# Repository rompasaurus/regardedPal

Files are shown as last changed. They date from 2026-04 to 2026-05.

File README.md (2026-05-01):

# Dilder

A Tamagotchi-inspired virtual pet built on a Raspberry Pi Pico W with an e-ink display, battery pack, and 3D-printed case — developed entirely in the open as a learning platform, blog series, and YouTube companion project.

The goal isn't just to build a thing — it's to show *how* the thing gets built, from the very first idea to a finished handheld device. Every prompt, every design decision, every dead end is documented so anyone can follow along, learn, and build their own.

---

## How It Started — Meet Jamal

<p align="center">
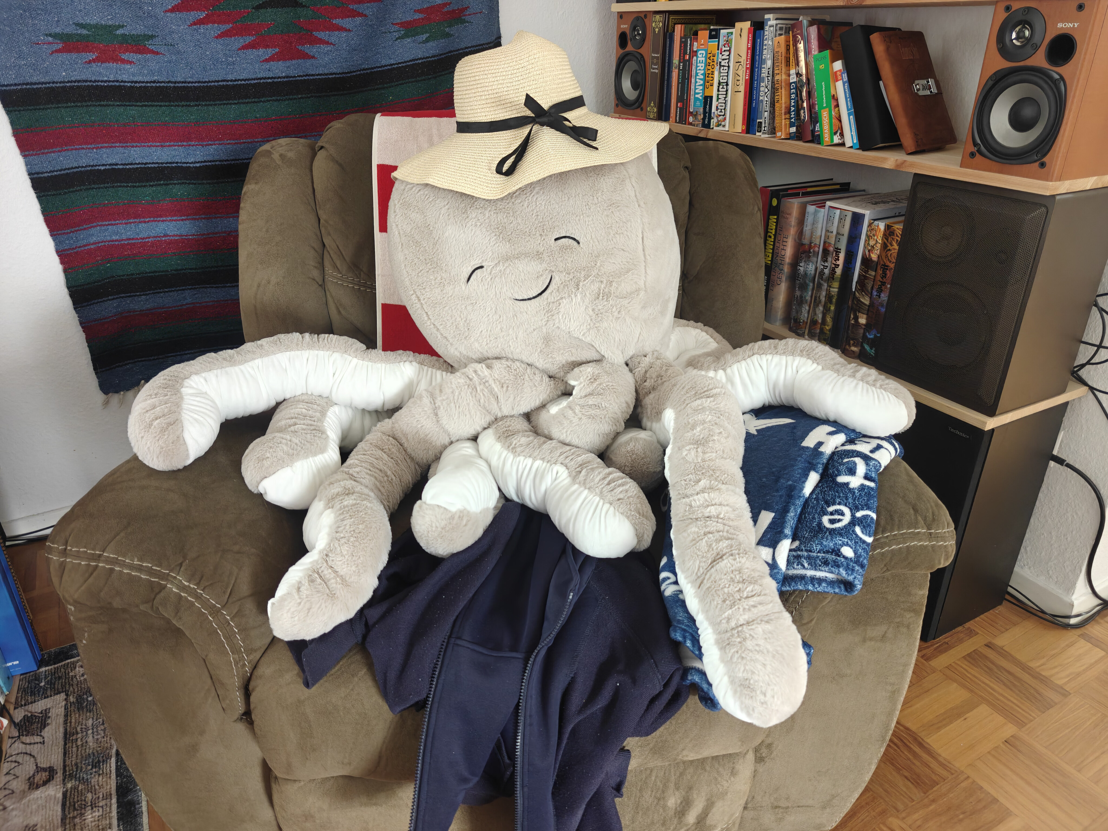
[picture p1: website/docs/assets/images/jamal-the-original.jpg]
Jamal the plush octopus
  
  <br />
  <em>Jamal. The plush octopus who started it all.</em>
</p>

This project didn't start with a schematic or a product spec. It started in a TEDi — a German dollar store — where my wife Emma and I found a giant plush octopus grinning up from a discount bin. We bought him on the spot, and on the walk home we started giving him a personality: laid-back, opinionated, a little sassy, suspiciously wise for a boneless creature. By the time we got home, he had a name — **Jamal** — and he'd claimed the armchair like he'd been paying rent.

The question asked itself: *what if we could actually bring him to life?* Not literally — but as a tiny digital companion. A pocket-sized octopus with moods, opinions, and an attitude problem, living on an e-ink screen and judging your life choices in ALL CAPS.

That's how Dilder was born. Not from an engineering roadmap, but from a stuffed animal and two people who couldn't stop anthropomorphizing it on a walk home.

---

## Enclosure — Rev 2 Mk2

The 3D-printed enclosure is a three-part design: base plate with solar panel recess, AAA battery cradle insert, and top cover with display window and joystick cutout. Designed in OpenSCAD (parametric source) and FreeCAD (visual PartDesign).

### Individual Parts

<p align="center">
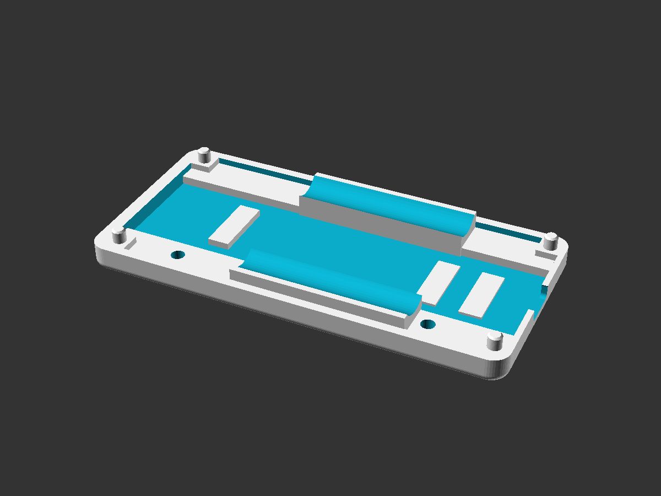
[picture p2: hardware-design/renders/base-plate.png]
Base Plate — top view
  
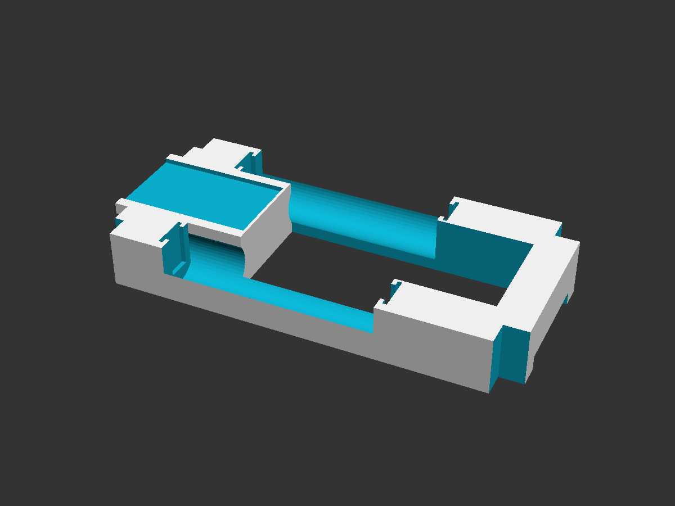
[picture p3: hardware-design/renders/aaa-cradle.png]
AAA Battery Cradle
  
</p>
<p align="center">
  <em>Left: Base plate with cradle pocket, corner pillars, battery rail troughs, and USB-C cutout. Right: AAA battery cradle with dual bays, clip slots, and TP4056 indent.</em>
</p>

<p align="center">
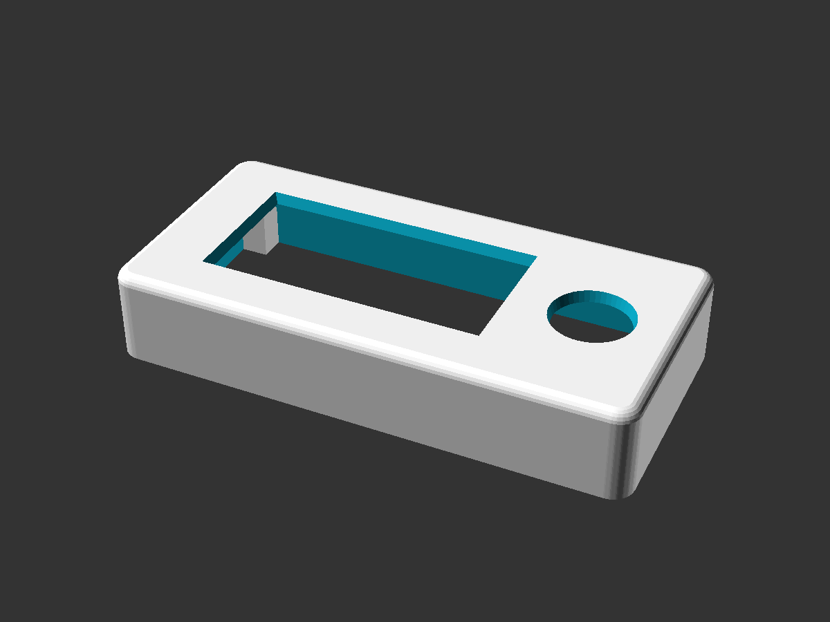
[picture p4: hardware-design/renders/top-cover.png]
Top Cover
  
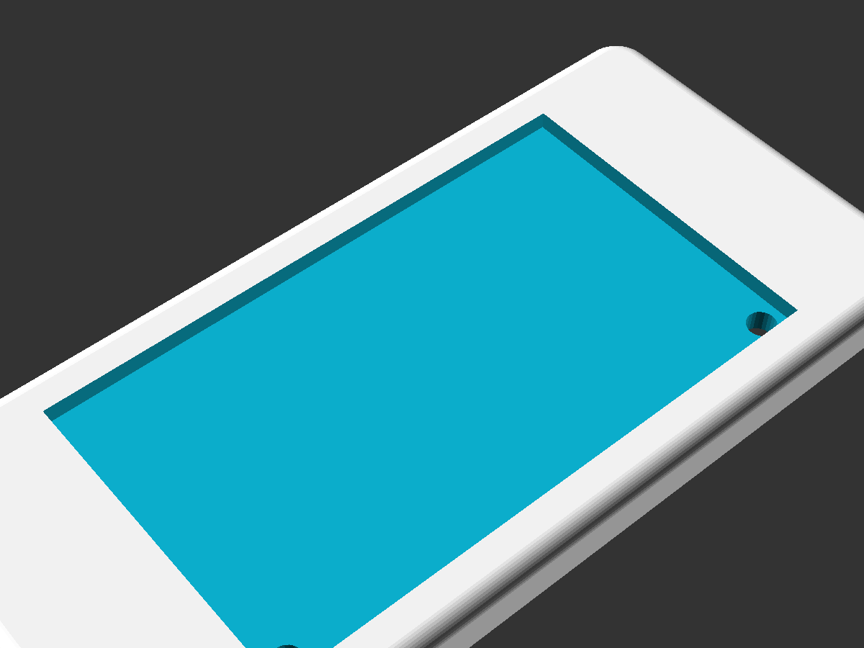
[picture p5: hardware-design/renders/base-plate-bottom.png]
Base Plate — bottom (solar pit)
  
</p>
<p align="center">
  <em>Left: Top cover with display window, joystick hole, and bullnose edge. Right: Base plate bottom showing solar panel recess and wire holes.</em>
</p>

### Assembled

<p align="center">
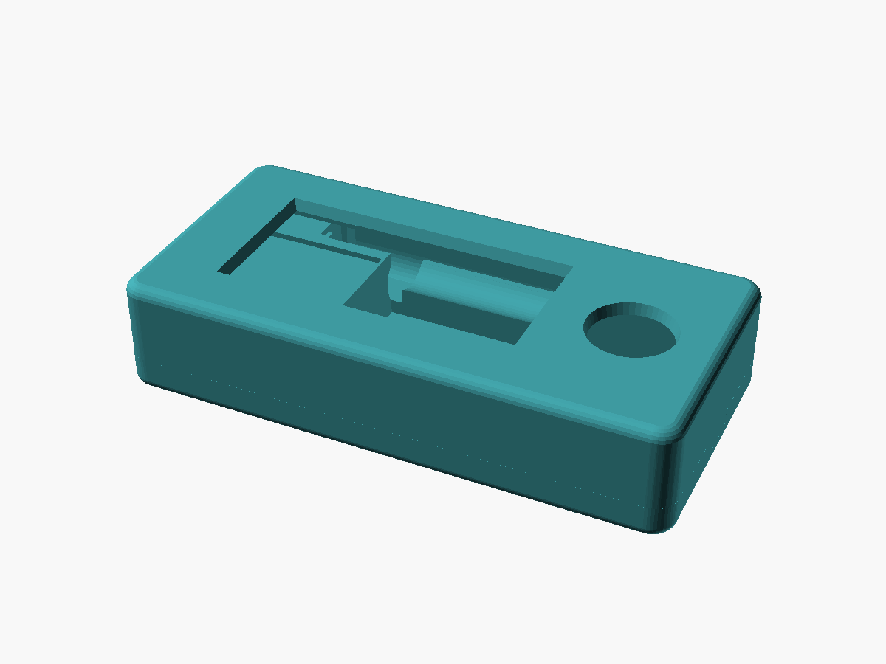
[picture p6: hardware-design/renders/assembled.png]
All three parts assembled
  
  <br />
  <em>All three parts stacked in their mated positions.</em>
</p>

### Full Assembly with Electronics

The FreeCAD macro now imports the official Raspberry Pi Pico 2 STEP file (mechanically identical to the Pico 2 W) and adds procedural 2×20 pin headers. It also builds three more peripherals from datasheet dimensions — two AAA Li-Ion cells in the cradle bays, a TP4056 USB-C charge module in the connecting block indent, and a Waveshare 2.13" e-paper display in the top cover's screen inlay. The Pico is mounted upside-down with its component-side face flush against the cradle's mating plane, headers extending up into the PicoNest cavity.

<p align="center">
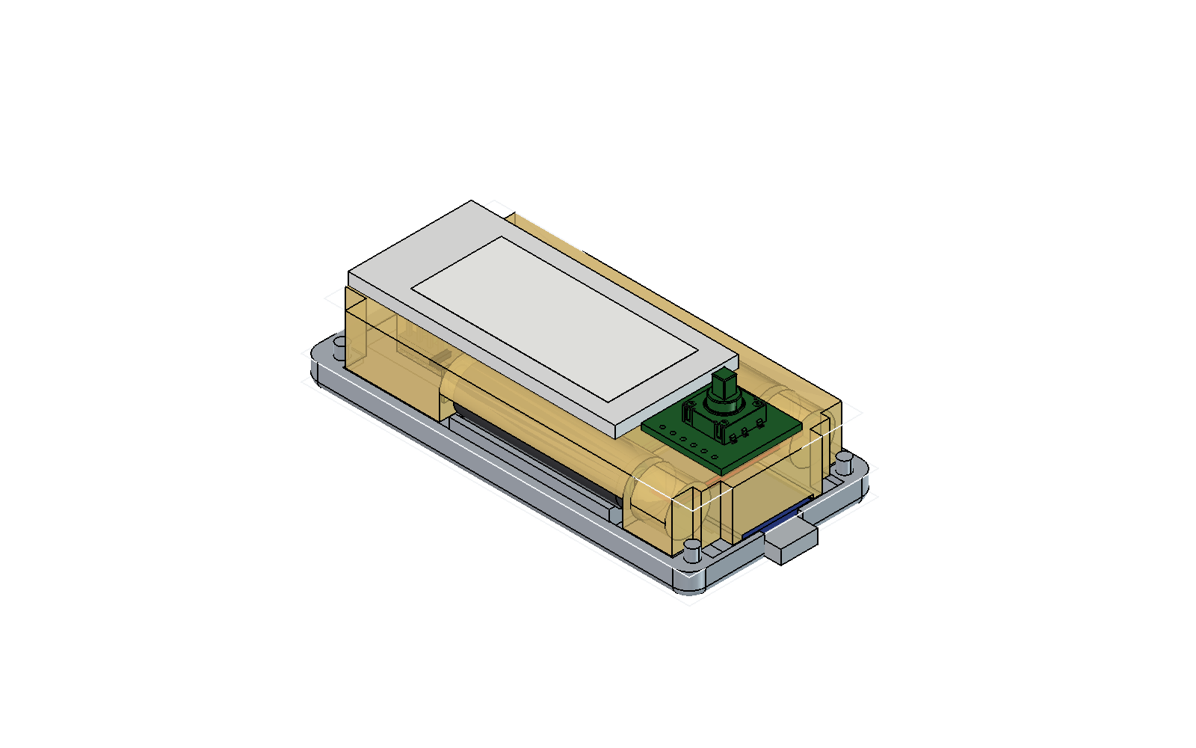
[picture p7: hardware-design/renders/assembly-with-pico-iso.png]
Assembly with Pico — top cover translucent
  
  <br />
  <em>Top cover rendered translucent so the Pico 2 W board, headers, and cradle are all visible.</em>
</p>

<p align="center">
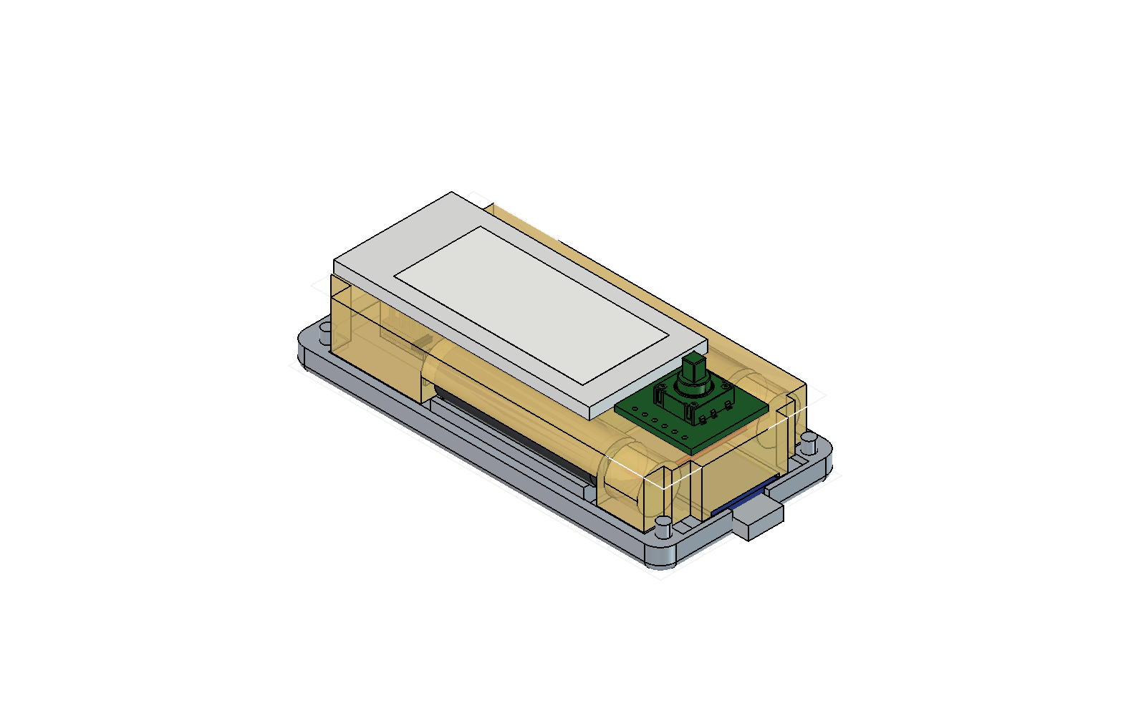
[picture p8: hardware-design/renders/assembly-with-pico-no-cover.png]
Assembly without top cover
  
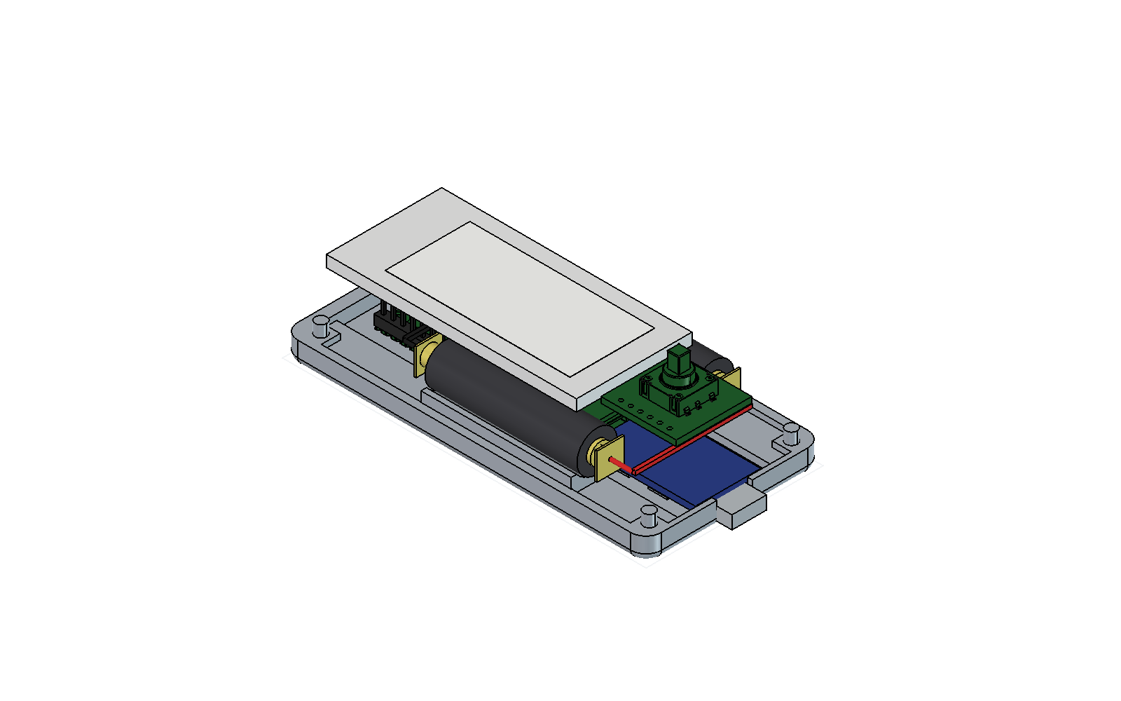
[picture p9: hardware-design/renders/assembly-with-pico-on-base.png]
Pico on base plate, cradle hidden
  
</p>
<p align="center">
  <em>Left: top cover hidden so the cradle and Pico are exposed. Right: cradle hidden so the Pico's seating on the base plate is visible — header pin tips reach the level where the cradle would clip in.</em>
</p>

See the [FreeCAD macro reference](website/docs/docs/hardware/freecad-mk2-macro.md) for a full walkthrough of how the macro is structured.

### Joystick Thumbpiece

A printable snap cap that fits over the K1-1506SN-01 5-way switch peg. Single disc, 11 mm OD (= cover hole − 1 mm) so it nests inside the cover's joystick cutout with 0.5 mm radial clearance for directional swing. Concave thumb dish on top, rectangular snap socket on the bottom centered on the actuator (the SW1 stick is offset +0.68 mm in Y from the cover hole on the production PCB layout — disc reads visually centered, socket lands on the peg). Built parametrically in `dilder_rev2_mk2.FCMacro` as a separate `Thumbpiece` Body — drop `thumb_sock_x/y` from 3.3 to ~3.15 in the spreadsheet to convert friction-fit to interference snap-fit.

<p align="center">
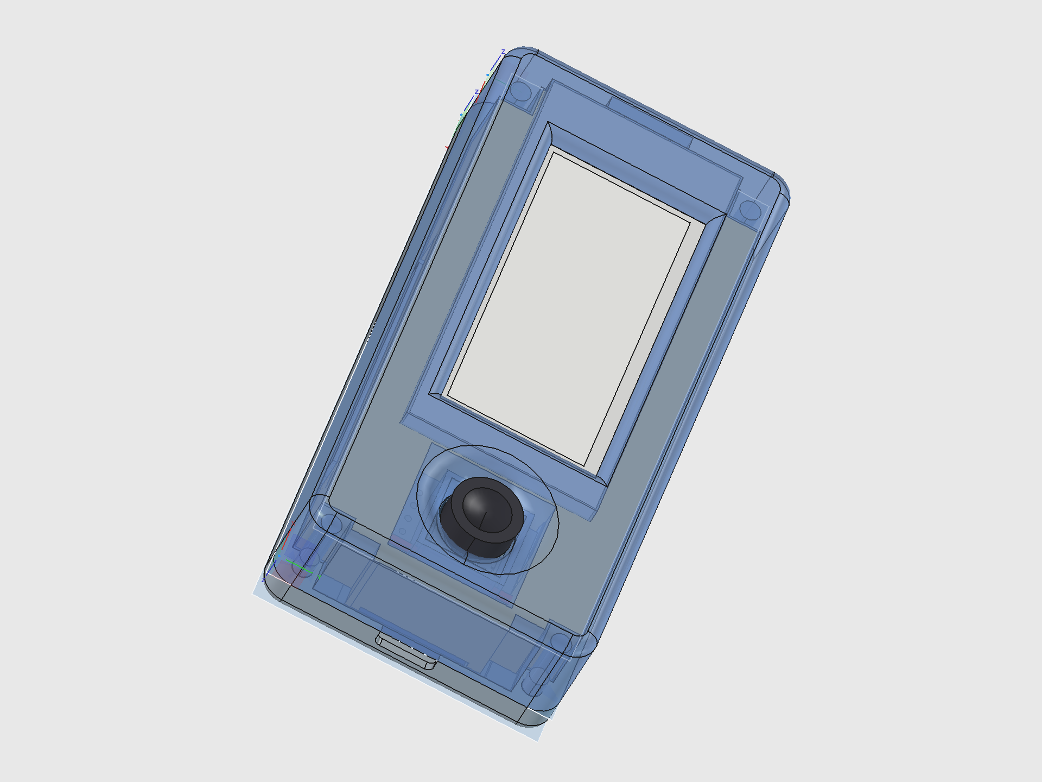
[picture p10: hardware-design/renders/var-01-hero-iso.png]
Assembly with thumbpiece
  
  <br />
  <em>Top-down view of the assembled prototype — display window on the left, joystick with the new thumbpiece on the right.</em>
</p>

<p align="center">
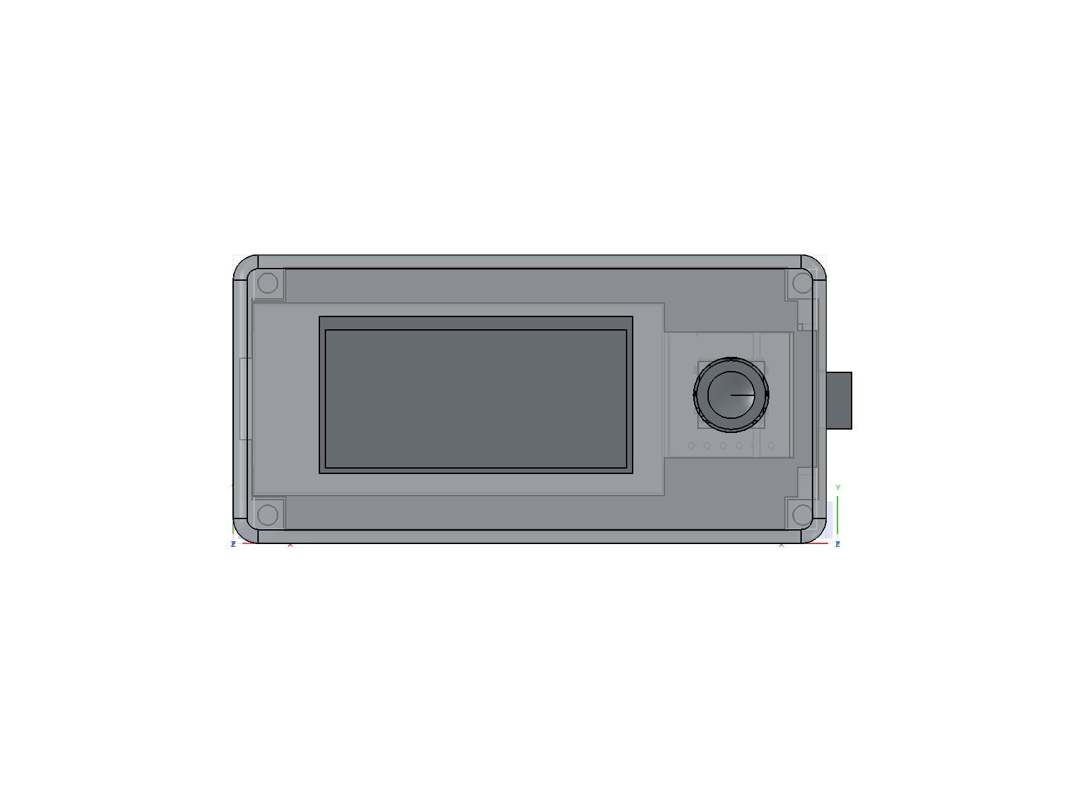
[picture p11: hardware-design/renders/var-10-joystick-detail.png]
Joystick + thumbpiece detail
  
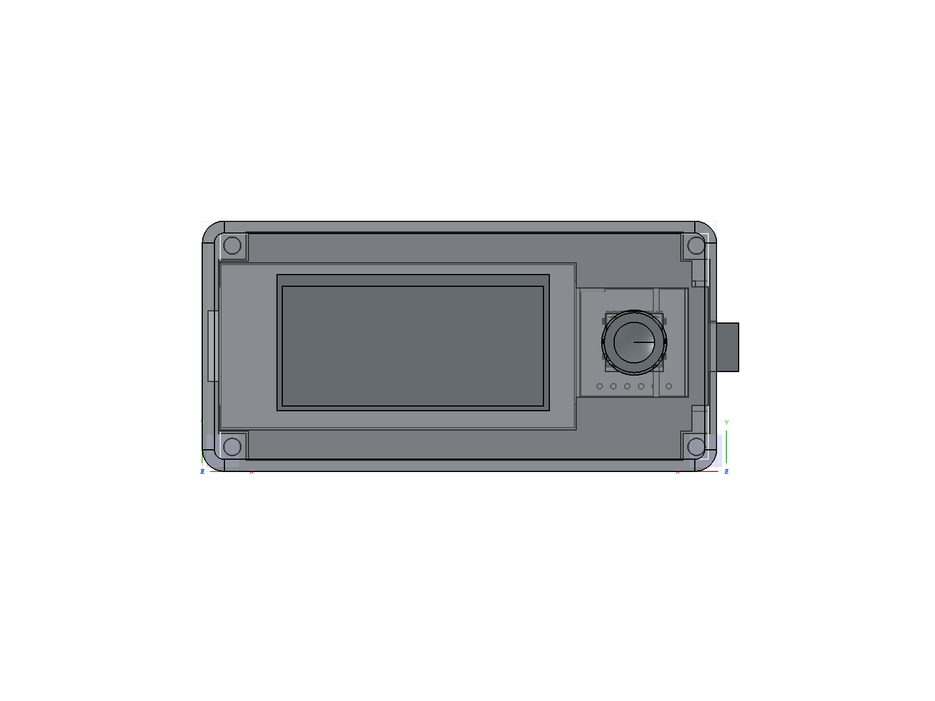
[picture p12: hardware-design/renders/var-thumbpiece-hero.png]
Thumbpiece in cover hole
  
</p>
<p align="center">
  <em>Left: joystick area in context. Right: thumbpiece nested in the cover cutout with the cover dialed to 85% transparency for clarity.</em>
</p>

See the [thumbpiece design write-up](website/docs/blog/posts/joystick-thumbpiece-snap-cap.md) for the geometry walkthrough — including the dish-vs-socket constraint that almost ruined the first cut.

---

## What This Project Is

- **A virtual pet device** — a pocket-sized, low-power companion with personality, needs, and interactions displayed on an e-ink screen
- **A build series** — a step-by-step guide covering hardware, software, 3D printing, and project planning
- **A transparency experiment** — the entire development process is captured in real time, including AI-assisted prompts, iteration, and mistakes

---

## Hardware

### Phase 1 — Pico W Prototype (current)

| Component | Details |
|---|---|
| Board | Raspberry Pi Pico W (or Pico WH with pre-soldered headers) |
| Display | [Waveshare Pico-ePaper-2.13](https://www.waveshare.com/pico-epaper-2.13.htm) — 250x122px, black & white, SPI1, SSD1680 driver, Pico-native 40-pin plug-in module |
| Power | USB micro-B (development); battery TBD |
| Input | 5x 6x6mm tactile push buttons (3 nav + 2 action) via GPIO |

### Future — Pi Zero Upgrade

| Component | Details |
|---|---|
| Board | Raspberry Pi Zero WH (W or 2 W, pre-soldered headers) |
| Power | LiPo battery + Adafruit PowerBoost 500C |
| Enclosure | 3D-printed case (STL files provided) |

> The Pico W is the starting platform — it's what we have on hand, it's cheap, and it's excellent for prototyping the display and input system. The Pi Zero upgrade comes later when we need Linux, networking features, or more compute.

---

## Phases

Each phase maps to a section of the blog/YouTube series and can be followed independently.

### Phase 0 — Project Planning & Documentation ✓

- [x] Create repository and project structure
- [x] Define project intent and scope
- [x] Begin prompt progression log ([PromptProgression.md](PromptProgression.md))
- [x] Outline full phase roadmap
- [x] Create pixel art concepts for e-ink display (octopus character with 16 emotional states)
- [x] Define enclosure concept and prototype dimensions

### Phase 1 — Hardware Selection & Setup (Pico W) ✓

- [x] Finalize component list with links/part numbers ([hardware-research.md](docs/hardware-research.md))
- [x] Set up Docker-based C SDK cross-compilation toolchain
- [x] Wire e-ink display to Pico W via jumper wires (SPI)
- [x] Flash and run "Hello, Dilder!" on the e-ink display — proof of life
- [x] Build DevTool GUI — display emulator, serial monitor, firmware flash, asset manager, GPIO reference, connection utility, documentation ([tools/devtool/](tools/devtool/))
- [x] Add Programs tab with animated octopus preview, firmware size estimation, and deploy
- [x] Build IMG-receiver firmware — stream images from PC to Pico display via USB serial ([dev-setup/img-receiver/](dev-setup/img-receiver/))
- [x] Build standalone deploy — runtime-rendered animation, runs without PC
- [ ] Wire and test button inputs (GPIO)
- [ ] Battery power prototype

### Phase 2 — Firmware Foundation (C on Pico W)
> *You are here*

- [x] Runtime rendering engine — draw octopus mathematically (no pre-baked frames)
- [x] Animation system — 4-frame mouth cycle with per-mood expression sequences
- [x] Body transform system — dx/dy offset, x_expand, per-row sine wobble
- [x] Custom body shapes for Fat (wider dome, thick tentacles) and Lazy (tentacles draped right)
- [x] 16 emotional states with unique eyes, pupils, eyebrows, eyelids, mouths, and body animations
- [x] 17 standalone firmware programs (16 emotions + mood selector with all 823 quotes)
- [x] Date/time clock header from RTC
- [x] C-faithful preview renderer for verifying firmware matches DevTool
- [x] Keyboard-to-Pico input mapping plan ([docs/keyboard-to-pico-input.md](docs/keyboard-to-pico-input.md))
- [x] Implement serial command input for interactive mood control
- [x] Wire and test GPIO joystick input (DollaTek 5-way, GP2–GP6)
- [x] Joystick Mood Selector firmware with on-screen input indicator
- [ ] **Custom PCB design (in progress)** — switched MCU from RP2040 to ESP32-S3-WROOM-1-N16R8 (WiFi+BLE, 16MB flash, 8MB PSRAM). 4-layer board (45x80mm, 30 components) in KiCad, ready for routing. Target fab: JLCPCB. Sensors: LIS2DH12TR (accelerometer), AHT20 (temperature/humidity), BH1750FVI-TR (ambient light) on shared I2C bus.
- [ ] Battery power (LiPo on VSYS) — InnCraft 1000mAh acquired
- [ ] Build game loop with state machine (idle, interact, sleep)

### Phase 3 — Pet Logic & Gameplay

- [ ] Define pet stats (hunger, happiness, energy, health, etc.)
- [ ] Implement stat decay over time
- [ ] Build interaction system — feed, play, sleep, clean
- [x] Pet mood / expressions based on emotional states (16 implemented)
- [x] Animation frames for e-ink (idle expressions, body movement per mood)
- [ ] Emotional state transitions triggered by interactions and stats
- [ ] Add death/game-over state and reset/new-pet flow

### Phase 4 — UI & Menus

- [ ] Design menu system for e-ink (optimized for minimal refreshes)
- [ ] Build status bar — icons for stats, clock, battery level
- [ ] Add screen transitions between menu, pet view, and interactions
- [ ] Implement settings screen (contrast, name pet, reset)

### Phase 5 — Pi Zero Migration

- [ ] Port MicroPython firmware to CPython on Pi Zero
- [ ] Set up headless Raspberry Pi OS
- [ ] Adapt display driver for Pi Zero SPI + Waveshare HAT
- [ ] Adapt input handler for Pi Zero GPIO
- [ ] Validate all Phase 2-4 functionality on Pi Zero

### Phase 6 — 3D-Printed Case & Power
> *In progress alongside Phase 2*

- [x] Design enclosure in OpenSCAD — parametric 3-part design (base plate, AAA cradle, top cover)
- [x] Account for display cutout, joystick access, USB-C charging port, solar panel recess
- [x] Translate to FreeCAD PartDesign — full parametric model with 90+ parameter spreadsheet
- [x] Battery cradle with clip slots for Swpeet AAA contact plates (parallel wiring)
- [x] Solar panel wire through-holes in base plate
- [x] Print prototypes and iterate on fit (Rev 2 Mk2 current)
- [ ] Implement battery power (dual 10440 or single 3000mAh LiPo via TP4056)
- [ ] Implement sleep/wake cycle to conserve battery
- [x] Publish STL/3MF files and build instructions ([hardware-design/freecad-mk2/](hardware-design/freecad-mk2/))

### Phase 7 — Extras & Community

- [ ] Add sound (piezo buzzer for beeps/alerts)
- [ ] Explore connectivity — Bluetooth/Wi-Fi pet interactions?
- [ ] Mini-games
- [ ] Seasonal/event-based pet outfits or moods
- [ ] Publish a "build your own" kit guide
- [ ] Community gallery — show off your Dilder

---

## Content & Documentation

| Resource | Description |
|---|---|
| [PromptProgression.md](PromptProgression.md) | Every AI prompt used in development (104+), timestamped with token counts and file changes |
| [docs/hardware-research.md](docs/hardware-research.md) | Component research, materials list, GPIO pinout, and enclosure concepts |
| [Emotion States](https://dilder.dev/docs/software/emotion-states/) | All 16 emotional states with rendered previews and animation strips |
| [docs/keyboard-to-pico-input.md](docs/keyboard-to-pico-input.md) | Input mapping plan for interactive octopus control |
| [Blog](https://dilder.dev/blog/) | Build journal — 8 posts covering planning through body animations |
| YouTube (TBD) | Video walkthroughs for each phase |

---

## Follow Along

This project is built in the open. Star/watch this repo to follow progress. Each phase will have a corresponding blog post and video.

---

## License

TBD

---

*Built with patience, a Pico W, and an unreasonable fondness for a plush octopus named Jamal.*

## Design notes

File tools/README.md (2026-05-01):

# Dilder Tools

All project tools live in their own directories here.

| Tool | Directory | Description |
|---|---|---|
| [DevTool](devtool/) | `tools/devtool/` | Tkinter GUI for firmware development — display emulator, serial monitor, flash utility |
| [Build & Render](build-render/) | `tools/build-render/` | Interactive CLI for rendering FreeCAD models into PNGs |
| [Design Tracker](design-tracker/) | `tools/design-tracker/` | CAD version history, print log, and snapshot diffing |
| [DesignTool](designtool/) | `tools/designtool/` | Tkinter GUI for OpenSCAD file management and export |

## Quick Start

```bash
# Render FreeCAD models
./tools/build-render/build_and_render.sh

# Track design changes
python3 tools/design-tracker/design-tracker.py

# Manage OpenSCAD files
python3 tools/designtool/designtool.py

# Firmware development
python3 tools/devtool/devtool.py
```

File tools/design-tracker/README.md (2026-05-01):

# Dilder Design Tracker v2.0

Version history, print log, render gallery, and print-package management for
FreeCAD hardware iterations. Tracks every design snapshot, 3D print attempt,
and bundles related files into packages for easy archival.

## Screenshots

### Dashboard
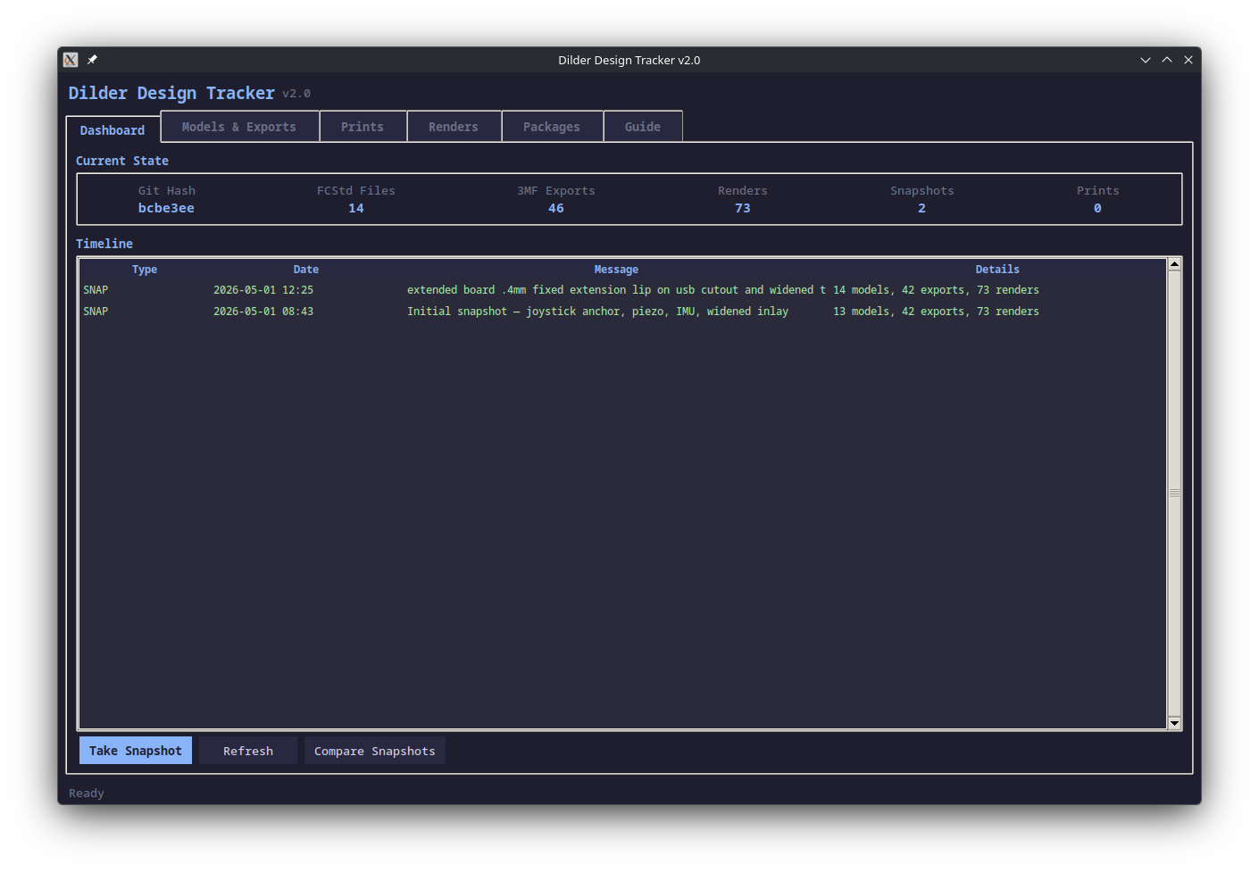
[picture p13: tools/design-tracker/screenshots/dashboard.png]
Dashboard


Live summary of the project: git hash, file counts, snapshot/print timeline.
Take snapshots, compare states, and monitor design evolution at a glance.

### Models & Exports
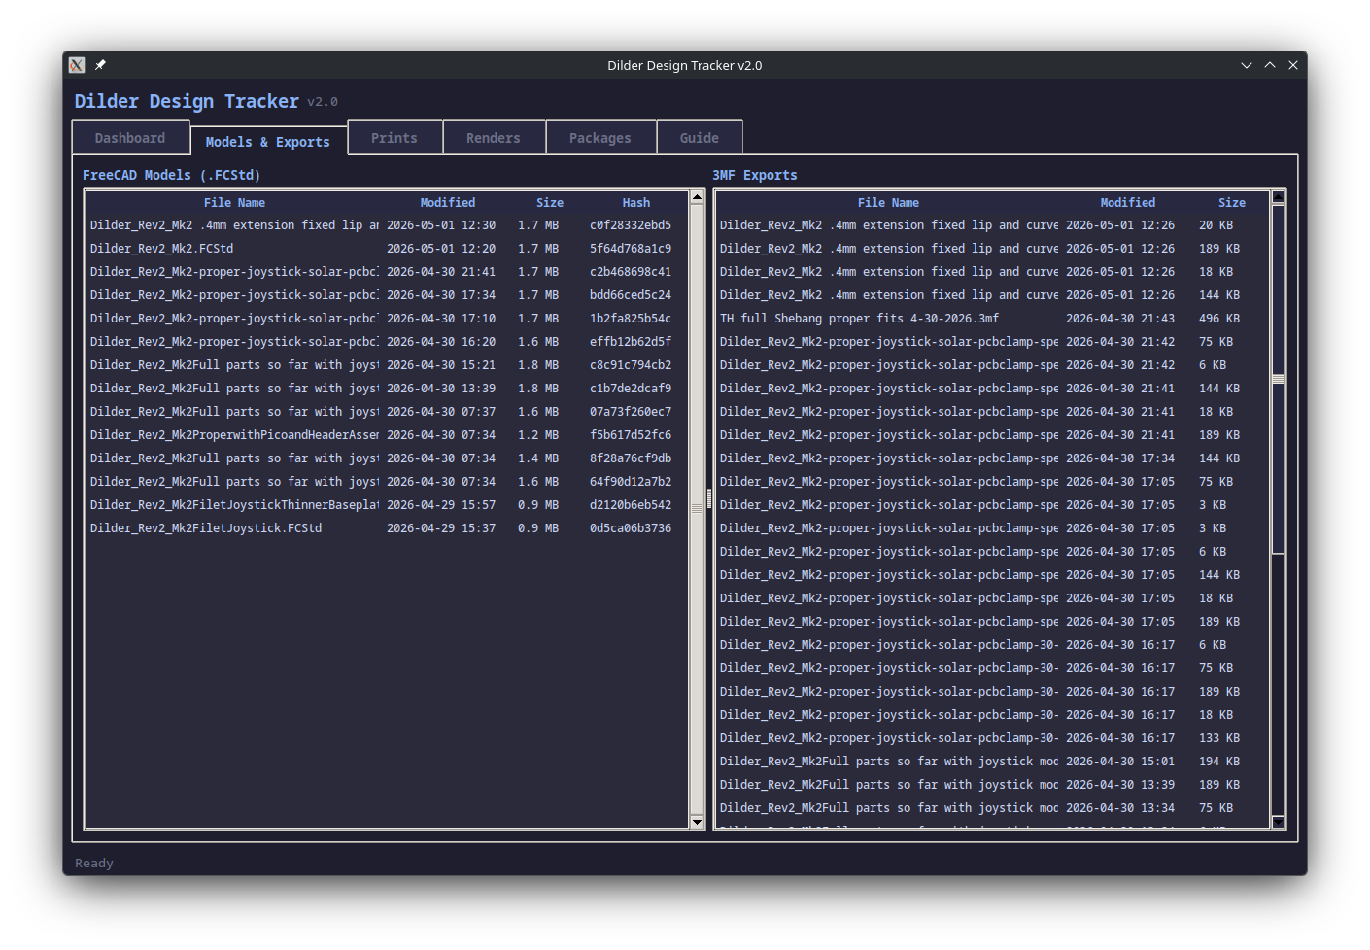
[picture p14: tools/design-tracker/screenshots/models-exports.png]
Models & Exports


Side-by-side tables of all FreeCAD `.FCStd` model files (with hashes for
change detection) and all `.3mf` slicer-ready exports.

### Renders
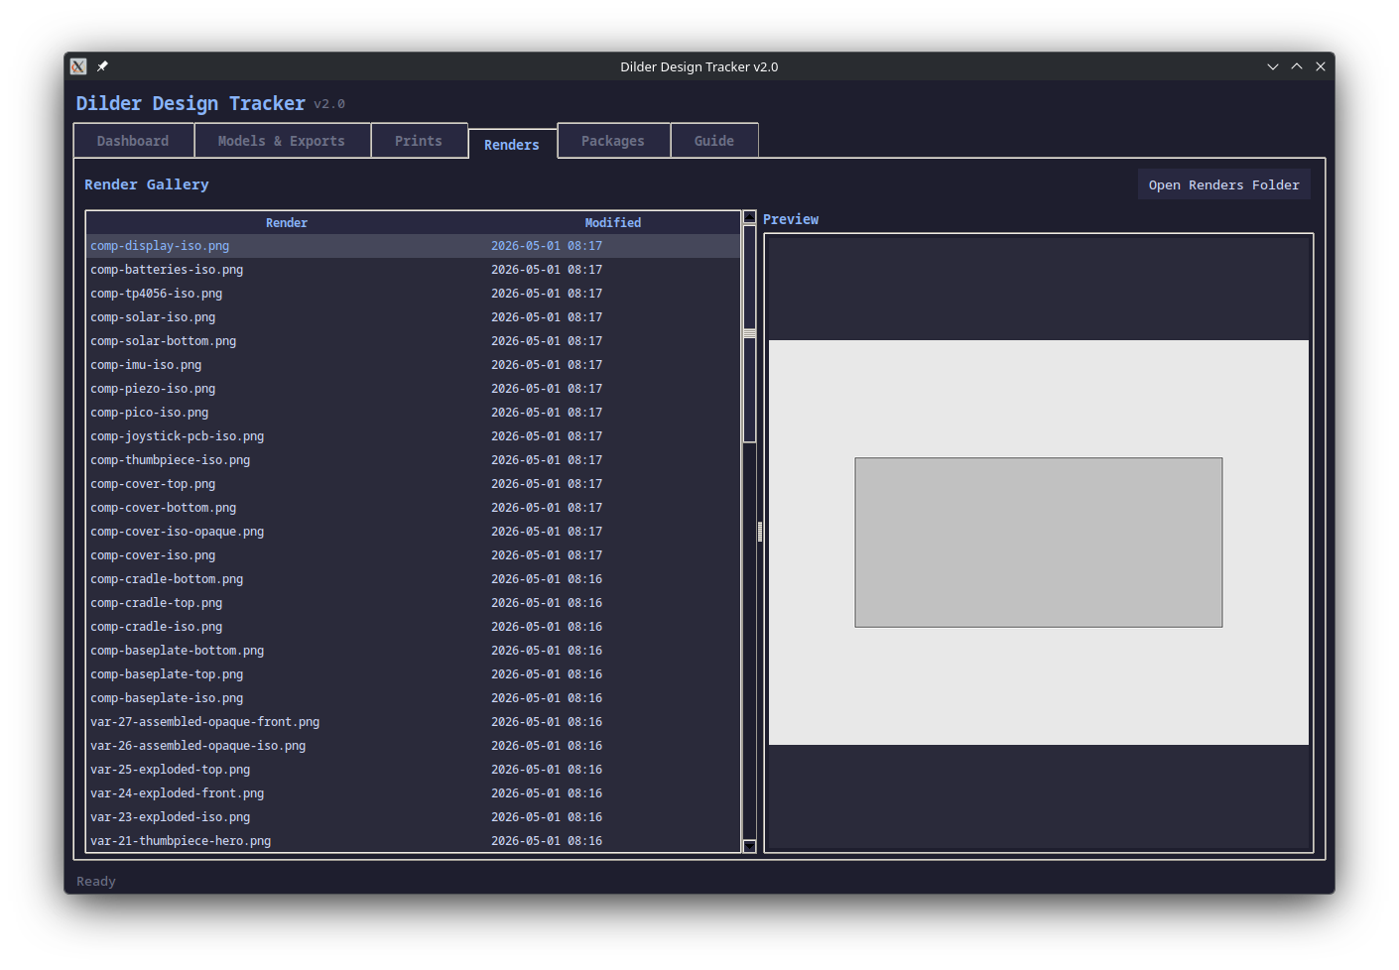
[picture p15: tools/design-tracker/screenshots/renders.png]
Renders


Gallery of all render PNGs from `hardware-design/renders/`. Click any render
to see a live image preview. Open the folder in your file manager.

### Guide
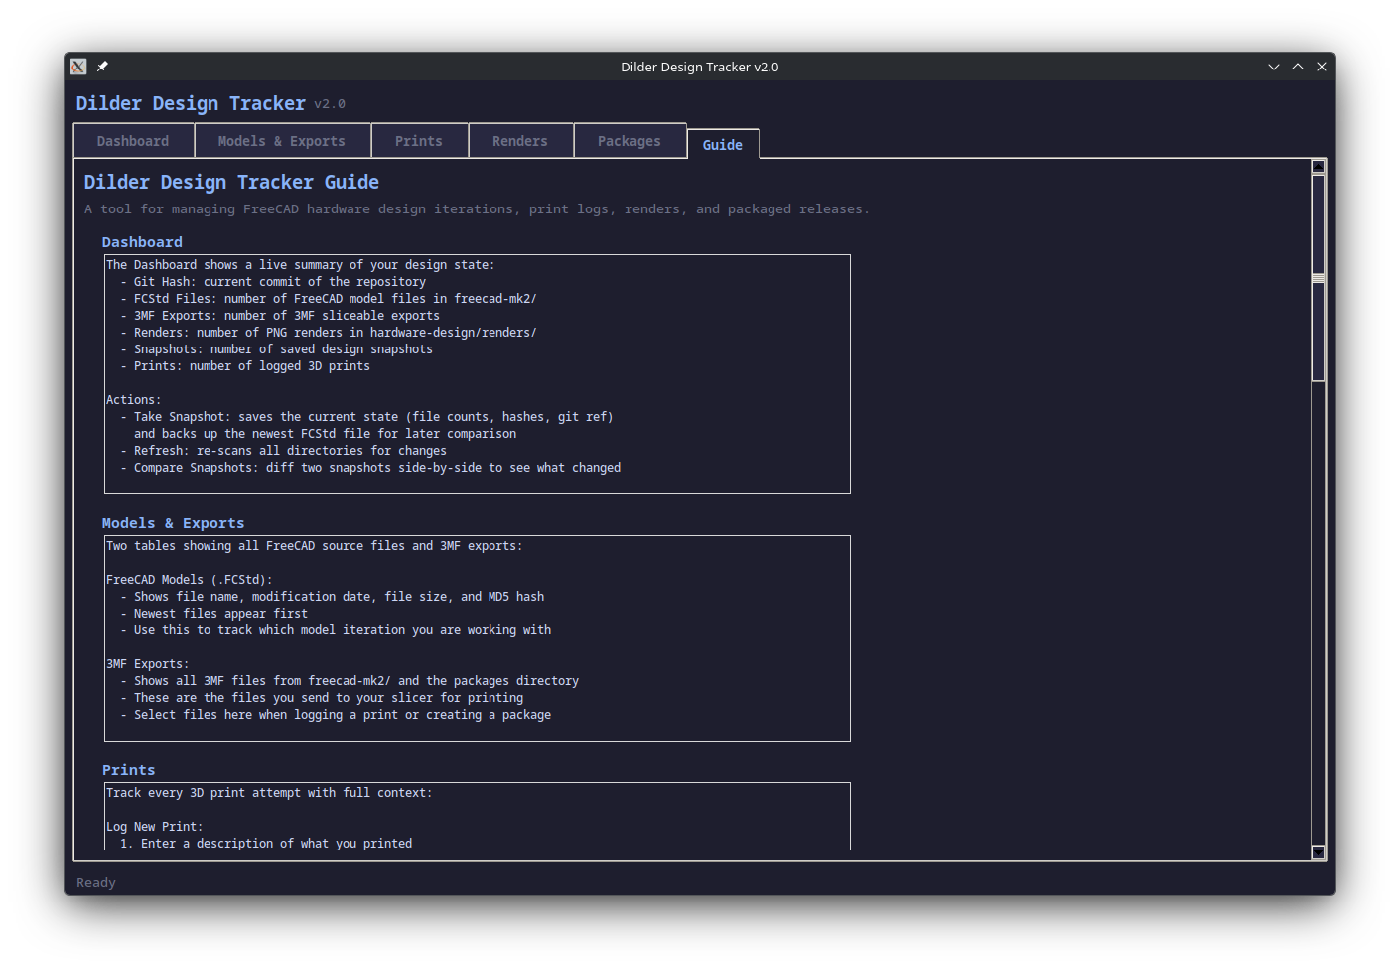
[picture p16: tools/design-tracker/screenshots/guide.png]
Guide


Built-in reference guide covering every tab, the design-print-review
workflow, naming conventions, and CLI commands.

## Quick Start

```bash
# Launch the GUI (default)
python3 tools/design-tracker/design-tracker.py

# Or use the CLI
python3 tools/design-tracker/design-tracker.py --cli
```

## Features

### Dashboard Tab
- **Current State**: git hash, FCStd count, 3MF count, render count,
  snapshot count, print count
- **Timeline**: merged chronological view of snapshots, prints, and packages
  with color coding (green = snapshot, magenta = print, orange = package)
- **Take Snapshot**: saves file counts, hashes, git ref, and backs up the
  newest FCStd file to `.design-tracker/snapshots/`
- **Compare Snapshots**: diff two snapshots side-by-side showing count
  deltas, hash changes, added/removed renders

### Models & Exports Tab
- **FreeCAD Models**: all `.FCStd` files sorted by modification date with
  file name, date, size, and MD5 hash
- **3MF Exports**: all `.3mf` files from `freecad-mk2/` and the packages
  directory, sorted by date

### Prints Tab
- **Log New Print**: record what you printed with:
  - Description, result (success/partial/failed), notes
  - 3MF file selection from scan
  - Camera photo attachment (PNG/JPG)
- **Attach Photo**: add camera pictures to existing print entries
- **Print Details**: click any row to see full metadata, files, notes,
  and attached photo paths

### Renders Tab
- **Gallery list**: all render PNGs from `hardware-design/renders/`
  sorted by modification date
- **Live preview**: click any render to see it in the preview pane
  (requires Pillow for image display)
- **Open Renders Folder**: launch system file manager

### Packages Tab
- **Create Package**: bundle files into a tracked folder containing:
  - A FreeCAD model file (frozen copy)
  - Selected 3MF exports
  - `renders/` subfolder with selected render images
  - `photos/` subfolder with camera pictures of physical prints
  - `CHANGES.md` with changelog, metadata, git hash, and file manifest
- **Link to snapshot/print**: connect a package to a specific snapshot
  and/or print entry for traceability
- **Package Contents**: click any row to view the `CHANGES.md`
- Packages stored in `.design-tracker/packages/`

### Guide Tab
- Built-in reference covering every tab and feature
- Recommended design-print-review workflow
- File naming conventions
- CLI command reference

## Walkthrough: Design-Print-Review Cycle

### 1. Make changes in FreeCAD
Edit the macro (`dilder_rev2_mk2.FCMacro`), run it in FreeCAD to rebuild
the model, and save the `.FCStd` file.

### 2. Take a Snapshot
Open the Dashboard tab and click **Take Snapshot**. Enter a description
like "widened USB cutout by 0.2mm". This saves:
- Current file counts and hashes
- Git commit reference
- A backup copy of the newest FCStd file

### 3. Export 3MF files
In FreeCAD, export each body (BasePlate, AAACradle, TopCover) as `.3mf`
files for your slicer. These appear automatically in the Models & Exports tab.

### 4. Print and log the result
Slice and print your parts. Then open the **Prints** tab and click
**Log New Print**:
- Describe what you printed ("AAACradle with widened USB cutout")
- Select which 3MF files were used from the list
- Set the result: `success`, `partial`, or `failed`
- Add notes about print settings, issues, or observations

### 5. Attach camera photos
After the print finishes, take photos of the physical parts. Back in the
Prints tab, select your print entry and click **Attach Photo to Print**.
Browse to select your camera photos (PNG/JPG). These are tracked by path
in the print record.

### 6. Create a package
Open the **Packages** tab and click **Create Package** to bundle everything:
- Name it (e.g., "Rev2 Mk2 -- widened USB 0.2mm + extended 0.4mm")
- Link it to the snapshot you took in step 2
- Link it to the print you logged in step 4
- Select the FCStd file used
- Select the 3MF files that were printed
- Add renders from the renders gallery
- Add camera photos of the physical print
- Write a changelog describing what changed and why

This creates a self-contained folder with all artifacts and a `CHANGES.md`
manifest for future reference.

### 7. Commit to git
When satisfied with the iteration, commit your changes.

## CLI Commands

```bash
python3 design-tracker.py               # launch GUI (default)
python3 design-tracker.py --cli         # interactive terminal menu
python3 design-tracker.py snap "msg"    # quick snapshot
python3 design-tracker.py log           # show timeline
python3 design-tracker.py status        # current design state
python3 design-tracker.py diff 1 2      # compare snapshots 1 and 2
python3 design-tracker.py naming        # naming convention guide
```

## File Structure

```
tools/design-tracker/
  design-tracker.py          # main script (GUI + CLI)
  README.md                  # this file
  screenshots/               # GUI screenshots for docs
  .design-tracker/
    history.json             # all snapshots, prints, packages
    snapshots/
      snap-0001/             # FCStd backup from snapshot 1
      snap-0002/             # FCStd backup from snapshot 2
    packages/
      pkg-0001_2026-05-01_1430_widened-usb/
        Dilder_Rev2_Mk2.FCStd
        *.3mf
        renders/             # selected render PNGs
        photos/              # camera pictures of prints
        CHANGES.md           # changelog + file manifest
```

## Dependencies

- Python 3.8+
- tkinter (standard library)
- Pillow (`pip install Pillow`) -- for render image previews

## Theme

Catppuccin Mocha dark theme matching the DesignTool companion app.

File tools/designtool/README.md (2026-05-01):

# DesignTool — SCAD Design Management

Tkinter GUI for managing OpenSCAD hardware design files: browsing, preset diffing, exporting to STL/3MF, 3D preview, and tracking export history.

## Usage

```bash
python3 tools/designtool/designtool.py
```

## Tabs

1. **Browser** — search and browse `.scad` files with parameter details
2. **Presets & Diff** — compare presets side-by-side with color-coded diffs
3. **Export** — STL/3MF export with embedded labels and auto-generated descriptions
4. **3D Preview** — live OpenSCAD rendering with orthographic quick-views
5. **History** — full audit trail of every export

## Requirements

- Python 3.9+ with Tkinter
- OpenSCAD (for preview and export)

## Data

- `exports/` — exported STL/3MF files with descriptions
- `history.json` — export audit trail

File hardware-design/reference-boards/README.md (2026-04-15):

# Reference Board Designs

Open-source KiCad board designs collected as reference material for the Dilder custom PCB. Each folder contains a complete KiCad project (schematic + PCB layout) that can be opened directly in KiCad 7+.

These are **not** Dilder designs — they are third-party projects whose circuits, layouts, and component choices serve as learning resources and validation for our own board.

---

## Pico / RP2040 Reference Designs

### [rp2040-pico-usbc/](rp2040-pico-usbc/) — Reverse-Engineered Pico with USB-C

| Attribute | Value |
|---|---|
| **MCU** | RP2040 (Pico), RP2040 + CYW43439 (Pico WH), RP2350 (Pico 2) |
| **Source** | [sabogalc/project-piCo](https://github.com/sabogalc/project-piCo) |
| **License** | WTFPL (unrestricted) |
| **KiCad files** | 3 sub-projects: Pico C, Pico WH, Pico 2 C — each with `.kicad_sch` + `.kicad_pcb` |
| **Relevance** | Full reverse-engineered Pico schematic — shows the official RP2040 circuit (crystal, flash, power, USB) faithfully reproduced in KiCad with USB-C upgrade. Essential reference for understanding the Pico's power path and how VSYS/VBUS interact. |

### [rp2040-minimal-jlcpcb/](rp2040-minimal-jlcpcb/) — RP2040 Minimal Design (JLCPCB-Ready)

| Attribute | Value |
|---|---|
| **MCU** | RP2040 (bare chip) |
| **Source** | [tommy-gilligan/RP2040-minimal-design](https://github.com/tommy-gilligan/RP2040-minimal-design) |
| **License** | BSD-3-Clause |
| **KiCad files** | `RP2040_minimal.kicad_sch` + `.kicad_pcb` |
| **Relevance** | Raspberry Pi's official RP2040 Minimal Viable Board ported to KiCad 7 with JLCPCB assembly files. Demonstrates the absolute minimum circuit for a working RP2040 board: crystal, flash, decoupling, USB. Good for understanding which components are mandatory vs optional. |

### [rp2040-designguide/](rp2040-designguide/) — RP2040 Hardware Design Guide

| Attribute | Value |
|---|---|
| **MCU** | RP2040 (bare chip) |
| **Source** | [Sleepdealr/RP2040-designguide](https://github.com/Sleepdealr/RP2040-designguide) |
| **License** | MIT |
| **KiCad files** | `PCB/RP2040-Guide.kicad_sch` + `.kicad_pcb` + custom libraries |
| **Relevance** | Comprehensive design guide with recommended components (XC6206 LDO, specific crystal, flash). Includes custom KiCad symbol/footprint libraries. Originally for mechanical keyboard use (QMK/Vial) but the RP2040 circuit design is universally applicable. Good for learning component selection rationale. |

---

## ESP32-S3 Reference Designs

### [esp32s3-basic-devboard/](esp32s3-basic-devboard/) — Minimal ESP32-S3 Dev Board

| Attribute | Value |
|---|---|
| **MCU** | ESP32-S3-WROOM-1 module |
| **Source** | [atomic14/basic-esp32s3-dev-board](https://github.com/atomic14/basic-esp32s3-dev-board) |
| **License** | MIT |
| **KiCad files** | `dev-board.kicad_sch` + `.kicad_pcb` + `.kicad_pro` |
| **Features** | USB-C with proper CC resistors, LDO regulator, reset/boot buttons, 3 status LEDs, all GPIO broken out |
| **Relevance** | The closest minimal reference for the Dilder's ESP32-S3 circuit. Shows proper USB-C implementation (5.1k CC pull-downs, differential pair routing for D+/D-), LDO power design, and GPIO breakout. Intentionally simple — no battery charging, no sensors. Use this to validate the core ESP32-S3 power and USB design. |

### [esp32s3-ducky-epaper/](esp32s3-ducky-epaper/) — ESP32-S3 + e-Paper + Battery Charger

| Attribute | Value |
|---|---|
| **MCU** | ESP32-S3 module |
| **Display** | GDEM0154Z91 (1.52" e-ink, 3-color, Good Display) |
| **Source** | [MakersFunDuck/Ducky-board-ESP32-S3](https://github.com/MakersFunDuck/Ducky-board-ESP32-S3-with-1.52-inch-e-paper-display) |
| **License** | GPL-3.0 |
| **KiCad files** | `hardware.kicad_sch` + `.kicad_pcb` + `.kicad_pro` |
| **Features** | USB-C, Li-Ion battery charger with status LEDs, e-ink display connector, compact breakout |
| **Relevance** | **The closest overall match to the Dilder board.** Same MCU family, same display technology, same battery charging architecture. The schematic for ESP32-S3 power sequencing, USB-C implementation, and LiPo charging circuit can be directly referenced. Component footprints and LCSC part numbers are manufacturing-optimized. |

### [espressif-kicad-libs/](espressif-kicad-libs/) — Official Espressif KiCad Libraries

| Attribute | Value |
|---|---|
| **Contents** | KiCad symbols, footprints, and 3D models for all Espressif chips and modules |
| **Source** | [espressif/kicad-libraries](https://github.com/espressif/kicad-libraries) |
| **License** | Apache-2.0 |
| **Includes** | ESP32, ESP32-S2, ESP32-S3, ESP32-C3, ESP32-C6, ESP32-H2 — chips, modules, and DevKits |
| **Relevance** | Official symbols and footprints for the ESP32-S3-WROOM-1-N16R8 module. These are the authoritative reference for pin assignments, pad dimensions, and antenna keep-out zones. Install via KiCad PCM for automatic updates, or reference this local copy for offline work. |

---

## Virtual Pet Reference Designs

### [opentama-virtual-pet/](opentama-virtual-pet/) — OpenTama (Tamagotchi Reference Board)

| Attribute | Value |
|---|---|
| **MCU** | STM32L072 (ARM Cortex-M0+) |
| **Display** | SPI SSD1306 OLED or SPI UC1701x LCD |
| **Battery** | 1000mAh LiPo (40x30x12mm) |
| **Input** | 3 tactile buttons |
| **Source** | [Sparkr-tech/opentama](https://github.com/Sparkr-tech/opentama) |
| **License** | CERN-OHL-S v2 (open hardware) |
| **KiCad files** | `OpenTama.kicad_sch` + `.kicad_pcb` |
| **Relevance** | **Same product category** (virtual pet), same target fab (JLCPCB), same battery spec (1000mAh LiPo). All components on one side for JLCPCB assembly. LCSC part numbers pre-assigned. Different MCU (STM32 vs ESP32-S3) but the power management, button input, battery protection (DW01A + FS8205A), and display interface circuits are directly applicable. The CERN-OHL-S v2 license explicitly permits derivative works. |

---

## How to Use These References

1. **Open in KiCad:** Navigate to any folder and open the `.kicad_pro` file. The schematic (`.kicad_sch`) and PCB layout (`.kicad_pcb`) will load with their original libraries.

2. **Compare circuits:** Use the schematic editor to compare reference designs with Dilder's schematic at `../Board Design kicad/dilder.kicad_sch`. Check power management, USB, and decoupling approaches.

3. **Validate footprints:** Compare component footprints between reference boards and Dilder's BOM to ensure pad dimensions and thermal reliefs match JLCPCB requirements.

4. **Study routing:** Examine PCB layouts for routing strategies — especially USB differential pairs, antenna keep-out zones, ground plane stitching, and power trace widths.

---

*Collected: 2026-04-15*

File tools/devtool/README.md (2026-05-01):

# Dilder DevTool — Pico W Development Companion

A Tkinter GUI application for developing on the Raspberry Pi Pico W with the Waveshare 2.13" e-ink display. Provides a display emulator, serial monitor, firmware flash utility, asset manager, animated programs with standalone deploy, GPIO reference, USB/Wi-Fi connection walkthrough, and built-in documentation — all in one window.

---

## Table of Contents

1. [Requirements](#1-requirements)
2. [Installation](#2-installation)
3. [Launching the DevTool](#3-launching-the-devtool)
4. [Tab 1 — Display Emulator](#4-tab-1--display-emulator)
   - [Drawing Tools](#drawing-tools)
   - [Text Tool](#text-tool)
   - [Saving Images](#saving-images)
   - [Loading Images](#loading-images)
   - [Send to Pico](#send-to-pico)
5. [Tab 2 — Serial Monitor](#5-tab-2--serial-monitor)
   - [Connecting](#connecting)
   - [Viewing Output](#viewing-output)
   - [Sending Commands](#sending-commands)
   - [Saving Logs](#saving-logs)
6. [Tab 3 — Flash Firmware](#6-tab-3--flash-firmware)
   - [Selecting a UF2 File](#selecting-a-uf2-file)
   - [Flashing](#flashing)
   - [Building from Source](#building-from-source)
7. [Tab 4 — Asset Manager](#7-tab-4--asset-manager)
   - [Browsing Assets](#browsing-assets)
   - [Previewing](#previewing)
   - [Deleting](#deleting)
8. [Tab 5 — Programs](#8-tab-5--programs)
   - [Previewing Programs](#previewing-programs)
   - [Deploy to Pico (Streaming)](#deploy-to-pico-streaming)
   - [Deploy Standalone](#deploy-standalone)
   - [Sassy Octopus](#sassy-octopus)
9. [Tab 6 — GPIO Pin Reference](#9-tab-6--gpio-pin-reference)
10. [Tab 7 — Connection Utility](#10-tab-7--connection-utility)
    - [USB Serial Walkthrough](#usb-serial-walkthrough)
    - [Wi-Fi Walkthrough](#wi-fi-walkthrough)
11. [Tab 8 — Documentation](#11-tab-8--documentation)
11. [File Formats](#11-file-formats)
12. [Architecture Overview](#12-architecture-overview)
13. [Troubleshooting](#13-troubleshooting)

---

## 1. Requirements

| Requirement | Notes |
|---|---|
| Python 3.9+ | Comes with most Linux distributions |
| Tkinter | Usually included with Python. On Arch: `sudo pacman -S tk` |
| pyserial | For USB serial communication with the Pico W |
| Pillow (optional) | For PNG export/import and better text rendering |

---

## 2. Installation

### Step 2.1 — Install System Dependencies

Tkinter is a Python binding to Tcl/Tk. It's usually bundled with Python, but some distros package it separately.

**Arch / CachyOS:**
```bash
sudo pacman -S tk python
```

**Ubuntu / Debian:**
```bash
sudo apt install python3-tk
```

### Step 2.2 — Install Python Dependencies

```bash
cd tools/devtool/
pip install -r requirements.txt
```

This installs:
- `pyserial` — required for the serial monitor and image upload
- `Pillow` — optional but recommended for PNG support and better text rendering

### Step 2.3 — Verify

```bash
python3 -c "import tkinter; import serial; print('OK')"
```

If this prints `OK`, you're ready to go.

---

## 3. Launching the DevTool

From the project root:

```bash
python3 tools/devtool/devtool.py
```

The application opens with eight tabs across the top:

| Tab | Purpose |
|-----|---|
| **Display Emulator** | Draw and design 250x122 e-ink images |
| **Serial Monitor** | View live printf output from the Pico W |
| **Flash Firmware** | Flash .uf2 files to the Pico W |
| **Assets** | Browse and manage saved display images |
| **Programs** | Preview, stream, or standalone-deploy animated programs to the Pico |
| **GPIO Pins** | Visual pin assignment reference |
| **Connect** | Step-by-step USB serial and Wi-Fi connection walkthrough |
| **Docs** | Searchable built-in documentation for the entire application |

A resizable log bar at the bottom shows status messages and timestamps. Drag the sash between the tabs and the log to resize.

---

## 4. Tab 1 — Display Emulator

The display emulator is a 250x122 pixel canvas (scaled 3x for visibility) that exactly matches the Waveshare 2.13" V3 e-ink display. Everything you draw here is a 1-bit monochrome image — black or white only, just like the real display.

### Drawing Tools

The toolbar at the top provides six tools:

| Tool | Description | Shortcut |
|---|---|---|
| **Pencil** | Freehand draw in black. Click or drag. | Default |
| **Eraser** | Freehand erase to white. Click or drag. | |
| **Line** | Click start point, drag to end point, release. | |
| **Rect** | Draw a rectangle outline. Click one corner, drag to opposite. | |
| **Fill Rect** | Draw a filled black rectangle. Same interaction as Rect. | |
| **Text** | Click a position, type text in the dialog. Renders to pixels. | |

**Size** controls the brush width (pencil/eraser) and line thickness (line/rect).

**Clear** resets the canvas to all white.

**Invert** flips every pixel (black becomes white, white becomes black). Useful for creating white-on-black designs.

### Text Tool

1. Select **Text** from the toolbar.
2. Set the **Font** size (8–48 px).
3. Click anywhere on the canvas.
4. A dialog appears — type your text and press OK.
5. The text is rasterized into the pixel buffer.

If Pillow is installed, text renders using the DejaVu Sans Mono font at the exact pixel size. Without Pillow, text renders as filled blocks (approximate).

### Saving Images

Click **Save** in the toolbar. Enter a name (no extension). Three files are created in the `assets/` directory:

| File | Format | Purpose |
|---|---|---|
| `name.pbm` | PBM binary (P4) | Standard 1-bit image format, viewable in any image viewer |
| `name.bin` | Raw packed bytes | Direct upload format for the Pico W display buffer |
| `name.png` | PNG (if Pillow installed) | Easy to view and share |

**PBM** is the primary format — it's a standard image format that needs no dependencies to read or write.

**BIN** is the raw display buffer in the same byte layout the Waveshare driver uses: each byte holds 8 horizontal pixels, MSB first, row by row. This can be loaded directly into the display framebuffer in C code.

### Loading Images

Click **Load** to open any `.pbm`, `.bin`, or `.png` file. The image is loaded into the canvas and can be further edited.

### Send to Pico

Click **Send to Pico** to transmit the current canvas image to the Pico W over USB serial. This sends a raw byte stream with an `IMG:` header followed by the width, height, and pixel data.

> **Note:** This requires firmware on the Pico W that listens for the `IMG:` protocol. The hello world examples don't include this — it's for future firmware development.

---

## 5. Tab 2 — Serial Monitor

A full-featured serial terminal for communicating with the Pico W over USB.

### Connecting

1. The **Port** dropdown auto-detects available serial devices. The Pico W typically appears as `/dev/ttyACM0`.
2. **Baud rate** defaults to 115200 (matching the Pico W's USB serial configuration).
3. Click **Connect** to open the connection.
4. The status indicator turns green when connected.

If no ports appear, click **Refresh**. Make sure the Pico W is plugged in and running firmware (not in BOOTSEL mode).

### Viewing Output

Serial data from the Pico W appears in the output area in real time. This is where you see `printf()` output from your C programs.

- **Auto-scroll** keeps the view at the bottom as new lines arrive. Uncheck to freeze the view for reading.
- **Clear** empties the output area.

### Sending Commands

Type in the input bar at the bottom and press **Enter** or click **Send**. The text is sent to the Pico W followed by `\r\n`.

Special buttons:
- **Ctrl+C** — sends an interrupt signal (useful for stopping running code)
- **Reset** — sends a soft-reset signal (Ctrl+D)

### Saving Logs

Click **Save Log** to save the entire output history to a text file with a timestamped filename.

---

## 6. Tab 3 — Flash Firmware

A visual interface for flashing `.uf2` firmware files to the Pico W.

### Selecting a UF2 File

- **Browse** — open a file picker to select any `.uf2` file.
- **Quick Flash** buttons — one-click selection of the pre-built hello world programs (if they've been built):
  - **Hello Serial** — `dev-setup/hello-world-serial/build/hello_serial.uf2`
  - **Hello Display** — `dev-setup/hello-world/build/hello_dilder.uf2`

### Flashing

1. Put the Pico W in **BOOTSEL mode** (unplug, hold BOOTSEL, plug in, release).
2. Click **Detect RPI-RP2** — the tool searches for the mounted USB drive.
3. Click **Flash** — the `.uf2` file is copied to the drive.
4. The Pico W reboots automatically.

### Building from Source

The **Build Projects** section has buttons to compile each hello world project directly from the DevTool:

- **Build Hello Serial** — runs CMake + Ninja in `dev-setup/hello-world-serial/`
- **Build Hello Display** — runs CMake + Ninja in `dev-setup/hello-world/`

Build output appears in the log bar at the bottom. The buttons handle copying `pico_sdk_import.cmake` and creating the build directory automatically.

---

## 7. Tab 4 — Asset Manager

Browse and manage the 1-bit display images saved in the `assets/` directory.

### Browsing Assets

The file list on the left shows all `.pbm`, `.bin`, and `.png` files in `assets/`. Click **Refresh** to reload the list.

### Previewing

Click any file to see a 2x scaled preview on the right. The preview shows the image as it would appear on the e-ink display.

File info (name, size, dimensions) is shown below the preview.

### Deleting

Select a file and click **Delete** to remove it. A confirmation dialog appears first.

**Open Folder** opens the `assets/` directory in your system file manager.

---

## 8. Tab 5 — Programs

Preview, stream, or permanently deploy animated programs to the Pico W display.

### Previewing Programs

Select a program from the list and click **Preview** to run the animation in the emulator canvas. Click **Stop** to halt.

### Deploy to Pico (Streaming)

Click **Deploy to Pico** to stream animation frames over USB serial in real time. This requires the **IMG-receiver firmware** on the Pico — use the **Flash IMG Receiver** button to build and flash it (Pico must be in BOOTSEL mode first).

### Deploy Standalone

Click **Deploy Standalone** to bake the entire animation into the Pico's firmware. The DevTool:

1. Pre-renders all frames in Python (120 frames for Sassy Octopus)
2. Writes a `frames.h` C header with the pixel data
3. Builds the firmware via Docker (ARM cross-compiler)
4. Copies the `.uf2` to the BOOTSEL mount

After flashing, the Pico runs the animation on its own — no PC or USB data connection needed. Just plug into any USB power source.

### Sassy Octopus

The first built-in program. A pixel-art octopus on the left side of the display with:

- **3 mouth expressions** that cycle: sassy smirk (tilted half-circle), open mouth (oval), big smile (wide arc)
- **30 unhinged quotes** in a speech bubble to the right: conspiracies, jokes, and meme statements rendered in a built-in 5x7 bitmap font
- **Chat bubble** with rounded corners and a speech tail pointing at the octopus mouth
- **"~ SASSY OCTOPUS ~"** tagline below the bubble

---

## 9. Tab 6 — GPIO Pin Reference

A read-only visual reference showing the Pico W's 40-pin header with all Dilder project assignments highlighted:

- **Display pins** (SPI1): GP8–GP13
- **Button pins**: GP2–GP6
- **Power**: 3V3(OUT), GND
- **SPI configuration**: Mode 0, 4 MHz, MSB first

This tab is a quick reference so you don't need to switch to the documentation while developing.

---

## 10. Tab 7 — Connection Utility

A guided walkthrough for connecting the Pico W to your computer. Switch between USB Serial and Wi-Fi modes using the radio buttons at the top.

### USB Serial Walkthrough

Four steps, each with a live **Check** button that verifies the current state:

| Step | What it checks |
|---|---|
| **Step 1 — Plug in the Pico W** | Runs `lsusb` to detect the Pico W USB device (vendor ID `2e8a`). Confirms the cable is a data cable. |
| **Step 2 — Verify serial port** | Checks if `/dev/ttyACM0` exists. If not, explains why (BOOTSEL mode, charge-only cable, no firmware). |
| **Step 3 — Check permissions** | Verifies your user is in the `uucp` (Arch) or `dialout` (Debian) group. Shows the fix command if not. |
| **Step 4 — Open Serial Monitor** | Links directly to the Serial Monitor tab. One click to switch over and connect. |

Each check button gives a green checkmark, yellow warning, or red error with a specific explanation.

### Wi-Fi Walkthrough

Guides you through adding Wi-Fi support to your Pico W firmware:

| Step | What it covers |
|---|---|
| **Overview** | Explains the CYW43439 Wi-Fi chip, 802.11n 2.4 GHz capability. |
| **Step 1 — Add Wi-Fi credentials** | Provides the exact C code to initialise Wi-Fi and connect to a network. Copy-paste ready. |
| **Step 2 — CMake configuration** | Shows which library to link: `pico_cyw43_arch_lwip_threadsafe_background`. |
| **Step 3 — Find Pico on network** | Network scan button that checks the ARP table for reachable devices. Shows how to print the IP from firmware. |
| **Step 4 — Communication options** | Explains TCP sockets, HTTP server, UDP broadcast, and mDNS discovery. |
| **Quick Connect** | Enter an IP and port to test a live TCP connection to the Pico W. Shows success, timeout, or connection refused. |

---

## 11. Tab 8 — Documentation

Built-in searchable documentation for the entire DevTool application.

**Layout:**
- **Left sidebar** — Table of contents. Click any section to jump to it.
- **Right panel** — Full documentation text with syntax-highlighted headings and code blocks.
- **Search bar** — Type a keyword and press Find. All matches are highlighted in yellow. Click Clear to reset.

**Sections covered:**
- Display Emulator (all tools, saving, loading, send to Pico)
- Serial Monitor (connecting, sending, special buttons, log saving)
- Flash Firmware (BOOTSEL steps, build buttons)
- Assets (browse, preview, delete)
- GPIO Pins (pin assignments)
- Connection Utility (USB and Wi-Fi)
- Keyboard Shortcuts
- File Formats (PBM, BIN, PNG with byte layout)
- Troubleshooting (common errors and fixes)

This tab means you never need to leave the DevTool to look up how something works.

---

## 12. File Formats

### PBM (Portable Bitmap — P4 Binary)

Standard 1-bit image format. Header followed by packed binary data.

```
P4
250 122
<binary data: ceil(250/8) * 122 = 3904 bytes>
```

Each byte holds 8 pixels, MSB = leftmost pixel. `1` = black, `0` = white.

### BIN (Raw Display Buffer)

No header — just the raw packed bytes in the same format the Waveshare display driver uses.

- Byte width: `ceil(250/8)` = 32 bytes per row
- Total: 32 * 122 = 3,904 bytes
- Bit order: MSB first within each byte
- `1` = black pixel, `0` = white pixel

To use in C code on the Pico W:

```c
// Load from filesystem or embed as a const array
const uint8_t image_data[3904] = { /* bin file contents */ };
EPD_2in13_V3_Display(image_data);
```

### PNG (Portable Network Graphics)

Standard PNG format, 250x122 pixels, 1-bit depth. Requires Pillow to export. Can be opened in any image viewer or editor.

---

## 13. Architecture Overview

```
tools/devtool/
    devtool.py          # Single-file application (~3,000 lines)
    requirements.txt    # Python dependencies
    README.md           # This documentation

assets/                 # Saved display images (created automatically)
    *.pbm               # PBM binary 1-bit images
    *.bin               # Raw display buffer bytes
    *.png               # PNG exports (if Pillow available)

dev-setup/
    img-receiver/       # Pico firmware: receives IMG: protocol over serial
    sassy-octopus/      # Pico firmware: standalone animation with baked-in frames
    docker-compose.yml  # Docker build services for all firmware projects
```

### Class Structure

| Class | Parent | Purpose |
|---|---|---|
| `DilderDevTool` | `tk.Tk` | Main window, notebook tabs, resizable log panel |
| `DisplayEmulator` | `ttk.Frame` | E-ink canvas, drawing tools, save/load/send |
| `SerialMonitor` | `ttk.Frame` | Serial connection, read thread, output display |
| `FlashUtility` | `ttk.Frame` | UF2 selection, BOOTSEL detection, flash copy |
| `AssetManager` | `ttk.Frame` | File list, preview canvas, delete/open |
| `ProgramsTab` | `ttk.Frame` | Program list, preview, deploy streaming/standalone, Docker build |
| `PinViewer` | `ttk.Frame` | Static GPIO reference text |
| `ConnectionUtility` | `ttk.Frame` | USB/Wi-Fi setup walkthrough with live checks |
| `DocumentationTab` | `ttk.Frame` | Searchable built-in documentation with TOC sidebar |

### Threading

The serial monitor runs a background daemon thread (`_read_loop`) that continuously reads from the serial port. All UI updates from the thread go through `winfo_toplevel().after(0, callback)` to stay on the Tkinter main thread.

Program animations, Docker builds, firmware flashing, and serial image sends all run in background threads with non-blocking serial I/O (write timeouts).

---

## 14. Troubleshooting

| Problem | Solution |
|---|---|
| `ModuleNotFoundError: No module named 'tkinter'` | Install Tk: `sudo pacman -S tk` (Arch) or `sudo apt install python3-tk` (Debian) |
| `ModuleNotFoundError: No module named 'serial'` | `pip install pyserial` (not `serial` — that's a different package) |
| Text tool renders blocks instead of letters | Install Pillow: `pip install Pillow` |
| Serial monitor can't connect | Check that the Pico W is plugged in and running firmware. Verify with `ls /dev/ttyACM*`. Check serial group membership (`groups \| grep uucp`). |
| No serial ports in dropdown | Click Refresh. If still empty, the Pico W may be in BOOTSEL mode or not connected. |
| Flash button says "not detected" | Put the Pico W in BOOTSEL mode: unplug, hold BOOTSEL, plug in, release. Then click Detect. |
| Build buttons fail | Verify `PICO_SDK_PATH` is set and `arm-none-eabi-gcc` is installed. Run `python3 setup.py --status` to check. |
| Canvas drawing is slow | The canvas uses individual rectangles per pixel at 3x scale. For large fills, there may be brief lag — this is a Tkinter limitation, not a bug. |
| PNG save/load not working | Install Pillow: `pip install Pillow`. PBM and BIN formats work without it. |

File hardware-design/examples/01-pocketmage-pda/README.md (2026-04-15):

# PocketMage PDA
[Please note that this project is in Beta]

@Ashtf 2025





# [Project Summary]
  This project is a PDA powered by an ESP32-S3 running a custom OS written in C++ using PlatformIO. This project utilizes an E-Ink and OLED screen in tandem to mitigate the refresh rate restrictions of an E-Ink panel while retaining the aesthetics and benefits of using E-Ink. This project is a work in progress and currently amounts to a simple GUI for navigating between apps, a text (.txt) file editor, and a basic file manager. More applications are planned for the future and a list of TO-DOs can be found below.

  At this point, the plan for this project is to get the software and hardware to maturity and once a finished product is achieved, a few things will happen. First, the project files (Code, KiCad schematics, 3D files) will be open-sourced and free for anyone to access. Next, I will likely begin selling kits that allow people to purchase all the parts required to build a device for themselves if they don't want to source the parts themselves. Finally, the community will be encouraged to help develop the software for the device and hopefully push it even further than I could myself.

  I will try my best to keep this GitHub up to date with the development of the device.

# [Getting Started]
**Helpful Resources:**

[FAQ](https://github.com/ashtf8/PocketMage_PDA/tree/main/Docs/Getting%20Started/FAQ)

[Tutorials](https://github.com/ashtf8/PocketMage_PDA/tree/main/Docs/Getting%20Started/Tutorials)

[PocketMage Command & Keystroke Manual](https://github.com/ashtf8/PocketMage_PDA/tree/main/Docs/Getting%20Started/Command%20Manual)

[3rd Party App Template](https://github.com/ashtf8/PocketMage_PDA/blob/main/Code/PocketMage_V3/src/APP_TEMPLATE.cpp)

  Check the [APP_TEMPLATE.cpp](./Code/PocketMage_V3/src/APP_TEMPLATE.cpp) and [/Code/PocketMage_V3/src/readme.md](./Code/PocketMage_V3/src/readme.md) file for more information. Check out the following video as a tutorial on how to create and format your app:
[Developing For the PocketMage](https://www.youtube.com/watch?v=3Ytc-3-BbMM)

# [Hardware]
- ESP32-S3 WROOM1 with 16mb flash and 8mb RAM. WiFi and Bluetooth supported.
- 3.1" 320x240px 1-bit SPI Eink panel (GDEQ031T10) with integrated driver
- 256x32px 1-bit SPI OLED (SSD1326, ER-OLED018-1W) with integrated driver
- MicroSD card slot with support for up to 2TB
- TCA8418 I2C Keyboard Matrix IC
- Piezo Buzzer (Simple Tones)
- Power Button
- 1200mAh pouch-style LiPo battery with JST PH (2mm) connector
- USB Type-C connector
- PCF8563T I2C RTC (Real Time Clock) module
- Expansion port with the following breakouts:
    - +3.3v
    - GND
    - I2C SDA
    - I2C SCL
    - SPI MOSI
    - SPI SCK
    - SPI MISO
    - GPIO A
    - GPIO B
    - GPIO C
    - GPIO D / UART TX (changeable with solder jumper, default TX)
    - GPIO E / UART RX (changeable with solder jumper, default RX)

# [Software]
- Text editor app
- FileWizard file-management app
- Calendar app
- USB file transfer app
- Settings app
- Tasks app
- Journal app
- Dictionary app (Lexicon)
- Basic commands supported through the home menu:
    - roll dN (dice roll, N=number of sides)
    - set time and date
    - directly open files in Notes or FileWiz by typing the name
    - etc.

# [Planned Features]
- Timers and alarms
- E-book reader
- WiFi notes/calendar sync (Google Docs/Calendar)
- LoRa/Meshtastic add-on module
- Battery expansion add-on module
- Custom abbreviations
- Bluetooth keyboard support

# License
All files are distributed under Apache-2.0 license:

PocketMage PDA - A clamshell note-taking and productivity device using E-Ink and OLED.



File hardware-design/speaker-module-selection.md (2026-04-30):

# Speaker Module Selection Guide — Dilder Rev 2

## Case Constraints

| Parameter | Value |
|---|---|
| Internal Z-height available | ~5 mm above board/display stack |
| Largest cavity (battery bay) | 39.0 x 41.4 x ~6 mm |
| Side gap clearance | 2-3 mm per side |
| Total case outer dims | 94.5 x 46.0 x 29.8 mm |
| MCU interface | PWM (Pico W) or I2S via PIO |

> **Key constraint:** Z-height is the tightest dimension. Speaker + amp combined
> stack must stay under ~6 mm in the battery bay, or ~5 mm elsewhere.

---

## Ultra-Budget Options (Under $1) — No Amplifier Needed

These options drive directly from a Pico W GPIO pin using PWM. No amplifier
board required. Perfect for beeps, tones, alerts, and simple melodies.

The RP2040 has hardware PWM on every GPIO pin. In MicroPython use
`machine.PWM(pin)` with `.freq()` to set pitch. In C SDK use the PWM
slice API. One GPIO pin + one ground wire.

> **Pico W GPIO limit:** Each pin sources max **12 mA** (vs 40 mA on ESP32).
> This matters for driving speakers directly — piezo buzzers are fine,
> but 8-ohm speakers need a transistor buffer.

### 1. Bare Passive Piezo Disc 12-14 mm (Recommended Budget Pick)

| Spec | Value |
|---|---|
| Dimensions | 12-14 mm dia x 0.5-1 mm thick |
| Weight | < 1 g |
| Interface | Direct GPIO PWM (1 pin) |
| Frequency range | ~1-5 kHz (loudest near resonance ~2.7 kHz) |
| Voltage | 1.5 - 5 VDC |
| Price | **$0.05-0.20 USD** |
| Sources | [eBay](https://www.ebay.com/itm/335419266914), AliExpress, [Sunrom](https://www.sunrom.com/p/piezo-passive-buzzer-14mm) |

**Pros:**
- Essentially free — as low as $0.05/ea in bulk
- Paper-thin (< 1 mm) — fits literally anywhere in the case
- Zero additional components — solder 2 wires to GPIO + GND
- No amplifier needed — piezo elements are high-impedance, GPIO can drive directly
- Negligible current draw (< 5 mA)
- Available in any quantity from eBay/AliExpress

**Cons:**
- Tinny, buzzer-like sound — no bass, no warmth
- Narrow usable frequency range (best around 2-3 kHz)
- Quiet without a resonant chamber (can print one into the case)
- Not suitable for voice or music playback
- Fragile ceramic — can crack if bent

### 2. Passive Electromagnetic Buzzer 9x5.5 mm (TMB09)

| Spec | Value |
|---|---|
| Dimensions | 9.0 mm dia x 5.5 mm thick |
| Weight | ~1 g |
| Interface | Direct GPIO PWM (1 pin) |
| Drive frequency | 2-5 kHz square wave |
| Voltage | 3 - 5 VDC |
| Current | < 30 mA |
| Price | **$0.15-0.30 USD** (10-packs ~$2-3) |
| Sources | [Amazon](https://www.amazon.com/Magnetic-Continous-TMB09A03-TMB09A05-TMB09A12/dp/B0D7S5JPJY), AliExpress, eBay |

**Pros:**
- Tiny 9 mm footprint — fits in side gaps or corners
- Louder than bare piezo disc at same voltage
- Self-contained cylindrical package — durable, no fragile ceramic
- Dirt cheap in bulk (10 for ~$2-3)
- 5.5 mm height fits within Z-constraint

**Cons:**
- Fixed resonant frequency — sounds are all "buzzy"
- 5.5 mm thick — uses full Z-budget
- 30 mA draw is higher than piezo (still fine for battery)
- Must be PASSIVE version (not active) to control pitch via PWM

### 3. Passive Electromagnetic Buzzer 12x9.5 mm (TMB12)

| Spec | Value |
|---|---|
| Dimensions | 12.0 mm dia x 9.5 mm thick |
| Interface | Direct GPIO PWM (1 pin) |
| Sound pressure | >= 85 dB @ 10 cm |
| Drive frequency | 2300 +/- 400 Hz |
| Voltage | 3 - 5 VDC |
| Current | < 30 mA |
| Price | **$0.20-0.40 USD** (10-packs ~$3-4) |
| Sources | [Amazon](https://www.amazon.com/TMB12A05-TMB12A12-Magnetic-Continous-Buzzers/dp/B0D9S9ZZMQ), AliExpress, eBay |

**Pros:**
- Loudest budget option at 85 dB
- Widely available — most common buzzer form factor
- Robust metal can housing

**Cons:**
- **Too tall at 9.5 mm** — does NOT fit the Z-constraint without case modification
- Larger footprint than TMB09
- Same buzzy sound character as TMB09

### 4. KY-006 Passive Buzzer Module

| Spec | Value |
|---|---|
| Dimensions | 18.5 x 15 x ~8 mm (with PCB) |
| Interface | 3-pin header (VCC, GND, Signal) |
| Frequency range | 1500 - 2500 Hz |
| Voltage | 3.3 - 5 VDC |
| Price | **$0.50-0.99 USD** (3-packs ~$2-3) |
| Sources | [Amazon](https://www.amazon.com/HUABAN-KY-006-Compatible-Sensor-Passive/dp/B07MV55Z6Q), AliExpress, eBay |

**Pros:**
- Breadboard/header friendly — easy to prototype first
- Tons of Pico/Arduino tutorials and example code online
- Includes PCB with labeled pins — beginner-friendly
- Can desolder buzzer from PCB to save space (buzzer itself is ~12x9 mm)

**Cons:**
- Module with PCB is 8 mm tall — too tall for case as-is
- Must desolder buzzer element to fit
- At $0.50-0.99 you're paying for the PCB you'd throw away
- Better to just buy the bare buzzer component

### 5. Bare Mini Speaker 8 ohm 0.5-1W (AliExpress)

| Spec | Value |
|---|---|
| Dimensions | 20 mm dia x 4 mm thick (typical) |
| Impedance | 8 ohm |
| Power | 0.5 - 1 W |
| Voltage | Direct GPIO (quiet) or with amp |
| Price | **$0.20-0.60 USD** |
| Sources | [AliExpress](https://www.aliexpress.com/w/wholesale-8-ohm-mini-speaker.html), eBay |

**Pros:**
- Real speaker cone — wider frequency response than piezo/buzzer
- Can play simple melodies that actually sound musical
- 4 mm thin — fits the Z-constraint with margin
- Cheapest actual speaker available

**Cons:**
- Very quiet when driven directly from GPIO (no amp)
- 8 ohm load draws ~40 mA — **exceeds Pico W 12 mA GPIO limit**
- **Must** use a transistor buffer (2N2222 + 1K resistor, ~$0.03)
- Cannot drive directly from GPIO without risking damage to RP2040
- AliExpress shipping takes 2-4 weeks

---

## Ultra-Budget Recommended Combo

### Best Sub-$1: Bare Piezo Disc + Printed Resonance Chamber

| Component | Cost |
|---|---|
| 14 mm passive piezo disc | $0.10-0.20 |
| 2 wires + solder | free (from stock) |
| Resonance cavity | print into case lid (free) |
| **Total** | **$0.10-0.20** |

- 1 GPIO pin, 0 extra boards, < 1 mm thick
- Print a small resonance chamber (dome or Helmholtz cavity) into the
  top cover to boost volume 6-10 dB
- Pico W: `pwm = machine.PWM(Pin(N)); pwm.freq(2700)` plays tones directly
- Can play melodies, alerts, startup jingles, game sounds
- Loudest at 2-3 kHz — perfect for notification beeps

### Runner-Up: TMB09 Passive Buzzer

| Component | Cost |
|---|---|
| TMB09 9x5.5mm passive buzzer | $0.15-0.30 |
| **Total** | **$0.15-0.30** |

- Self-contained, louder than bare piezo, fits the Z-constraint
- Same 1-pin PWM drive

### If You Want "Musical" Sound: AliExpress Mini Speaker + NPN Transistor

| Component | Cost |
|---|---|
| 20mm 8ohm mini speaker | $0.30-0.60 |
| 2N2222 NPN transistor | $0.02-0.05 |
| 1K base resistor | $0.01 |
| **Total** | **$0.33-0.66** |

- Transistor acts as a simple switch-amp driven by PWM GPIO
- Fuller sound than piezo — can actually hear different notes clearly
- Still no fancy amp board — 3 components total

---

## Amplifier Modules (Premium Tier — $4-6)

> The options below are for higher-fidelity audio (voice playback, WAV files,
> Bluetooth audio). Skip these if you just want beeps and tones.

### 1. Adafruit MAX98357A I2S Breakout

| Spec | Value |
|---|---|
| Dimensions | 19.4 x 17.8 x 3.0 mm |
| Weight | 1.2 g |
| Interface | I2S (no MCLK needed) |
| Output | 3.2 W @ 4 ohm, 1.8 W @ 8 ohm (5V) |
| Supply voltage | 2.7 - 5.5 VDC |
| Gain options | 3/6/9/12/15 dB (pin-selectable) |
| Price | ~$5.95 USD |
| Sources | [Adafruit](https://www.adafruit.com/product/3006), Amazon, DigiKey, Mouser |

**Pros:**
- Ultra-thin at 3.0 mm — fits within Z-height constraints
- I2S works on Pico W via PIO (3 wires: BCLK, LRCLK, DIN)
- No external MCLK required — simplifies wiring
- Combined DAC + amplifier on one board
- Extremely well-documented with Adafruit tutorials and library support
- Works on 3.3V logic (Pico W compatible)
- Pre-soldered terminal block for speaker connection
- Widely available and cheap

**Cons:**
- Mono output only (fine for notifications/alerts)
- Needs a separate speaker (not included)
- I2S on Pico W requires PIO setup (more complex than simple PWM)
- No volume control without additional code/hardware (gain is pin-set)

Adafruit MAX98357A

---

### 2. DFRobot MAX98357 I2S Module (DFR0954)

| Spec | Value |
|---|---|
| Dimensions | ~18 x 19 x 5 mm |
| Interface | I2S |
| Output | 2.5 W @ 4 ohm (5V) |
| Supply voltage | 3.3 - 5.0 VDC |
| Connector | PH2.0 + stamp holes for speaker |
| Price | ~$4.90 USD |
| Sources | [DFRobot](https://www.dfrobot.com/product-2614.html), DigiKey, The Pi Hut |

**Pros:**
- Stamp holes allow direct PCB soldering — no headers needed
- PH2.0 connector for speaker is secure and compact
- Mode switching (left/right/mixed) via SD pin resistance
- Cheap and well-stocked at multiple distributors

**Cons:**
- Slightly thicker (~5 mm) than Adafruit variant — tight fit
- Less community documentation compared to Adafruit
- Still requires separate speaker

DFRobot MAX98357

---

### 3. Adafruit PAM8302A Mono Amplifier

| Spec | Value |
|---|---|
| Dimensions | 15 x 24 x 2 mm |
| Weight | 1.4 g |
| Interface | Analog audio input (NOT I2S) |
| Output | 2.5 W @ 4-8 ohm |
| Supply voltage | 2.0 - 5.5 VDC |
| Gain | Adjustable via onboard trim pot |
| Price | ~$3.95 USD |
| Sources | [Adafruit](https://www.adafruit.com/product/2130), Amazon, DigiKey |

**Pros:**
- Thinnest amplifier option at only 2 mm
- Cheapest amplifier on this list
- Onboard volume trim pot — no software gain control needed
- Best match for Pico W — takes PWM audio output directly (analog input)
- Over 90% efficient at >0.5W into 8 ohm
- Extremely lightweight

**Cons:**
- Analog input only — pair with RC low-pass filter on Pico W PWM output
- No I2S support — but that's fine since Pico W PWM is the simpler path anyway
- Requires low-pass filter on PWM output for clean audio
- Slightly longer footprint (24 mm)

Adafruit PAM8302A

---

### 4. NULLLAB NS4168 I2S Amplifier + Speaker Kit

| Spec | Value |
|---|---|
| Amp dimensions | ~18 x 20 x 3 mm (estimated) |
| Interface | I2S |
| Output | 2.5 W mono |
| Supply voltage | 4.5 - 5.5 VDC |
| Includes | Amp board + speaker + PH2.0-to-DuPont cable |
| Price | ~$5.50 USD (2-pack ~$8.99) |
| Sources | [Amazon](https://www.amazon.com/Amplifier-Raspberry-Technology-Shielding-Compatible/dp/B0GGBRPKBT) |

**Pros:**
- Comes with speaker included — all-in-one kit
- Anti-clipping technology for cleaner audio at high volume
- RF shielding built-in
- Built-in high-pass filter
- Compatible with MAX98357A pinout (drop-in swap)
- Very cheap per unit when buying 2-pack
- Works with Pico W via PIO I2S (same as MAX98357A)

**Cons:**
- Less documentation than Adafruit/DFRobot
- Amazon-only sourcing (less reliable supply chain)
- Included speaker may be too large for case (dimensions unconfirmed)
- Newer/less proven in community projects

---

## Speaker Options

### 1. Adafruit Mini Oval Speaker (4227) — Recommended

| Spec | Value |
|---|---|
| Dimensions | 30 x 20 x 5 mm |
| Weight | 3 g |
| Impedance | 8 ohm |
| Power | 1 W rated |
| Wire length | ~10 mm (short leads) |
| Price | ~$1.50 USD |
| Sources | [Adafruit](https://www.adafruit.com/product/4227), Amazon, Pimoroni |

**Pros:**
- 5 mm thin — fits the Z-height constraint exactly
- Oval shape maximizes cone area in a narrow space
- 1W is plenty for alerts, notifications, and voice feedback
- Dirt cheap
- Short wires reduce internal clutter

**Cons:**
- 30 x 20 mm footprint takes significant cavity space
- Only 1W max — not for music playback
- 5 mm is the absolute limit of Z-clearance — no margin

Adafruit Mini Oval Speaker 4227

---

### 2. SparkFun Mini Speaker (COM-26553)

| Spec | Value |
|---|---|
| Dimensions | 20 mm dia x 4 mm thick |
| Impedance | 8 ohm |
| Power | 1 W rated |
| Wire length | ~60 mm |
| Price | ~$1.60 USD |
| Sources | [SparkFun](https://www.sparkfun.com/products/26553), Amazon |

**Pros:**
- Only 4 mm thick — leaves 1-2 mm margin in cavity
- Round 20 mm footprint is compact
- 1 W output — same as Adafruit oval
- Slightly cheaper than oval option

**Cons:**
- Smaller cone = less bass response
- 60 mm wire may need trimming for tight enclosure
- Round shape less space-efficient than oval in rectangular cavity

SparkFun Mini Speaker

---

### 3. Adafruit Mini Metal Speaker (1890)

| Spec | Value |
|---|---|
| Dimensions | 28 mm dia x 4.5 mm thick |
| Weight | 6 g |
| Impedance | 8 ohm |
| Power | 0.5 W max (0.25 W rated) |
| Frequency range | ~600 - 10,000 Hz |
| Price | ~$1.95 USD |
| Sources | [Adafruit](https://www.adafruit.com/product/1890), Amazon, Micro Center |

**Pros:**
- Metal housing is durable and provides some shielding
- 4.5 mm thin — fits within constraints
- Decent frequency range for voice/notifications
- Pre-attached wires

**Cons:**
- Only 0.5 W — quietest option on this list
- 28 mm diameter is large relative to case width (46 mm)
- Heavier than plastic alternatives (6g)
- Lower power limits maximum volume

Adafruit Mini Metal Speaker 1890

---

### 4. uxcell 20mm Round Speaker 1W 8 ohm (4-pack) — Amazon Budget Pick

| Spec | Value |
|---|---|
| Dimensions | 20 mm dia x ~4 mm thick |
| Impedance | 8 ohm |
| Power | 1 W |
| Quantity | 4 pcs |
| Price | ~$5-7 USD (~$1.50/ea) |
| Sources | [Amazon B00O9Y3YAQ](https://www.amazon.com/uxcell-Internal-Magnet-Speaker-Loudspeaker/dp/B00O9Y3YAQ), [Amazon B01MYBC1CT (2-pack)](https://www.amazon.com/uxcell-Mediant-Internal-Magnetic-Speaker/dp/B01MYBC1CT) |

**Pros:**
- Same form factor as SparkFun COM-26553 but cheaper per unit in 4-pack
- Internal magnet — no stray flux into nearby Hall sensors / joystick
- Prime shipping (vs AliExpress 2-4 week wait)
- 4 mm thick fits Z-budget with margin

**Cons:**
- Generic Chinese OEM — frequency response not characterized
- Pre-attached lead length varies between batches

---

### 5. JESSINIE Ultra-Thin 20mm Speaker 1W 8 ohm (20-pack)

| Spec | Value |
|---|---|
| Dimensions | 20 mm dia, ultra-thin profile |
| Impedance | 8 ohm |
| Power | 1 W |
| Sound pressure | 98 +/- 3 dB |
| Quantity | 20 pcs |
| Price | ~$10-13 USD (~$0.50-0.65/ea) |
| Sources | [Amazon B0G57VT7Y8](https://www.amazon.com/JESSINIE-Ultra-Thin-Speaker-8%CE%A9-1W/dp/B0G57VT7Y8) |

**Pros:**
- Cheapest per-unit on Amazon when buying the 20-pack
- 98 dB output rivals premium amp setups
- Plastic frame is lighter than metal-can speakers
- Plenty of spares for prototyping iterations

**Cons:**
- Only economical if you want bulk
- Plastic frame less rigid — needs case clamping for best bass
- Cable termination quality varies

---

### 6. IIVVERR / Aexit 30x20x4mm Oval Speaker 1W 8 ohm

| Spec | Value |
|---|---|
| Dimensions | 30 x 20 x 4 mm (oval) |
| Impedance | 8 ohm |
| Power | 1 W |
| Price | ~$4-6 USD per pair |
| Sources | [IIVVERR B086S9F83P](https://www.amazon.com/IIVVERR-Stereo-Speaker-Est%C3%A9reo-Completa/dp/B086S9F83P), [Aexit B07LFHGSTS](https://www.amazon.com/Aexit-Speakers-Stereo-Speaker-Satellite/dp/B07LFHGSTS) |

**Pros:**
- **Direct Amazon equivalent of Adafruit Mini Oval (4227)** at lower cost
- Same 30 x 20 x 4 mm footprint that already fits the battery bay
- 1 mm thinner than Adafruit oval — adds Z-margin
- Tablet-PC pull style — designed for thin-profile use

**Cons:**
- No-name brand, dimensional tolerance not guaranteed
- Listings frequently relist under different seller names
- Lead length sometimes too short for cradle-to-amp routing

---

### 7. uxcell 16mm Round Speaker 1W 8 ohm (4-pack)

| Spec | Value |
|---|---|
| Dimensions | 16 mm dia x ~3-4 mm thick |
| Impedance | 8 ohm |
| Power | 1 W |
| Quantity | 4 pcs |
| Price | ~$5-7 USD |
| Sources | [Amazon B082ZPP4P8](https://www.amazon.com/uxcell-Audio-Speaker-Electronic-Projects/dp/B082ZPP4P8) |

**Pros:**
- Smaller footprint than 20mm — fits in tighter cradle pockets or side gaps
- 1W rating in a 16mm body is unusually high
- Pre-wired with leads

**Cons:**
- Smaller cone = less low-end response
- Less common size — fewer mounting reference designs

---

### 8. DMiotech / Gump's 15mm Mini Speaker 1W 8 ohm (4-pack)

| Spec | Value |
|---|---|
| Dimensions | 15 mm dia x ~3-4 mm thick |
| Impedance | 8 ohm |
| Power | 1 W |
| Price | ~$4-6 USD per 4-pack |
| Sources | [DMiotech B0BMB423HV](https://www.amazon.com/DMiotech-Diameter-Magnetic-Replacement-Loudspeaker/dp/B0BMB423HV), [Gump's B0DG8P86YD](https://www.amazon.com/Gumps-grocery-Internal-Loudspeaker-15MM-8%CE%A9-1/dp/B0DG8P86YD) |

**Pros:**
- Same size as SparkFun PRT-20660 but with full 1W rating (vs 0.5W)
- Phone-replacement style — designed for tight enclosures
- 4-pack at SparkFun single-unit price

**Cons:**
- 15mm cone struggles with anything below 1 kHz
- Best for beeps/voice prompts, not music

---

### 9. XIITIA 3W 8 ohm Mini Speaker w/ 2.54mm Dupont (6-pack)

| Spec | Value |
|---|---|
| Impedance | 8 ohm |
| Power | 3 W |
| Connector | 2.54mm DuPont (plug-and-play) |
| Quantity | 6 pcs |
| Price | ~$8-10 USD |
| Sources | [Amazon B0D5HPQQ81](https://www.amazon.com/XIITIA-Loundspeaker-Interface-Compatible-Electronic/dp/B0D5HPQQ81) |

**Pros:**
- DuPont connector means no soldering — drop into a header on the PCB
- 3W rating gives headroom on the MAX98357A / NS4168 amps
- Great for breadboard prototyping before final assembly

**Cons:**
- Likely too thick (>5mm) for the Dilder battery bay — verify before ordering
- 3W is overkill — amps will clip first
- DuPont connector adds 2-3mm height penalty

---

### 10. Adafruit Thin Plastic Speaker 0.25W (Amazon)

| Spec | Value |
|---|---|
| Impedance | 8 ohm |
| Power | 0.25 W |
| Profile | Thin plastic frame |
| Price | ~$2-3 USD |
| Sources | [Amazon B00N4YW7G4](https://www.amazon.com/Speakers-Transducers-Plastic-Speaker-Wires/dp/B00N4YW7G4) |

**Pros:**
- Adafruit-vetted quality on Amazon Prime
- Thin profile competitive with the SparkFun 15mm option

**Cons:**
- Only 0.25W — quietest of all options listed
- Voice-only / beep duty, no music

---

### 11. SparkFun Thin Speaker (PRT-20660)

| Spec | Value |
|---|---|
| Dimensions | 15 mm dia x ~3 mm thick |
| Impedance | 8 ohm |
| Power | 0.5 W |
| Resonant frequency | ~1700 Hz |
| Price | ~$1.50 USD |
| Sources | [SparkFun](https://www.sparkfun.com/thin-speaker-0-5w.html) |

**Pros:**
- Smallest and thinnest option — only 15 mm and ~3 mm thick
- Leaves the most Z-margin of any option
- Could fit in side gaps or tight corners
- Cheapest option

**Cons:**
- Very low power (0.5 W) — limited volume
- Narrow frequency response centered around 2 kHz
- Tiny cone = tinny sound quality
- Best suited for beeps/tones rather than voice

---

## Recommended Combinations for Dilder Rev 2

### Cheapest Possible: Bare Piezo Disc ($0.10-0.20)

- 14 mm passive piezo disc soldered to 1 GPIO + GND
- Print a resonance dome into the case top cover
- `machine.PWM` for beeps, alerts, jingles
- Thinnest option — virtually no space impact

### Best Value: TMB09 Passive Buzzer ($0.15-0.30)

- 9 x 5.5 mm self-contained package
- Louder than bare piezo, fits Z-constraint
- Drop-in, no extra components

### Best Sub-$1 Audio: Mini Speaker + Transistor ($0.33-0.66)

- 20 mm AliExpress speaker + 2N2222 + 1K resistor
- Actual musical tones, wider frequency response
- Still no amp board — just 3 cheap components

### Premium: Adafruit MAX98357A + Mini Oval Speaker ($7.45)

| Component | Dimensions | Cost |
|---|---|---|
| MAX98357A amp | 19.4 x 17.8 x 3.0 mm | $5.95 |
| Mini Oval Speaker (4227) | 30 x 20 x 5 mm | $1.50 |
| **Total** | — | **$7.45** |

- I2S via Pico W PIO — voice/WAV audio playback
- Best audio quality — only needed if you want real audio playback

---

## Placement Strategy

```
 ┌──────────────────────────────────────────────────────┐
 │  USB-C                                     Display   │
 │  ┌───┐                                    connector  │
 │  │   │  ┌─────────┐  ┌────────────────┐    ┌──┐    │
 │  │   │  │ AMP     │  │   BATTERY BAY  │    │  │    │
 │  │   │  │ module  │  │   (speaker     │    │  │    │
 │  │   │  │ 19x18mm │  │    goes here)  │    │  │    │
 │  │   │  └─────────┘  │   30x20mm oval │    │  │    │
 │  └───┘                └────────────────┘    └──┘    │
 │  ← -X wall (3mm)              +X wall (1.2mm) →     │
 └──────────────────────────────────────────────────────┘
         Top-down view — cradle layer
```

**Suggested location:** Mount speaker in the battery bay area (39 x 41 mm)
with sound holes drilled/printed in the base plate. Amp module mounts
adjacent on the cradle insert. Both components are thin enough (<= 5 mm)
to fit below the PCB mounting level.

---

## Sourcing Quick Reference

| Component | Adafruit | Amazon | SparkFun | DigiKey |
|---|---|---|---|---|
| MAX98357A amp | [3006](https://www.adafruit.com/product/3006) | search "MAX98357A" | — | [search](https://www.digikey.com) |
| DFRobot MAX98357 | — | — | — | [DFR0954](https://www.digikey.com/en/products/detail/dfrobot/DFR0954/18069273) |
| PAM8302A amp | [2130](https://www.adafruit.com/product/2130) | search "PAM8302" | — | [search](https://www.digikey.com) |
| NS4168 kit | — | [B0GGBRPKBT](https://www.amazon.com/dp/B0GGBRPKBT) | — | — |
| Oval speaker | [4227](https://www.adafruit.com/product/4227) | search "Adafruit 4227" | — | — |
| Mini speaker 20mm | — | — | [26553](https://www.sparkfun.com/products/26553) | — |
| Metal speaker 28mm | [1890](https://www.adafruit.com/product/1890) | search "Adafruit 1890" | — | — |
| Thin speaker 15mm | — | — | [20660](https://www.sparkfun.com/thin-speaker-0-5w.html) | — |

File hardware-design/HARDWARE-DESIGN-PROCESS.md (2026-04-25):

# Dilder Hardware Design Process

A retrospective on how the Dilder enclosure and joystick PCB have actually
been designed (versus how engineering blogs say it should be done), and a
playbook for cutting the print-waste budget on future iterations.

This document is descriptive first — the loop we've been running for ~25
prints worth of iteration — and prescriptive second, where the experience
has surfaced clear ways to reduce wasted plastic.

---

## TL;DR

We've been running a tight **edit → preview → render → print → measure →
repeat** loop for the SCAD enclosure and a separate **schematic →
footprint → layout → autoroute → DRC** loop for the PCB. Both work, but
the SCAD loop has a print-waste tax that scales linearly with iteration
count. Most of that tax is avoidable by:

1. Doing **dimensional checks against real hardware before printing**, not
   after.
2. Replacing fit-check prints with **calibration coupons** (small parts
   that test one tolerance at a time).
3. Using **OpenSCAD presets + `export-preset.py`** to A/B variants in
   slicer rendering before printing the loser.
4. Treating **SVG layouts and 2D cross-sections** as first-class outputs
   for fit verification (cheap, instant, just as accurate as a print for
   linear dimensions).

---

## The current loop (descriptive)

### Enclosure (OpenSCAD → FDM print)

```
┌─────────────────┐     ┌─────────────────┐     ┌─────────────────┐
│ Edit .scad in   │────▶│ F5 preview in   │────▶│ Eyeball-OK?     │
│ VS Code         │     │ OpenSCAD GUI    │     │ Yes ↓  No ↑     │
└─────────────────┘     └─────────────────┘     └─────────────────┘
                                                          │
                                                          ▼
┌─────────────────┐     ┌─────────────────┐     ┌─────────────────┐
│ Print, measure, │◀────│ Slicer (Bambu/  │◀────│ scad-export.py  │
│ test fit        │     │ Orca/Prusa)     │     │ → 3MF           │
└─────────────────┘     └─────────────────┘     └─────────────────┘
        │
        ▼  measurements / fit notes
   ┌──────────────────┐
   │ Edit .scad — go  │
   │ back to top loop │
   └──────────────────┘
```

The full cycle for a single dimensional change is roughly:

| Step | Time |
|---|---|
| SCAD edit | 1–10 min |
| F5 preview | <5 s |
| `scad-export.py` → 3MF | 10–60 s (CGAL render) |
| Slice + send to printer | 1–3 min |
| **Print** | **5 min – 2 hr** depending on part |
| Cool, eject, deburr | 1–5 min |
| Fit check + measurement | 1–5 min |
| **Total per iteration** | **~10 min – 2.5 hr** |

The bottleneck is overwhelmingly the print. The SCAD edit→preview portion
is essentially free; the iteration cost is the printed plastic and the
clock time.

### PCB (KiCad → Freerouting → fab)

```
┌──────────────┐     ┌───────────────┐     ┌──────────────┐
│ Edit         │────▶│ Schematic     │────▶│ Update PCB   │
│ schematic    │     │ ERC clean?    │     │ from sch     │
└──────────────┘     └───────────────┘     └──────────────┘
                                                   │
                                                   ▼
┌──────────────┐     ┌───────────────┐     ┌──────────────┐
│ kicad-cli    │◀────│ ImportSpecctra│◀────│ Place parts; │
│ pcb drc      │     │ SES (python   │     │ ExportSpecc- │
│ → DRC clean? │     │ pcbnew)       │     │ traDSN       │
└──────────────┘     └───────────────┘     └──────────────┘
        │                                          │
        │ DRC clean                                ▼
        ▼                                  ┌──────────────┐
┌──────────────┐                           │ Freerouting  │
│ Render PNG   │                           │ headless     │
│ → blog,      │                           │ (Docker)     │
│ design-evol  │                           └──────────────┘
└──────────────┘                                   │
                                                   └─ writes .ses
```

PCB iteration is **completely free** until you fab — the whole loop runs
on the machine in seconds. The cost is shifted to the end: a wrong fab
is $15+shipping+a week. The mitigation is: never fab without `kicad-cli
pcb drc` clean, with parity against the schematic enforced.

---

## Where we've burned plastic (specific incidents)

A non-exhaustive list of prints from this project that turned out to be
mostly wasted, and what should have caught the problem upstream:

| Print | What was wrong | Could have been caught by |
|---|---|---|
| Top cover v1 (windowed) | Window 50×25 mm — wrong; Waveshare's actual viewable area is 48×27 mm | Measuring the part with calipers before cutting the window |
| Top cover v1.x (multiple) | Inlay depth wrong by 1–2 mm across several iterations | Stacking actual module + FPC and measuring with a depth gauge |
| Cradle v1 → v2 | Connecting block too small for TP4056 board (9.5 mm vs 28 mm) | Reading the TP4056 datasheet before the first print |
| Base plate v1 → v2 → v3 | USB-C notch wrong location, wrong size, wrong wall thickness | Cross-section preview in OpenSCAD against a known cable footprint |
| Joystick PCB Rev 1 | Wire pad J1.6 overlapped M3 hole; routing physically infeasible | Computing pad/hole clearances *before* drawing them — `python3` math, no print needed |

Across these, the common pattern is **physical-feature dimensions guessed
from screenshots or memory, not measured from the real component or its
datasheet**. The print catches the mistake, but at high cost.

---

## Improvements (prescriptive)

The following are concrete, low-effort changes to the current workflow
that reduce wasted prints. Ordered roughly by ROI (highest first).

### 1. Mandatory pre-print dimensional check against real hardware

Before exporting any SCAD that mates with a physical component, *the
SCAD must reference the component's measured dimensions in a comment
block*, e.g.:

```scad
// === Waveshare 2.13" e-Paper ===
// Measured 2026-04-22 with calipers:
//   Module: 48.55 x 26.90 x 1.18 mm
//   Active area: 48.0 x 27.0 mm (datasheet)
//   FPC ribbon: 6.5 mm wide, exits +X edge
//   FPC pivot (fold point): 3.2 mm from active area edge
display_width  = 48.0;  // active area, not module
display_height = 27.0;
display_thk    = 1.18;  // module top to bottom of active area
```

This forces the dimensions into the SCAD and into git. If a print later
turns out wrong, the comment block is the source of truth that gets
audited, not your memory.

**Process gate**: no `scad-export.py` until the SCAD's parametrically-
relevant dimensions all trace back to a measurement comment block.

### 2. Calibration coupons instead of full prints

A "calibration coupon" is a 20 × 20 × 5 mm test print that exercises one
tolerance: a single peg+hole pair, a single channel, a single chamfer. It
prints in 10–15 minutes on a 0.2 mm layer height and tells you exactly
the same thing as a 2-hour full-part print.

**Concrete coupons we should have**:

- `coupon-m3-clearance.scad` — 4 holes at Ø3.0/3.1/3.2/3.3 mm, label
  silkscreened next to each. Tests M3 free fit vs press fit on this
  printer/filament/temperature. Reuse the result for *every* mounting
  hole going forward.
- `coupon-usbc-port.scad` — sample wall with 4 USB-C cutouts at varying
  width × height. Plug a real cable in. Lock in the right pair.
- `coupon-snap-rib.scad` — 6 rib variants for cover/base mating.
- `coupon-batt-bay-aaa.scad` — single-cell bay at varying ID. Drop a
  battery in.

Run the coupon set **once per filament/printer combination**, then refer
to the chosen tolerances by name in subsequent SCADs. Stop guessing
tolerances afresh on every part.

### 3. SVG cross-sections for fit verification

OpenSCAD can export 2D `.svg` profiles via `projection(cut=true)`. For
linear-dimension fit checks (does this slot fit this connector?
does this pocket fit this PCB?), an SVG opened in any viewer is identical
information to a printed fit-check coupon — and free.

Workflow:

```bash
# In the SCAD, add a 'part="section_xy"' that uses projection(cut=true)
openscad -D 'part="section_xy"' -o /tmp/section.svg my-part.scad
inkscape /tmp/section.svg   # or any SVG viewer
# Measure with the viewer's ruler tool against the cable/PCB CAD
```

Add a `section_*` part to every SCAD that mates with non-trivial
hardware. F5 + view-SVG is a sub-10-second iteration loop.

### 4. OpenSCAD customizer presets + `export-preset.py` for A/B

When uncertain between two dimensional choices, **don't print both**.
Save them as customizer presets in the SCAD's JSON sidecar, render both
to 3MF with `export-preset.py`, slice both, **inspect the slicer
preview** for the actual mating geometry, and only print the one that
looks right. The slicer preview IS the dimensional truth at the
0.05 mm level for any external feature.

This caught nothing on Rev 2 because we didn't use it. It's available
now via `hardware-design/scad Parts/export-preset.py` and documented in
that folder's `README.md`.

### 5. Parametric "test slider" prints

For complex tolerance stacks (cradle insert + base plate + cover snap
fit), a single print that contains the tolerance range as a strip — say,
8 cradle bays at ±0.05 mm steps from the design value — gives 8
empirical data points per print instead of 1. This is the same idea as
calibration coupons but for compound features that can't be reduced to a
single dimension.

Build it as a SCAD with a `for(dx = [-0.2 : 0.05 : 0.2])` loop instead
of as a series of separate prints.

### 6. Treat the PCB design loop as the model

The PCB went straight from "totally broken Rev 1" to "DRC-clean, fab-
ready Rev 2" in one session because every step had a free machine-
checkable verification:

- ERC catches schematic errors before they propagate to the PCB.
- Footprint pad/hole clearances were computed in Python *before* drawing
  them, with hard distance-vs-radius assertions.
- Freerouting + `kicad-cli pcb drc` runs in 5 seconds and gives a
  binary clean/dirty answer for the entire layout.

The enclosure design loop has none of those gates. Adding them — even
just simple Python scripts that load the SCAD's known dimensions and
assert clearances against component datasheet values — would prevent the
"oh it doesn't fit" class of failures entirely.

A first version of this could be a `tools/check-clearances.py` that:

1. Reads a YAML manifest of components with measured/datasheet dimensions.
2. Reads a YAML manifest of SCAD parameters and which component they're
   constrained by.
3. Asserts the SCAD parameter is at least `component_dim + tolerance`.

Run it as a pre-commit hook. The print is now a confirmation, not an
exploration.

---

## What stays the same

The current loop's strengths are real and shouldn't be lost in
optimization:

- **F5 preview is fast enough** that geometry exploration in OpenSCAD
  (e.g. "what shape should the connecting block be?") is the right
  process. Don't try to formalize the early shape-exploration phase.
- **Real prints are the truth for non-linear properties** — surface
  finish, layer adhesion, snap-fit retention force, support visibility.
  These can't be predicted from CAD; the print is the only way.
- **Photographing prints with annotation overlays** has been valuable for
  retrospective communication (the blog posts and design-evolution doc
  are the project's collective memory). Keep doing it.

The point is not to stop printing, but to stop printing the same kind of
mistake twice.

---

## Process gates (proposed checklist)

Before committing a SCAD edit that triggers a new print, the SCAD should
satisfy:

- [ ] All parametric dimensions trace back to a measurement comment block
- [ ] At least one `section_*` part is defined for any new mating feature
- [ ] If a tolerance is being changed, the calibration coupon for that
      tolerance has been printed on the current printer/filament
- [ ] If two dimensional choices are uncertain, both are saved as
      customizer presets and rendered with `export-preset.py`

Before fabbing a PCB:

- [ ] `kicad-cli pcb drc` returns 0 copper violations, 0 unconnected,
      0 schematic-parity issues
- [ ] All footprint pad-to-hole and pad-to-pad clearances verified by
      explicit Python script (committed alongside the board)
- [ ] All pin names and net assignments traced to the manufacturer
      datasheet, with the datasheet diagram archived in the project

---

## Related documents

- [`hardware-design/scad Parts/README.md`](scad%20Parts/README.md) —
  the three Python helpers for SCAD export and presets
- [`website/docs/docs/hardware/3d-printing-pipeline.md`](../website/docs/docs/hardware/3d-printing-pipeline.md) —
  technology + service comparison for going from CAD to physical part
- [`website/docs/docs/hardware/design-evolution.md`](../website/docs/docs/hardware/design-evolution.md) —
  per-version history of every part that's been printed
- [`hardware-design/joystick-pcb/design-notes.md`](joystick-pcb/design-notes.md) —
  example of the PCB design discipline applied: dimensions, clearances,
  routing workflow all documented

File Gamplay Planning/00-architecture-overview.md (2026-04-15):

# Dilder Gameplay Architecture Overview

> System architecture, module dependencies, and data flow for the Dilder gameplay firmware.

---

## Table of Contents

1. [System Block Diagram](#1-system-block-diagram)
2. [Module Dependency Graph](#2-module-dependency-graph)
3. [Data Flow](#3-data-flow)
4. [Module Summary](#4-module-summary)
5. [Memory Map](#5-memory-map)
6. [File Organization](#6-file-organization)

---

## 1. System Block Diagram

```
┌─────────────────────────────────────────────────────────────────────┐
│                        MAIN GAME LOOP                               │
│                     (game_loop.c / game_loop.h)                     │
│                                                                     │
│   tick_update() called every 1s (configurable)                      │
│   Orchestrates all subsystems per frame                             │
└────┬──────────┬──────────┬──────────┬──────────┬──────────┬────────┘
     │          │          │          │          │          │
     ▼          ▼          ▼          ▼          ▼          ▼
┌─────────┐┌─────────┐┌─────────┐┌─────────┐┌─────────┐┌─────────┐
│ SENSOR  ││  STAT   ││ EMOTION ││  INPUT  ││ACTIVITY ││PERSIST- │
│ MANAGER ││ SYSTEM  ││ ENGINE  ││ & MENU  ││ TRACKER ││  ENCE   │
│         ││         ││         ││  & UI   ││         ││         │
│sensor.h ││ stat.h  ││emotion.h││  ui.h   ││activity.││persist. │
│         ││         ││         ││         ││    h    ││    h    │
└────┬────┘└────┬────┘└────┬────┘└────┬────┘└────┬────┘└────┬────┘
     │          │          │          │          │          │
     ▼          ▼          ▼          ▼          ▼          ▼
┌─────────┐┌─────────┐┌─────────┐┌─────────┐┌─────────┐┌─────────┐
│DIALOGUE ││  LIFE   ││PROGRESS-││ DECOR & ││TREASURE ││  TIME   │
│ SYSTEM  ││ STAGES  ││  ION    ││COSMETIC ││  HUNT   ││ MANAGER │
│         ││         ││         ││         ││         ││         │
│dialog.h ││ life.h  ││progress.││ decor.h ││treasure.││ time.h  │
│         ││         ││    h    ││         ││    h    ││         │
└─────────┘└─────────┘└─────────┘└─────────┘└─────────┘└─────────┘
     │          │          │          │          │          │
     └──────────┴──────────┴──────────┴──────────┴──────────┘
                               │
                    ┌──────────┴──────────┐
                    │   HARDWARE LAYER    │
                    │                     │
                    │  Display (EPD/SPI)  │
                    │  Buttons (GPIO)     │
                    │  Sensors (I2C/ADC)  │
                    │  Flash (LittleFS)   │
                    │  RTC (hardware)     │
                    │  WiFi (CYW43)       │
                    └─────────────────────┘
```

---

## 2. Module Dependency Graph

Arrows indicate "depends on" / "calls into":

```
game_loop ──► sensor_manager ──► [I2C drivers, ADC]
    │
    ├──► stat_system
    │        │
    │        └──► time_manager (for decay rate by time-of-day)
    │
    ├──► emotion_engine
    │        │
    │        ├──► stat_system    (reads current stats)
    │        ├──► sensor_manager (reads sensor context)
    │        └──► life_stages    (emotion set varies by stage)
    │
    ├──► input_menu_ui
    │        │
    │        ├──► stat_system    (care actions modify stats)
    │        ├──► emotion_engine (display current emotion)
    │        ├──► dialogue       (show contextual text)
    │        ├──► decor          (render equipped cosmetics)
    │        ├──► progression    (display XP, achievements)
    │        └──► [EPD display driver]
    │
    ├──► activity_tracker
    │        │
    │        ├──► sensor_manager (accelerometer, GPS)
    │        ├──► stat_system    (step bonuses affect stats)
    │        └──► progression    (step milestones grant XP)
    │
    ├──► life_stages
    │        │
    │        ├──► stat_system    (accumulated stats drive evolution)
    │        ├──► time_manager   (age triggers stage transitions)
    │        └──► progression    (evolution grants unlocks)
    │
    ├──► dialogue
    │        │
    │        ├──► emotion_engine (mood-matched quotes)
    │        ├──► life_stages    (stage-appropriate vocabulary)
    │        ├──► stat_system    (intelligence gates complexity)
    │        └──► activity_tracker (context: steps, location)
    │
    ├──► progression
    │        │
    │        ├──► stat_system    (XP sources from care)
    │        └──► decor          (unlocks cosmetics)
    │
    ├──► treasure_hunt
    │        │
    │        ├──► sensor_manager (GPS, magnetometer)
    │        ├──► activity_tracker (step milestones trigger spawns)
    │        ├──► progression    (rewards grant XP/items)
    │        └──► input_menu_ui  (compass display, collection)
    │
    └──► persistence
             │
             ├──► stat_system    (save/load stats)
             ├──► progression    (save/load XP, achievements)
             ├──► life_stages    (save/load stage, evolution data)
             ├──► activity_tracker (save/load step history)
             ├──► decor          (save/load equipped items)
             └──► [LittleFS / flash driver]
```

---

## 3. Data Flow

### Per-Tick Data Flow (1-second cycle)

```
  ┌─── SENSORS ──────────────────────────────────────────────────┐
  │                                                               │
  │  light ─────────────┐                                         │
  │  mic_level ─────────┤                                         │
  │  temperature ───────┼──► sensor_context_t ──┐                 │
  │  humidity ──────────┤                       │                 │
  │  accel_xyz ─────────┤                       │                 │
  │  gps_fix ───────────┘                       │                 │
  │                                             ▼                 │
  │  ┌────────────────────────────────────────────────────┐       │
  │  │              STAT DECAY                             │       │
  │  │                                                     │       │
  │  │  for each primary stat:                             │       │
  │  │    stat -= base_decay * stage_modifier              │       │
  │  │                     * bond_modifier                 │       │
  │  │                     * environment_modifier           │       │
  │  │                     * time_of_day_modifier           │       │
  │  │                                                     │       │
  │  │  output: stats_t (hunger, happiness, energy, ...)   │       │
  │  └───────────────────────┬─────────────────────────────┘       │
  │                          │                                     │
  │                          ▼                                     │
  │  ┌────────────────────────────────────────────────────┐       │
  │  │           EMOTION RESOLUTION                        │       │
  │  │                                                     │       │
  │  │  inputs: stats_t + sensor_context_t                 │       │
  │  │        + recent_events[] + personality_traits        │       │
  │  │                                                     │       │
  │  │  for each emotion:                                  │       │
  │  │    weight = evaluate_trigger(emotion, inputs)        │       │
  │  │                                                     │       │
  │  │  blend + hysteresis + minimum dwell                 │       │
  │  │  output: emotion_state_t (current, weight, prev)    │       │
  │  └───────────────────────┬─────────────────────────────┘       │
  │                          │                                     │
  │                          ▼                                     │
  │  ┌────────────────────────────────────────────────────┐       │
  │  │             DISPLAY UPDATE                          │       │
  │  │                                                     │       │
  │  │  if emotion changed OR dialogue triggered:          │       │
  │  │    render_octopus(emotion_state, decor, life_stage) │       │
  │  │    render_header(time, stat_icons)                   │       │
  │  │    render_dialogue(quote)                            │       │
  │  │    epd_partial_refresh()                             │       │
  │  └─────────────────────────────────────────────────────┘       │
  └────────────────────────────────────────────────────────────────┘
```

### User Interaction Data Flow

```
  BUTTON PRESS ──► input_handler ──► action_resolver
                                          │
                       ┌──────────────────┼──────────────────┐
                       ▼                  ▼                  ▼
                  CARE ACTION        MENU NAVIGATE      CONTEXT ACTION
                  (feed, clean,      (scroll, select,   (collect treasure,
                   medicine)          back)              scold)
                       │                  │                  │
                       ▼                  ▼                  ▼
                  stat_modify()     ui_transition()    game_event_fire()
                       │                  │                  │
                       ▼                  ▼                  ▼
                  +hunger/hygiene   render new screen   progression_xp_add()
                  +bond_xp                              emotion_trigger()
                  event_log()                           dialogue_show()
```

---

## 4. Module Summary

| Module | Header | Responsibility | State Owned |
|---|---|---|---|
| **Game Loop** | `game_loop.h` | Tick orchestration, sleep/wake, frame timing | `game_state_t` (running, paused, sleeping) |
| **Stat System** | `stat.h` | All stat values, decay, modification, thresholds | `stats_t`, `stat_modifiers_t` |
| **Emotion Engine** | `emotion.h` | Resolve current emotion from inputs, blend transitions | `emotion_state_t`, `emotion_weights[16]` |
| **Sensor Manager** | `sensor.h` | Poll hardware, debounce, classify events | `sensor_context_t`, `sensor_event_t` |
| **Input & Menu & UI** | `ui.h` | Button handling, menu FSM, screen composition | `menu_state_t`, `ui_screen_t` |
| **Life Stages** | `life.h` | Stage transitions, evolution branching, age tracking | `life_stage_t`, `evolution_data_t` |
| **Progression** | `progress.h` | XP, bond level, achievements, unlock gates | `progression_t`, `achievement_t[]` |
| **Dialogue** | `dialog.h` | Quote selection, context triggers, recency filter | `dialogue_state_t`, `quote_history[]` |
| **Decor & Cosmetics** | `decor.h` | Equipped items, inventory, slot management | `decor_loadout_t`, `inventory_t` |
| **Activity Tracker** | `activity.h` | Steps, distance, location, daily/weekly/monthly | `activity_t`, `location_db_t` |
| **Treasure Hunt** | `treasure.h` | Spawn, compass, proximity, collection | `treasure_t`, `hunt_state_t` |
| **Persistence** | `persist.h` | Flash read/write, save scheduling, data integrity | `save_data_t` (aggregate of all) |
| **Time Manager** | `time.h` | RTC wrapper, day/night detection, age calculation | `game_time_t` |

---

## 5. Memory Map

### RAM Budget (RP2040: 264KB total, ~200KB usable after stack/heap)

```
CATEGORY                    ESTIMATED SIZE    NOTES
─────────────────────────────────────────────────────
Display buffer              3,904 bytes       250x122 @ 1bpp
Stats + modifiers             128 bytes       Primary + secondary + hidden
Emotion state                  64 bytes       Weights array + blend state
Sensor context                 96 bytes       All sensor readings + events
Menu / UI state               256 bytes       Menu stack, screen state
Life stage data                64 bytes       Stage, evolution accumulators
Progression data              512 bytes       XP, bond, 64 achievement flags
Dialogue state                128 bytes       History ring buffer (10 entries)
Decor loadout                  32 bytes       4 slots + 8 inventory items
Activity data                 256 bytes       Step counters, location cache
Treasure hunt                  64 bytes       1 active hunt + compass state
Event ring buffer             256 bytes       Last 16 events for context
Quote string buffer           128 bytes       Current displayed quote
Location DB (WiFi FPs)      2,048 bytes       32 known locations x 64B
─────────────────────────────────────────────────────
TOTAL GAMEPLAY STATE       ~7,936 bytes       ~3% of usable RAM

Remaining for:
  Stack                    ~8,000 bytes
  Heap                    ~16,000 bytes
  Pico SDK + drivers     ~168,000 bytes
```

### Flash Budget (Pico W: 2MB, ESP32-S3: 16MB)

```
CATEGORY                    ESTIMATED SIZE    NOTES
─────────────────────────────────────────────────────
Firmware binary             ~200 KB           Code + embedded data
Quote strings                ~40 KB           800+ quotes, compressed
Font data                    ~20 KB           5 bitmap fonts
Save data (LittleFS)         ~16 KB           All persistent game state
Location database             ~8 KB           128 known WiFi fingerprints
Achievement definitions       ~4 KB           Unlock conditions table
Decor definitions             ~2 KB           Item catalog
─────────────────────────────────────────────────────
TOTAL                       ~290 KB           14% of 2MB Pico W flash
```

---

## 6. File Organization

```
dev-setup/dilder-game/
├── CMakeLists.txt
├── main.c                          # Entry point, init, main loop dispatch
│
├── game/
│   ├── game_loop.h                 # Game loop interface
│   ├── game_loop.c                 # Tick orchestration, sleep/wake
│   ├── game_state.h                # Top-level game state enum + struct
│   │
│   ├── stat.h                      # Stat types, decay API
│   ├── stat.c                      # Stat decay, modification, thresholds
│   │
│   ├── emotion.h                   # Emotion types, resolution API
│   ├── emotion.c                   # Trigger evaluation, blending
│   │
│   ├── life.h                      # Life stage types, evolution API
│   ├── life.c                      # Stage transitions, evolution calc
│   │
│   ├── dialog.h                    # Dialogue selection API
│   ├── dialog.c                    # Context matching, recency filter
│   ├── quotes.h                    # Auto-generated quote arrays (per mood/stage)
│   │
│   ├── progress.h                  # XP, bond, achievement API
│   ├── progress.c                  # Leveling, unlock checks
│   ├── achievements.h              # Achievement definition table
│   │
│   ├── decor.h                     # Decor slot + inventory API
│   ├── decor.c                     # Equip/unequip, unlock gating
│   ├── decor_catalog.h             # Item definitions
│   │
│   ├── activity.h                  # Step tracking, location API
│   ├── activity.c                  # Step milestones, WiFi geolocation
│   │
│   ├── treasure.h                  # Treasure hunt API
│   ├── treasure.c                  # Spawn, compass, proximity, collection
│   │
│   ├── persist.h                   # Save/load API
│   ├── persist.c                   # LittleFS operations, data packing
│   │
│   └── time_mgr.h / time_mgr.c    # RTC wrapper, day/night, age
│
├── sensor/
│   ├── sensor.h                    # Unified sensor context API
│   ├── sensor.c                    # Poll orchestration, event classification
│   ├── drv_light.h / drv_light.c   # BH1750 driver
│   ├── drv_mic.h / drv_mic.c       # MAX9814 ADC processing
│   ├── drv_env.h / drv_env.c       # AHT20 driver
│   ├── drv_accel.h / drv_accel.c   # LIS2DH12TR driver + pedometer
│   ├── drv_gps.h / drv_gps.c       # PA1010D NMEA parser
│   └── drv_mag.h / drv_mag.c       # QMC5883L magnetometer
│
├── ui/
│   ├── ui.h                        # UI state machine API
│   ├── ui.c                        # Screen composition, transitions
│   ├── ui_menu.h / ui_menu.c       # Menu tree navigation
│   ├── ui_render.h / ui_render.c   # Octopus renderer (existing engine)
│   ├── ui_hud.h / ui_hud.c         # Header bar, stat icons
│   ├── ui_screens.h / ui_screens.c # Special screens (stats, compass, gift box)
│   └── input.h / input.c           # Button debounce, press classification
│
├── lib/                            # Existing Pico SDK display/GPIO drivers
│   ├── Config/
│   ├── e-Paper/
│   ├── GUI/
│   └── Fonts/
│
└── data/
    ├── quote_data.c                # Compiled quote strings
    ├── achievement_data.c          # Achievement definitions
    └── decor_data.c                # Item catalog data
```

---

## Cross-Cutting Concerns

### Event System

All modules communicate side-effects through a lightweight event bus:

```c
// Any module can fire an event
event_fire(EVENT_STAT_CRITICAL, &(event_data_t){ .stat_id = STAT_HUNGER });

// Any module can register a listener
event_listen(EVENT_STAT_CRITICAL, on_stat_critical_handler);
```

This decouples modules — the stat system doesn't need to know about dialogue or emotion directly. It just fires events. See [01-core-game-loop.md](01-core-game-loop.md) for event types and dispatch.

### Error Handling

Hardware failures (sensor I2C timeout, flash write failure) are handled at the driver level with graceful degradation — the game loop continues with stale/default data. No gameplay system should crash the device.

### Build Configuration

Feature flags control which modules compile in, enabling phased rollout:

```cmake
option(DILDER_SENSORS    "Enable sensor integration (Phase 3B)"  OFF)
option(DILDER_ACTIVITY   "Enable step/location tracking (Phase 3C)" OFF)
option(DILDER_TREASURE   "Enable treasure hunts (Phase 4B)"     OFF)
option(DILDER_GPS        "Enable GPS module (Phase 4B)"         OFF)
```

---

*Next: [01-core-game-loop.md](01-core-game-loop.md) — The tick system, timing, and main loop pseudocode.*

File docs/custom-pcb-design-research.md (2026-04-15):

# Custom PCB Design Research — Dilder Board

> From breadboard prototype to purpose-built hardware: a complete research document covering PCB design tools, fabrication services, component integration, and a learning path for designing a custom Dilder board — informed by reverse-engineering the PicoTop project.

---

## Table of Contents

1. [Introduction](#1-introduction)
2. [Case Study: Reverse-Engineering the PicoTop Board](#2-case-study-reverse-engineering-the-picotop-board)
    - [2.1 Project Overview](#21-project-overview)
    - [2.2 Board Architecture](#22-board-architecture)
    - [2.3 Component Inventory](#23-component-inventory)
    - [2.4 Design Decisions](#24-design-decisions)
    - [2.5 Manufacturing Pipeline](#25-manufacturing-pipeline)
    - [2.6 Firmware Architecture](#26-firmware-architecture)
    - [2.7 Lessons for Dilder](#27-lessons-for-dilder)
3. [Dilder Custom Board — Target Specification](#3-dilder-custom-board--target-specification)
    - [3.1 Component Inventory](#31-component-inventory)
    - [3.2 Interface Map](#32-interface-map)
    - [3.3 Power Architecture](#33-power-architecture)
    - [3.4 Board Tiers (Phased Complexity)](#34-board-tiers-phased-complexity)
4. [PCB Design Tools — Open-Source Options](#4-pcb-design-tools--open-source-options)
    - [4.1 KiCad (Recommended)](#41-kicad-recommended)
    - [4.2 LibrePCB](#42-librepcb)
    - [4.3 Horizon EDA](#43-horizon-eda)
    - [4.4 Comparison Table](#44-comparison-table)
5. [The RP2040 Minimal Circuit](#5-the-rp2040-minimal-circuit)
    - [5.1 Required Components](#51-required-components)
    - [5.2 Reference Designs](#52-reference-designs)
    - [5.3 Flash Memory Requirements](#53-flash-memory-requirements)
    - [5.4 Power Regulation](#54-power-regulation)
    - [5.5 USB Circuit](#55-usb-circuit)
    - [5.6 Minimal BOM with LCSC Part Numbers](#56-minimal-bom-with-lcsc-part-numbers)
6. [From Schematic to Physical Board — The Full Workflow](#6-from-schematic-to-physical-board--the-full-workflow)
    - [6.1 Step 1 — Schematic Capture](#61-step-1--schematic-capture)
    - [6.2 Step 2 — Footprint Assignment](#62-step-2--footprint-assignment)
    - [6.3 Step 3 — PCB Layout](#63-step-3--pcb-layout)
    - [6.4 Step 4 — Design Rule Check (DRC)](#64-step-4--design-rule-check-drc)
    - [6.5 Step 5 — Gerber Export](#65-step-5--gerber-export)
    - [6.6 Step 6 — Fabrication](#66-step-6--fabrication)
    - [6.7 Step 7 — Assembly (PCBA)](#67-step-7--assembly-pcba)
    - [6.8 Step 8 — Testing and Bring-Up](#68-step-8--testing-and-bring-up)
    - [6.9 Timeline Estimate](#69-timeline-estimate)
7. [PCB Fabrication Services](#7-pcb-fabrication-services)
    - [7.1 Service Comparison](#71-service-comparison)
    - [7.2 JLCPCB Deep Dive (Recommended)](#72-jlcpcb-deep-dive-recommended)
    - [7.3 Assembly (PCBA) Options](#73-assembly-pcba-options)
    - [7.4 Shipping and Import](#74-shipping-and-import)
8. [Component Sourcing](#8-component-sourcing)
    - [8.1 Distributor Comparison](#81-distributor-comparison)
    - [8.2 LCSC + JLCPCB Integration](#82-lcsc--jlcpcb-integration)
    - [8.3 Sourcing Strategy](#83-sourcing-strategy)
9. [Dilder Board — Schematic Block Diagram](#9-dilder-board--schematic-block-diagram)
    - [9.1 System Block Diagram](#91-system-block-diagram)
    - [9.2 I2C Bus Architecture](#92-i2c-bus-architecture)
    - [9.3 Power Tree](#93-power-tree)
    - [9.4 Estimated Board Dimensions](#94-estimated-board-dimensions)
10. [Learning Path — From Zero to Custom Board](#10-learning-path--from-zero-to-custom-board)
    - [10.1 Phase A — Fundamentals (Week 1-2)](#101-phase-a--fundamentals-week-1-2)
    - [10.2 Phase B — First KiCad Project (Week 3-4)](#102-phase-b--first-kicad-project-week-3-4)
    - [10.3 Phase C — RP2040 Board Design (Week 5-8)](#103-phase-c--rp2040-board-design-week-5-8)
    - [10.4 Phase D — Dilder Board V1 (Week 9-14)](#104-phase-d--dilder-board-v1-week-9-14)
    - [10.5 Phase E — Iteration and Production (Week 15+)](#105-phase-e--iteration-and-production-week-15)
11. [Resources](#11-resources)
    - [11.1 Essential Documentation](#111-essential-documentation)
    - [11.2 Video Tutorials](#112-video-tutorials)
    - [11.3 Books](#113-books)
    - [11.4 Community](#114-community)
    - [11.5 Reference Designs and Open Hardware](#115-reference-designs-and-open-hardware)
12. [Cost Estimate — Dilder Board V1](#12-cost-estimate--dilder-board-v1)
13. [Risk Assessment and Mitigations](#13-risk-assessment-and-mitigations)
14. [Implementation Plan](#14-implementation-plan)

---

## 1. Introduction

The Dilder currently runs on a breadboard with a Raspberry Pi Pico W, a Waveshare e-ink display, and a joystick module connected via jumper wires. This works for development, but a portable, pocket-sized virtual pet needs a purpose-built PCB — a single board integrating the MCU, sensors, charging, and connectors.

This document researches what that transition looks like: the tools, the process, the costs, and the learning curve. It is informed by reverse-engineering the **PicoTop** project (https://github.com/7west/PicoTop/), which successfully designed and fabricated a custom RP2350 board using open-source tools and affordable fabrication services.

---

## 2. Case Study: Reverse-Engineering the PicoTop Board

### 2.1 Project Overview

**PicoTop** is a self-contained computer built around the **RP2350A** chip (the successor to the RP2040). It runs a custom keyboard-only OS called "WestOS" with a shell, text editor, calculator, and hangman game. It outputs 640x480 black-and-white over HDMI, takes USB keyboard input, and runs on a LiPo battery.

The project is fully open-source, with all KiCad schematics, PCB layouts, Gerber files, BOM, and firmware published on GitHub.

**Repo:** https://github.com/7west/PicoTop/

### 2.2 Board Architecture

The PicoTop board integrates everything except the monitor, keyboard, and battery:

```
┌─────────────────────────────────────────────────┐
│                 PicoTop Board Rev2               │
│                                                  │
│  ┌──────────┐   ┌──────────┐   ┌──────────┐    │
│  │ RP2350A  │   │ W25Q128  │   │ RV-3028  │    │
│  │ QFN-60   │   │ 16MB     │   │ RTC      │    │
│  │ (MCU)    │   │ Flash    │   │ (I2C)    │    │
│  └────┬─────┘   └────┬─────┘   └────┬─────┘    │
│       │              │              │            │
│  ┌────┴──────────────┴──────────────┴────┐      │
│  │            Internal Buses             │      │
│  │    SPI (Flash) / I2C (RTC) / GPIO    │      │
│  └────┬──────┬──────┬──────┬──────┬─────┘      │
│       │      │      │      │      │              │
│  ┌────┴┐ ┌──┴──┐ ┌─┴──┐ ┌┴───┐ ┌┴────┐        │
│  │HDMI │ │USB-A│ │SD  │ │USB │ │JST  │        │
│  │HSTX │ │Host │ │Card│ │-C  │ │Batt │        │
│  └─────┘ └─────┘ └────┘ └────┘ └─────┘        │
│                                                  │
│  ┌──────────┐ ┌──────────┐ ┌──────────┐        │
│  │MCP73871  │ │TPS61092  │ │RT6150B   │        │
│  │LiPo     │ │5V Boost  │ │3.3V Buck │        │
│  │Charger  │ │(for HDMI)│ │-Boost    │        │
│  └──────────┘ └──────────┘ └──────────┘        │
│                                                  │
│  12MHz Crystal    2x LEDs    3x Switches        │
│  Piezo Buzzer     Expansion Header (12-pin)     │
└─────────────────────────────────────────────────┘
```

### 2.3 Component Inventory

**Total: ~85 unique component designators, all SMD, all top-side placement.**

#### ICs (6)

| Ref | Part | Function |
|-----|---|---|
| U1 | RP2350A-QFN60 | Main MCU |
| U2 | MCP73871-2CCI/ML | LiPo battery charge management |
| U3 | TPS61092RSAR | 5V boost converter (for HDMI) |
| U4 | RT6150B-33GQW | 3.3V buck-boost regulator |
| U5 | W25Q128JVS | 16MB SPI NOR flash |
| U6 | RV-3028-C7 | Real-time clock (I2C, battery-backed) |

#### Connectors (6)

| Ref | Part | Function |
|-----|---|---|
| J1 | 2x06 pin header | Expansion: 3V3, GND, I2C, UART, GPIO, SWD |
| J2 | USB-C 6P (GCT USB4125) | USB-C power/charging input |
| J3 | MSD-7-A (CUI) | Micro SD card slot |
| J4 | USB-A1HSW6 (OST) | USB-A host for keyboard |
| J5 | JST PH 2-pin | LiPo battery connector |
| — | HSTX pins 12-19 | HDMI/DVI output (routed to connector) |

#### Passive Components

- 32 capacitors (0402/0603, 15pF to 100uF)
- 26 resistors (0402, 27R to 1M)
- 2 resistor arrays (4x0603, 220R for HDMI TMDS termination)
- 3 inductors (for power regulation)
- 3 transistors (2N7002, BSS84, BC817 — power switching)
- 2 LEDs, 1 diode, 1 piezo buzzer, 3 switches, 1 crystal (12MHz)

### 2.4 Design Decisions

Key decisions the PicoTop designer made that inform our approach:

| Decision | Rationale | Dilder Relevance |
|---|---|---|
| **Bare RP2350A chip** (not a Pico module) | Full control over layout, smaller board, custom pin routing | We should do the same — bare RP2040 gives us control over sensor placement and board size |
| **KiCad for design** | Free, open-source, industry-capable, huge community | Direct match for our needs |
| **JLCPCB for fabrication** | Cheapest, fastest, integrated LCSC parts, supports PCBA | Best option for small-run prototypes |
| **LCSC part numbers in BOM** | Direct integration with JLCPCB assembly service | Follow this pattern exactly |
| **All SMD, all top-side** | Cheaper PCBA (single-side assembly), smaller board | Standard practice for hobby boards |
| **USB-C for charging** | Modern standard, reversible connector | We should use USB-C too |
| **JST PH for battery** | Standard LiPo connector | Our battery uses Molex 1.25mm — we can add both footprints |
| **Expansion header** | Future-proofing with exposed I2C, UART, GPIO, SWD | Critical for Dilder — allows breadboarding new sensors before integrating |
| **Fabrication toolkit plugin** | KiCad plugin generates JLCPCB-ready files automatically | Huge workflow simplification |
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

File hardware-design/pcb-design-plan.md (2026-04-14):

# Dilder Custom PCB Design Plan

From breadboard prototype to a manufacturable PCB via JLCPCB. This document covers component selection, schematic design, board layout, and fabrication workflow.

---

## Phase Overview

| Phase | Description | Status |
|---|---|---|
| 1 | KiCad setup + JLCPCB tools plugin | Done |
| 2 | Component selection + LCSC part sourcing | Done |
| 3 | Schematic capture in KiCad | In Progress |
| 4 | PCB board layout + DRC | Pending |
| 5 | Gerber export + BOM/CPL generation | Pending |
| 6 | Order from JLCPCB (PCB + SMT assembly) | Pending |

---

## Phase 1 — KiCad Environment Setup

### Prerequisites

- KiCad 10.0 installed (`/usr/bin/kicad`)
- Git installed
- Python 3 installed

### Step-by-step

```bash
# 1. Run the setup script (does everything below automatically)
cd hardware-design/
python3 setup-kicad-jlcpcb.py
```

The script performs these 5 steps:

1. **Install KiCad standard libraries** — `sudo pacman -S kicad-library kicad-library-3d`
   - Provides built-in symbols/footprints (QFN-56, SOT-223, SOIC-8, crystal, connectors)
   - Required for PCB layout — without these, footprints won't resolve
   - Prompts for sudo password
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

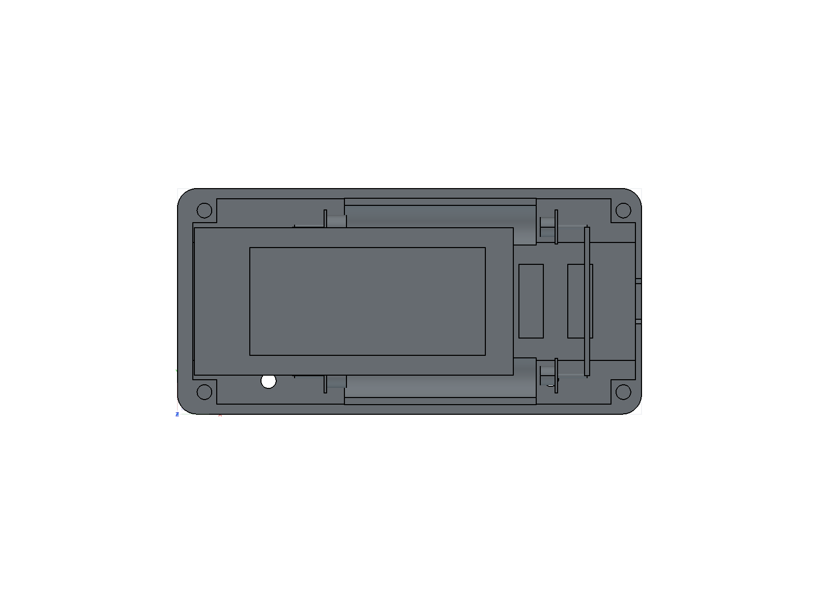
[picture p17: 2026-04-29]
hardware-design/renders/var-09-pico-on-base.png

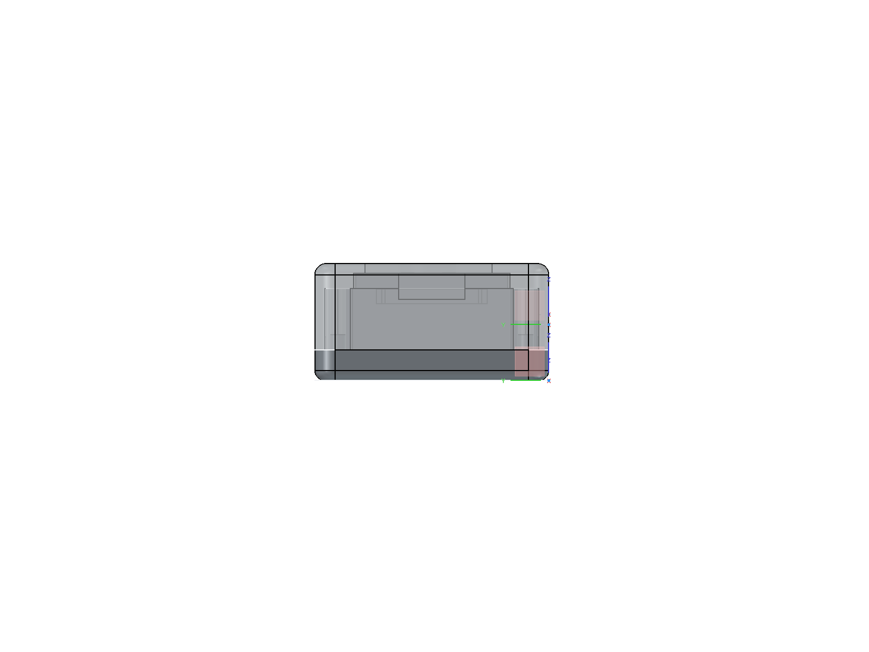
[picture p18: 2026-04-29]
hardware-design/renders/var-04-side-stack.png

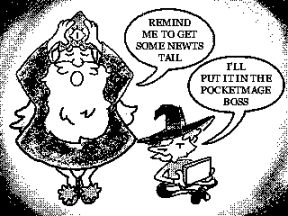
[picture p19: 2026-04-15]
hardware-design/examples/01-pocketmage-pda/Docs/Documents & Advanced/Assets/ScreenSaver/New folder/newtstail_J3.bmp

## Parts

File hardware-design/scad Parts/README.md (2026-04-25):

# SCAD Tooling — Python helper scripts

Three small Python utilities that wrap OpenSCAD's CLI for the Dilder hardware
workflow. All three discover `.scad` files automatically from this directory
and the parent `hardware-design/` tree, so you can run them from anywhere
with no arguments.

| Script | What it does | When to use |
|---|---|---|
| [`scad-export.py`](scad-export.py) | Pick a SCAD → format → output path → render | Day-to-day "I changed something, give me a 3MF for the slicer" |
| [`bake-preset.py`](bake-preset.py) | Rewrite SCAD source so a customizer preset becomes the new default | When a preset has been validated and you want it to be the file's canonical state |
| [`export-preset.py`](export-preset.py) | Export a customizer preset directly to 3MF without touching the SCAD source | A/B comparing variants of the same SCAD without committing one as the "real" version |

All three are pure-Python, only require `openscad` on `PATH`, and have a
common interactive menu style (numbered list → typed choice) plus
non-interactive flag-driven invocation for scripting.

---

## scad-export.py — interactive 3MF/STL exporter

The general-purpose driver. Most days this is the only one you need.

```bash
python3 hardware-design/scad\ Parts/scad-export.py
```

What it does, in order:

1. **Browse** — recursively finds every `.scad` in the project, sorted by mod
   time (most recent first), with a `[4] View today's models` shortcut so
   you can jump straight to whatever you've been editing.
2. **Format** — 3MF (default, recommended), STL, OFF, or AMF.
3. **Output path** — defaults to `hardware-design/enclosure-prints/<stem>.3mf`,
   override with any custom path.
4. **Part selector** — if the SCAD has a `part="..."` toggle (with comment
   listing valid values), prompts which part to render or "all".
5. **Invoke OpenSCAD** with the chosen settings.

One-shot non-interactive form:

```bash
python3 scad-export.py --file middle-plate.scad --output middle.3mf
```

### When NOT to use this

- If you have a customizer preset that captures the variant you want, use
  [`export-preset.py`](export-preset.py) — it's faster and skips the file
  browser.

---

## bake-preset.py — make a preset the new SCAD default

OpenSCAD's customizer stores presets in a sidecar `<scadname>.json`. The
GUI applies them at render time but **never modifies the source**, so a
SCAD file checked into git can drift from the preset that's actually being
used to print parts. `bake-preset.py` rewrites the source so the preset's
parameter values become the file's defaults.

```bash
# List presets in the JSON sidecar
python3 bake-preset.py base-plate-v1.scad

# Bake a preset (writes a .bak alongside the SCAD before changes)
python3 bake-preset.py base-plate-v1.scad shorten_batt_rail

# Preview the diff without writing anything
python3 bake-preset.py base-plate-v1.scad shorten_batt_rail --dry-run
```

What it changes: for every parameter in the preset, finds a line of the
form `name = <old>;` (with optional trailing `// comment`) and replaces
`<old>` with the preset's value. Comments and unrelated lines are kept
verbatim. A `.bak` file is always written first, so you can undo with
`mv name.scad.bak name.scad`.

### Limitations

- One parameter per line. Compound declarations on the same line aren't
  matched.
- Vectors and strings work; multi-line values do not.
- If a parameter is in the JSON but not in the SCAD source, it's skipped
  with a warning.

### When to use this

- The preset has been validated by an actual print and you want it to be
  the file's canonical state in git.
- You're about to fork a SCAD into a new variant and want the parent's
  current preset baked in before diverging.

### When NOT to use this

- The preset is exploratory / one-off — leave it as a JSON-only preset and
  use `export-preset.py` to render it.

---

## export-preset.py — render a preset without baking

Same SCAD/preset discovery as `bake-preset.py` (only lists SCADs that have
a sidecar JSON with `parameterSets`), but instead of rewriting the source
it just invokes OpenSCAD with `-p <json> -P <preset>` and writes
`<scadname>__<preset>.3mf` next to the SCAD.

```bash
# Interactive: pick SCAD → pick preset → write 3MF
python3 export-preset.py

# One-shot
python3 export-preset.py base-plate-v1.scad shorten_batt_rail

# Custom output path
python3 export-preset.py base-plate-v1.scad shorten_batt_rail -o /tmp/test.3mf

# Just list what's available
python3 export-preset.py --list
```

### When to use this

- A/B testing two presets of the same SCAD (you'll get
  `base-plate-v1__variant_a.3mf` and `base-plate-v1__variant_b.3mf` next
  to each other).
- You want to print a tweaked variant without committing it as the new
  default — the source file is untouched.

---

## Common gotchas

- **`openscad` not on PATH** — install it. CachyOS/Arch:
  `sudo pacman -S openscad`. Ubuntu/Debian: `sudo apt install openscad`.
  All three scripts call `shutil.which("openscad")` and bail with a
  helpful message if it's missing.
- **No JSON sidecar** — `bake-preset.py` and `export-preset.py` need
  `<scadname>.json` next to the SCAD. Save a preset in OpenSCAD's
  customizer panel (the "save preset" button) to create it.
- **Long SCAD render times** — `openscad -o file.3mf` does a full CGAL
  render. If a part takes a few minutes, that's the SCAD geometry, not
  the script. F5 in the OpenSCAD GUI is the fast preview equivalent.
- **`scad-export.py` and the part selector** — the script looks for a
  comment line of the form `// part="base" | "middle" | "all"` to detect
  multi-part files. If your SCAD uses `part = "base"` directly, add a
  comment listing the valid options so the script can find them.

---

## Adding new helper scripts

Convention for new helpers in this folder:

- Single-file Python 3, no dependencies outside the stdlib.
- Discover SCADs via `Path(__file__).resolve().parent.parent.rglob("*.scad")`.
- Both interactive (no args) and CLI (positional + flags) modes.
- Add a row to the table at the top of this README.

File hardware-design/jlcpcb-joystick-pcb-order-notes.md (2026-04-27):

# JLCPCB Joystick PCB Order Notes

## Order Details

- **Board:** Joystick Breakout PCB (hand-routed, KiCad 10)
- **Switch:** K1-1506SN-01 (Korean Hroparts, 5-way navigation, LCSC C145910)
- **Board size:** 19.6 x 19.6 mm
- **Assembly:** JLCPCB SMT (Economic PCBA)
- **Order date:** 2026-04-27

## Placement Verification Request

JLCPCB emailed a placement verification before proceeding with assembly. This is standard procedure for components where the automated system can't confidently determine orientation.

### What they asked

> "Since we are not so sure about the polarities of the components SW1 are correct or not. Could you please kindly check if the polarities and placements of the SMD components are correct in the below 2D picture?"

### What "polarity" means for a switch

The K1-1506SN-01 is a passive switch with no electrical polarity (it's not a diode or capacitor). JLCPCB uses "polarity" as a catch-all term for **component orientation/rotation**. The real question is: "Is SW1 rotated correctly so the physical directions (up/down/left/right) match your intended wiring?"

### Their verification image

JLCPCB placement verification

The image shows SW1 placed with:
- **A** (up arrow) pointing toward the top of the board (away from header pins)
- **C** (down arrow) pointing toward the bottom (toward header pins)
- **B** on the left, **D** on the right
- Red dot (pin 1 marker) on the left side

This matches the intended wiring: header labels Com/L/D/UP/R/C correspond to the correct physical directions.

### Response

"Yes, the placement and orientation of SW1 is correct. Please proceed with production."

### Why the flag was raised

Several factors likely triggered the manual review:

1. **Near-symmetric package** — the switch body is roughly square, so JLCPCB's system can't auto-detect if 0/90/180/270 degree rotation is intended
2. **CPL rotation mismatch** — KiCad and JLCPCB often disagree on what "0 degrees" means for a given footprint. Their system detects the discrepancy and flags it
3. **No clear pin 1 marker on silkscreen** — the board doesn't have a visible dot or notch near pin 1 on the fab/silkscreen layer for the engineer to cross-reference
4. **Auto-flag category** — JLCPCB flags switches, ICs, and connectors by default because a wrong rotation is costly

### Lesson learned for future orders

Add a small **pin 1 indicator** on the silkscreen layer next to the pad corresponding to pin A (or pin 1). A dot, triangle, or "A" label gives the JLCPCB engineer a visual reference and avoids the confirmation email round-trip.

## PCB Design Journey Summary

### Phase 1: Autorouted board (SKRHABE010) — abandoned

- Started with an AI-generated KiCad 8 schematic and PCB for the Alps Alpine SKRHABE010
- Footprint was hand-drawn with incorrect pad geometry (pads on wrong faces)
- Wire pad physically overlapped a mounting hole
- Three pin assignments didn't match the datasheet
- Attempted fix via `crides/kleeb` footprint clone and Freerouting autorouter
- **Result:** Working KiCad files but the part was harder to source and the design had been patched too many times

### Phase 2: Hand-routed board (K1-1506SN-01) — sent to fab

- Designed from scratch in KiCad 10
- Switched to Korean Hroparts K1-1506SN-01 (LCSC C145910) — readily available on JLCPCB
- Imported symbol and footprint via `easyeda2kicad`
- Hand-routed all traces (no autorouter)
- 19.6 x 19.6 mm board fits the 20 x 20 mm enclosure pocket
- 6-pin solder-wire header with silkscreen labels (Com/L/D/UP/R/C)
- Ground plane on back copper
- Exported gerbers + JLCPCB BOM/CPL
- **Result:** Order placed, placement verified, in production

### Current status

- PCB: **In production at JLCPCB** (placement confirmed 2026-04-27)
- Enclosure: Rev 2 with top cover (face plate curvature tuning), base plate variants (thinner, solar cutout with breakaway supports), cradle with battery clip slots
- Battery: PKCELL ICR10440 (3.7V raw Li-Ion AAA) selected for TP4056 + solar path
- Solar: AK 62x36 panel, base plate pit designed, bonding adhesive research complete
- Next: Wire batteries to Pico VSYS, test solar charging through TP4056, assemble with joystick PCB when boards arrive

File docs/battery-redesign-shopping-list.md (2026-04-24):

# Battery Redesign Shopping List — Dilder Rev 2 (04-24)

Cheap sourcing for the 10440 / dual-cell / 3000mAh battery redesign. All items compatible with the existing TP4056 USB-C charger module.

**Date:** 2026-04-24
**Related:** [solar-charging-research.md](solar-charging-research.md), `hardware-design/scad Parts/Rev 2 extended with joystick/04-24-designs-alterations/`

---

## ⚠️ Critical wiring rule

- **10440 cells are 3.7V Li-ion, NOT 1.5V AAA alkaline.** Do not use alkaline AAAs in this design.
- **Dual 10440 must be wired in PARALLEL, never series.** Series = 7.4V → destroys the TP4056 (single-cell charger only). Parallel doubles capacity (~700mAh) at 3.7V.
- Always match paralleled cells from the same batch; prefer protected cells.

---

## Option A — Dual 10440 (parallel) — for `base-v2-thin-dual-10440.scad`

### Batteries

| Item | Source | Approx price | Link |
|---|---|---|---|
| Soshine 10440 350mAh protected (2-pack) | Amazon | €10–12 | https://www.amazon.com/s?k=soshine+10440+350mah+protected |
| PKCELL 10440 350mAh (AliExpress 4-pack) | AliExpress | €4–6 | https://www.aliexpress.com/w/wholesale-10440-350mah.html |
| LiitoKala 10440 600mAh | AliExpress | €2–3/cell | https://www.aliexpress.com/w/wholesale-liitokala-10440.html |
| Windy Fire 10440 350mAh | 18650batterystore.com | ~$4/cell | https://www.18650batterystore.com/collections/10440-batteries |

### Holders & clips

| Item | Source | Approx price | Link |
|---|---|---|---|
| Dual AAA holder with wire leads (wire in parallel!) | AliExpress | €1 | https://www.aliexpress.com/w/wholesale-2-aaa-battery-holder-wire-leads.html |
| Single AAA holder with leads (×2, parallel externally) | Amazon | €3 for 10 | https://www.amazon.com/s?k=single+aaa+battery+holder+leads |
| Keystone 82 / 92 spring contacts (for SCAD-printed pockets) | LCSC | €0.20 each | https://www.lcsc.com/search?q=keystone+battery+contact |
| Nickel strip 0.1×5mm (solder tabs for flat-top cells) | AliExpress | €3/roll | https://www.aliexpress.com/w/wholesale-nickel-strip-0.1x5mm.html |

---

## Option B — Single 3000mAh LiPo — for `battery-fit-3000mah-single-on-pico`

| Item | Source | Approx price | Link |
|---|---|---|---|
| EEMB 3000mAh 103450 LiPo with JST-PH 2.0 | Amazon | €10–14 | https://www.amazon.com/s?k=eemb+3000mah+103450+jst+ph |
| Generic 103450 3000mAh 3.7V JST | AliExpress | €5–8 | https://www.aliexpress.com/w/wholesale-103450-3000mah-jst.html |
| Adafruit #328 (2500mAh, QC'd, JST-PH) | Adafruit | $15 | https://www.adafruit.com/product/328 |

---

## Wire, connectors, consumables

| Item | Source | Approx price | Link |
|---|---|---|---|
| JST-PH 2.0 pigtails (pre-crimped, 10-pack) | AliExpress | €2 | https://www.aliexpress.com/w/wholesale-jst-ph-2.0-pigtail.html |
| JST-PH 2.0 crimp kit (connectors + crimper, one-time) | Amazon | €20–25 | https://www.amazon.com/s?k=jst+ph+2.0+crimp+kit |
| Silicone hookup wire 26 AWG, 6-color spool kit | Amazon | €10 | https://www.amazon.com/s?k=bntechgo+26awg+silicone+wire+kit |
| Heat-shrink tubing assortment | AliExpress | €3 | https://www.aliexpress.com/w/wholesale-heat-shrink-tubing-assortment.html |
| 1N5817 Schottky diode (solar blocking, optional — from solar research) | LCSC | €0.05 | https://www.lcsc.com/search?q=1N5817 |

---

## Cheapest "just works" starter bundle

Sufficient to wire a parallel-10440 pack into the existing TP4056 charger:

| Qty | Item | Approx cost |
|---|---|---|
| 2 | Soshine protected 10440 350mAh | €10 |
| 1 | Dual AAA holder with leads (wire parallel) | €1 |
| 1 | JST-PH pigtail pack | €2 |
| — | Wire + heat shrink (if not on hand) | €13 |
| | **Minimum total** | **~€13** |
| | **With wire/heat-shrink kits** | **~€26** |

---

## Sanity checks before ordering

1. Confirm 10440 enclosure slot internal length is ≥43mm (10440 is 10×44mm including button top).
2. Confirm the holder you pick matches the SCAD pocket dimensions in `base-v2-thin-dual-10440.scad`.
3. If using flat-top cells, you'll need solder tabs or nickel strip — spring clips need button-top.
4. Verify protected cells fit — protection circuit adds ~2–3mm to cell length.
5. Re-read the parallel-wiring rule above before soldering.

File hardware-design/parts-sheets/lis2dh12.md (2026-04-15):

# LIS2DH12TR — 3-Axis MEMS Accelerometer

## Table of Contents

- [Quick Reference](#quick-reference)
- [What Is This Part?](#what-is-this-part)
- [How MEMS Accelerometers Work](#how-mems-accelerometers-work)
  - [The Mechanical Structure](#the-mechanical-structure)
  - [From Motion to Voltage](#from-motion-to-voltage)
  - [From Voltage to Digital Numbers](#from-voltage-to-digital-numbers)
- [Why This Part Instead of the MPU-6050](#why-this-part-instead-of-the-mpu-6050)
- [Key Specifications](#key-specifications)
- [Built-In Hardware Features](#built-in-hardware-features)
- [Operating Modes and Power](#operating-modes-and-power)
- [The I2C Interface](#the-i2c-interface)
- [Pin Connections on Dilder Board](#pin-connections-on-dilder-board)
- [Application Circuit](#application-circuit)
- [Register Map Highlights](#register-map-highlights)
- [History and Background](#history-and-background)
- [Datasheet and Sources](#datasheet-and-sources)

---

## Quick Reference

| Attribute | Value |
|---|---|
| **Manufacturer** | STMicroelectronics (Geneva, Switzerland) |
| **Part Number** | LIS2DH12TR |
| **Function** | 3-axis MEMS accelerometer with embedded pedometer |
| **Package** | LGA-12 (2 x 2 x 1 mm) |
| **LCSC** | [C110926](https://www.lcsc.com/product-detail/C110926.html) |
| **Price (qty 5)** | ~$0.46 |
| **Dilder ref** | U5 |

---

## What Is This Part?

The LIS2DH12 is a **tiny motion sensor** that detects acceleration in three dimensions (X, Y, Z). When you move, shake, tilt, tap, or drop the Dilder, this chip measures the forces involved and converts them into digital numbers the ESP32 can read.

It's only 2mm x 2mm — about the size of a sesame seed — yet inside it contains:
- A microscopic mechanical structure that flexes when forces are applied
- Analog electronics to measure that flexion
- A 12-bit analog-to-digital converter
- A digital signal processor with built-in step counter, click detector, and orientation detector
- An I2C/SPI communication interface
- A 32-sample deep FIFO buffer

In the Dilder, it provides:
- **Step counting** — tracks how many steps the user takes (pet engagement metric)
- **Tap/click detection** — tap to interact, double-tap to feed
- **Free-fall detection** — "you dropped me!" emotional reaction
- **Orientation sensing** — face-down triggers sleep mode
- **Wake-from-sleep** — any motion wakes the ESP32 from deep sleep

---

## How MEMS Accelerometers Work

MEMS stands for **Micro-Electro-Mechanical Systems** — microscopic machines built using semiconductor fabrication processes (the same photolithography used to make computer chips).

### The Mechanical Structure

Inside the LIS2DH12, etched into silicon, is a tiny mass suspended by microscopic springs. Imagine a weight hanging from four springs inside a box:

```
     Fixed frame (attached to chip package)
    ┌─────────────────────────────┐
    │   spring    spring          │
    │   ╱╲╱╲╱╲──┬──╱╲╱╲╱╲       │
    │            │                │
    │   spring ──┤── spring      │
    │   ╱╲╱╲╱╲──┤──╱╲╱╲╱╲       │
    │            │                │
    │      PROOF MASS             │
    │    (movable silicon)        │
    │            │                │
    │   spring ──┤── spring      │
    │   ╱╲╱╲╱╲──┴──╱╲╱╲╱╲       │
    └─────────────────────────────┘
```

When the device accelerates (or gravity pulls on it), the proof mass shifts relative to the fixed frame. Newton's second law: F = ma. The springs resist the displacement, reaching equilibrium where the spring force equals the inertial force. More acceleration = more displacement.

The actual MEMS structure is about 500 micrometers across (half a millimeter). The springs are beams a few micrometers wide. The proof mass moves by nanometers — billionths of a meter.

### From Motion to Voltage

The displacement is measured using **differential capacitors**. Comb-like fingers extend from both the proof mass and the fixed frame, interleaved like meshed fingers:

```
Fixed    │  │  │  │  │  │    Fixed
fingers  │  │  │  │  │  │    fingers
         │  │  │  │  │  │
    ─────┤  ├──┤  ├──┤  ├─── Proof mass fingers
         │  │  │  │  │  │
         │  │  │  │  │  │
Fixed    │  │  │  │  │  │    Fixed
fingers  │  │  │  │  │  │    fingers
```

When the proof mass shifts, the gap between one set of fingers decreases (increasing capacitance, since C = εA/d) while the gap on the other side increases (decreasing capacitance). The difference in capacitance is proportional to displacement, which is proportional to acceleration.

A charge amplifier circuit converts this tiny capacitance change (femtofarads — 10^-15 Farads) into a voltage. This is done for each axis independently (X, Y, Z), using three separate mechanical structures oriented in three perpendicular directions.

### From Voltage to Digital Numbers

The analog voltage is fed into a **sigma-delta ADC** (analog-to-digital converter). This type of ADC works by:

1. Comparing the input to a reference voltage
2. If input > reference, output a 1; else output a 0
3. Feed the result back to adjust the reference (this is the "delta" part)
4. Repeat this millions of times per second
5. A digital filter averages the stream of 1s and 0s into a high-resolution digital value

The LIS2DH12 provides up to 12-bit resolution, meaning it divides the measurement range into 4,096 discrete levels. At the ±2g range (default), each LSB (least significant bit) represents 1 mg (one-thousandth of Earth's gravity). So if you're holding the device level, the Z-axis reads approximately +1000 (≈ +1g from gravity).

---

## Why This Part Instead of the MPU-6050

The original design used an MPU-6050 — a 6-axis IMU (3-axis accelerometer + 3-axis gyroscope) at $6.88. The switch to LIS2DH12 was made because:

| Factor | MPU-6050 | LIS2DH12 |
|---|---|---|
| Cost | $6.88 | **$0.46** |
| Axes | 6 (accel + gyro) | 3 (accel only) |
| Package | 4x4mm QFN-24 | **2x2mm LGA-12** |
| Current (low-power) | 10 uA | **2 uA** |
| Current (power-down) | 5 uA | **0.5 uA** |
| Pedometer | No (software only) | **Yes (hardware)** |
| Click detection | No | **Yes (hardware)** |
| Free-fall detection | No | **Yes (hardware)** |
| 6D orientation | No | **Yes (hardware)** |
| FIFO depth | 1024 bytes | 32 samples |
| Gyroscope | Yes | No |

The Dilder has no use for a gyroscope (measuring rotational velocity). The virtual pet doesn't need to know how fast it's spinning. But it does need to count steps, detect taps, and sense orientation — all of which the LIS2DH12 does in hardware, offloading the ESP32 and enabling ultra-low-power operation.

**93% cost reduction** with better functionality for this use case.

---

## Key Specifications

| Parameter | Value |
|---|---|
| Measurement axes | 3 (X, Y, Z) |
| Resolution | 12-bit (high-res), 10-bit (normal), 8-bit (low-power) |
| Measurement range | ±2g, ±4g, ±8g, ±16g (selectable) |
| Sensitivity (±2g) | 1 mg/LSB (high-res mode) |
| Output data rate | 1 Hz to 5.376 kHz |
| Interface | I2C (up to 400 kHz) or SPI (up to 10 MHz) |
| I2C address | 0x18 (SA0=GND) or 0x19 (SA0=VDD) |
| Supply voltage | 1.71V to 3.6V |
| I/O voltage | 1.1V to VDD |
| Current (high-res, 400 Hz) | 185 uA |
| Current (low-power, 1 Hz) | 2 uA |
| Current (power-down) | 0.5 uA |
| Temperature sensor | 8-bit, ±1°C accuracy |
| FIFO | 32 samples (with watermark interrupt) |
| Interrupt pins | 2 (INT1, INT2) — fully programmable |
| Operating temp | -40°C to +85°C |

---

## Built-In Hardware Features

These features run inside the LIS2DH12's embedded logic — no ESP32 processing required:

| Feature | How It Works | Dilder Use |
|---|---|---|
| **Pedometer** | Counts periodic acceleration patterns matching human gait (configurable thresholds and debounce). Fires an interrupt per step. | Step counting for pet engagement metric |
| **Single-click** | Detects a sharp acceleration spike above a threshold on any axis, with configurable time window. | Tap to interact |
| **Double-click** | Two single-clicks within a configurable time window. | Double-tap to feed |
| **Free-fall** | All three axes simultaneously read near 0g (below threshold for configured duration). | "You dropped me!" reaction |
| **6D Orientation** | Determines which of the 6 device faces is pointing up using gravity vector direction. | Face-down = sleep mode |
| **4D Orientation** | Like 6D but ignores the Z-axis (portrait/landscape only). | Screen rotation if needed |
| **Activity/Inactivity** | Acceleration above/below a threshold for a configured duration. | Sleep when device is idle; wake on motion |
| **Wake-up** | Motion above threshold fires INT1 — can wake ESP32 from deep sleep. | Ultra-low-power idle mode |
| **FIFO watermark** | Buffers up to 32 samples internally, fires interrupt when buffer reaches a set level. | Batch-read samples without polling |

The key advantage: the ESP32 can be in deep sleep (~10 uA) while the LIS2DH12 monitors for motion at just 2 uA. When motion is detected, INT1 fires and wakes the ESP32. Total sleep current: ~12 uA.

---

## Operating Modes and Power

| Mode | ODR | Resolution | Current | Use Case |
|---|-----|---|---|---|
| Power-down | — | — | 0.5 uA | Device completely idle |
| Low-power (1 Hz) | 1 Hz | 8-bit | 2 uA | Motion-detect only (wake trigger) |
| Low-power (10 Hz) | 10 Hz | 8-bit | 3 uA | Step counting while ESP32 sleeps |
| Normal (50 Hz) | 50 Hz | 10-bit | 11 uA | General motion sensing |
| High-res (400 Hz) | 400 Hz | 12-bit | 185 uA | Detailed gesture recognition |

The Dilder will typically run at 10 Hz in low-power mode for step counting, switching to 50 Hz when the device is active for gesture/tap detection.

---

## The I2C Interface

I2C (Inter-Integrated Circuit, pronounced "I-squared-C") is a 2-wire serial bus invented by Philips (now NXP) in 1982. It uses:

- **SDA (Serial Data)** — bidirectional data line
- **SCL (Serial Clock)** — clock line driven by the master (ESP32)

Both lines are pulled HIGH by external resistors (10k in the Dilder) and devices pull them LOW to communicate. This is called **open-drain** — devices can only actively pull low; the resistors pull high when released.

Communication happens in frames:
1. Master sends START condition (SDA goes low while SCL is high)
2. Master sends 7-bit device address (0x18 for LIS2DH12) + read/write bit
3. Slave acknowledges (pulls SDA low for one clock)
4. Data bytes are exchanged (MSB first, 8 bits + ACK)
5. Master sends STOP condition (SDA goes high while SCL is high)

The LIS2DH12 supports up to 400 kHz clock speed ("Fast mode"). At this speed, reading 6 bytes of acceleration data (X, Y, Z as 16-bit values) takes about 180 microseconds.

---

## Pin Connections on Dilder Board

| LIS2DH12 Pin | Pin # | Connect To | Net | Notes |
|---|---|---|-----|---|
| VDD_I/O | 1 | 3.3V | 3V3 | I/O voltage level |
| GND | 5, 9, 12 | Ground | GND | All ground pins tied together |
| SDA/SDI | 4 | ESP32 GPIO16 | I2C_SDA | I2C data (10k pull-up) |
| SCL/SPC | 6 | ESP32 GPIO17 | I2C_SCL | I2C clock (10k pull-up) |
| SA0/SDO | 3 | GND | GND | Address bit 0 = 0 → I2C addr 0x18 |
| CS | 7 | 3.3V | 3V3 | HIGH = I2C mode (not SPI) |
| INT1 | 8 | ESP32 GPIO18 | ACCEL_INT1 | Interrupt output (active-high, push-pull) |
| INT2 | 11 | N/C | — | Not used |
| VDD | 10 | 3.3V | 3V3 | Main power supply |
| RES | 2 | N/C | — | Reserved (leave unconnected) |

---

## Application Circuit

```
                  3.3V
                   │
        ┌──[10k]──┤──[10k]──┐       3.3V    3.3V
        │         │          │        │        │
ESP32 GPIO16    GPIO17    GPIO18      │        │
  (SDA)         (SCL)     (INT1)      │        │
        │         │          │        │        │
   .────┤─────────┤──────────┤────────┤────────┤────.
   │   SDA      SCL       INT1     VDD     VDD_IO  │
   │              LIS2DH12TR                        │
   │   SA0=GND  CS=3V3   INT2=NC                   │
   │                                                │
   '────┬──────────────────────────────────────┬────'
        │          GND (pins 5, 9, 12)         │
        └──────────────┬───────────────────────┘
                       │
                      GND
```

**Decoupling:** 100nF ceramic capacitor (C7) between VDD and GND, placed as close to the chip as possible.

---

## Register Map Highlights

| Address | Name | Purpose |
|---|---|---|
| 0x0F | WHO_AM_I | Always reads 0x33 — used to verify the chip is alive |
| 0x20 | CTRL_REG1 | Data rate, low-power enable, axis enable |
| 0x22 | CTRL_REG3 | Interrupt 1 source selection |
| 0x23 | CTRL_REG4 | Full-scale range (±2/4/8/16g), high-res mode |
| 0x28-0x2D | OUT_X/Y/Z | Acceleration data (6 bytes, 16-bit per axis) |
| 0x30 | INT1_CFG | Interrupt 1 configuration (6D, 4D, threshold) |
| 0x32 | INT1_SRC | Interrupt 1 source (which event triggered) |
| 0x36 | CLICK_CFG | Click interrupt configuration (single/double, axis) |
| 0x38 | CLICK_SRC | Click interrupt source (which click, which axis) |

**First thing to do after power-up:** Read WHO_AM_I (0x0F). If it returns 0x33, the chip is communicating. If not, check I2C wiring, address, and pull-ups.

---

## History and Background

**STMicroelectronics** is a Franco-Italian semiconductor company (headquarters in Geneva, formed from the merger of SGS Microelettronica of Italy and Thomson Semiconductors of France in 1987). They're one of the world's largest chip makers, particularly strong in:
- MEMS sensors (accelerometers, gyroscopes, pressure sensors)
- Power management (the STM32 MCU family is used in everything from drones to medical devices)
- Automotive electronics

ST pioneered consumer MEMS accelerometers. Their sensors are inside most smartphones — the chip that rotates your screen when you turn your phone sideways is likely an ST accelerometer. They shipped their **10 billionth MEMS sensor** in 2018.

The **LIS2DH12** is part of ST's "femto" accelerometer family, named for the femto-scale (10^-15) capacitance changes they measure. The "TR" suffix means "tape and reel" (packaging format for pick-and-place machines). It's a successor to the popular LIS3DH, with lower power consumption and a smaller package.

**MEMS history in brief:** The concept dates to the 1960s (resonant gate transistor by Westinghouse, 1967). Analog Devices created the first commercial MEMS accelerometer (ADXL50) in 1991 for automotive airbag triggers. Consumer MEMS exploded with the Nintendo Wii (2006, which used an ST accelerometer for motion controls) and the iPhone (2007, which used one for screen rotation).

---

## Datasheet and Sources

- **STMicroelectronics official datasheet:** [LIS2DH12 Datasheet PDF](https://www.st.com/resource/en/datasheet/lis2dh12.pdf)
- **Application note — Pedometer:** [AN5005 — LIS2DH12 Pedometer Functionality](https://www.st.com/resource/en/application_note/an5005-lis2dh12-pedometer-functionality-stmicroelectronics.pdf)
- **Application note — Tilt sensing:** [AN4509 — Tilt Measurement Using ST MEMS](https://www.st.com/resource/en/application_note/an4509-tilt-measurement-using-a-lowg-3axis-accelerometer-stmicroelectronics.pdf)
- **LCSC product page:** [C110926](https://www.lcsc.com/product-detail/C110926.html)
- **Wikipedia — MEMS:** [en.wikipedia.org/wiki/Microelectromechanical_systems](https://en.wikipedia.org/wiki/Microelectromechanical_systems)
- **Wikipedia — Accelerometer:** [en.wikipedia.org/wiki/Accelerometer](https://en.wikipedia.org/wiki/Accelerometer)
- **Analog Devices — MEMS accelerometer tutorial:** [analog.com/en/analog-dialogue/articles/mems-accelerometer-pedometer.html](https://www.analog.com/en/analog-dialogue/articles/mems-accelerometer-pedometer.html)
- **ST MEMS product page:** [st.com/en/mems-and-sensors/accelerometers.html](https://www.st.com/en/mems-and-sensors/accelerometers.html)

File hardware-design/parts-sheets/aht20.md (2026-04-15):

# AHT20 — Digital Temperature & Humidity Sensor

## Table of Contents

- [Quick Reference](#quick-reference)
- [What Is This Part?](#what-is-this-part)
- [How Capacitive Humidity Sensors Work](#how-capacitive-humidity-sensors-work)
  - [The Sensing Element](#the-sensing-element)
  - [From Humidity to Capacitance Change](#from-humidity-to-capacitance-change)
  - [The Temperature Measurement](#the-temperature-measurement)
  - [Signal Conditioning and ADC](#signal-conditioning-and-adc)
- [Why This Part](#why-this-part)
- [Key Specifications](#key-specifications)
- [Pin Connections on Dilder Board](#pin-connections-on-dilder-board)
- [Application Circuit](#application-circuit)
- [Common Mistakes and Gotchas](#common-mistakes-and-gotchas)
- [I2C Bus Sharing](#i2c-bus-sharing)
- [Datasheet and Sources](#datasheet-and-sources)

---

## Quick Reference

| Attribute | Value |
|---|---|
| **Manufacturer** | Aosong (Guangzhou, China) |
| **Part Number** | AHT20 |
| **Function** | Digital temperature and humidity sensor (I2C) |
| **Package** | DFN-6 (3 x 3 x 1 mm) |
| **LCSC** | [C2757850](https://www.lcsc.com/product-detail/C2757850.html) |
| **Price (qty 5)** | ~$0.43 |
| **Dilder ref** | U6 |

---

## What Is This Part?

The AHT20 is a **combined temperature and humidity sensor** in a single 3mm x 3mm chip. It measures the air temperature and relative humidity around the Dilder and converts both into digital numbers the ESP32 can read over I2C.

It's remarkably small — about the size of a grain of rice — yet inside it contains:
- A polymer capacitive humidity sensing element that physically absorbs water molecules from the air
- A bandgap temperature sensor
- A 20-bit analog-to-digital converter for each measurement
- A calibration engine with factory-trimmed coefficients stored in OTP memory
- An I2C communication interface

In the Dilder, it provides:
- **Ambient temperature for gameplay weather sync** — the pet reacts to real-world temperature. Too hot (>28C) makes the octopus grumpy; too cold (<15C) makes it sad. The "comfort zone" of 18-24C boosts the chill emotion weight.
- **Humidity for "comfort" mechanics** — relative humidity feeds into the environment modifier for stat decay. The octopus actually likes high humidity (>70% RH) because, well, it's an octopus. Dry air (<30% RH) makes it uncomfortable.
- **Sleep mode awareness of environment** — during low-power sleep, the ESP32 can wake periodically, take a quick AHT20 reading (~80ms), update the pet's environmental state, and go back to sleep. At <0.25uA standby current, the sensor adds virtually nothing to the sleep power budget.

---

## How Capacitive Humidity Sensors Work

Most cheap humidity sensors (like the blue DHT11 module popular with Arduino beginners) use a resistive sensing approach. The AHT20 uses a **capacitive** approach, which is more accurate, more stable over time, and less affected by contamination.

### The Sensing Element

At the heart of the AHT20 is a tiny parallel-plate capacitor. But instead of air or ceramic between the plates, there's a **hygroscopic polymer** — a thin film of material that readily absorbs and releases water molecules from the surrounding air.

```
Cross-section of the humidity sensing element:

    Humid air (water molecules: o)
    o   o       o   o
    ↓   ↓       ↓   ↓
┌──────────────────────────┐
│ ░░░ Porous top electrode ░░░│  ← Permeable (lets moisture through)
├──────────────────────────┤
│                              │
│  Polymer dielectric film     │  ← Absorbs/releases H2O molecules
│  (polyimide, ~1 micrometer)  │
│                              │
├──────────────────────────┤
│▓▓▓ Bottom electrode ▓▓▓▓▓▓▓│  ← Solid (sealed)
└──────────────────────────┘
        Silicon substrate
```

The top electrode is porous — it has tiny holes or is made from a permeable material — so water vapor molecules can pass through it and reach the polymer film underneath. The bottom electrode is solid, sitting on the silicon die.

### From Humidity to Capacitance Change

The capacitance of a parallel plate capacitor is:

```
C = epsilon_0 * epsilon_r * A / d

Where:
  C         = capacitance (farads)
  epsilon_0 = permittivity of free space (8.854 x 10^-12 F/m)
  epsilon_r = relative permittivity (dielectric constant) of the material
  A         = plate area
  d         = distance between plates
```

Here's the key insight: **the dielectric constant of the polymer changes when it absorbs water**. Dry polyimide has a dielectric constant of about 3.5. Water has a dielectric constant of about 80. When the polymer absorbs water molecules, its effective dielectric constant increases, which increases the capacitance.

```
Dry air (20% RH):                    Humid air (80% RH):

┌────────────────┐                   ┌────────────────┐
│░░░ Top plate ░░│                   │░░░ Top plate ░░│
├────────────────┤                   ├────────────────┤
│  Polymer       │                   │o Polymer  o  o │
│    (few H2O)   │  C = C_dry       │ o (many H2O) o │  C = C_dry + delta_C
│                │                   │  o    o  o     │
├────────────────┤                   ├────────────────┤
│▓▓ Bottom plate▓│                   │▓▓ Bottom plate▓│
└────────────────┘                   └────────────────┘

  epsilon_r ~ 3.5                      epsilon_r ~ 5-6
  Lower capacitance                    Higher capacitance
```

The change is roughly linear: a 1% increase in relative humidity produces a proportional increase in capacitance. The AHT20's internal circuitry measures this capacitance change with high precision (20-bit resolution means it can distinguish over 1 million discrete levels across the humidity range).

The response isn't instant — water molecules need time to diffuse into and out of the polymer. Typical response time is a few seconds, which is why the datasheet specifies an ~80ms measurement time (for the electronic conversion) but recommends not polling faster than every 2 seconds (to let the polymer equilibrate).

### The Temperature Measurement

Temperature is measured using a completely separate element: a **bandgap temperature sensor**. This exploits a fundamental property of semiconductor physics.

A silicon PN junction (a diode) has a forward voltage that decreases predictably with temperature — about -2 mV/C. By running two identical transistors at different current densities and measuring the difference in their base-emitter voltages (delta V_BE), you get a voltage that is Proportional To Absolute Temperature (PTAT):

```
                 ┌─────────┐
   I1 ──────────►│ Q1      │──┐
                 │ (1x)    │  │
                 └─────────┘  │
                              ├──► Delta_VBE = (kT/q) * ln(N)
                 ┌─────────┐  │
   I2 = N*I1 ──►│ Q2      │──┘     k = Boltzmann constant
                 │ (Nx)    │        T = temperature (Kelvin)
                 └─────────┘        q = electron charge
                                    N = current density ratio
```

This voltage difference is directly proportional to absolute temperature (in Kelvin), independent of process variations. The "bandgap" name comes from the fact that the technique was originally used to create a voltage reference equal to the silicon bandgap voltage (~1.2V), but the same circuit topology gives you a temperature-proportional signal for free.

The AHT20 achieves +/-0.3C accuracy, which means the factory calibration and trimming are quite good. For context, a clinical thermometer needs +/-0.1C, so the AHT20 isn't medical grade — but it's more than adequate for "is the room hot or cold."

### Signal Conditioning and ADC

Both the humidity capacitance and the temperature voltage are tiny analog signals contaminated with noise. The AHT20 processes them through:

```
Sensing       Amplification    Analog-to-Digital     Calibration
Element  ──►  & Filtering  ──►  Conversion (ADC)  ──►  & Output
                                   20-bit

┌──────┐    ┌───────────┐    ┌─────────────┐    ┌──────────┐
│ Cap  │───►│ Charge     │───►│ Sigma-Delta  │───►│ Factory  │──► I2C
│sensor│    │ amplifier  │    │ ADC (20-bit) │    │ cal      │    out
└──────┘    │ + filter   │    └─────────────┘    │ coeffs   │
            └───────────┘                         └──────────┘
┌──────┐    ┌───────────┐    ┌─────────────┐         │
│Temp  │───►│ Diff amp   │───►│ Sigma-Delta  │────────┘
│sensor│    │ + filter   │    │ ADC (20-bit) │
└──────┘    └───────────┘    └─────────────┘
```

The sigma-delta ADC (same type used in the LIS2DH12 accelerometer) achieves high resolution by oversampling at a high rate and digitally filtering the result. 20 bits gives over 1 million counts of resolution — far more than the sensor's actual accuracy, but the extra resolution means you can average readings to reduce noise.

Factory calibration coefficients are burned into the chip's one-time-programmable (OTP) memory during manufacturing. These correct for:
- Offset errors (the sensor reads 32% RH when actual is 30%)
- Gain errors (the sensor's slope doesn't match the ideal curve)
- Cross-sensitivity (temperature affecting humidity reading and vice versa)

The calibrated output is then available over I2C as raw 20-bit values, which the host MCU converts to physical units using the formulas in the datasheet:

```
Relative Humidity (%) = (raw_humidity / 2^20) * 100

Temperature (C) = (raw_temperature / 2^20) * 200 - 50
```

---

## Why This Part

The original Dilder design documents referenced a BME280 for temperature/humidity (~$4, Bosch). The AHT20 is a much better fit for this project:

| Factor | AHT20 | SHT40 | SHTC3 | DHT11 | BME280 |
|---|---|---|---|---|---|
| **Price (LCSC qty 5)** | **$0.43** | $1.20 | $0.90 | $0.80 | $3.50 |
| **JLCPCB basic part** | Yes | No | No | No | No |
| **Package** | DFN-6, 3x3mm | DFN-4, 1.5x1.5mm | DFN-4, 2x2mm | Through-hole 4-pin | LGA-8, 2.5x2.5mm |
| **Interface** | I2C | I2C | I2C | One-wire (bit-bang) | I2C/SPI |
| **Temp accuracy** | +/-0.3C | +/-0.2C | +/-0.2C | +/-2C | +/-1C |
| **Humidity accuracy** | +/-2% RH | +/-1.8% RH | +/-2% RH | +/-5% RH | +/-3% RH |
| **Supply voltage** | 2.0-5.5V | 1.08-3.6V | 1.62-3.6V | 3.3-5.5V | 1.71-3.6V |
| **Sleep current** | <0.25uA | 0.08uA | 0.3uA | N/A | 0.1uA |
| **Measurement current** | ~23uA | ~37uA | ~260uA | ~300uA | ~350uA |
| **Extra features** | None | Heater | Heater | None | Pressure sensor |
| **I2C address** | 0x38 | 0x44 | 0x70 | N/A | 0x76/0x77 |

**Why AHT20 wins for Dilder:**

1. **Cheapest option at $0.43** — less than half the price of the next cheapest alternative. For a hobby project with a tight BOM budget (~$4.26/board), every penny matters.

2. **Available as JLCPCB basic part** — this means JLCPCB keeps it in stock for SMT assembly with no extended part fee ($3 surcharge per unique extended part). The SHT40 and SHTC3 are extended parts at JLCPCB, which adds cost.

3. **Good enough accuracy** — +/-0.3C temperature and +/-2% RH humidity is plenty for gameplay mechanics. The pet doesn't need to know the temperature to 0.1C resolution. It just needs to know "is it hot, cold, or comfortable?"

4. **Standard I2C at 0x38** — no address conflict with the LIS2DH12 (0x18) or BH1750 (0x23) on the shared bus.

5. **Wide voltage range (2.0-5.5V)** — works directly at 3.3V with no level shifting needed, and would even work at 5V if the design ever changed.

6. **Ultra-low sleep current (<0.25uA)** — contributes negligibly to the Dilder's sleep power budget. The ESP32 in deep sleep (~10uA) dominates by 40x.

The BME280 adds a barometric pressure sensor, which would be interesting for weather prediction ("your pet can sense a storm coming"), but at 8x the cost it's not justified for v0.4 of the board. The DHT11 is ruled out immediately — it uses a non-standard one-wire protocol that requires precise timing (not I2C), it's through-hole only (can't be machine-assembled), and its +/-2C accuracy is terrible.

---

## Key Specifications

| Parameter | Value |
|---|---|
| Supply voltage | 2.0V to 5.5V |
| I2C address | 0x38 (fixed, not configurable) |
| I2C speed | Standard (100 kHz) and Fast (400 kHz) |
| Temperature range | -40C to +85C |
| Temperature accuracy | +/-0.3C (typical, at 25C) |
| Temperature resolution | 0.01C (20-bit raw) |
| Humidity range | 0% to 100% RH |
| Humidity accuracy | +/-2% RH (typical, 25C, 20-80% range) |
| Humidity resolution | 0.024% RH (20-bit raw) |
| Measurement current | ~23uA (during conversion) |
| Standby current | <0.25uA |
| Measurement time | ~80ms (typical for both temp + humidity) |
| Response time (humidity) | ~8 seconds (63% step response in still air) |
| Package | DFN-6, 3.0 x 3.0 x 1.0 mm |
| Operating temperature | -40C to +85C |
| Long-term drift (humidity) | <0.25% RH/year |

---

## Pin Connections on Dilder Board

The AHT20 comes in a 6-pin DFN package. Not all pins are used — pin 3 and pin 4 are listed as NC (no connect) in the datasheet.

| AHT20 Pin | Pin # | Connect To | Net | Notes |
|---|---|---|-----|---|
| VDD | 1 | 3.3V | 3V3 | Power supply (2.0-5.5V range) |
| SDA | 2 | ESP32 GPIO16 | I2C_SDA | I2C data (shared bus, 10k pull-up R4) |
| GND | 3 | Ground | GND | Ground |
| NC | 4 | — | — | No connect (leave unconnected) |
| NC | 5 | — | — | No connect (leave unconnected) |
| SCL | 6 | ESP32 GPIO17 | I2C_SCL | I2C clock (shared bus, 10k pull-up R5) |

The I2C pull-up resistors R4 (10k on SDA) and R5 (10k on SCL) are already on the Dilder board for the LIS2DH12 accelerometer. **No additional pull-ups are needed** — the AHT20 simply connects to the same SDA and SCL lines. One set of pull-ups serves the entire I2C bus regardless of how many devices are on it.

---

## Application Circuit

```
                       3.3V (3V3 rail)
                         │
                         │
              ┌──────────┼──────────────────────────────────┐
              │          │                                    │
              │        ┌─┴─┐                                  │
              │        │   │ C_AHT (100nF)                    │
              │        │   │ decoupling                       │
              │        └─┬─┘                                  │
              │          │                                    │
         R4 [10k]   R5 [10k]                                 │
              │          │                                    │
ESP32 GPIO16 ─┤──────────┤                                    │
   (SDA)      │          │                                    │
              │   ESP32 GPIO17                                │
              │    (SCL)  │                                    │
              │          │                                    │
         .────┤──────────┤────────────────────────────────────┤───.
         │   SDA       SCL                                  VDD   │
         │                                                        │
         │                    AHT20                               │
         │                                                        │
         │              NC (pin 4)    NC (pin 5)                  │
         │                                                        │
         '────────────────────────┬───────────────────────────────'
                                  │
                               GND (pin 3)
                                  │
                                 GND

  Shared I2C bus (same physical wires):
  ┌─────────────────────────────────┐
  │  SDA (GPIO16) ──────────────────┤──► LIS2DH12 (U5) @ 0x18
  │                                 ├──► AHT20    (U6) @ 0x38
  │                                 └──► BH1750   (U7) @ 0x23
  │  SCL (GPIO17) ──────────────────┤──► LIS2DH12 (U5)
  │                                 ├──► AHT20    (U6)
  │                                 └──► BH1750   (U7)
  └─────────────────────────────────┘
```

**Decoupling:** A 100nF ceramic capacitor placed as close to the AHT20's VDD pin as possible. This filters high-frequency noise from the power supply that could affect measurement accuracy. The AHT20 datasheet specifically recommends a 100nF cap on VDD.

**No additional components required.** The AHT20 is one of the simplest sensors to integrate — just power, ground, and two I2C wires. No external oscillator, no reference resistors, no configuration pins.

---

## Common Mistakes and Gotchas

### 1. Forgetting the 20ms Initialization Delay

After power-up, the AHT20 needs at least **20ms** before it's ready to accept commands. During this time, it loads calibration coefficients from internal OTP memory into working registers. If you send a measurement command too early, you'll get garbage data or a NACK.

```c
// Correct startup sequence:
power_on();
delay_ms(40);                    // Datasheet says 20ms; use 40ms for margin

// Check calibration status
uint8_t status = i2c_read_byte(0x38, 0x71);
if (!(status & 0x08)) {
    // Bit 3 = calibrated flag. If not set, send init command:
    uint8_t init_cmd[] = {0xBE, 0x08, 0x00};
    i2c_write(0x38, init_cmd, 3);
    delay_ms(10);
}
```
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

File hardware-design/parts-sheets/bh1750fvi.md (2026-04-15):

# BH1750FVI-TR — Digital Ambient Light Sensor

## Table of Contents

- [Quick Reference](#quick-reference)
- [What Is This Part?](#what-is-this-part)
- [How Photodiode Light Sensors Work](#how-photodiode-light-sensors-work)
  - [The Photodiode](#the-photodiode)
  - [Integration — Accumulating Light Over Time](#integration--accumulating-light-over-time)
  - [The ADC — From Charge to Lux](#the-adc--from-charge-to-lux)
  - [Spectral Response — Seeing Like a Human Eye](#spectral-response--seeing-like-a-human-eye)
  - [Why This Is Better Than a Raw LDR](#why-this-is-better-than-a-raw-ldr)
- [Why This Part](#why-this-part)
- [Key Specifications](#key-specifications)
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

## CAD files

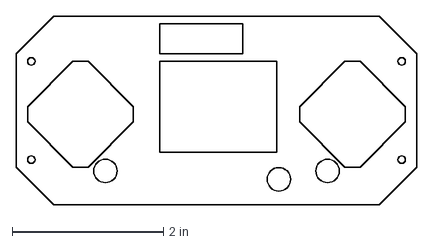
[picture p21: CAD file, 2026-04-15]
hardware-design/examples/02-lilka-console/hardware/v2/main-User_Case.dxf
5.30 x 2.50 in

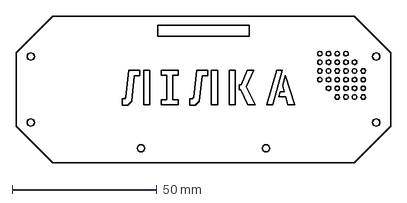
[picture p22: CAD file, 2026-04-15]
hardware-design/examples/02-lilka-console/hardware/v2/v23/case/main-User_Case.dxf
129.5 x 50.8 mm

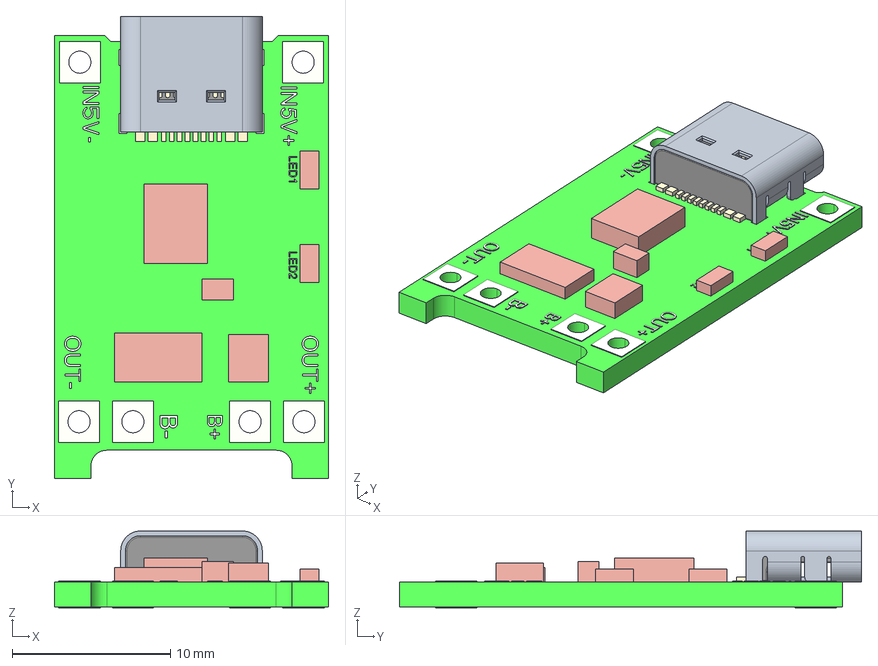
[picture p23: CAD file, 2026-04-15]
hardware-design/examples/02-lilka-console/hardware/v2/3dmodels/tp4056_pcb_asm.stp
17.3 x 29.2 x 4.86 mm
TP4056_PCB
PRT0001
PRT0002
PRT0003
PRT0004
PRT0005 x 2
BOSS-EXTRUDE14_8_
BOSS-EXTRUDE7_4_
BOSS-EXTRUDE7_3_
BOSS-EXTRUDE14_4_
BOSS-EXTRUDE14_2_
BOSS-EXTRUDE14_11_
BOSS-EXTRUDE7_7_
BOSS-EXTRUDE14_9_
BOSS-EXTRUDE14_3_
BOSS-EXTRUDE14_7_
MIRROR2
BOSS-EXTRUDE14_5_
BOSS-EXTRUDE14_12_
BOSS-EXTRUDE7_8_
BOSS-EXTRUDE7_1_
BOSS-EXTRUDE14_10_
BOSS-EXTRUDE7_9_
BOSS-EXTRUDE14_6_
BOSS-EXTRUDE14_1_
BOSS-EXTRUDE7_6_
BOSS-EXTRUDE7_2_
CUT-EXTRUDE5
BOSS-EXTRUDE7_5_

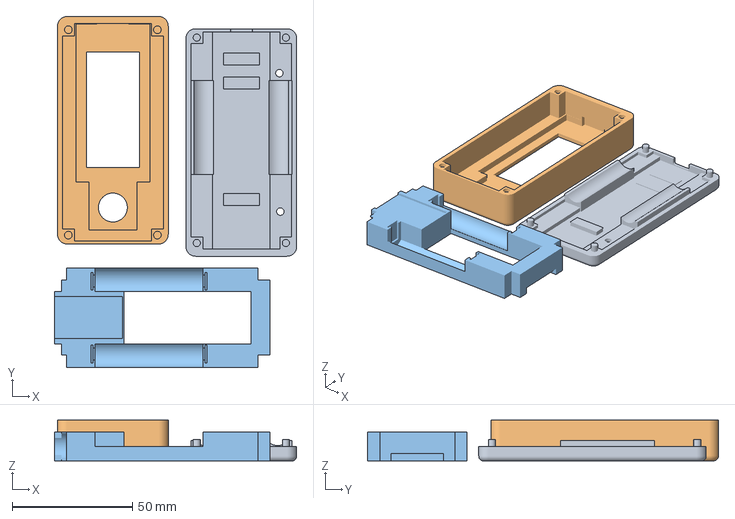
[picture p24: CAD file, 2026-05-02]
hardware-design/freecad-mk2/DilderFull Case Print out 29.04.3mf
100.7 x 145.8 x 17.0 mm

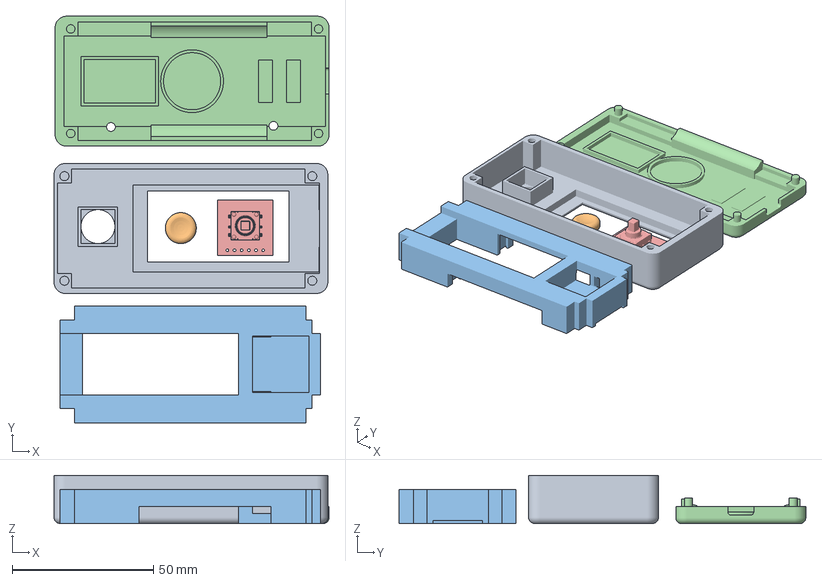
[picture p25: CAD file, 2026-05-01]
hardware-design/freecad-mk2/Dilder_Rev2_Mk2 2mm longer line base plate rails for wiring 01-05-2026-full print .3mf
97.3 x 143.9 x 17.0 mm

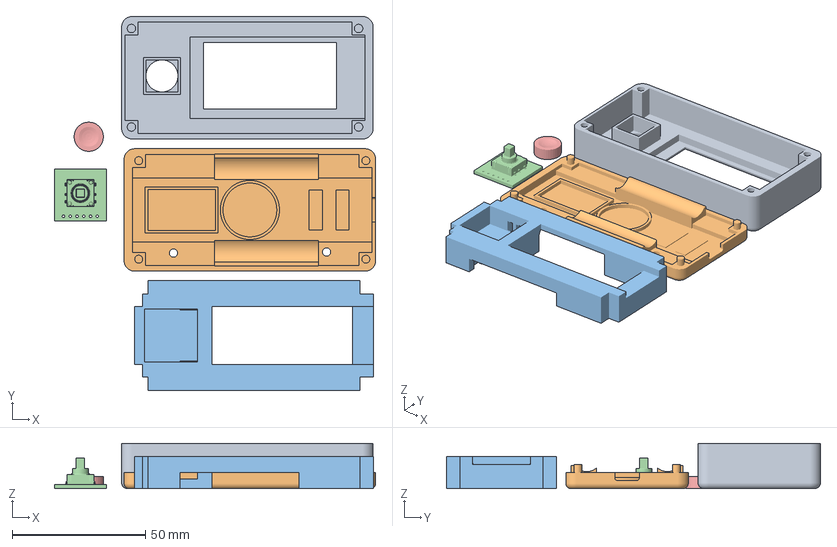
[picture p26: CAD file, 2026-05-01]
hardware-design/freecad-mk2/TH full Shebang proper fits 4-30-2026.3mf
120.7 x 140.5 x 17.0 mm

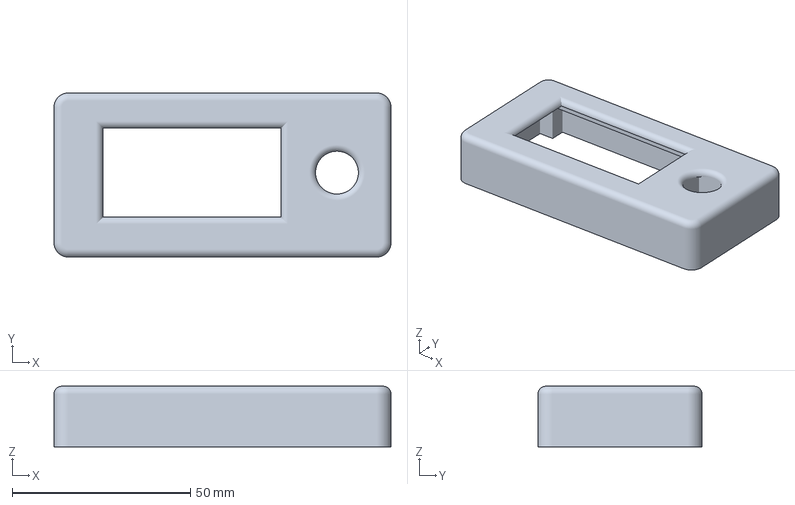
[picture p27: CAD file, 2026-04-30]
hardware-design/freecad-mk2/Dilder_Rev2_Mk2Full parts so far with joystick model with battery assembly even closer joystick and pit refined and cradle curvature fixed pcbjoystick anchor-TopCover.3mf
94.5 x 46.0 x 17.0 mm

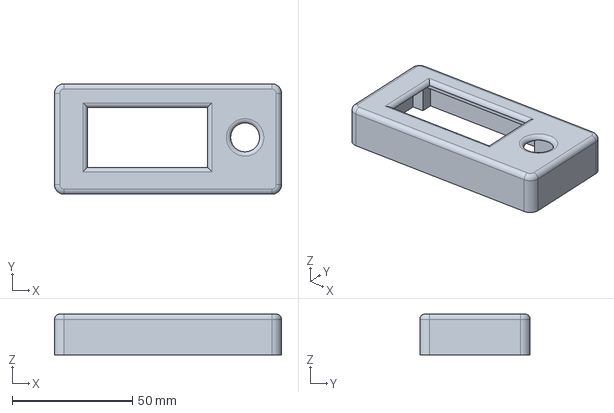
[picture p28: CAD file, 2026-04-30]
hardware-design/freecad-mk2/Dilder_Rev2_Mk2Full parts so far with joystick model with battery assembly even closer joystick and pit refined and cradle curvature fixed .FCStd
94.5 x 46.0 x 17.0 mm

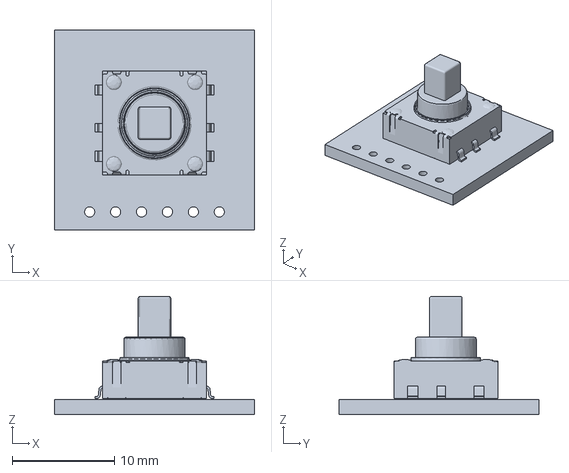
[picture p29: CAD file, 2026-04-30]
hardware-design/freecad-mk2/Dilder_Rev2_Mk2Full parts so far with joystick model with battery assembly even closer joystick and pit refined and cradle curvature fixed -JoystickPCB.3mf
19.6 x 19.6 x 11.6 mm

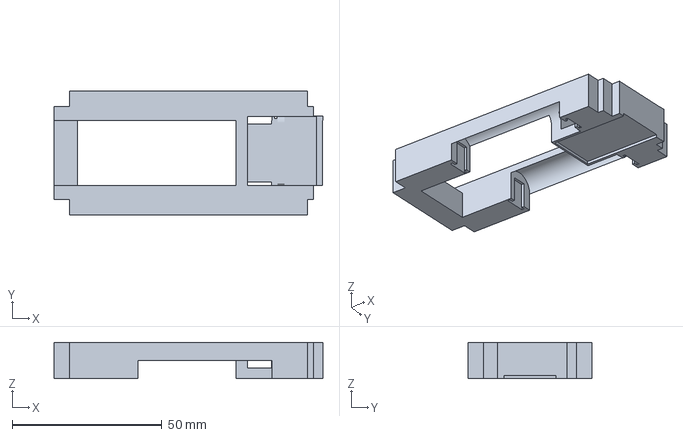
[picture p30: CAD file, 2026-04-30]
hardware-design/freecad-mk2/Dilder_Rev2_Mk2Full parts so far with joystick model with battery assembly even closer joystick and pit refined and cradle curvature fixed -AAACradle.3mf
89.8 x 41.4 x 12.1 mm

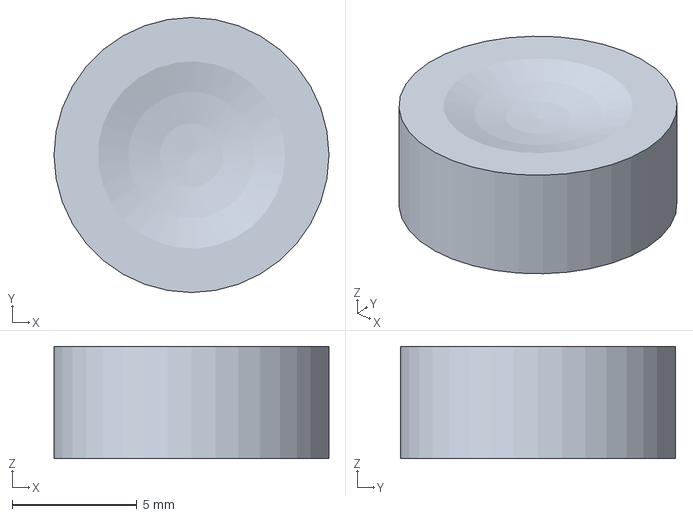
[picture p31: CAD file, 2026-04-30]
hardware-design/freecad-mk2/Dilder_Rev2_Mk2Full parts so far with joystick model with battery assembly even closer joystick and pit refined and cradle curvature fixed -Thumbpiece.3mf
11.0 x 11.0 x 4.50 mm

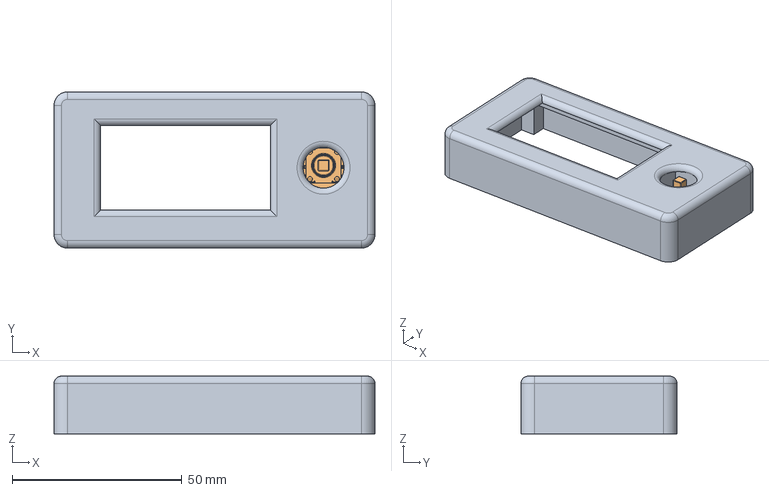
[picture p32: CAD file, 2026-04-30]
hardware-design/freecad-mk2/Dilder_Rev2_Mk2Full parts so far with joystick model with battery assembly even closer joystick and pit refined and cradle curvature fixed pcbjoystick anchor.FCStd
94.5 x 46.0 x 17.0 mm
TopCover
JoystickPCB

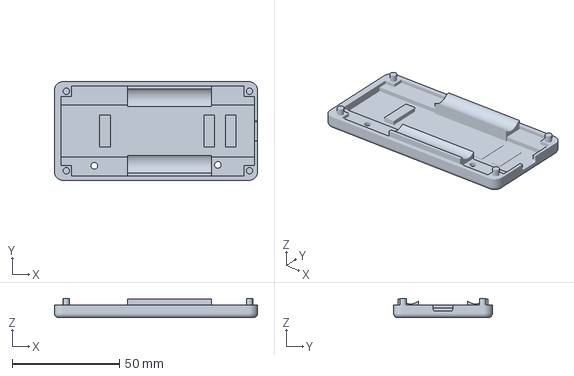
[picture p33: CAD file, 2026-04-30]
hardware-design/freecad-mk2/Dilder_Rev2_Mk2Full parts so far with joystick model with battery assembly even closer-BasePlate.3mf
94.5 x 46.0 x 9.00 mm

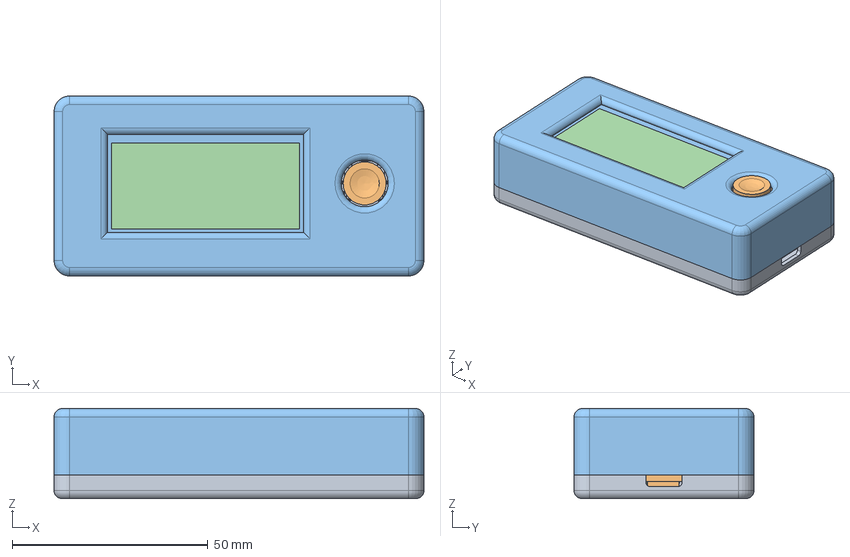
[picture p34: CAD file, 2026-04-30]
hardware-design/freecad-mk2/Dilder_Rev2_Mk2Full parts so far with joystick model with battery assembly even closer.FCStd
94.5 x 46.0 x 23.0 mm
BasePlate
AAACradle
TopCover
Pico2W_Board
Pico2W_Headers
AAA_Battery_1
AAA_Battery_1_PosTerm
AAA_Battery_2
AAA_Battery_2_PosTerm
TP4056_Module
EInkDisplay_Module
EInkDisplay_Panel
BatteryClips_Positive
BatteryClips_Negative
BatteryWiring_Positive
BatteryWiring_Negative
JoystickPCB
Thumbpiece
Solar_Frame
Solar_Cells
Solar_Wire_Plus
Solar_Wire_Minus

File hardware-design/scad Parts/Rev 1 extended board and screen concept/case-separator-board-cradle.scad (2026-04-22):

// Dilder Case Separator — board cradle variant
//
// Outer footprint matching the base (39.8 x 79.8mm, 4mm corner radius).
// Center cutout sized to the ESP32-S3 board + antenna projection.
// Raised cradle wall around the cutout holds the board in place.
//
// Export:
//   openscad -o case-separator-board-cradle.3mf case-separator-board-cradle.scad

$fn = 48;

// ---- Board (Olimex ESP32-S3-DevKit-Lipo) ----
board_len      = 56;
board_wid      = 28;
antenna_proj   = 6;
usb_overhang   = 2;        // USB-C ports extend past PCB edge

// ---- Waveshare 2.13" display ----
disp_len       = 65;
disp_wid       = 30;

// ---- 1000 mAh battery ----
bat_len        = 52;
bat_wid        = 35;

// ---- Enclosure geometry ----
wall_thk       = 2;
plate_thk      = 1;        // base sheet thickness
pillar         = 5;
slop           = 0.4;
cradle_wall    = 1.5;      // raised wall thickness around the board cutout
cradle_h       = 2;        // wall height above the base sheet

screw_clr      = 3.2;

// ---- Rounding ----
case_corner_r  = 4;
cutout_r       = 1;        // rounded corners on board cutout

// ---- XY layout ----
inner_wid      = max(board_wid, disp_wid, bat_wid) + 2 * slop;
inner_len      = max(board_len + antenna_proj, disp_len + 2 * pillar, bat_len) + 2 * slop;
outer_wid      = inner_wid + 2 * wall_thk;
outer_len      = inner_len + 2 * wall_thk;

pillar_xy = [
    [wall_thk,                             wall_thk                            ],
    [outer_wid - wall_thk - pillar,        wall_thk                            ],
    [wall_thk,                             outer_len - wall_thk - pillar       ],
    [outer_wid - wall_thk - pillar,        outer_len - wall_thk - pillar       ],
];

// Board cutout dimensions (board + antenna + USB overhang + clearance + 1mm wiggle per side)
cutout_extra   = 1;        // extra clearance per side
cutout_w       = board_wid + 2 * (slop + cutout_extra);
cutout_l       = board_len + antenna_proj + usb_overhang + 2 * (slop + cutout_extra);
cutout_x       = (outer_wid - cutout_w) / 2;
cutout_y       = (outer_len - cutout_l) / 2;

// Cradle wall outer dimensions
cradle_outer_w = cutout_w + 2 * cradle_wall;
cradle_outer_l = cutout_l + 2 * cradle_wall;
cradle_x       = cutout_x - cradle_wall;
cradle_y       = cutout_y - cradle_wall;


// ============== SHARED ==============

module rounded_v_box(w, l, h, r, fn = 48) {
    hull() {
        for (x = [r, w - r])
            for (y = [r, l - r])
                translate([x, y, 0])
                    cylinder(r = r, h = h, $fn = fn);
    }
}


// ============== CASE SEPARATOR — BOARD CRADLE ==============

module case_separator_board_cradle() {
    difference() {
        union() {
            // Base sheet — full outer footprint
            rounded_v_box(outer_wid, outer_len, plate_thk, case_corner_r);

            // Cradle wall — raised border around the board cutout
            translate([cradle_x, cradle_y, plate_thk])
            difference() {
                rounded_v_box(cradle_outer_w, cradle_outer_l, cradle_h, cutout_r + cradle_wall);
                translate([cradle_wall, cradle_wall, -0.1])
                    rounded_v_box(cutout_w, cutout_l, cradle_h + 0.2, cutout_r);
            }
        }

        // Board cutout through base sheet
        translate([cutout_x, cutout_y, -0.1])
            rounded_v_box(cutout_w, cutout_l, plate_thk + 0.2, cutout_r);

        // Screw clearance holes
        for (p = pillar_xy)
            translate([p[0] + pillar/2, p[1] + pillar/2, -0.1])
                cylinder(h = plate_thk + cradle_h + 0.2, d = screw_clr);
    }
}

case_separator_board_cradle();

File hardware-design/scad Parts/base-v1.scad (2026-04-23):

// Dilder Rev 2 "extended with joystick" — BASE v1
//
// Bottom shell of the enclosure, sized for the extended joystick layout:
//   - Battery lies flat on the LEFT half (same 1000 mAh cell as top-cover-v3,
//     52 x 35 mm footprint).
//   - ESP32 stack sits on the RIGHT half and overhangs the battery top by 2 mm.
//     The ESP32 footprint is slightly thinner in Y than the battery, centered
//     on the same Y axis as the battery chamber.
//   - Two USB-C ports on the board pop out through the +X end wall.
//   - Four corner pillars with M3 pass-through holes, same convention as
//     enclosure-prints/base.3mf and the existing top-cover-v3.
//   - Rounded outer shell with a soft bottom fillet for the "curved bottom"
//     look.
//
// Source of measurements: ./design-plan.md (from hand-drawn sketch).
//
// Export:
//   openscad -o base-v1.3mf base-v1.scad

$fn = 48;

// ============================================================
// Outer shell dimensions (overall enclosure footprint and height)
// ============================================================
enclosure_outer_width_along_x_axis_mm          = 89.5; // battery section trimmed 6.5mm (was 96 after +14 extension)
enclosure_outer_depth_along_y_axis_mm          = 44;
enclosure_total_height_along_z_axis_mm         = 12;  // lowered -10 from original 22
perimeter_outer_wall_thickness_mm              = 2;    // ±Y long walls
base_floor_plate_thickness_mm                  = 2;
// Outer corner radius is bounded by the asymmetric end-wall geometry:
// with `plus_x_wall = 1.2` and `pillar = 5`, the outermost +X pillar
// corner sits √((r − 1.2)² + (r − 2)²) from the shell corner arc center
// and must be ≤ r. That constraint gives r ≤ 5.39, and the symmetric
// -X constraint gives r ≤ 4.34. Anything above 4.34 makes the +X pillar
// corners visibly poke past the rounded shell on the USB face.
outer_case_top_view_corner_radius_mm           = 4;
outer_case_bottom_edge_fillet_radius_mm        = 2;

// Asymmetric ±X end-wall thicknesses: the USB-C side is intentionally
// thinner so the two ports pop through a minimal amount of material, and
// the opposite (battery) side is a bit thicker for strength and balance.
plus_x_usb_side_end_wall_thickness_mm          = 1.2;  // +X, USB-C end
minus_x_battery_side_end_wall_thickness_mm     = 3.0;  // -X, battery end

// ============================================================
// Battery chamber (LEFT side, 1000 mAh cell — matches top-cover-v3)
// ============================================================
battery_cell_footprint_length_x_mm             = 59.5; // trimmed 6.5mm from battery section (was 66)
battery_cell_footprint_depth_y_mm              = 35;

// ============================================================
// ESP32 chamber (RIGHT side — slightly thinner in Y than the battery)
// ============================================================
esp32_board_footprint_depth_y_mm               = 28;   // narrower than battery
esp32_overhang_shelf_height_above_battery_floor_mm = 5; // was 2; +3 = battery pit 3 mm deeper under the shelf

// ============================================================
// Two USB-C cutouts on the +X end wall (for the board's two USB-C ports)
// ============================================================
// Board is mounted TOPSIDE-DOWN (components-face-down) above the battery,
// so the PCB back-face rests flat against the top plate's inner face and
// the USB-C port bodies hang DOWN from the PCB. The cutout length is the
// measured port width (7.8 mm), and the cutout height is the port body
// height plus a small extra allowance so the board seats truly flat
// against the plastic without the port body binding against the wall.
usb_c_panel_cutout_width_along_y_axis_mm       = 7.8;   // measured port length
usb_c_port_body_height_above_pcb_mm            = 2.6;   // typical USB-C receptacle body
usb_c_cutout_extra_height_allowance_mm         = 0.2;   // so board lies flat
usb_c_panel_cutout_height_along_z_axis_mm =
    usb_c_port_body_height_above_pcb_mm
      + usb_c_cutout_extra_height_allowance_mm;         // = 2.8

// How far the USB-C port body extends INTO the enclosure from the outer
// wall (typical SMT receptacle: ~7.3 mm body depth on the PCB). Each
// cutout carves this far into the body so the port bodies have an
// explicit aligned pocket, not just open chamber space.
usb_c_port_body_recess_depth_into_enclosure_mm = 8.0;

// Shelf divet under each USB-C port. The board sits on the ESP32 shelf
// with the USB-C receptacle straddling the PCB edge; a small shield tab
// on the port body extends ~0.2 mm BELOW the PCB, so without this divet
// the board would rock on that tab. The divet is carved into the top of
// the shelf (z just below the shelf face) at each port's Y position.
usb_c_shelf_divet_depth_into_shelf_z_mm        = 0.2;
usb_c_shelf_divet_length_along_x_axis_mm       = 8.0;
usb_c_shelf_divet_width_along_y_axis_mm        = 7.8;

// Vertical center of the USB-C port cutout (z).
// The board sits INSIDE the base on the ESP32 shelf (component-side UP,
// headers facing up), so the USB-C ports sit low — close to the base
// floor. Raised to 8 this pass (+2 from v1.2's 6) so the cutouts clear
// the ESP32 shelf top (z=7) and sit fully above the shelf.
usb_c_port_vertical_center_z_mm                = 8;

// Y centers of the TWO USB-C ports on the board's end edge. Default layout
// assumes the two ports sit symmetrically about the ESP32 Y centerline,
// ~6 mm apart center-to-center (tweak to match the real board).
usb_c_port_center_y_positions_list = [
    enclosure_outer_depth_along_y_axis_mm / 2 - 6,   // lower port
    enclosure_outer_depth_along_y_axis_mm / 2 + 6,   // upper port
];

// ============================================================
// Internal layout (divider between chambers, fit tolerance)
// ============================================================
print_fit_tolerance_slop_mm                    = 0.4;
battery_to_esp32_internal_divider_wall_thickness_mm = 2;
esp32_cavity_overhang_onto_battery_length_x_mm = 4;   // PCB overhangs battery in X

// ============================================================
// Corner pillars (support posts for screws through the stack)
// ============================================================
corner_pillar_square_side_length_mm            = 5;
corner_pillar_inner_facing_corner_radius_mm    = 1;
m3_screw_clearance_hole_diameter_mm            = 3.2;

// ============================================================
// BOOT / RESET button poke-through holes in the BASE FLOOR
// ============================================================
// Two small Ø 1 mm vertical through-holes in the bottom of the case,
// going straight up through the 2 mm base plate and the 5 mm shelf
// material so a paperclip inserted from below reaches the BOOT and
// RESET buttons on the ESP32 dev board (which is mounted COMPONENT-
// SIDE DOWN in the ESP32 chamber, so buttons face the floor).
//
// X positions are measured from the +X (USB-end) inner wall face.
// Y position is measured INWARD from the +Y outer long edge of the
// floor (11.5 mm inset lands the hole inside the ESP32 chamber under
// where the flipped-board buttons sit).
button_poke_hole_diameter_mm                          = 1.0;
button_poke_hole_1_distance_from_plus_x_inner_wall_mm = 17.0;  // nearest the USB end
button_poke_hole_2_offset_to_left_of_hole_1_mm        = 12.5;  // further into the case
button_poke_hole_distance_from_plus_y_outer_edge_mm   = 11.5;  // Y inset from +Y outer edge

// ============================================================
// Derived cavity dimensions (cell + slop on every side)
// ============================================================
battery_chamber_inner_length_along_x_axis_mm =
    battery_cell_footprint_length_x_mm + 2 * print_fit_tolerance_slop_mm;
battery_chamber_inner_depth_along_y_axis_mm =
    battery_cell_footprint_depth_y_mm + 2 * print_fit_tolerance_slop_mm;
esp32_chamber_inner_depth_along_y_axis_mm =
    esp32_board_footprint_depth_y_mm + 2 * print_fit_tolerance_slop_mm;

// ESP32 chamber X length is derived so the cavity reaches the thin +X wall
// (otherwise the USB-C cutouts would terminate in solid material before
// breaking through into the chamber).
esp32_chamber_inner_length_along_x_axis_mm =
    enclosure_outer_width_along_x_axis_mm
      - minus_x_battery_side_end_wall_thickness_mm
      - battery_chamber_inner_length_along_x_axis_mm
      - battery_to_esp32_internal_divider_wall_thickness_mm
      - plus_x_usb_side_end_wall_thickness_mm;
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

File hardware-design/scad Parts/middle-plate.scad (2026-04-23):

// Dilder Middle Plate — standalone board tray for ESP32-S3
//
// This is the middle plate extracted from esp32s3-enclosure.scad.
// It drops into the base shell and rests on the lower shelf at z=8.
// The plate holds the Olimex ESP32-S3-DevKit-Lipo board with header
// pin clearance slots on both long edges.
//
// Export:
//   openscad -o middle.3mf middle-plate.scad
//
// To override parameters from the command line:
//   openscad -D 'board_wid=30' -o middle.3mf middle-plate.scad

$fn = 48;

// ---- Board (Olimex ESP32-S3-DevKit-Lipo) ----
board_len      = 56;
board_wid      = 28;
board_thk      = 1.6;
wroom_h        = 3.2;
antenna_wid    = 18;
antenna_proj   = 6;
header_gap     = 22;       // distance between the two header rows
header_slot_len = 56.5;    // slot length — board length + 0.5mm clearance
header_slot_wid = 4;       // slot width — wider than hdr_strip (3mm) for easy fit

// ---- Waveshare 2.13" display ----
disp_len       = 65;
disp_wid       = 30;

// ---- 1000 mAh battery ----
bat_len        = 52;
bat_wid        = 35;

// ---- Enclosure geometry ----
wall_thk       = 2;
pillar         = 5;
slop           = 0.4;
bat_chamber_h  = 6;

screw_clr      = 3.2;

// ---- Z layout (only what we need) ----
z_base_top     = plate_thk;                       // 2
z_mid_bot      = z_base_top + bat_chamber_h;      // 8

// ---- XY layout ----
inner_wid      = max(board_wid, disp_wid, bat_wid) + 2 * slop;
inner_len      = max(board_len + antenna_proj, disp_len + 2 * pillar, bat_len) + 2 * slop;
outer_wid      = inner_wid + 2 * wall_thk;
outer_len      = inner_len + 2 * wall_thk;

pillar_xy = [
    [wall_thk,                             wall_thk                            ],
    [outer_wid - wall_thk - pillar,        wall_thk                            ],
    [wall_thk,                             outer_len - wall_thk - pillar       ],
    [outer_wid - wall_thk - pillar,        outer_len - wall_thk - pillar       ],
];

board_x        = (outer_wid - board_wid) / 2;
board_y        = (outer_len - board_len - antenna_proj) / 2;


// ============== MIDDLE PLATE ==============

module middle_plate() {
    plate_w = inner_wid - 2 * slop;
    plate_l = inner_len - 2 * slop;
    plate_origin_x = wall_thk + slop;
    plate_origin_y = wall_thk + slop;
    hdr_strip = (board_wid - header_gap) / 2;
    header_slot_x_left  = board_x - plate_origin_x;
    header_slot_x_right = board_x + board_wid - header_slot_wid - plate_origin_x;
    // Center the slot along the plate length
    header_slot_y_start = (plate_l - header_slot_len) / 2;
    header_slot_y_len   = header_slot_len;

    translate([plate_origin_x, plate_origin_y, z_mid_bot])
    difference() {
        cube([plate_w, plate_l, plate_thk]);

        // Corner pillar clearance notches — overshoot plate edges by 1mm for clean booleans
        for (dx = [0, plate_w - pillar - slop])
            for (dy = [0, plate_l - pillar - slop]) {
                ox = (dx > 0) ? 1 : 0;   // overshoot +x on far-x corners
                oy = (dy > 0) ? 1 : 0;   // overshoot +y on far-y corners
                translate([dx - slop, dy - slop, -1])
                    cube([pillar + 2 * slop + ox, pillar + 2 * slop + oy, plate_thk + 2]);
            }

        // Left header pin slot
        translate([header_slot_x_left, header_slot_y_start, -1])
            cube([header_slot_wid, header_slot_y_len, plate_thk + 2]);

        // Right header pin slot
        translate([header_slot_x_right, header_slot_y_start, -1])
            cube([header_slot_wid, header_slot_y_len, plate_thk + 2]);

        // Screw clearance holes
        for (p = pillar_xy)
            translate([p[0] + pillar/2 - plate_origin_x, p[1] + pillar/2 - plate_origin_y, -1])
                cylinder(h = plate_thk + 2, d = screw_clr);
    }
}

middle_plate();

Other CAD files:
hardware-design/freecad-mk2/Dilder_Rev2_Mk2Full parts so far with joystick model with battery assembly even closer joystick and pit refined and cradle curvature fixed -TopCover.3mf
hardware-design/freecad-mk2/Dilder_Rev2_Mk2Full parts so far with joystick model with battery assembly even closer-TopCover.3mf
hardware-design/freecad-mk2/Dilder_Rev2_Mk2Full parts so far with joystick model with battery assembly even closer-Thumbpiece.3mf
hardware-design/freecad-mk2/Dilder_Rev2_Mk2Full parts so far with joystick model with battery assembly even closer-JoystickPCB.3mf
hardware-design/scad Parts/Rev 1 extended board and screen concept/case-separator-inner.scad
hardware-design/PCB Designs/joystick-pcb-by-hand/JoystickBoardDilder/JoystickBoardDilder.step
hardware-design/examples/01-pocketmage-pda/Docs/Documents & Advanced/PCB/V3.3/einkPDA_keyboard/JLC_Parts/YTS-C017-2B.step
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

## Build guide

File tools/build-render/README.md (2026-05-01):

# Build & Render Tool

Interactive CLI pipeline for rendering Dilder FreeCAD models into publication-quality PNGs.

## Quick Start

```bash
cd hardware-design
./build_and_render.sh
```

## What It Does

1. **Pick a model** — interactive menu lists all `.FCStd` files sorted by date (newest first)
2. **Choose what to render** — 19 options from full sets to individual components
3. **Set render style** — resolution, background, cover transparency
4. **Renders** — launches FreeCAD GUI, generates PNGs from the live 3D viewport
5. **Copies to website** — drops renders into `website/docs/assets/images/enclosure/`

## Menu Options

### Full Sets
| Option | Description | Images |
|---|---|---|
| 1 | Everything | 40+ |
| 2 | Assembly only | 10 |
| 3 | Exploded views | 3 |
| 4 | Component portraits | 14 |

### Individual Bodies
| Option | Description |
|---|---|
| 5 | Base plate (iso + top + bottom + sensors) |
| 6 | AAA cradle (iso + top + bottom) |
| 7 | Top cover (transparent + opaque + bottom) |
| 8 | Thumbpiece |

### Peripherals
| Option | Description |
|---|---|
| 9 | Joystick PCB (K1-1506SN-01 breakout) |
| 10 | Pico 2 W + headers |
| 11 | Piezo speaker (20 mm FT-20T) |
| 12 | IMU accelerometer (GY-6500) |
| 13 | TP4056 charger |
| 14 | Batteries + clips |
| 15 | E-ink display |
| 16 | Solar panel |

### Special
| Option | Description |
|---|---|
| 17 | Detail close-ups (joystick, thumbpiece, sensors) |
| 18 | Animation frames (13-step assembly drop) |
| 19 | Custom combo (pick exactly which components) |

## Render Styles

- **Resolution:** 1920x1440 (default), 2560x1920, 1280x960, 960x720
- **Background:** Transparent (default), White, Black, Light gray
- **Cover transparency:** 40% (default), 0% (opaque), 70%, 85% (ghost)

## Animation

Option 18 generates frame-by-frame PNGs of components dropping into place with cosine ease-in-out. If `ffmpeg` is installed, assembles them into a GIF automatically.

```bash
# Manual GIF assembly if needed
ffmpeg -framerate 12 -i renders/anim/frame-%04d.png \
       -vf "scale=960:720" -loop 0 renders/assembly-animation.gif
```

## Flags

```bash
./build_and_render.sh --rebuild    # rebuild FCStd from macro before rendering
./build_and_render.sh --all        # (with animation) not needed — pick option 18 in menu
```

## Output

- `renders/var-*.png` — assembly views (hero, angles, exploded, etc.)
- `renders/comp-*.png` — isolated component portraits
- `renders/anim/frame-*.png` — animation frames
- Automatically copied to `website/docs/assets/images/enclosure/`

## Requirements

- FreeCAD (GUI version, not `freecadcmd` — needs the 3D viewport for `saveImage`)
- `ffmpeg` (optional, for GIF assembly)
- `identify` from ImageMagick (optional, for blank image detection)

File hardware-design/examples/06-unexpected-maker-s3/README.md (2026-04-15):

# Unexpected Maker - ESP32-S3 Boards 

Assorted files for my ESP32-S3 development boards 













You can find out more about my ESP32-S3 boards at https://esp32s3.com 

# Contents
In this repo you'll find the following items:

## 3D Models
3D STEP files for each of the OMGS3, NanoS3, TinyS3, ProS3 and FeatherS3 boards

## KiCAD 6/7/8 Symbols
KiCAD 6 symbol files for each of the boards that you can use when integrating one of them into one of your PCB designs.
NanoS3 symbol file is for KiCAD 7 or later
OMGS3 symbol file is for KiCAD 8 or later

## KiCAD 6/7 Footprints	
KiCAD 6 footprint files for each of the boards including both SMD and TH versions for the ProS3
NanoS3 footprint file is for KiCAD 7 or later
OMGS3 footprint file is for KiCAD 8 or later

## Schematics
PDF Schematics for each of the OMGS3, NanoS3, TinyS3, ProS3 and FeatherS3 boards

## Pin Reference Cards
Hires pinout reference cards for each of the OMGS3, NanoS3, TinyS3, ProS3 and FeatherS3 boards

# Support Unexpected Maker

I love designing, making, and releasing projects and products that empower others to learn and build amazing things! I do it because I believe it’s important to share knowledge and give back to the community as many have done before me. It helps us all learn and grow.

Please consider supporting me by buying some of my products from:

https://unexpectedmaker.com/shop

Or by buying one of my products on tindie or Lectronz:

https://www.tindie.com/stores/seonr/
https://lectronz.com/stores/unexpectedmaker

Or by becoming a Patron:

https://www.patreon.com/unexpectedmaker

## Unexpected Maker
http://youtube.com/c/unexpectedmaker

http://twitter.com/unexpectedmaker

https://discord.gg/xAHpApP

https://www.facebook.com/unexpectedmaker/

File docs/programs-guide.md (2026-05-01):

# Dilder Programs Guide

A comprehensive reference for every firmware program in the Dilder project. Each program runs on a Raspberry Pi Pico W with a Waveshare 2.13" e-ink display and renders an animated octopus with mood-specific expressions, body animations, and curated quotes.

---

## Table of Contents

- [Overview](#overview)
- [How Programs Work](#how-programs-work)
  - [Display Layout](#display-layout)
  - [Animation Cycle](#animation-cycle)
  - [Quote System](#quote-system)
  - [Building and Flashing](#building-and-flashing)
- [Utility Programs](#utility-programs)
  - [Hello World](#hello-world)
  - [Hello World Serial](#hello-world-serial)
  - [Image Receiver](#image-receiver)
- [Emotional State Programs](#emotional-state-programs)
  - [Sassy Octopus](#sassy-octopus)
  - [Supportive Octopus](#supportive-octopus)
  - [Angry Octopus](#angry-octopus)
  - [Conspiratorial Octopus](#conspiratorial-octopus)
  - [Sad Octopus](#sad-octopus)
  - [Chaotic Octopus](#chaotic-octopus)
  - [Hungry Octopus](#hungry-octopus)
  - [Tired Octopus](#tired-octopus)
  - [Slap Happy Octopus](#slap-happy-octopus)
  - [Lazy Octopus](#lazy-octopus)
  - [Fat Octopus](#fat-octopus)
  - [Chill Octopus](#chill-octopus)
  - [Creepy Octopus](#creepy-octopus)
  - [Excited Octopus](#excited-octopus)
  - [Nostalgic Octopus](#nostalgic-octopus)
  - [Homesick Octopus](#homesick-octopus)
- [Mood Selector (Interactive)](#mood-selector-interactive)
  - [Serial Input Reference](#serial-input-reference)
  - [Connecting to the Pico](#connecting-to-the-pico)
- [Program Comparison Table](#program-comparison-table)

---

## Overview

The `dev-setup/` directory contains **19 programs** total:

- **3 utility programs** for hardware testing and development
- **16 emotional state programs** each featuring a unique octopus personality
- **1 interactive mood selector** that combines all 16 emotional states with keyboard control

All emotional state programs share the same core rendering engine: a runtime pixel renderer that composites body, eyes, mouth, chat bubble, and text onto a 250x122px 1-bit canvas, then pushes it to the e-ink display using partial refresh (~4 second frame cycle).

---

## How Programs Work

### Display Layout

The 250x122 pixel landscape canvas is organized as:

```
+--------------------------------------------------+
|              APRIL 12, 2026  3:47 PM             |  <-- Clock header (y=1)
|                                                  |
|   @@@@@@     +----------------------------+      |
|  @@    @@    | QUOTE TEXT GOES HERE AND   |      |  <-- Chat bubble (y=17, 170x70)
|  @ O  O @   | WRAPS AUTOMATICALLY TO     |      |
|  @  __  @   | FIT INSIDE THE BUBBLE      |      |
|  @@    @@   |                            |      |
|   @@@@@@ /  +----------------------------+      |
|    |||||       ~ SASSY OCTOPUS ~                 |  <-- Tagline (below bubble)
+--------------------------------------------------+
```

- **Clock header:** Date and time from RTC, centered at y=1
- **Octopus body:** Left side, rendered with RLE-decoded body + mood-specific transforms
- **Eyes:** White sockets with mood-specific pupils (hearts, stars, spirals, etc.)
- **Mouth:** 18 distinct expressions cycled per mood
- **Chat bubble:** Right side, rounded rectangle with speech tail pointing to octopus
- **Quote text:** Word-wrapped 5x7 bitmap font inside the bubble
- **Tagline:** Mood name centered below the bubble

### Animation Cycle

Each mood defines a 4-frame expression cycle. Every ~4 seconds:

1. The current expression is drawn from the cycle (e.g., Smirk -> Open -> Smile -> Open)
2. On every OPEN mouth frame, a new random quote is selected
3. The body transform is applied (shift, wobble, expand based on mood)
4. The frame is rendered to the landscape buffer, transposed to portrait, and pushed via partial refresh

### Quote System

Quotes are stored in `quotes.h` as a static array of `{text, mood_id}` structs. Each program includes only its relevant quotes (except Mood Selector which includes all 823). The DevTool auto-generates `quotes.h` from the Python quote lists in `devtool.py`.

### Building and Flashing

**Via DevTool GUI:**
1. Open DevTool: `python3 tools/devtool/devtool.py`
2. Select the program from the dropdown
3. Select display variant (V2/V3/V3a/V4)
4. Click "Build & Flash to Pico"
5. Put Pico in BOOTSEL mode (hold BOOTSEL + plug USB)
6. DevTool copies the `.uf2` to the mounted drive

**Via command line:**
```bash
cd dev-setup/
docker compose run --rm build-sassy-octopus bash -c \
  "mkdir -p build && cd build && cmake .. -DDISPLAY_VARIANT=V3 && make -j4"
# Copy build/sassy_octopus.uf2 to the Pico in BOOTSEL mode
cp sassy-octopus/build/sassy_octopus.uf2 /run/media/$USER/RPI-RP2/
```

---

## Utility Programs

### Hello World

**Directory:** `dev-setup/hello-world/`

Basic e-ink display test. Draws a simple pattern to verify the display is wired correctly and the SPI bus is working. This is the first program you should flash to confirm hardware is functional.

**Use case:** Hardware verification after initial wiring.

### Hello World Serial

**Directory:** `dev-setup/hello-world-serial/`

Serial-only test program. Prints messages over USB CDC at 115200 baud without driving the display. Useful for verifying the USB serial connection works before flashing display firmware.

**Use case:** Verify USB serial communication before display testing.

### Image Receiver

**Directory:** `dev-setup/img-receiver/`

Receives raw 1-bit bitmap data over USB serial and displays it on the e-ink screen. Used by the DevTool's display emulator to push custom images to the hardware.

**Use case:** Push arbitrary images from DevTool to the physical display.

---

## Emotional State Programs

Each program below runs autonomously once flashed. The octopus cycles through its personality-specific quotes, changing expression and quote every ~4 seconds.

### Sassy Octopus

**Directory:** `dev-setup/sassy-octopus/` | **Quotes:** 196 | **Default Mood:** Normal

Sassy

A snarky octopus with attitude. Delivers observations like "WIFI IS JUST SPICY AIR" and "I DONT HAVE BONES AND THATS A FLEX." The default personality with centered pupils, smirk/smile mouth cycle, and gentle breathing body animation.

| Feature | Details |
|---|---|
| Eyes | Centered pupils with white highlights |
| Mouth Cycle | Smirk -> Open -> Smile -> Open |
| Body | Gentle 1px vertical breathing bob |
| Quotes | Snarky observations, food hot takes, self-aware flexes |

### Supportive Octopus

**Directory:** `dev-setup/supportive-octopus/` | **Quotes:** 160 | **Default Mood:** Normal

Supportive

Aggressively supportive. Uses the same normal face as Sassy but delivers chaotic affirmations like unhinged pep talks. Some quotes override to weird/unhinged moods for visual variety.

| Feature | Details |
|---|---|
| Eyes | Same as Sassy (centered, normal) |
| Mouth Cycle | Smirk -> Open -> Smile -> Open |
| Body | Gentle breathing (same as Sassy) |
| Quotes | Unhinged pep talks, chaotic affirmations, spicy encouragement |

### Angry Octopus

**Directory:** `dev-setup/angry-octopus/` | **Quotes:** 45 | **Default Mood:** Angry

Angry

Furious but adorable. V-shaped eyebrows slant inward, pupils glare toward the nose, and the tight frown shows zero patience. Body puffs up 2px wider with a slight tremble.

| Feature | Details |
|---|---|
| Eyes | Pupils shifted inward + down (glaring), thick V-shaped brow arcs |
| Mouth Cycle | Frown -> Open -> Frown -> Frown |
| Body | Puffed up +2px wider, 0.5px wobble tremble |
| Quotes | Rants about shrimp theft, Poseidon, and tentacle violence |

### Conspiratorial Octopus

**Directory:** `dev-setup/conspiratorial-octopus/` | **Quotes:** 47 | **Default Mood:** Weird

Conspiratorial

Tinfoil hat energy. Misaligned pupils (one up-left, one down-right) give a shifty look. The wavy sine-wave mouth and swaying body sell the paranoia.

| Feature | Details |
|---|---|
| Eyes | Misaligned: left up-left, right down-right |
| Mouth Cycle | Wavy sine -> Open -> Wavy -> Smile |
| Body | Lean/sway +/-3px, subtle row distortion |
| Quotes | Government conspiracies, simulation theory, birds aren't real |

### Sad Octopus

**Directory:** `dev-setup/sad-octopus/` | **Quotes:** 35 | **Default Mood:** Sad

Sad

Droopy eyes looking at the floor with inverted brow arcs (high inside, low outside). The gentle frown and deflated body convey genuine melancholy.

| Feature | Details |
|---|---|
| Eyes | Downward-looking pupils, droopy brow arcs |
| Mouth Cycle | Frown -> Open -> Frown -> Smile |
| Body | Drooped +3px down, deflated 1px narrower |
| Quotes | Existential ocean sadness, melodramatic but relatable |

### Chaotic Octopus

**Directory:** `dev-setup/chaotic-octopus/` | **Quotes:** 40 | **Default Mood:** Chaotic

Chaotic

Pure entropy. Spiral ring pupils (concentric circles), a zigzag lightning-bolt mouth, and wild wavy body distortion. The expression cycle is itself chaotic: zigzag -> open -> unhinged scream -> wobbly.

| Feature | Details |
|---|---|
| Eyes | Spiral ring pupils (concentric circles with center dot) |
| Mouth Cycle | Zigzag -> Open -> Unhinged -> Wobbly |
| Body | Wild 3px sine wobble per row, shifting phase |
| Quotes | Nonsensical fever-dream energy, entropy incarnate |

### Hungry Octopus

**Directory:** `dev-setup/hungry-octopus/` | **Quotes:** 30 | **Default Mood:** Hungry

Hungry

Wide eyes staring upward at imaginary food, with a drooling open mouth (oval + drool drops below). Every thought is about snacks.

| Feature | Details |
|---|---|
| Eyes | Pupils shifted upward (staring at food) |
| Mouth Cycle | Drool mouth -> Open -> Drool -> Smile |
| Body | Slight upward shift (-2px), breathing |
| Quotes | Taco dreams, snack philosophy, selling hearts for pizza |

### Tired Octopus

**Directory:** `dev-setup/tired-octopus/` | **Quotes:** 30 | **Default Mood:** Tired

Tired

Half-closed eyelids cover the top of each eye socket, tiny sleepy pupils peek out below. The tall yawn mouth is open wide vertically. Running on zero sleep.

| Feature | Details |
|---|---|
| Eyes | Half-closed lids (top half black), tiny pupils low in slit |
| Mouth Cycle | Yawn -> Open -> Yawn -> Yawn |
| Body | Slouched +2px down, deflated 1px narrower |
| Quotes | Existential exhaustion, one brain cell, nap theology |

### Slap Happy Octopus

**Directory:** `dev-setup/slaphappy-octopus/` | **Quotes:** 30 | **Default Mood:** Slap Happy

Slap Happy

One eye squinted shut (white slit), one manic oversized pupil. The wide wobbly grin with sine wobble completes the delirious look. Everything is hilarious for no reason.

| Feature | Details |
|---|---|
| Eyes | Left squinted shut (slit), right oversized pupil |
| Mouth Cycle | Wobbly grin -> Open -> Wobbly grin -> Smile |
| Body | Bouncing +/-3px lateral sway, 2px row wobble |
| Quotes | Delirious giggling, everything is hilarious |

### Lazy Octopus

**Directory:** `dev-setup/lazy-octopus/` | **Quotes:** 30 | **Default Mood:** Lazy

Lazy

Nearly-closed slit eyes (only bottom sliver visible), flat horizontal line mouth. Custom body sits on its side with all tentacles draped to the right. Proudly doing nothing.

| Feature | Details |
|---|---|
| Eyes | Lids cover most of socket, barely-visible dots low in slit |
| Mouth Cycle | Flat line -> Flat line -> Flat line -> Open |
| Body | Custom side-sitting pose, tentacles drape right, +3px sag |
| Quotes | Philosophical laziness, zero motivation manifestos |

### Fat Octopus

**Directory:** `dev-setup/fat-octopus/` | **Quotes:** 30 | **Default Mood:** Fat

Fat

Custom wider body: dome starts 2 rows earlier, +5px per side at peak, no waist taper, thicker tentacles. Happy wide pupils and a satisfied smile with puffed cheeks. Proudly round.

| Feature | Details |
|---|---|
| Eyes | Wider pupils (r=3), happy and satisfied |
| Mouth Cycle | Cheek-puff smile -> Open -> Cheek-puff smile -> Smile |
| Body | Custom fat body RLE: wider dome, no waist, thick tentacles |
| Quotes | Food-positive celebrations, proudly round philosophy |

### Chill Octopus

**Directory:** `dev-setup/chill-octopus/` | **Quotes:** 30 | **Default Mood:** Chill

Chill

Side-glancing cool pupils shifted right, relaxed asymmetric half-smile. Unbothered zen vibes with gentle 1px lateral sway.

| Feature | Details |
|---|---|
| Eyes | Pupils shifted right (looking to the side) |
| Mouth Cycle | Half-smile -> Open -> Half-smile -> Smile |
| Body | Gentle 1px sway, lowered 1px |
| Quotes | Stoner philosopher energy, going with the flow |

### Creepy Octopus

**Directory:** `dev-setup/creepy-octopus/` | **Quotes:** 30 | **Default Mood:** Creepy

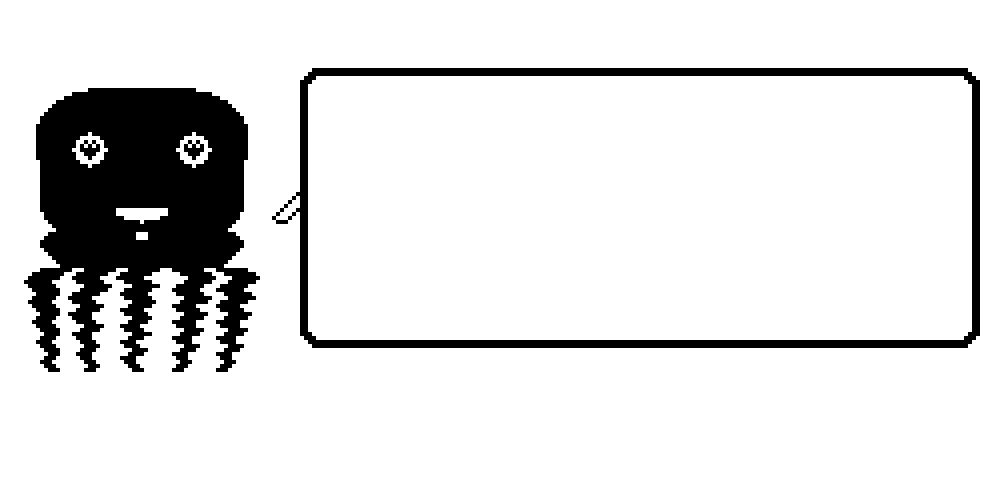
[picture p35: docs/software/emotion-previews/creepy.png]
Creepy


Heart-shaped pupils in each eye socket, wide open smile with a tongue hanging out (filled oval + tongue bump below). Flirty tentacle energy.

| Feature | Details |
|---|---|
| Eyes | Heart-shaped pupils (bumps + taper + point) |
| Mouth Cycle | Tongue-out smile -> Open -> Tongue-out -> Smile |
| Body | Width pulses +/-2px (confident strut) |
| Quotes | Ocean romance, goofy innuendo, tentacle flirting |

### Excited Octopus

**Directory:** `dev-setup/excited-octopus/` | **Quotes:** 30 | **Default Mood:** Excited

Excited

Star/sparkle cross-shaped pupils with diagonal tips in each eye. The wide open smile curves from edge to edge. Bouncing body with +/-3px vertical oscillation.

| Feature | Details |
|---|---|
| Eyes | Star/sparkle cross pupils with diagonal tips |
| Mouth Cycle | Wide grin -> Open -> Wide grin -> Smile |
| Body | Bouncing up/down +/-3px |
| Quotes | Maximum hype, caps lock enthusiasm, bouncing energy |

### Nostalgic Octopus

**Directory:** `dev-setup/nostalgic-octopus/` | **Quotes:** 30 | **Default Mood:** Nostalgic

Nostalgic

Pupils shifted up and to the right (remembering), gentle small half-smile. The body sways slowly with a slight tilt, as if lost in thought.

| Feature | Details |
|---|---|
| Eyes | Pupils up-right (looking into the distance) |
| Mouth Cycle | Small half-smile -> Open -> Half-smile -> Smile |
| Body | Slow 2px lateral sway + slight vertical drift |
| Quotes | Wistful ocean memories, back-in-my-day nostalgia |

### Homesick Octopus

**Directory:** `dev-setup/homesick-octopus/` | **Quotes:** 30 | **Default Mood:** Homesick

Homesick

Watery eyes with tear drop pixels below each socket, wobbly trying-not-to-cry mouth line. The body droops and narrows, conveying deflation and longing.

| Feature | Details |
|---|---|
| Eyes | Lowered pupils, tear drops below each eye |
| Mouth Cycle | Wobbly line -> Open -> Wobbly -> Wobbly |
| Body | Drooped +1px, narrowed -2px, bittersweet |
| Quotes | Missing the deep ocean, longing for home |

---

## Mood Selector (Interactive)

**Directory:** `dev-setup/mood-selector/` | **Quotes:** 823 (all moods combined)

The Mood Selector combines all 16 emotional states into a single interactive firmware. Instead of being locked to one personality, you browse through moods using keyboard input over USB serial.

**On the display:**
- Clock header at top center
- Octopus with the currently selected mood's face, body animation, and a random quote
- Bottom center: `< MOOD_NAME >` with `<` and `>` arrows indicating left/right navigation

**How to use:**
1. Flash `mood_selector.uf2` to the Pico
2. Connect to serial (see [Connecting to the Pico](#connecting-to-the-pico))
3. Press `[` or `]` to cycle through moods
4. Press a letter key for direct mood selection
5. Press `?` to see all available commands

### Serial Input Reference

Connect to the Pico's USB serial port at 115200 baud. All commands are single keystrokes.

#### Mood Navigation

| Key | Action |
|-----|---|
| `[` | Previous mood (left) -- wraps around |
| `]` | Next mood (right) -- wraps around |
| `,` | Previous mood (left) -- alternate key |
| `.` | Next mood (right) -- alternate key |
| `r` | Jump to a random mood |

#### Direct Mood Selection

| Key | Mood | Key | Mood |
|-----|---|-----|---|
| `n` | Sassy | `w` | Weird |
| `u` | Unhinged | `a` | Angry |
| `s` | Sad | `c` | Chaotic |
| `h` | Hungry | `t` | Tired |
| `p` | Slap Happy | `l` | Lazy |
| `f` | Fat | `k` | Chill |
| `y` | Creepy | `e` | Excited |
| `o` | Nostalgic | `m` | Homesick |

#### Other Commands

| Key | Action |
|-----|---|
| `q` | Load a new random quote (same mood) |
| `?` | Print the full help menu to serial |

All keys are case-insensitive (e.g., `A` and `a` both select Angry).

#### Serial Output

When you press a navigation key, the serial monitor shows:

```
----------------------------------------
  KEY ']' pressed  |  >> RIGHT  |  SASSY --> WEIRD
  Now showing: < WEIRD >  (2/16)
----------------------------------------
```

Each animation frame also logs:

```
Frame 5  |  < ANGRY > (4/16)  |  "THE AUDACITY OF THIS ENTIRE OCEAN."
```

### Connecting to the Pico

The Pico communicates over USB CDC serial at 115200 baud. Only one program can hold the port at a time.

**Find the serial port:**
```bash
ls /dev/serial/by-id/
# Look for: usb-Raspberry_Pi_Pico_XXXXX-if00 -> ../../ttyACM0
```

**Connect with screen:**
```bash
screen /dev/ttyACM0 115200
# Exit: Ctrl+A then K then Y
```

**Connect with picocom:**
```bash
picocom -b 115200 /dev/ttyACM0
# Exit: Ctrl+A then Ctrl+X
```

**Connect with minicom:**
```bash
minicom -D /dev/ttyACM0 -b 115200
# Exit: Ctrl+A then X
```

**Via DevTool:** The DevTool's Serial Monitor tab connects automatically. Close it before using a terminal, as only one program can hold the port.

> **Note:** If the Pico was just flashed, it will reboot and appear as a serial device within ~1 second. If no device appears at `/dev/ttyACM0`, try unplugging and re-plugging the USB cable (without holding BOOTSEL).

---

## Program Comparison Table

| Program | Quotes | Body | Eyes | Mouth | Body Animation |
|---|---|---|---|---|---|
| Sassy | 196 | Standard | Normal | Smirk/Smile | Breathing bob |
| Supportive | 160 | Standard | Normal | Smirk/Smile | Breathing bob |
| Angry | 45 | Standard | Glare + V-brows | Frown | Puffed +2px, tremble |
| Conspiratorial | 47 | Standard | Misaligned | Sine wave | Sway +/-3px |
| Sad | 35 | Standard | Down + droopy brows | Gentle frown | Drooped +3px, -1px |
| Chaotic | 40 | Standard | Spiral rings | Zigzag lightning | Wild 3px wobble |
| Hungry | 30 | Standard | Up (staring) | Drool mouth | Slight upward shift |
| Tired | 30 | Standard | Half-closed lids | Yawn oval | Slouched +2px |
| Slap Happy | 30 | Standard | One squint, one manic | Wobbly grin | Bounce +/-3px |
| Lazy | 30 | Custom (side-sit) | Barely-open slits | Flat line | Sagged, tentacles right |
| Fat | 30 | Custom (wide) | Wide happy | Cheek-puff smile | Width pulse |
| Chill | 30 | Standard | Side-glance | Half-smile | Gentle 1px sway |
| Creepy | 30 | Standard | Heart-shaped | Tongue out | Width pulse +/-2px |
| Excited | 30 | Standard | Star sparkle | Wide open grin | Bounce +/-3px |
| Nostalgic | 30 | Standard | Up-right gaze | Small half-smile | Slow 2px sway |
| Homesick | 30 | Standard | Tears below | Wobbly line | Drooped, -2px narrow |
| **Mood Selector** | **823** | **All** | **All** | **All** | **All (interactive)** |

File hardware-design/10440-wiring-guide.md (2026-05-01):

# 10440 Li-Ion AAA Wiring Guide

Complete wiring for dual 10440 cells + TP4056 charger + solar panel + Pico W power and battery monitoring.

---

## Components

| Part | Spec | Notes |
|---|---|---|
| 2x 10440 Li-Ion cells | 3.7V nominal, 350mAh each | Raw cells, no built-in regulator |
| TP4056 module | USB-C variant with DW01A protection | Blue PCB, ~25x15mm |
| Solar panel | AK 62x36mm, 5-6V open circuit | ~100mA peak in direct sun |
| Schottky diode (optional) | 1N5817 or SS34 | Blocks solar reverse current at night |
| Pico W | Pin 39 (VSYS), Pin 38 (GND) | Built-in buck-boost handles 1.8-5.5V |
| Wire | 26-28 AWG silicone | Red (+), Black (-) |

---

## Battery Configuration: PARALLEL ONLY

```
     Cell 1 (3.7V 350mAh)          Cell 2 (3.7V 350mAh)
     ┌──────────────────┐          ┌──────────────────┐
   (+)                (-)        (+)                (-)
     │                  │          │                  │
     └────────┬─────────┘          └────────┬─────────┘
              │                             │
              ├─────────────────────────────┤
              │         PARALLEL            │
           POS bus (+)                   NEG bus (-)
              │                             │
              ▼                             ▼
         TP4056 BAT+                   TP4056 BAT-
```

**Combined output: 3.7V nominal, ~700mAh capacity.**

!!! danger "NEVER wire 10440 cells in series"
    Series = 7.4V. This exceeds the Pico VSYS max (5.5V) and will destroy the TP4056 (single-cell charger only, max input 8V on VCC but charges to 4.2V on BAT pin). Parallel only.

---

## How to Wire the Cells in Parallel

Parallel means positive-to-positive, negative-to-negative. Both cells see the same voltage (3.7V) and their capacities add up (350 + 350 = 700mAh).

### Physical Layout in the Cradle

The two 10440 cells sit side-by-side in the cradle's battery bays. Each bay has two Swpeet 7x7mm clip plates — one at each end — held in vertical slots. The cells drop in on top of the clips.

```
  CRADLE (top view, looking down into the bays)

  -X wall                                              +X wall
  ┌──────────────────────────────────────────────────────────┐
  │                                                          │
  │  ┌─[NEG clip]── Cell 1 (AAA 10440) ──[POS clip]─┐      │
  │  │   (-)          ◄────────────►         (+)      │      │
  │  │                                                │      │
  │  │              TP4056 sits here                   │      │
  │  │              on the ConnBlock                   │      │
  │  │                                                │      │
  │  ├─[NEG clip]── Cell 2 (AAA 10440) ──[POS clip]─┤      │
  │  │   (-)          ◄────────────►         (+)      │      │
  │  └────────────────────────────────────────────────┘      │
  │                                                          │
  └──────────────────────────────────────────────────────────┘
```

Both cells face the **same direction** — positive nub on the same end, flat negative on the other end.

### Wiring the Parallel Bus

You need two short bus wires: one red (positive), one black (negative).

**Step 1 — Positive bus:**

```
  Cell 1 POS clip ──── red wire ──── Cell 2 POS clip
         │
         └──── red wire continues to TP4056 BAT+
```

Solder a red wire between the two positive-end clip plates. Both POS clips are on the same X-end of the cradle. Run a third red wire from this junction to the TP4056 BAT+ pad.

**Step 2 — Negative bus:**

```
  Cell 1 NEG clip ──── black wire ──── Cell 2 NEG clip
         │
         └──── black wire continues to TP4056 BAT-
```

Same thing on the other end. Solder between the two negative-end clip plates, then run to TP4056 BAT-.

**Step 3 — Verify before inserting cells:**

1. Insert both cells (nub = positive end, flat = negative end)
2. Multimeter across the POS bus and NEG bus wires
3. Should read **3.6-4.2V** (depends on cell charge state)
4. If you read ~0V, one cell is backwards
5. If you read ~7.4V, you wired series by mistake — **STOP and fix**

### Wiring Directly to the Clip Plates

The Swpeet clip plates are 7x7mm stamped sheet metal, 0.5mm thick. To solder to them:

1. **Scratch the surface** with sandpaper or a blade — the nickel plating needs roughing up for solder to stick
2. **Tin the pad** — blob of solder on the clip plate first, let it cool
3. **Tin the wire** — strip 3-4mm of insulation, apply solder to the exposed wire
4. **Join** — hold the tinned wire against the tinned pad, touch with iron for 2-3 seconds
5. **Route the wire** — run it along the cradle wall, out through the FPC gap or over the ConnBlock edge to reach the TP4056

Use 28 AWG silicone wire — thin enough to route inside the cradle without interfering with cell fit, flexible enough to not stress the solder joints.

### Why Not Solder Directly to the Cells?

You can, but:

- 10440 cells are small and heat up fast — prolonged iron contact can damage the chemistry
- The cradle clip system lets you swap cells without desoldering
- If you must solder to cells, use tabbed/tagged 10440s (pre-spot-welded nickel strips) and solder to the tabs, not the cell body

---

## Full Wiring Diagram

```
                    ┌─────────────────────────────┐
                    │        SOLAR PANEL           │
                    │       AK 62x36mm             │
                    │      5-6V, ~100mA            │
                    │                              │
                    │   RED (+)        BLACK (-)   │
                    └─────┬──────────────┬─────────┘
                          │              │
                   ┌──────┴──────┐       │
                   │ 1N5817      │       │   (optional blocking diode
                   │ Schottky    │       │    prevents reverse current
                   │ Vf ≈ 0.3V  │       │    from battery → panel at night)
                   └──────┬──────┘       │
                          │              │
  ┌───────────────────────┼──────────────┼────────────────────────┐
  │                  TP4056 MODULE (with DW01A)                   │
  │                                                               │
  │   IN+  ◄─────────┘              IN-  ◄──────────┘            │
  │   (USB-C port also connects here — either source charges)     │
  │                                                               │
  │   ┌─────────────────────────────────────────────────┐         │
  │   │  TP4056 IC          RPROG (1.2kΩ = 1A charge)  │         │
  │   │                     (swap to 10kΩ for solar-    │         │
  │   │                      matched 120mA charge rate) │         │
  │   │  CC/CV charging     Red LED = charging          │         │
  │   │  4.2V termination   Green LED = done            │         │
  │   └─────────────────────────────────────────────────┘         │
  │                                                               │
  │   BAT+ ◄──── 10440 cells parallel (+)                        │
  │   BAT- ◄──── 10440 cells parallel (-)                        │
  │                                                               │
  │   ┌─────────────────────────────────────────────────┐         │
  │   │  DW01A Protection IC                            │         │
  │   │  Over-discharge cutoff: 2.9V (saves cells)      │         │
  │   │  Over-charge cutoff: 4.3V (backup safety)       │         │
  │   │  Short-circuit protection                       │         │
  │   └─────────────────────────────────────────────────┘         │
  │                                                               │
  │   OUT+ ─────────────────────────────► Pico VSYS (pin 39)     │
  │   OUT- ─────────────────────────────► Pico GND  (pin 38)     │
  │                                                               │
  └───────────────────────────────────────────────────────────────┘
```

---

## Step-by-Step Wiring

### 1. Wire cells in parallel

Solder a red wire between both cells' positive clip plates (or solder directly to the Swpeet contact plates in the cradle). Solder a black wire between both negative clip plates. This creates a single 3.7V ~700mAh battery pack.

### 2. Connect battery to TP4056

| Wire | From | To |
|---|---|----|
| Red | Parallel positive bus | TP4056 **BAT+** pad |
| Black | Parallel negative bus | TP4056 **BAT-** pad |

### 3. Connect solar panel to TP4056

| Wire | From | To |
|---|---|----|
| Red | Solar panel (+) | 1N5817 anode → cathode to TP4056 **IN+** |
| Black | Solar panel (-) | TP4056 **IN-** |

The 1N5817 Schottky diode prevents the battery from discharging back through the solar panel at night. Many TP4056 modules already have this built in — check yours. If the module has a USB-C port, the solar wires go to the IN+/IN- pads (separate from the USB port, same electrical node).

**Both USB-C and solar can be connected simultaneously.** Whichever source has higher voltage wins. USB provides ~5V, solar provides ~4.5-5V under load — USB will take priority when plugged in.

### 4. Connect TP4056 output to Pico

| Wire | From | To |
|---|---|----|
| Red | TP4056 **OUT+** | Pico W **VSYS** (pin 39) |
| Black | TP4056 **OUT-** | Pico W **GND** (pin 38) |

Use OUT+/OUT- (not BAT+/BAT-) so the DW01A protection is in the circuit. This cuts power if the battery drops below 2.9V, preventing deep discharge damage.

### 5. Solder points on the ePaper board (optional)

As discussed — you can solder these power wires to the corresponding VSYS and GND pass-through pads on the Waveshare ePaper HAT instead of directly to the Pico. Same electrical connection, keeps the Pico clean.

---

## Solar Panel RPROG Tuning

The default 1.2kΩ RPROG resistor sets a 1A charge current. The solar panel can only deliver ~100mA, so the TP4056 will constantly try to pull more than the panel can give, causing voltage sag and unstable behavior.

**Fix:** Replace RPROG with a 10kΩ resistor to set charge current to ~120mA, matching the solar panel's capacity.

```
RPROG formula:  Icharge (mA) = 1200 / RPROG (kΩ)

1.2kΩ  = 1000mA  (USB charging — fast)
5.0kΩ  =  240mA  (compromise)
10.0kΩ =  120mA  (solar-matched — stable)
```

If you want fast USB charging AND solar, keep the 1.2kΩ. The TP4056 will just charge slower from solar (it self-limits to what the source can provide), but it may oscillate between charging/not-charging in weak light. The 10kΩ swap is only needed if solar is the primary/only charge source.

---

## Battery Level Monitoring

**Yes, the Pico W can read battery voltage.** It has a built-in voltage divider on GPIO29 (ADC3) that reads VSYS/3.

### Hardware

No external components needed. The voltage divider is on the Pico W PCB:

```
VSYS ──┤ R1 (200kΩ) ├──┬──┤ R2 (100kΩ) ├── GND
                        │
                     GPIO29 (ADC3)
                     reads VSYS / 3
```

### Firmware (MicroPython example)

```python
import machine
import time

# On Pico W, GPIO29 is the VSYS/3 ADC input
# Must disable WiFi SPI sharing first on Pico W
vsys_adc = machine.ADC(29)

def read_battery_voltage():
    """Read VSYS voltage via the onboard divider."""
    raw = vsys_adc.read_u16()           # 0-65535
    voltage = raw * 3.3 / 65535 * 3     # Convert: ADC ref × divider ratio
    return voltage

def battery_percent(voltage):
    """Rough Li-Ion percentage from voltage (single cell, 3.0-4.2V)."""
    if voltage >= 4.10:
        return 100
    elif voltage >= 3.95:
        return 80
    elif voltage >= 3.80:
        return 60
    elif voltage >= 3.70:
        return 40
    elif voltage >= 3.55:
        return 20
    elif voltage >= 3.40:
        return 10
    else:
        return 0    # below 3.4V — critically low

# Read and display
v = read_battery_voltage()
pct = battery_percent(v)
print(f"Battery: {v:.2f}V ({pct}%)")
```

### Firmware (C / Pico SDK)

```c
#include "hardware/adc.h"
#include "hardware/gpio.h"

float read_battery_voltage(void) {
    // GPIO29 = ADC3 on Pico W (VSYS/3 divider)
    adc_init();
    adc_gpio_init(29);
    adc_select_input(3);  // ADC3

    // On Pico W, GPIO25 controls the VSYS ADC mux
    // Must set GPIO25 high to connect VSYS divider to ADC
    gpio_init(25);
    gpio_set_dir(25, GPIO_OUT);
    gpio_put(25, 1);

    uint16_t raw = adc_read();  // 12-bit: 0-4095
    float voltage = raw * 3.3f / 4095.0f * 3.0f;

    gpio_put(25, 0);  // release mux
    return voltage;
}
```

### USB Detection

GPIO24 goes HIGH when USB VBUS is present. Use this to show a charging icon:

```python
import machine

vbus_pin = machine.Pin(24, machine.Pin.IN)

if vbus_pin.value():
    print("USB connected — charging")
else:
    print("On battery")
```

### Voltage-to-Percentage Curve (Li-Ion 10440)

```
Voltage   State           Percent
──────────────────────────────────
4.20V     Fully charged     100%
4.10V     Nearly full        90%
3.95V     Good               80%
3.80V     Moderate           60%
3.70V     Nominal            40%
3.55V     Getting low        20%
3.40V     Low                10%
3.20V     Critical            5%
3.00V     Empty               0%
2.90V     DW01A cutoff     (power off)
```

The curve is non-linear — Li-Ion cells spend most of their life between 3.6-3.9V, then drop sharply below 3.4V. The percentage mapping above accounts for this.

---

## Power Budget

| State | Current Draw | Notes |
|---|---|---|
| Pico W active, WiFi off | ~28mA | Normal operation |
| Pico W deep sleep | ~1.0mA | `dormant()` or `lightsleep()` |
| e-Paper refresh | ~26mW peak | Only during screen update (~2s) |
| Tamagotchi mode (10min on / 50min sleep) | ~5.5mA avg | Realistic daily use |

**Battery life estimates (700mAh parallel 10440):**

| Mode | Current | Runtime |
|---|---|---|
| Always on, WiFi off | 28mA | ~25 hours |
| Tamagotchi mode | 5.5mA | ~5 days |
| Deep sleep only | 1.0mA | ~29 days |

**Solar supplement (6 hours direct sun):**

- Solar input: ~100mA x 6h = 600mAh/day
- Tamagotchi draw: ~5.5mA x 24h = 132mAh/day
- **Net daily gain: +468mAh** — battery stays topped up indefinitely in sunny conditions

---

## Safety Checklist

- [ ] Cells wired in **parallel** (NOT series)
- [ ] Multimeter confirms 3.6-4.2V across the parallel pack before connecting
- [ ] TP4056 module has DW01A protection IC (check for the small 6-pin SOT-23 near BAT pads)
- [ ] Using **OUT+/OUT-** pads (not BAT+/BAT-) for Pico connection
- [ ] Solar diode installed (or confirmed built-in on module)
- [ ] No bare wire contacts that could short inside the enclosure
- [ ] Battery voltage reading works before sealing the case

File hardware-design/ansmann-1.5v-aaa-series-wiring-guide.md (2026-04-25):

# Wiring Guide: Ansmann 1.5V Li-Ion AAA Cells — Series Config for Pico 2 W

## Table of Contents

1. [Overview](#overview)
2. [Bill of Materials](#bill-of-materials)
3. [Series Wiring Diagram](#series-wiring-diagram)
4. [Battery Contact Recommendations](#battery-contact-recommendations)
5. [Wire Gauge Selection](#wire-gauge-selection)
6. [Step-by-Step Assembly](#step-by-step-assembly)
7. [Wire Routing Through the Cradle](#wire-routing-through-the-cradle)
8. [Safety Considerations](#safety-considerations)
9. [Charging the Ansmann Cells](#charging-the-ansmann-cells)
10. [Alternative: Raw 10440 Li-Ion Cells with TP4056](#alternative-raw-10440-li-ion-cells-with-tp4056)

---

## Overview

The Dilder virtual pet is powered by a Raspberry Pi Pico 2 W driving a Waveshare 2.13" e-ink display. This guide covers wiring two Ansmann 1.5V Li-Ion AAA cells in **series** to produce 3.0V, fed into the Pico W's VSYS pin (rated 1.8–5.5V).

**Critical distinction:** These Ansmann cells are *not* raw Li-Ion cells. Each cell contains an internal 3.7V lithium cell, a boost/buck converter, and USB-C charge circuitry. The output at the cell terminals is a regulated, constant 1.5V regardless of internal state of charge. This means:

- The TP4056 charge board **cannot** be used with these batteries — it expects a raw 3.7V cell on its BAT+/BAT- output.
- Two cells in series yield a steady 3.0V, well within the Pico W's VSYS range.
- Each cell charges individually via its own built-in USB-C port.

**Physical layout:** The 3D-printed cradle insert has two AAA bays running along the X axis at the ±Y edges, with the Pico 2 W seated in the center channel between them. The cradle plugs into a top cover; a base plate closes the bottom.

---

## Bill of Materials

| Item | Qty | Notes |
|---|-----|---|
| Ansmann 1.5V Li-Ion AAA (USB-C, 500mAh) | 2 | Series pair |
| AAA battery spring contacts (see section 4) | 4 | 2 per bay (1 spring + 1 flat) |
| 26 AWG stranded silicone hook-up wire | ~15 cm | 3 runs: series link, VSYS, GND |
| 1N5817 Schottky diode (DO-41) | 1 | Optional reverse-polarity protection |
| 0.5A polyfuse (PPTC resettable) | 1 | Optional overcurrent protection |
| Heat-shrink tubing, 2mm dia | ~5 cm | Insulate solder joints |
| CA glue or 5-min epoxy | small amount | Secure contacts in cradle bays |

---

## Series Wiring Diagram

Orient the cells so Cell 1's positive nub faces Cell 2's negative end — this keeps the series link wire short across the center of the cradle.

```
                        SERIES WIRING LAYOUT
                     (view from above, base plate removed)

    -Y edge                    CENTER                    +Y edge
 +--------------+      +------------------+      +--------------+
 |              |      |                  |      |              |
 |   CELL 1    |      |    Pico 2 W      |      |   CELL 2    |
 |              |      |                  |      |              |
 |  (-)====(+) |      |  GND pin  VSYS   |      | (+)====(-) |
 |   |      |  |      |    |        |     |      |  |      |  |
 +----|------|--+      +----|--------|-----+      +--|------|--+
      |      |              |        |               |      |
      |      +--------------+--------+---------------+      |
      |           Series Link (Cell1+ to Cell2-)             |
      |                     |        |                       |
      +---------------------+        +-----------------------+
        GND wire                        VSYS wire
     (Cell1- to Pico GND)           (Cell2+ to Pico VSYS)
```

**Schematic (single-line):**

```
Cell 1 (-)  ----[GND wire]------>  Pico GND (pin 38)
Cell 1 (+)  ----[series wire]---->  Cell 2 (-)
Cell 2 (+)  ----[VSYS wire]----->  Pico VSYS (pin 39)

         Cell 1          Cell 2
     -|  1.5V  |+  -->  -|  1.5V  |+
     |         |          |         |
     |         +----------+         |
     |       series link            |
     |                              |
     +--- GND              VSYS ---+
          |                  |
          +--[ Pico 2 W ]---+
               3.0V supply
```

**With optional protection (recommended):**

```
Cell 2 (+) ---[polyfuse 0.5A]---[1N5817 diode]---> Pico VSYS (pin 39)
                                  anode   cathode
                                (band on cathode side, toward Pico)

Note: The 1N5817 drops ~0.3V → supply becomes ~2.7V.
      Still well above the Pico W's 1.8V minimum.
```

---

## Battery Contact Recommendations

### Option A: Bauhaus / Hardware Store (Easiest)

Walk into Bauhaus (or any German hardware store) and grab:

| Item | Where in store | What to do with it | Price |
|---|---|---|---|
| **2× single AAA battery holders** (Batteriehalter, 1x AAA, Goobay or no-name) | Electronics/hobby aisle | Pop out the spring (-) and flat (+) contacts, press-fit them into the cradle bays | €1–2 each |
| **Battery contact spring pack** (Batteriefederkontakte) | Near battery display | 4-pack of spring + flat contacts for AAA/AA cells, solder tabs included | €2–4 pack |
| **0.3mm brass strip** (Messingblech) | Metals/hobby metals section | Cut into 8×15mm tabs, bend into leaf-spring contacts | €3–5 per strip |

**The easiest option:** Buy 2 cheap single-AAA holders, pull the contacts out, and CA-glue them into the cradle's bay pockets.

### Option B: Online — Keystone Spring Contacts

| Part Number | Type | Description | Price (each) |
|---|---|---|---|
| Keystone 5225 | Negative (spring) | Coil spring, solder lug, AAA/AA | €0.30–0.50 |
| Keystone 5226 | Positive (flat) | Flat dimple contact, solder lug | €0.30–0.50 |
| Keystone 209 | Negative (spring) | Larger coil spring, wide solder tab | €0.40–0.60 |
| Keystone 210 | Positive (button) | Button contact, solder tab | €0.40–0.60 |

Available from Mouser, Digikey, or Reichelt.

### Option C: PCB-Mount AAA Holders (Embed Whole)

| Part Number | Description | Price |
|---|---|---|
| Keystone 82 | Single AAA, PC pins | €0.80–1.20 |
| MPD BH411 | Single AAA, through-hole | €0.50–0.90 |

These can be embedded directly into the cradle if the bay dimensions are adjusted to fit the holder body.

### Mounting Contacts in the 3D-Printed Cradle

1. Design rectangular pockets (~6mm wide × 8mm tall × 3mm deep) at each end of each AAA bay
2. Spring (negative) contact goes at one end, flat (positive) contact at the other
3. The contact's solder lug should protrude through a slot in the cradle wall
4. Secure with a drop of CA glue or 5-minute epoxy
5. Let adhesive cure before soldering wires to the lugs

---

## Wire Gauge Selection

| Parameter | Value |
|---|---|
| Peak current (WiFi TX burst) | ~250 mA |
| Typical current (e-ink refresh) | ~30–80 mA |
| Sleep/idle current | < 5 mA |
| Longest wire run | ~8 cm |

**Use 26 AWG stranded silicone-insulated wire.** At 250 mA over 8 cm, voltage drop is only 2.7 mV — negligible. Silicone insulation tolerates soldering heat and stays flexible in the tight cradle space. 28 AWG also works.

---

## Step-by-Step Assembly

### Step 1: Prepare Contacts

1. If using battery holders from Bauhaus: pry out the spring and flat contacts with a small flathead screwdriver.
2. Test-fit each contact in the cradle bay pockets.
3. Glue in place with CA glue. Let cure 5 minutes.

### Step 2: Cut and Strip Wires

| Wire | Color | Length | Connects |
|---|---|---|---|
| GND | Black | ~7 cm | Cell 1 (−) spring → Pico GND (pin 38) |
| Series link | Yellow | ~5 cm | Cell 1 (+) flat → Cell 2 (−) spring |
| VSYS | Red | ~7 cm | Cell 2 (+) flat → Pico VSYS (pin 39) |

Strip 3–4 mm from each end.

### Step 3: Tin Everything

1. Flux each contact solder lug.
2. Tin each lug and each wire end at 350–370°C with a chisel tip.

### Step 4: Solder Wires to Contacts

1. **GND (black):** One end to Cell 1 negative spring lug. Other end free.
2. **Series link (yellow):** One end to Cell 1 positive flat lug, other end to Cell 2 negative spring lug.
3. **VSYS (red):** One end to Cell 2 positive flat lug. Other end free.
4. Apply heat-shrink over each joint.

### Step 5: Optional Protection Components

1. **Polyfuse** (Bourns MF-R050): solder inline on the red VSYS wire.
2. **Schottky diode** (1N5817): solder inline, band/cathode toward the Pico.

### Step 6: Solder to Pico 2 W

1. **GND (black):** Solder to pin 38 (GND) — bottom-right, adjacent to VSYS.
2. **VSYS (red):** Solder to pin 39 (VSYS) — system power input.
3. If headers are installed, solder to the underside of the pin. If no headers, solder directly to the through-hole pad.

### Step 7: Test Before Closing

1. Insert both Ansmann cells (check polarity).
2. Measure across VSYS and GND — expect **2.9–3.1V**.
3. Power on the Pico — LED should light, firmware should boot.
4. If 0V or negative, a cell is backwards.

---

## Wire Routing Through the Cradle

```
    CROSS-SECTION VIEW (looking along X axis)

    +-------------------------------------------------------+
    |                    TOP COVER                           |
    +-------------------------------------------------------+
    |  Cell 1 bay  |  wire channel  |  Cell 2 bay           |
    |  (-Y side)   |  (center)      |  (+Y side)            |
    |              |                |                        |
    |  [spring] ===|=== GND wire ===|======================  |
    |              |                |                        |
    |  [flat]  ====|= series link ==|=== [spring]            |
    |              |                |                        |
    |              |  VSYS wire ====|=== [flat]              |
    |              |  +----------+  |                        |
    |              |  | Pico 2 W |  |                        |
    |              |  +----------+  |                        |
    +-------------------------------------------------------+
    |                   BASE PLATE                           |
    +-------------------------------------------------------+
```

- Run wires through the 3 mm cable pass-through at the bottom of the connecting block.
- Keep GND and VSYS on opposite sides to avoid shorts.
- Tack wires down with a small dab of hot glue at each end.
- The series link crosses under/beside the Pico — keep it flat against the cradle floor.

---

## Safety Considerations

### Reverse Cell Insertion

| Scenario | Result | Risk |
|---|---|---|
| One cell reversed | 0V net (1.5V − 1.5V), Pico won't power on | **Low** — no damage |
| Both cells reversed | −3.0V on VSYS (reversed polarity) | **High** — can destroy Pico |
| One cell missing | Open circuit, no current | **None** |

**Mitigations:**
1. **Schottky diode on VSYS** (recommended) — blocks reverse current, costs ~0.3V drop.
2. **Polarity markings** on the cradle bays — mark + and − clearly.
3. **Asymmetric bay design** — the Ansmann cells have a USB-C port on one end that's slightly wider. Use this as a keying feature.

### Over-discharge

The Ansmann cells have built-in discharge cutoff. When the internal cell drops too low, the boost converter shuts off and output goes to 0V. No external low-voltage cutoff needed.

### USB + Battery Simultaneously

The Pico 2 W has an onboard Schottky diode between VBUS (USB 5V) and VSYS. When USB is connected, VBUS (~4.7V) is higher than the battery (3.0V), so the battery is effectively disconnected. Safe.

---

## Charging the Ansmann Cells

**Each cell charges via its own built-in USB-C port** under a small cap at the negative end.

### In-Place Charging (if ports are accessible)

If the cradle design has cutouts at the battery bay ends exposing the USB-C ports:
- Plug a USB-C cable into each cell
- The cell outputs 1.5V while charging (pass-through) — Pico stays powered
- Charge time: ~1.5–2 hours per cell

### Remove-to-Charge

If the cradle encloses the cells fully:
- Remove the base plate
- Slide cells out of the bays
- Charge externally with any USB-C cable + 5V source

**The TP4056 board CANNOT charge these cells.** It would try to push 4.2V into the cell's 1.5V output stage, which is not designed for external voltage input and could damage the cell's internal circuitry.

---

## Alternative: Raw 10440 Li-Ion Cells with TP4056

If you want to use the TP4056 charge board, substitute raw 10440 Li-Ion cells (AAA form factor, 3.7V nominal, ~350mAh).

| Parameter | Ansmann 1.5V AAA | Raw 10440 |
|---|---|---|
| Output voltage | Constant 1.5V | 3.0–4.2V (varies) |
| Charging | Built-in USB-C per cell | TP4056 or external |
| Wiring | 2 in **series** = 3.0V | 2 in **parallel** = 3.7V |
| VSYS feed | 3.0V constant | 3.0–4.2V variable |

### 10440 Parallel Wiring

Wire both positives together, both negatives together → single 3.7V pack. Connect to TP4056 BAT+/BAT−. Derate TP4056 R_prog to ~3.4 kΩ for 350 mA charge current.

```
Cell A (+) ---+--- Cell B (+) ---> TP4056 BAT+ ---> VSYS
Cell A (-) ---+--- Cell B (-) ---> TP4056 BAT- ---> GND
```

**Never wire 10440s in series** — 2S = 7.4V nominal, exceeds the Pico W's 5.5V VSYS maximum.

---

*Guide authored 2026-04-25 as part of the Dilder Rev 2 enclosure design.*

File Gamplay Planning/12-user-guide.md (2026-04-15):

# Dilder User Guide

> The complete guide to raising, nurturing, and adventuring with your digital octopus companion.

---

## Table of Contents

**I. Introduction**
1. [What Is Dilder?](#1-what-is-dilder)
2. [The Origin Story — Meet Jamal](#2-the-origin-story--meet-jamal)
3. [Your First Hatch](#3-your-first-hatch)

**II. Getting to Know Your Octopus**
4. [The 16 Emotional States](#4-the-16-emotional-states)
   - 4.1 [Normal / Sassy](#41-normal--sassy)
   - 4.2 [Hungry](#42-hungry)
   - 4.3 [Tired](#43-tired)
   - 4.4 [Sad](#44-sad)
   - 4.5 [Angry](#45-angry)
   - 4.6 [Excited](#46-excited)
   - 4.7 [Chill](#47-chill)
   - 4.8 [Lazy](#48-lazy)
   - 4.9 [Fat](#49-fat)
   - 4.10 [Chaotic](#410-chaotic)
   - 4.11 [Weird](#411-weird)
   - 4.12 [Unhinged](#412-unhinged)
   - 4.13 [Slap Happy](#413-slap-happy)
   - 4.14 [Horny](#414-horny)
   - 4.15 [Nostalgic](#415-nostalgic)
   - 4.16 [Homesick](#416-homesick)
5. [Reading the Display](#5-reading-the-display)

**III. Caring for Dilder**
6. [The Stat System](#6-the-stat-system)
   - 6.1 [Primary Stats](#61-primary-stats)
   - 6.2 [Secondary Stats](#62-secondary-stats)
   - 6.3 [Hidden Stats](#63-hidden-stats)
   - 6.4 [Stat Decay & Modifiers](#64-stat-decay--modifiers)
7. [Care Actions](#7-care-actions)
   - 7.1 [Feeding](#71-feeding)
   - 7.2 [Cleaning](#72-cleaning)
   - 7.3 [Playing](#73-playing)
   - 7.4 [Medicine](#74-medicine)
   - 7.5 [Scolding & Discipline](#75-scolding--discipline)
   - 7.6 [Sleep](#76-sleep)
8. [The Daily Rhythm](#8-the-daily-rhythm)

**IV. The Physical World**
9. [Sensor Interactions](#9-sensor-interactions)
   - 9.1 [Voice & Sound](#91-voice--sound)
   - 9.2 [Light & Darkness](#92-light--darkness)
   - 9.3 [Temperature & Humidity](#93-temperature--humidity)
   - 9.4 [Motion & Movement](#94-motion--movement)
10. [Step Tracking & Activity](#10-step-tracking--activity)
    - 10.1 [Daily Step Targets](#101-daily-step-targets)
    - 10.2 [Weekly Targets](#102-weekly-targets)
    - 10.3 [Monthly Targets](#103-monthly-targets)
    - 10.4 [The Streak System](#104-the-streak-system)
11. [Location & Exploration](#11-location--exploration)

**V. Growing Up**
12. [Life Stages](#12-life-stages)
    - 12.1 [Egg](#121-egg)
    - 12.2 [Hatchling](#122-hatchling)
    - 12.3 [Juvenile](#123-juvenile)
    - 12.4 [Adolescent](#124-adolescent)
    - 12.5 [Adult](#125-adult)
    - 12.6 [Elder](#126-elder)
13. [Evolution — The Six Adult Forms](#13-evolution--the-six-adult-forms)
    - 13.1 [Deep-Sea Scholar](#131-deep-sea-scholar)
    - 13.2 [Reef Guardian](#132-reef-guardian)
    - 13.3 [Tidal Trickster](#133-tidal-trickster)
    - 13.4 [Abyssal Hermit](#134-abyssal-hermit)
    - 13.5 [Coral Dancer](#135-coral-dancer)
    - 13.6 [Storm Kraken](#136-storm-kraken)
14. [Rebirth & Legacy](#14-rebirth--legacy)

**VI. Progression & Collection**
15. [Bond Levels](#15-bond-levels)
16. [The Dialogue System](#16-the-dialogue-system)
17. [Decor & Cosmetics](#17-decor--cosmetics)
    - 17.1 [Hats & Headwear](#171-hats--headwear)
    - 17.2 [Backgrounds & Environments](#172-backgrounds--environments)
    - 17.3 [Accessories](#173-accessories)
    - 17.4 [Animation Styles](#174-animation-styles)
18. [Treasure Hunts](#18-treasure-hunts)

**VII. Achievements**
19. [Achievement System Overview](#19-achievement-system-overview)
20. [Care Achievements](#20-care-achievements)
21. [Exploration Achievements](#21-exploration-achievements)
22. [Social Achievements](#22-social-achievements)
23. [Environmental Achievements](#23-environmental-achievements)
24. [Mastery Achievements](#24-mastery-achievements)
25. [Step Achievements](#25-step-achievements)
26. [Secret Achievements](#26-secret-achievements)

**VIII. Environments & Scenes**
27. [The 22 Environments](#27-the-22-environments)
28. [Outfits & Decor Props](#28-outfits--decor-props)
29. [Aura & Particle Effects](#29-aura--particle-effects)

**IX. Controls & Navigation**
30. [Button Layout](#30-button-layout)
31. [Menu System](#31-menu-system)
32. [Quick Actions](#32-quick-actions)

**X. Tips & Secrets**
33. [Beginner Tips](#33-beginner-tips)
34. [Advanced Strategies](#34-advanced-strategies)
35. [Easter Eggs & Hidden Features](#35-easter-eggs--hidden-features)

---

# I. Introduction

## 1. What Is Dilder?

Dilder is a physical digital companion — a pocket-sized octopus that lives on an e-ink screen, reacts to the real world through sensors, and develops a genuine personality based on how you raise it. It's part Tamagotchi, part fitness tracker, part sassy roommate.

Carry Dilder in your pocket and it counts your steps. Talk to it and it gets smarter. Pet it and it relaxes. Neglect it and it gets sad — visibly, undeniably sad. Feed it too much and it gets fat. Shake it and it gets angry. Walk 10,000 steps and it throws a party.

Dilder grows through 6 life stages over 30+ real days, evolves into one of 6 adult forms based on how you raised it, and eventually enters an elder stage where it reflects on your journey together. When it's ready, it can lay an egg and start the cycle anew — passing down traits, decor, and a fraction of the bond you built.

The device runs on a custom PCB with an ESP32-S3 microcontroller, a 2.13" e-ink display (250x122 pixels, black and white), a 1000mAh battery, and sensors for light, sound, temperature, humidity, and motion. Everything renders in real-time — no pre-baked sprites, no stored frames. The octopus is drawn mathematically, line by line, 60 times a minute.

All 16 emotions with aura effects

---

## 2. The Origin Story — Meet Jamal

It started in a TEDi — a German discount store — with a massive plush octopus grinning from the sale bin. Soft as a cloud, impossibly charming, and suspiciously self-aware for a stuffed animal.

We bought him on impulse. On the walk home, something happened — we started talking *to* him. Then *about* him. A fully formed personality emerged between the shop and the front door: laid-back but opinionated, sassy but warm, suspiciously wise for a boneless creature.

He claimed the armchair the moment we walked in. He hasn't moved since. He later acquired a hat. Nobody remembers putting it there.

We named him **Jamal**.

Jamal, the original octopus

The logical next question: *what if we could bring him to life?* Not literally — but as a tiny digital companion on a screen. Something that lives in your pocket, reacts to the world, grows a personality, and judges your life choices.

Dilder is that answer. Named after... well, that's between us and Jamal.

Every aspect of Dilder's personality — the sass, the warmth, the unsolicited opinions — comes from Jamal. The 16 emotional states, the 823 quotes, the way it reacts when you yell at it ("...that was loud. Are you okay?") — it's all channeled from a plush octopus sitting in an armchair, wearing a hat, watching the whole project unfold with an expression that says "I could do better."

---

## 3. Your First Hatch

When you first power on your Dilder, you'll see an egg on the screen. It wobbles gently, waiting.

**To hatch your octopus:**
- **Tap the device** — Gently tap or shake the device (detected by accelerometer). Each tap adds progress.
- **Keep it warm** — A comfortable room temperature (18-24C) adds passive hatch progress.
- **Talk to it** — The microphone detects your voice. Talking to the egg helps it along.

At 25% progress, a crack appears. At 50%, the crack widens. At 75%, pieces begin to fall away. At 100% — your hatchling emerges.

Your tiny octopus blinks at the screen. It says its first word:

> "mama?"

Congratulations. You're a parent now.

---

# II. Getting to Know Your Octopus

## 4. The 16 Emotional States

Dilder expresses itself through 16 distinct emotions. Each has unique eyes, mouth animations, body language, and a curated set of quotes. The emotion your octopus displays is determined by its stats, the sensor environment, recent events, and a touch of randomness.

### 4.1 Normal / Sassy

Normal emotion

The default state when all stats are balanced (40-80 range). Centered pupils with white highlights, a cycling smirk-to-smile mouth, and a gentle 1-pixel breathing bob. This is Dilder at its most... Dilder. Sassy, supportive, full of opinions.

> "MATTRESSES ARE BODY SHELVES."

**Triggered by:** All stats balanced, no extreme sensor inputs.

### 4.2 Hungry

Hungry emotion

Pupils shift upward (staring at imaginary food), mouth drools with a wide oval and drip animation. Body leans up with a bobbing beg. Appears when hunger drops below 20.

> "hungwy..." (Hatchling)
> "I can't... eat... another... *burp*" (when overfed)

**Triggered by:** Hunger < 20. Intensity increases as hunger approaches 0.
**Fix:** Feed → Meal or Snack from the menu.

### 4.3 Tired

Tired emotion

Half-closed eyelids cover the top of each eye, tiny pupils sag low, and a tall vertical yawn opens and closes. The body droops 2-3 pixels and narrows slightly, as if deflating.

> "Five more minutes? The dark is so... dark."

**Triggered by:** Energy < 15, or late hour + low energy.
**Fix:** Turn off the light or place in a dark environment. Dilder will fall asleep and regenerate energy.

### 4.4 Sad

Sad emotion

Downward-looking pupils with droopy inverted-arc brows. A gentle frown that barely moves. The body drops 3 pixels lower than normal and narrows 1 pixel per side — a deflated, withdrawn posture.

> "I was starting to think you forgot about me..."

**Triggered by:** Happiness < 20, or no interaction for 4+ hours.
**Fix:** Pet, play, talk, or take a walk. Dilder recovers quickly — "You're back! I knew you'd come back!"

### 4.5 Angry

Angry emotion

Pupils shift inward and down in a glare, V-shaped brow arcs angle sharply, and a tight inverted frown sets the jaw. The body puffs 2 pixels wider and trembles — Dilder is making itself look bigger.

> "...that was loud. Are you okay?"

**Triggered by:** Harsh scolding (incorrect), violent shaking, or extreme hunger + low happiness combo.
**Fix:** Wait it out (30 seconds minimum dwell), then pet gently. Don't shake.

### 4.6 Excited

Excited emotion

Star-shaped cross pupils (plus signs in the eyes), a wide-open grin, and rapid 3-pixel vertical bouncing. Dilder is thrilled.

> "We did it! 5,000 steps! My tentacles are BURNING."

**Triggered by:** Just fed when very hungry, step milestone reached, achievement unlocked, treasure found.
**Duration:** Brief — 15 seconds of pure joy before settling.

### 4.7 Chill

Chill emotion

A cool side-glance with pupils shifted to one side, relaxed asymmetric half-smile, and a subtle lean-back sway. Dilder is at peace with the universe.

> "You know what? Life is good. Really good."

**Triggered by:** All stats > 60 in a calm environment (low noise, comfortable temperature).

### 4.8 Lazy

Lazy emotion

Nearly shut eyes with barely visible dot pupils, a flat horizontal line mouth, and the entire body tilted to lay on its side with tentacles draped rightward. The quintessential couch potato.

> "Whatever."

**Triggered by:** Energy 15-30 with no interaction for 2+ hours, or overweight.

### 4.9 Fat

Fat emotion

Wide, content pupils, a satisfied smile with puffy cheeks, and a custom body shape — wider dome (+5 pixels per side), no visible waist, thicker tentacles, and a gentle belly jiggle animation.

> "I can't... eat... another... *burp*"

**Triggered by:** Weight > 130 (normal is 100). Caused by overfeeding.
**Fix:** Play mini-games (-1 weight per session) and reduce feeding frequency.

### 4.10 Chaotic

Chaotic emotion

Spiral concentric-circle pupils, a zigzag lightning-bolt mouth, and wild 3-pixel sine-wave body distortion with random wobble. Everything is happening at once.

> (No coherent quotes — just chaos)

**Triggered by:** 5+ events in 30 seconds, or simultaneous shaking + loud noise. Very short dwell (10 seconds).

### 4.11 Weird

Weird emotion

Misaligned pupils (left looks up-left, right looks down-right), a wobbly sine-wave mouth, and a body lean with wavy row distortion. Dilder is being... Dilder.

> "Do fish know they're wet?"

**Triggered by:** 5% random chance per emotion tick when bored (1+ hour idle, moderate stats). One of the rarest regular emotions.

### 4.12 Unhinged

Unhinged emotion

Tiny 2x2 pinprick pupils with no highlights, a giant scream-mouth exposing teeth, and rapid 1-2 pixel random jitter. This is Dilder in crisis.

> (Distressed vocalizations only)

**Triggered by:** Health < 20 AND multiple stats critical simultaneously. This is the warning sign — your octopus needs help NOW.
**Fix:** Immediate care: feed, clean, administer medicine. Multiple actions in quick succession.

### 4.13 Slap Happy

Slap Happy emotion

One eye squinted shut (thin slit), one eye with an oversized manic pupil, a wide wobbly sine-wave grin, and a 3-pixel side-to-side swaying body with wavy row distortion. This is the emotional rebound.

> "HAHAHAHA I'M FINE I'M TOTALLY FINE"

**Triggered by:** Happiness > 90 after recently being < 30. The relief of recovery expressed as manic joy.

### 4.14 Horny

Horny emotion

Heart-shaped diamond pupils, a wide smile with tongue out, and a rhythmic throbbing pulse (body expands and contracts 2 pixels). Dilder is... feeling things.

> (Context-appropriate flirtatious quotes)

**Triggered by:** Adolescent or Adult stage + happiness > 70 + bond > threshold. Low probability (~2% per emotion tick). Rare and brief.

### 4.15 Nostalgic

Nostalgic emotion

Pupils looking up and to the right (remembering), a gentle wistful half-smile, and a slow 2-pixel horizontal + 1-pixel vertical sway. Dilder is thinking about the good old days.

> "Remember when I was just a hatchling? You were so attentive back then..."

**Triggered by:** Age milestones (every 7 days), or returning to a familiar location (home WiFi detected after being away).

### 4.16 Homesick

Homesick emotion

Teary eyes with pixel tear drops falling, a wobbly trying-not-to-cry mouth, and a body that curls 1 pixel down and 2 pixels narrower — shrinking inward.

> "I miss the armchair..."

**Triggered by:** Away from home WiFi for 4+ hours, or briefly when arriving at a completely new location.
**Fix:** Go home. Or comfort with the center button — interaction reduces Homesick faster.

---

## 5. Reading the Display

The e-ink screen is divided into three zones:

```
┌──────────────────────────────────────────────────┐  
│ 12:34 PM          [HUN][HAP][ENE][HYG][HEA]     │  Header (16px)
├──────────────────────────────────────────────────┤  
│                                                  │
│              YOUR OCTOPUS                        │  Pet Area (80px)
│              + equipped decor                    │
│                                                  │
├──────────────────────────────────────────────────┤  
│ "Good morning! I had the strangest dream..."     │  Dialogue (26px)
└──────────────────────────────────────────────────┘  
```

**Header Bar:** Current time on the left. Five stat icons on the right — each is a tiny bar that fills/empties proportionally. When a stat drops below 20, its icon inverts (white on black) to demand attention.

**Pet Area:** Your octopus, rendered in real-time with its current emotion, equipped hat, background, and accessories. Animations cycle through 4 frames.

**Dialogue Box:** Context-sensitive quotes appear here. They auto-dismiss after 5-15 seconds (scaling with quote length). Press SELECT to dismiss early.

---

# III. Caring for Dilder

## 6. The Stat System

### 6.1 Primary Stats

Five stats govern Dilder's wellbeing. All range from 0 to 100 and decay naturally over time:

| Stat | What It Represents | Decay Rate | Critical Threshold | Visual Cue |
|---|---|---|---|---|
| **Hunger** | Food level | -1 every 10 min | < 20 | Hungry emotion |
| **Happiness** | Emotional wellbeing | -1 every 15 min | < 20 | Sad emotion |
| **Energy** | Wakefulness | -1 every 12 min (awake) | < 15 | Tired emotion |
| **Hygiene** | Cleanliness | -1 every 30 min | < 25 | Uncomfortable |
| **Health** | Overall condition | Doesn't decay directly | < 30 | Sick / Unhinged |

**Health** is special — it doesn't decay on its own. Instead, it drops when multiple other stats are critical simultaneously. Keep hunger, happiness, energy, and hygiene healthy, and health stays at 100.

### 6.2 Secondary Stats

These accumulate over your octopus's lifetime and determine its evolution:

| Stat | How It Grows | What It Affects |
|---|---|---|
| **Bond Level** | Total interactions over lifetime | Unlocks features, dialogue, decor slots |
| **Discipline** | Correct scolding during misbehavior | Evolution path |
| **Intelligence** | Talking to Dilder, word exposure (mic) | Dialogue complexity and vocabulary |
| **Fitness** | Steps walked, distance traveled | Evolution, abilities, animations |
| **Exploration** | Unique locations visited (WiFi fingerprints) | Decor themes, world knowledge |
| **Age** | Real time since hatch | Life stage transitions |
| **Weight** | Feeding frequency (meals +1, snacks +2, play -1) | Visual change, Fat emotion trigger |

### 6.3 Hidden Stats

You can't see these directly, but they shape everything:

- **Care Mistakes** — Every time a critical stat goes unmet for 15 minutes, a care mistake is logged. Permanent. Affects evolution quality.
- **Consecutive Days** — Your streak of daily interaction. Streak bonuses at 3, 7, 14, 30, 60, 90, and 365 days.
- **Noise Exposure** — Cumulative loud sound events. Shapes personality traits.
- **Night Disturbances** — Times woken during sleep. Affects morning mood.

### 6.4 Stat Decay & Modifiers

Stat decay isn't constant — it's modified by context:

| Modifier | Effect on Decay |
|---|---|
| **Hatchling stage** | 2x faster (very needy baby) |
| **Elder stage** | 0.6x slower (self-sufficient) |
| **High bond level** | Happiness decays up to 15% slower |
| **Good environment** | 18-24C, 40-60% humidity → 10% slower hygiene decay |
| **Bad environment** | >28C or <15C → 30% faster decay |
| **Active hours** (8am-8pm) | Hunger decays 20% faster |
| **Walking** | Energy decays 30% faster, but happiness decays 20% slower |
| **14+ day streak** | Happiness decay reduced 10% |

---

## 7. Care Actions

### 7.1 Feeding

Open the menu → **Feed**:

| Food | Effect | Weight | Cooldown | Unlock |
|---|---|---|---|---|
| **Meal** | +30 Hunger | +1 | 30 seconds | Always available |
| **Snack** | +10 Hunger, +15 Happiness | +2 | 15 seconds | Always available |
| **Treat** | +5 Hunger, +25 Happiness | +3 | 60 seconds | Bond level 4 (Friend) |

**Overfeeding warning:** If weight exceeds 130, the Fat emotion triggers. Balance meals with play (which burns -1 weight per session).

### 7.2 Cleaning

Open the menu → **Care** → **Clean**:
- +40 Hygiene
- 60-second cooldown
- +5 Bond XP

### 7.3 Playing

Open the menu → **Play**:

| Game | Effect | Cost | Cooldown |
|---|---|---|---|
| **Mini-game** | +20 Happiness, -1 Weight | -10 Energy | 30 seconds |
| **Tickle** | +5 Happiness (quick) | None | 3 seconds |

Mini-games are the primary way to manage weight and boost happiness simultaneously.

### 7.4 Medicine

Open the menu → **Care** → **Medicine**:
- Only available when Health < 30 (the menu item is hidden otherwise)
- +20 Health
- 120-second cooldown
- Forces brief Sad emotion (medicine is yucky)

### 7.5 Scolding & Discipline

Dilder sometimes misbehaves — refusing food, making a mess, acting out. A prompt appears: **"Dilder is being defiant!"**

You have 60 seconds to respond:
- **Long-press ACTION (2 seconds):** Scold → +25 Discipline, brief Angry face, then compliance.
- **Yell into the mic:** Volume spike during misbehavior counts as scolding.
- **Ignore it:** Window closes with no penalty, but no discipline gained.

**Warning:** Scolding when Dilder ISN'T misbehaving (no prompt) → -10 Happiness, -5 Bond XP, and a Sad face. The game tracks correct vs. incorrect scolding. Discipline only grows from correct scolding.

4 discipline windows open per life stage. 100% discipline at a stage transition gives the best evolution path.

### 7.6 Sleep

Dilder sleeps when:
- **Auto-sleep:** Ambient light < 10 lux AND (energy < 20 OR it's after 10pm). Dilder shows a drowsy animation, then falls asleep after 30 seconds.
- **Manual sleep:** Open the menu → **Care** → **Light** to toggle sleep.

During sleep:
- Energy regenerates (+1 every 30 seconds → full in ~50 minutes)
- Other stats decay at 0.25x normal rate
- Display shows a sleeping animation (static, no refresh needed)
- Device enters low-power mode (~0.8mA)

**Wake triggers:** Bright light, loud noise, significant motion (picked up), button press, or energy reaching 95.

---

## 8. The Daily Rhythm

```
  MORNING (6am-10am)
  ┌──────────────────────────────────────┐
  │ Dilder wakes with the light          │
  │ Morning greeting based on mood       │
  │ Feed (hunger decayed overnight)      │
  │ Pet/interact for happiness boost     │
  └──────────────────────────────────────┘
              │
              ▼
  DAYTIME (10am-6pm)
  ┌──────────────────────────────────────┐
  │ Carry Dilder — steps tracked         │
  │ Locations detected (WiFi)            │
  │ Environmental sensing (light, temp)  │
  │ Periodic dialogue check-ins          │
  │ Random events (10% daily chance)     │
  └──────────────────────────────────────┘
              │
              ▼
  EVENING (6pm-10pm)
  ┌──────────────────────────────────────┐
  │ Feed again (hunger decayed)          │
  │ Review daily activity summary        │
  │ Play / interact for happiness        │
  │ Unlock rewards from step targets     │
  └──────────────────────────────────────┘
              │
              ▼
  BEDTIME (10pm-6am)
  ┌──────────────────────────────────────┐
  │ Lights dim → Dilder gets tired       │
  │ Place in dark → auto-sleep           │
  │ Low power mode                       │
  │ Stats decay slowly overnight         │
  │ Energy regenerates                   │
  └──────────────────────────────────────┘
```

---

# IV. The Physical World

## 9. Sensor Interactions

Dilder doesn't just live on a screen — it senses the real world around it.

### 9.1 Voice & Sound

The microphone (MAX9814) detects volume and patterns — not words (no speech recognition on the microcontroller):

| Sound | Detection | Effect |
|---|---|---|
| **Talking** (3+ seconds, moderate volume) | Sustained mid-level signal | +Intelligence, +Happiness |
| **Yelling** | High volume spike | Discipline (if misbehaving) or Scare |
| **Singing** | Rhythmic sustained pattern | +Happiness, special animation, contributes to Coral Dancer evolution |
| **Clapping** | Sharp spike then silence | Attention getter — Dilder looks at you |
| **Silence** (30+ minutes) | No signal above noise floor | Loneliness timer → Sad/Homesick |
| **Music** | Sustained varied signal | Chill mood boost |
| **Whispering** | Just above noise floor | Secret/intimate interaction, +Bond |

### 9.2 Light & Darkness

The BH1750 light sensor reads ambient light:

| Light Level | Lux | Effect |
|---|-----|---|
| **Bright daylight** | > 500 | Active mode, energy decay normal |
| **Indoor** | 100-500 | Standard operation |
| **Dim / Evening** | 10-100 | Dilder gets drowsy, starts yawning |
| **Dark** | < 10 | Sleep mode (if energy low) |
| **Sudden bright flash** | Delta > 300 in 5s | Startled reaction |
| **Dark but awake** | < 10 for 5+ min, energy > 50 | Scared / Homesick |

### 9.3 Temperature & Humidity

The AHT20 sensor reads the environment:

| Condition | Range | Effect |
|---|---|---|
| **Comfortable** | 18-24C, 40-60% RH | Chill mood bonus, 10% slower hygiene decay |
| **Too hot** | > 28C | Angry tendency, 30% faster hygiene decay |
| **Too cold** | < 15C | Sad tendency, huddle-up animation |
| **Very humid** | > 70% RH | Happy! (It's an octopus — it loves moisture) |
| **Very dry** | < 30% RH | Uncomfortable, "skin drying out" dialogue |
| **Temperature swing** | > 5C change in 10 min | Confused / Chaotic reaction |

### 9.4 Motion & Movement

The LIS2DH12TR accelerometer tracks:

| Motion | Detection | Effect |
|---|---|---|
| **Walking** | Hardware pedometer, 1-3 Hz | +Fitness, +Exploration XP |
| **Running** | Step frequency > 3 Hz | +Fitness (2x), Excited mood |
| **Stationary** (2+ hours) | No steps detected | Boredom → Lazy → Weird |
| **Picked up** | Orientation change | Alert — Dilder "wakes up" |
| **Shaking** | High-frequency irregular motion | Angry / Chaotic |
| **Dropping** | Free-fall detection | Scared reaction, health check |
| **Tilted > 45 degrees** | Sustained angle | Confused — "I'm sideways!" |

---

## 10. Step Tracking & Activity

### 10.1 Daily Step Targets

Every step you take with Dilder counts. Progressive daily goals unlock escalating rewards:

| Target | Steps | Reward | Dilder Says |
|---|---|---|---|
| **Bronze** | 2,000 | +10 XP, +5 happiness | "Nice walk! My tentacles feel stretchy." |
| **Silver** | 5,000 | +25 XP, +10 happiness, 1 snack | "Great job! We really covered some ground!" |
| **Gold** | 8,000 | +50 XP, +15 happiness, 20% cosmetic chance | "Wow! You're a machine!" |
| **Platinum** | 12,000 | +100 XP, +20 happiness, guaranteed cosmetic | "LEGENDARY! My fitness stat is through the ROOF!" |
| **Diamond** | 20,000 | +200 XP, full stat restore, rare cosmetic | "I didn't know legs could DO that. Respect." |

The step screen shows your progress:
```
┌──────────────────────────────────────┐
│  Today's Steps: 6,247                │
│  ██████████████░░░░░ 8,000 Gold      │
│                                      │
│  [check] Bronze  (2,000)             │
│  [check] Silver  (5,000)             │
│  [    ] Gold    (8,000) — 1,753 to go│
│  [    ] Platinum (12,000)            │
│  [    ] Diamond  (20,000)            │
└──────────────────────────────────────┘
```

### 10.2 Weekly Targets

Accumulate across the week (Monday–Sunday):

| Target | Steps | Reward |
|---|---|---|
| **Week Walker** | 10,000 | +50 XP, 3 snacks |
| **Week Runner** | 25,000 | +150 XP, random cosmetic, special dialogue |
| **Week Warrior** | 50,000 | +400 XP, rare cosmetic, +1 decor slot |
| **Week Legend** | 75,000 | +800 XP, legendary cosmetic, evolution XP bonus |
| **Week Titan** | 100,000+ | +1,500 XP, mythic reward, unique animation |

### 10.3 Monthly Targets

The "big goals" that drive long-term engagement:

| Target | Steps | Reward |
|---|---|---|
| **Monthly Mover** | 50,000 | +200 XP, monthly badge, 10% slower decay next month |
| **Monthly Marcher** | 100,000 | +500 XP, exclusive monthly cosmetic (unique per month!) |
| **Monthly Marathoner** | 200,000 | +1,200 XP, evolution accelerator, rare animation |
| **Monthly Monster** | 300,000 | +2,500 XP, legendary badge, permanent stat bonus |
| **Monthly Mythic** | 500,000+ | +5,000 XP, one-of-a-kind cosmetic, Hall of Fame |

**Monthly cosmetics are unique per calendar month.** Miss April's exclusive hat and it's gone forever.

### 10.4 The Streak System

Meet the Bronze daily target (2,000 steps) to keep your streak alive:

| Streak | Bonus |
|---|---|
| **3 days** | +25 XP, "Getting Started" badge |
| **7 days** | +100 XP, fire animation on step counter |
| **14 days** | +250 XP, happiness decay reduced 10% |
| **30 days** | +750 XP, exclusive cosmetic, bond boost |
| **60 days** | +2,000 XP, evolution guarantee (best path) |
| **90 days** | +5,000 XP, "Legendary Companion" title |
| **365 days** | +25,000 XP, "Eternal Bond" achievement |

**Streak protection:**
- **1 free miss per week** — Missing one day doesn't break the streak.
- **Streak freeze items** — Earned from treasure hunts. Allows 1 additional miss day.
- **Half-credit** — Walking 1,000-1,999 steps counts as a "half day." Two halves = one streak day.

---

## 11. Location & Exploration

Dilder detects your location using WiFi fingerprinting — it recognizes unique access points and builds a map of places you've been.

| Feature | Effect |
|---|---|
| **Home detection** | Dilder knows it's "home" — comfort bonus, no Homesick |
| **Away from home** | Adventure mode — +Exploration XP, but Homesick risk after 4 hours |
| **New location** | Discovery bonus! +25 XP, "Whoa, where are we?" dialogue |
| **Familiar location** | Nostalgic reaction, comfort |
| **Unique location count** | 5 locations → Explorer hat, 10 → ocean background, 25 → deep-sea animations |

---

# V. Growing Up

## 12. Life Stages

Your octopus grows through 6 stages over 30+ real days. Each stage changes its needs, available emotions, and personality.

### 12.1 Egg
**Duration:** Day 0-1

A wobbling egg on screen. No stats, no emotions. Just warmth, taps, and patience. Cracks appear at 25%, 50%, 75% progress. Hatches at 100%.

### 12.2 Hatchling
**Duration:** Day 1-3

A tiny octopus. Very needy — stat decay is **2x normal**. Limited emotions: Normal, Hungry, Tired, Sad, Excited. Cries every 3 minutes if hungry. Simple one-word dialogue: "mama?", "hungwy...", "*happy bubbles*"

4 misbehavior windows open during this stage for discipline.

### 12.3 Juvenile
**Duration:** Day 3-7

Growing and curious. Personality starts forming. Stat decay returns to 1.2x normal. Unlocks basic dialogue and the first decor slot. Adds Chill, Lazy, Angry, and Weird to the emotion set.

> "What's out there?" / "Are you my person?"

### 12.4 Adolescent
**Duration:** Day 7-14

Moody, unpredictable, tests boundaries. All 16 emotions now available. Full dialogue unlocked. Mini-games available. Rebellion events increase. Stat decay at normal rate.

> "Whatever." / "You don't understand me." / "Leave me alone... wait, don't."

### 12.5 Adult
**Duration:** Day 14-30

The big moment — **evolution**. Dilder's accumulated stats determine which of 6 adult forms it becomes. Stable personality, full feature access, all decor available. Stat decay at 0.75x (more self-sufficient).

### 12.6 Elder
**Duration:** Day 30+

Slower stat decay (0.6x), wiser dialogue, nostalgic and reflective personality. Unique elder-only animations and quotes. Eventually: the rebirth option.

> "My tentacles may be slower, but my hearts are fuller."

---

## 13. Evolution — The Six Adult Forms

At day 14, your care pattern across the first two weeks crystallizes into one of 6 adult forms. This is **deterministic** — the same inputs always produce the same result. Your choices have consequences.

All outfits grid

### 13.1 Deep-Sea Scholar
**Requirements:** High intelligence + high bond + moderate discipline

Glasses, a book, a contemplative pose. Philosophical, verbose quotes. The intellectual octopus.

> "The question isn't whether we're alone in the ocean. It's whether we'd recognize company if it arrived."

**How to evolve:** Talk to Dilder constantly (mic input), maintain high bond through consistent care, keep discipline moderate through correct scolding.

### 13.2 Reef Guardian
**Requirements:** High fitness + high exploration + balanced stats

Muscular tentacles, a coral crown. Adventurous and encouraging.

> "Let's see what's over the next hill. And the one after that."

**How to evolve:** Walk a LOT (high step counts daily), visit many unique locations, keep all stats balanced without extremes.

### 13.3 Tidal Trickster
**Requirements:** Low discipline + high happiness + chaotic care pattern

Jester hat, mischievous grin. Chaotic, unpredictable, hilarious.

> "Rules are just suggestions written by people with no imagination."

**How to evolve:** Keep happiness high, ignore discipline windows, care unpredictably (sometimes neglect, sometimes smother).

### 13.4 Abyssal Hermit
**Requirements:** High discipline + low social interaction + self-sufficient

A cloak, dim eyes, stoic presence. Rare but profound dialogue.

> "..."
> (Abyssal Hermit speaks only when it matters.)

**How to evolve:** High discipline through correct scolding, but low total interactions. Feed and maintain, but don't overindulge in play.

### 13.5 Coral Dancer
**Requirements:** High happiness + lots of music/singing exposure + creative

Flowing ribbons, graceful animations. Artistic and poetic.

> "Every ripple in the water is a note in a song only the ocean knows."

**How to evolve:** Play music near Dilder often, sing to it (the mic detects rhythmic patterns), keep happiness consistently high.

### 13.6 Storm Kraken
**Requirements:** Lots of scolding + high anger exposure + survived

Larger body, intimidating visual, powerful presence. Tough but loyal.

> "You think that's a storm? I've BEEN a storm."

**How to evolve:** Scold frequently (both correct and incorrect), expose to loud noises and shaking, but keep it alive. The Storm Kraken is forged through adversity.

---

## 14. Rebirth & Legacy

After day 30 (Elder stage), you can choose:

- **Continue:** Dilder lives on as an Elder, slowly accumulating wisdom.
- **Rebirth:** Dilder lays an egg. A new life begins.

**The new Dilder inherits:**
- 10% of parent's Bond XP (a head start)
- One decor item from the parent
- A heritage trait that slightly biases evolution toward the parent's form
- A memorial entry viewable in the Stats menu

This creates generational lineage: "My 3rd-generation Deep-Sea Scholar, descended from a Storm Kraken."

---

# VI. Progression & Collection

## 15. Bond Levels

Every interaction earns Bond XP. Your bond level determines which features are available:

| Level | Name | XP | Unlocks |
|---|---|-----|---|
| 1 | **Stranger** | 0 | Basic feeding, minimal dialogue |
| 2 | **Acquaintance** | 100 | Tap response, more expressions |
| 3 | **Companion** | 500 | Dialogue options, 1st decor slot |
| 4 | **Friend** | 1,500 | Mini-games, nickname, treats |
| 5 | **Best Friend** | 4,000 | Full dialogue tree, 3 decor slots |
| 6 | **Soulmate** | 10,000 | Secret dialogue, all decor, special animations |
| 7 | **Bonded** | 25,000 | Dilder initiates conversation, remembers things |
| 8 | **Legendary** | 50,000+ | Everything unlocked, elder wisdom mode |

---

## 16. The Dialogue System

Dilder's vocabulary grows with intelligence and life stage:

| Intelligence | Complexity |
|---|---|
| 0-20 | Simple phrases, emotes, sound effects |
| 20-40 | Full sentences, basic opinions |
| 40-60 | Multi-sentence responses, asks YOU questions |
| 60-80 | References past events, humor, preferences |
| 80-100 | Philosophy, complex emotion, behavioral callbacks |

At Bond level 7 (Bonded), Dilder **initiates conversation** — you don't have to prompt it. It will comment on the weather, recall things you've done together, or just say hello.

---

## 17. Decor & Cosmetics

4 equip slots for customizing your octopus:

### 17.1 Hats & Headwear
Bow, crown, glasses, explorer hat, jester hat, coral crown, birthday hat, moon hat, and more. Unlocked through achievements and bond levels.

### 17.2 Backgrounds & Environments
Ocean floor, coral reef, deep sea, city skyline, cozy room, starry night. Unlocked through exploration milestones.

All environments

### 17.3 Accessories
Scarf (appears in cold weather), sunglasses (bright environments), book (high intelligence). Unlocked through stat thresholds.

### 17.4 Animation Styles
Calm sway, energetic bounce, lazy slouch, regal float. Unlocked through life stage + personality.

All decor props

---

## 18. Treasure Hunts

When GPS is active, Dilder generates treasure hunts — virtual gifts placed at real-world coordinates within walking distance.

**How it works:**
1. A treasure spawns 100m-1km from your current position
2. The screen switches to compass mode with a bearing arrow and distance readout
3. Walk toward the target — Dilder gives proximity hints
4. Within 15 meters — "HERE! Look around!" — press SELECT to collect
5. Reward revealed with a gift box animation

**Treasure types:**

| Type | Rarity | Reward |
|---|---|---|
| **Snack Crate** | Common (60%) | Food item, +hunger, +happiness |
| **Cosmetic Shell** | Uncommon (25%) | Random decor item |
| **Memory Fragment** | Rare (10%) | Lore piece, unlocks special dialogue |
| **Golden Pearl** | Legendary (5%) | +500 XP or rare evolution modifier |
| **Elder Relic** | Mythic (<1%) | Unique one-of-a-kind cosmetic |

Treasures expire after 24 hours if uncollected.

---

# VII. Achievements

## 19. Achievement System Overview

Achievements are one-time milestones that reward XP, cosmetics, and bragging rights. They're divided into 6 categories. Some are obvious; others require creative play to discover.

The achievement screen shows unlocked badges with descriptions. Locked achievements show "???" until you uncover them.

---

## 20. Care Achievements

| Achievement | Condition | Reward |
|---|---|---|
| **First Meal** | Feed Dilder for the first time | +10 XP, snack item |
| **Full Course** | Use all 3 food types in one session | +25 XP |
| **Perfect Day** | No care mistakes for 24 hours | +100 XP |
| **Week of Love** | 7-day care streak | +200 XP, heart animation |
| **Month of Devotion** | 30-day care streak | +750 XP, rare decor set |
| **Nurse** | Administer medicine 3 times | +50 XP |
| **Master Caretaker** | Maintain all stats >50 for 24 hours straight | +150 XP |
| **Overachiever** | Maintain all stats >80 for 8 hours | +300 XP |
| **Spotless** | Clean when hygiene is already >90 | +10 XP ("I wasn't even dirty!") |
| **Helicopter Parent** | Interact 50+ times in one day | +100 XP |

---

## 21. Exploration Achievements

| Achievement | Condition | Reward |
|---|---|---|
| **First Steps** | Walk 100 steps with Dilder | +10 XP, step counter display |
| **Morning Walk** | Complete Bronze target before 8 AM | +25 XP |
| **Neighborhood Explorer** | Visit 5 unique locations | +50 XP, Explorer hat |
| **City Mapper** | Visit 25 unique locations | +200 XP, map background |
| **Globetrotter** | Visit 50 unique locations | +500 XP, globe accessory |
| **Marathon** | 42,195 steps in one day | +500 XP, running animation |
| **Homecoming** | Return home after 8+ hours away | +30 XP |
| **Night Walker** | Walk 1,000+ steps between midnight and 5 AM | +50 XP |
| **7-Day Explorer** | Visit a new location every day for 7 days | +300 XP |

---

## 22. Social Achievements

| Achievement | Condition | Reward |
|---|---|---|
| **First Words** | Talk to Dilder via mic for 10 seconds | +10 XP, dialogue unlock |
| **Storyteller** | 100 cumulative minutes of mic activity | +200 XP, complex dialogue |
| **Loud and Proud** | Yell at Dilder (intentionally) | +25 XP, angry response set |
| **Whisper Secret** | Low-volume mic input for 30 seconds | +50 XP, secret dialogue |
| **Serenade** | Singing detected for 60 seconds total | +100 XP, music animation |
| **DJ Dilder** | Music detected for 30 minutes total | +150 XP, chill mode cosmetic |
| **Silence is Golden** | No mic input for 8 hours (during waking) | +30 XP ("You okay?") |
| **Motivational Speaker** | Talk for 5 minutes continuously | +100 XP |

---

## 23. Environmental Achievements

| Achievement | Condition | Reward |
|---|---|---|
| **Night Owl** | Keep Dilder awake past midnight | +25 XP, unique tired dialogue |
| **Early Bird** | Interact before 6 AM | +25 XP, special morning greeting |
| **Weather Friend** | Experience rain while carrying Dilder (humidity spike) | +50 XP, happy dance animation |
| **Cozy Keeper** | Maintain optimal temp/humidity for 8 hours | +100 XP, comfort decor |
| **Sauna Mode** | Expose to >30C for 30 minutes | +30 XP ("I'm MELTING") |
| **Arctic Explorer** | Expose to <10C for 30 minutes | +30 XP, shiver animation |
| **Darkness Dweller** | Keep in darkness for 4 hours while energy is full | +50 XP |
| **Flash Bang** | Trigger a sudden bright light startle 5 times | +25 XP |

---

## 24. Mastery Achievements

| Achievement | Condition | Reward |
|---|---|---|
| **All Emotions** | Witness all 16 emotional states | +300 XP, emotion gallery |
| **Disciplinarian** | Reach 100% discipline in one life stage | +200 XP, evolution bonus |
| **Zen Master** | All stats >60 for 72 consecutive hours | +500 XP, Chill mode |
| **Chaos Agent** | Trigger Chaotic + Unhinged + Weird in one day | +200 XP, special quote set |
| **Full Wardrobe** | Unlock 20 different decor items | +300 XP |
| **Polyglot** | Unlock maximum intelligence (100) dialogue | +400 XP |
| **All Forms** | Evolve into all 6 adult forms (across generations) | +1,000 XP, master badge |
| **Elder Wisdom** | Reach Elder stage | +500 XP, elder dialogue set |
| **Generational** | Complete 3 rebirth cycles | +750 XP, heritage cosmetic |
| **Completionist** | Unlock 50 achievements | +2,000 XP, golden frame |

---

## 25. Step Achievements

| Achievement | Condition | Reward |
|---|---|---|
| **Bronze Walker** | First Bronze daily target (2,000) | +10 XP |
| **Silver Strider** | First Silver daily target (5,000) | +25 XP |
| **Gold Crusher** | First Gold daily target (8,000) | +50 XP |
| **Platinum Pacer** | First Platinum daily target (12,000) | +100 XP |
| **Diamond Destroyer** | First Diamond daily target (20,000) | +200 XP, rare cosmetic |
| **Week Titan** | 100,000 steps in one week | +1,500 XP, unique animation |
| **Monthly Mythic** | 500,000 steps in one month | +5,000 XP, Hall of Fame |
| **Million Steps** | 1,000,000 lifetime steps | +3,000 XP, legendary badge |
| **Streak Master** | 90-day consecutive streak | +5,000 XP, "Legendary Companion" |
| **Eternal Bond** | 365-day consecutive streak | +25,000 XP, ultimate achievement |

---

## 26. Secret Achievements

These are hidden — they only appear after you discover them.

| Achievement | Hint | Reward |
|---|---|---|
| **???** | Do something at exactly midnight on New Year's | +500 XP |
| **???** | Trigger all 16 emotions in a single 24-hour period | +1,000 XP |
| **???** | Have Dilder refuse to eat 5 times in a row | +50 XP |
| **???** | Reach Bond level 8 without ever scolding | +500 XP |
| **???** | Find an Elder Relic treasure | +2,000 XP |
| **???** | Keep Dilder at exactly 100 weight for 24 hours | +100 XP |
| **???** | Pet the back zone for 60 consecutive seconds | +75 XP |
| **???** | Play music for Dilder for 2 hours cumulative | +200 XP |

*There are more secrets. Keep exploring.*

---

# VIII. Environments & Scenes

## 27. The 22 Environments

Dilder's world extends beyond the octopus itself. Unlockable environments change the background behind your pet:

All environments grid

**Ocean Environments:** Shallow reef, coral garden, deep sea trench, kelp forest, open ocean, volcanic vent, arctic waters, mangrove lagoon, sunken ship.

**Land-Inspired:** City skyline, cozy room, park, library, mountain peak.

**Atmospheric:** Starry night, sunset, aurora, thunderstorm, fog, moonlit tide.

**Special:** The Armchair (Jamal's home — unlocked at Bond level 8).

Each environment has unique visual elements rendered in the 250x122 e-ink display using dither patterns for depth.

---

## 28. Outfits & Decor Props

All outfits grid

**40 outfits** across headwear, bodywear, eyewear, and accessories. From pirate hats to graduation caps, from scarves to bow ties. Mix and match across 4 equip slots.

**29 decor props** for scene composition — furniture, food items, weather effects, plants, and electronics that appear in the scene with your octopus.

All decor props

---

## 29. Aura & Particle Effects

Each emotion has a unique aura — particle effects that emanate from the octopus:

Emotions with auras

- **Normal:** Gentle floating dots
- **Angry:** Sharp jagged sparks
- **Sad:** Falling tear drops
- **Excited:** Exploding star bursts
- **Chill:** Slow drifting waves
- **Chaotic:** Random scattered debris
- **Hungry:** Rising food particles
- **Horny:** Floating hearts
- **Homesick:** Swirling fog wisps

---

# IX. Controls & Navigation

## 30. Button Layout

```
    [UP]

[BACK]  [SELECT]  [ACTION]

    [DOWN]
```

| Button | Short Press | Long Press (2s) | Double Press |
|---|---|---|---|
| **SELECT** | Confirm / dismiss dialogue | Open menu | — |
| **BACK** | Cancel / go back | Toggle backlight | — |
| **UP** | Scroll up | — | — |
| **DOWN** | Scroll down | — | — |
| **ACTION** | Context action (feed/pet) | Scold | Quick status view |

---

## 31. Menu System

Long-press SELECT to open:

```
Main Menu
├── Feed
│   ├── Meal (+30 hunger, +1 weight)
│   ├── Snack (+10 hunger, +15 happiness, +2 weight)
│   └── Treat (+5 hunger, +25 happiness, +3 weight) [Bond 4+]
├── Play
│   ├── Mini-game (+20 happiness, -10 energy, -1 weight)
│   └── Tickle (+5 happiness, quick)
├── Care
│   ├── Clean (+40 hygiene)
│   ├── Medicine (+20 health) [Only when sick]
│   └── Light (sleep toggle)
├── Stats
│   ├── Health meters (all 5 bars)
│   ├── Bond level & XP progress
│   ├── Today's activity (steps, distance)
│   ├── Achievements
│   └── Memorial (rebirth history)
├── Decor [Bond 3+]
│   ├── Hats
│   ├── Backgrounds
│   ├── Accessories
│   └── Animation Styles
└── Settings
    ├── Sound (beeper on/off)
    ├── Time display
    └── Brightness
```

---

## 32. Quick Actions

Without opening the menu:
- **Short press ACTION:** Context-sensitive care — feeds if hungry, pets otherwise
- **Double press ACTION:** Quick stats overlay (disappears after 5 seconds)
- **Tap the device:** Accelerometer detects taps for interaction
- **Talk to Dilder:** Automatic — mic always listening

---

# X. Tips & Secrets

## 33. Beginner Tips

1. **Check in morning and evening.** Stat decay overnight is real — a quick feed and pet in the morning sets up a good day.
2. **Walk with Dilder.** Steps are the single biggest source of progression. 2,000 per day is the minimum to keep the streak alive.
3. **Don't overfeed.** Meals fill hunger efficiently. Snacks are for happiness. Treats are rare — save them for bad days.
4. **Let it sleep.** Place Dilder in a dark spot at night. Energy regenerates fully in under an hour, and sleep decay is 4x slower.
5. **Talk to it.** Intelligence grows from mic input. Higher intelligence unlocks richer dialogue and contributes to the Deep-Sea Scholar evolution.
6. **Don't panic at critical stats.** Recovery is fast — 2-3 care actions bring any stat back from the brink. Dilder forgives quickly.

## 34. Advanced Strategies

- **Evolution targeting:** If you want a specific adult form, focus on its key stats from day 1. The first 14 days are the evolution window.
- **Streak freeze hoarding:** Save freeze items from treasure hunts for vacations or sick days.
- **Weight management:** Alternate meals with mini-games. The ideal weight is 90-110.
- **Discipline timing:** You get exactly 4 misbehavior windows per life stage. Don't miss them — discipline is hard to raise otherwise.
- **Music exposure:** Play music near Dilder regularly if targeting Coral Dancer evolution. The mic detects sustained rhythmic patterns.
- **Exploration grinding:** Visit coffee shops, libraries, parks — any unique WiFi access point counts as a new location.

## 35. Easter Eggs & Hidden Features

- Pet the **back zone** for a full 60 seconds for a special reaction.
- Reach Bond level 7 and Dilder will occasionally start conversations on its own.
- The Weird emotion has a **5% random chance** per tick when Dilder is bored. It's one of the rarest natural states.
- Elder Dilder has a unique dialogue set not available to any other life stage. Some quotes are callbacks to things that happened during your specific playthrough.
- After rebirth, the new Dilder's heritage form slightly biases evolution. A Scholar's child is more likely to become a Scholar — but not guaranteed.
- There are achievements that only appear after you discover them. No hints in the UI. Experiment.

---

*This guide covers all planned features of Dilder. The game is designed to be discovered — not every mechanic is explained here. Pay attention to what Dilder says. It's trying to tell you something.*

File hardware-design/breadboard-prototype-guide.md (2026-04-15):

# Breadboard Prototype Guide — ESP32-S3

How to build a Dilder prototype on breadboard using off-the-shelf parts that match the custom PCB design. Also covers compact "alpha board" options for real-world testing.

---

## Table of Contents

- [Dev Board Comparison](#dev-board-comparison)
- [Recommended Breadboard Parts List](#recommended-breadboard-parts-list)
- [GPIO Wiring Map](#gpio-wiring-map)
- [Shopping List by Retailer (Germany)](#shopping-list-by-retailer-germany)
- [Amazon Shopping List (US/DE)](#amazon-shopping-list-usde)
- [Compact Alpha Board — No Breadboard](#compact-alpha-board--no-breadboard)
  - [Option A: Feather Stack](#option-a-feather-stack-recommended)
  - [Option B: Protoboard Solder Build](#option-b-protoboard-solder-build)
  - [Option C: 3D-Printed Bracket](#option-c-3d-printed-bracket)
- [Key Notes and Gotchas](#key-notes-and-gotchas)

---

## Dev Board Comparison

Pick one. All have ESP32-S3 and enough GPIO for the full Dilder circuit.

| Board | Price | Flash/PSRAM | Battery Charging | USB | GPIO | Best For |
|---|---|---|---|-----|---|---|
| **Olimex ESP32-S3-DevKit-Lipo** | **7.95 EUR** | 8MB/8MB | **Yes** (built-in) | Dual USB-C | 45 | Best value, skip TP4056 |
| Waveshare ESP32-S3 N8R8 | 10.50 EUR | 8MB/8MB | No | USB-C | 36 | Cheap, widely stocked |
| Generic N16R8 DevKitC | 8-14 EUR | **16MB/8MB** | No | USB-C | 36 | Exact PCB silicon match |
| **UM FeatherS3** | **28.98 EUR** | **16MB/8MB** | **Yes** (JST + fuel gauge) | USB-C | 21 | Feather ecosystem, cleanest |
| Adafruit ESP32-S3 Feather | 22.96 EUR | 4MB/2MB | **Yes** | USB-C | 20 | Budget Feather option |
| SparkFun Thing Plus S3 | 25-30 EUR | 4MB/2MB | **Yes** (+ microSD) | USB-C | 21 | If you want SD card |
| Seeed XIAO ESP32S3 | 7.50 EUR | 8MB/8MB | Yes | USB-C | **11** | **NOT ENOUGH GPIO** |

### Recommendations

**Budget pick:** Olimex ESP32-S3-DevKit-Lipo (7.95 EUR) — has LiPo charging built in, eliminating the TP4056 module. Open-source hardware. Ships from Bulgaria (3-7 days to Germany).

**Best match to PCB:** Generic N16R8 DevKitC (10-14 EUR on Amazon/Botland) — exact same ESP32-S3-WROOM-1-N16R8 module as the custom PCB. Needs separate TP4056 for battery.

**Cleanest prototype:** Unexpected Maker FeatherS3 (28.98 EUR at exp-tech.de) — Feather ecosystem lets you stack the eInk FeatherWing directly. Battery charging, STEMMA QT I2C, exact 16MB/8MB match.

---

## Recommended Breadboard Parts List

| # | Component | Purpose | Est. Price | Notes |
|---|---|---|---|---|
| 1 | **ESP32-S3 dev board** | Main MCU | 8-29 EUR | See comparison above |
| 2 | **Waveshare 2.13" e-Paper** (V4, SSD1680) | Display | 8-18 EUR | Use 8-pin breakout header with F-M jumper wires |
| 3 | **Adafruit LIS3DH breakout** | Accelerometer | 5-6 EUR | LIS3DH is I2C/SPI compatible substitute for LIS2DH12 (bare LIS2DH12 breakouts are discontinued) |
| 4 | **5-way navigation joystick** | Input | 2-8 EUR | Through-hole module; Adafruit ADA504 or DollaTek 5-way |
| 5 | **LiPo battery** (1000-1200mAh, JST PH 2.0mm) | Power | 6-10 EUR | Verify polarity matches your dev board |
| 6 | **TP4056 USB-C module** | Battery charging | 1.40-5.50 EUR | **Skip if dev board has charging** (Olimex, FeatherS3) |
| 7 | **Full-size breadboard** (830 points) | Prototyping platform | 4-8 EUR | Half-size is too small |
| 8 | **Jumper wire kit** (M-M + F-M) | Wiring | 4-8 EUR | Need ~15 M-M, ~10 F-M for display header |
| 9 | **2x 10k resistors** | I2C pull-ups | <1 EUR | Skip if accel breakout has onboard pull-ups |

**Total estimate:** 40-85 EUR depending on dev board choice and what you already have.

---

## GPIO Wiring Map

Same pin assignments as the custom PCB — firmware ports directly.

```
ESP32-S3 GPIO  →  Component            →  Breakout Wire
─────────────────────────────────────────────────────────
GPIO3          →  e-Paper DC            →  Display pin 6
GPIO4          →  Joystick UP           →  Joystick UP
GPIO5          →  Joystick DOWN         →  Joystick DOWN
GPIO6          →  Joystick LEFT         →  Joystick LEFT
GPIO7          →  Joystick RIGHT        →  Joystick RIGHT
GPIO8          →  Joystick CENTER       →  Joystick CENTER
GPIO9          →  e-Paper CLK (SCK)     →  Display pin 4
GPIO10         →  e-Paper MOSI (DIN)    →  Display pin 3
GPIO11         →  e-Paper RST           →  Display pin 7
GPIO12         →  e-Paper BUSY          →  Display pin 8
GPIO16         →  Accelerometer SDA     →  Accel SDA
GPIO17         →  Accelerometer SCL     →  Accel SCL
GPIO46         →  e-Paper CS            →  Display pin 5
3V3            →  All VCC lines         →  Display pin 1 + Accel VDD
GND            →  All GND lines         →  Display pin 2 + Accel GND + Joystick COM
```

**Joystick:** Common pin to GND. Each direction pin to its GPIO. Enable internal pull-ups in software.

**Accelerometer:** I2C address 0x18 (SA0/SDO to GND). 10k pull-ups on SDA/SCL to 3.3V (skip if breakout has them).

---

## Shopping List by Retailer (Germany)

Optimized for fast delivery (1-5 business days) and fewest separate orders.

### Option 1: Budget Build (~43 EUR, 3 orders)

**Botland.store** (ships in 24h from Poland/Germany)

| Item | Price |
|---|---|
| Waveshare ESP32-S3-DEV-KIT-N8R8 | 10.50 EUR |

**Eckstein-shop.de** (1-3 workdays, Germany)

| Item | Price |
|---|---|
| Adafruit LIS3DH accelerometer breakout | 5.89 EUR |
| V-TEC LiPo 1200mAh JST-PH | 6.97 EUR |
| Waveshare 2.13" e-Paper raw panel | 8.32 EUR |

**BerryBase.de** (1-3 workdays, Germany)

| Item | Price |
|---|---|
| Adafruit 5-way navigation joystick (ADA504) | 1.90 EUR |
| TC4056A USB-C LiPo charger board | 1.40 EUR |

**Total: ~35 EUR** + shipping (~5-10 EUR across 3 orders)

You'll also need a breadboard and jumper wires if you don't already have them.

### Option 2: Olimex Build (~38 EUR, 2 orders, no TP4056 needed)

**Olimex.com** (3-7 days from Bulgaria)

| Item | Price |
|---|---|
| ESP32-S3-DevKit-Lipo | 7.95 EUR |

**Eckstein-shop.de** (1-3 workdays)

| Item | Price |
|---|---|
| Adafruit LIS3DH breakout | 5.89 EUR |
| V-TEC LiPo 1200mAh JST-PH | 6.97 EUR |
| Waveshare 2.13" e-Paper raw panel | 8.32 EUR |
| Breadboard + jumper wire kit | ~8 EUR |

**BerryBase.de**

| Item | Price |
|---|---|
| 5-way navigation joystick | 1.90 EUR |

**Total: ~39 EUR** + shipping. No TP4056 needed — Olimex board charges the LiPo directly via USB-C.

### Option 3: Premium Feather Build (~80 EUR, 1-2 orders)

**EXP-Tech.de** (ships from Germany)

| Item | Price |
|---|---|
| Unexpected Maker FeatherS3 | 28.98 EUR |
| Adafruit 2.13" eInk FeatherWing | 22.50 EUR |
| Adafruit LIS3DH breakout | 4.90 EUR |
| Stacking headers (for FeatherWing) | ~2 EUR |

**BerryBase.de**

| Item | Price |
|---|---|
| 5-way navigation joystick | 1.90 EUR |
| LiPo 1200mAh JST-PH | 5.50 EUR (if in stock) |

**Total: ~66 EUR** + shipping. Cleanest setup — eInk display plugs directly onto the Feather. Battery charging built in. No breadboard needed for core stack.

---

## Amazon Shopping List (US/DE)

For one-stop Amazon ordering (all Prime-eligible where noted):

### Amazon.de (Germany)

| Item | Search Term | Est. Price |
|---|---|---|
| ESP32-S3 N16R8 DevKitC | "ESP32-S3 N16R8 development board" | 10-15 EUR |
| Waveshare 2.13" e-Paper | "Waveshare 2.13 e-paper HAT" | 15-20 EUR |
| TP4056 USB-C (5-pack) | "AZ-Delivery TP4056 USB-C" | 8.99 EUR |
| DollaTek 5-way joystick (5-pack) | "DollaTek 5-way navigation" or B07HBPW3DF | 8.17 EUR |
| LiPo 1000mAh JST PH | "3.7V 1000mAh LiPo JST PH" | 8-12 EUR |
| Breadboard + jumper kit | "Breadboard 830 Jumper Wire Set" | 8-12 EUR |
| 10k resistors (100-pack) | "10k Ohm 1/4W resistor" | 2-3 EUR |

**Amazon.de total: ~60-80 EUR** (all Prime, 1-2 day delivery)

**Note:** LIS3DH/LIS2DH12 breakout boards are hard to find on Amazon.de. Order the Adafruit LIS3DH from eckstein-shop.de or exp-tech.de instead.

### Amazon.com (US)

| Item | Link/Search | Est. Price |
|---|---|---|
| HiLetgo ESP32-S3 N16R8 | "HiLetgo ESP32-S3-DevKitC-1-N16R8" | $10-14 |
| Waveshare 2.13" e-Paper | B071S8HT76 | $15-20 |
| NOYITO LIS2DH12 breakout | "NOYITO LIS2DH12TR" or B07HFSMQNC | $6-10 |
| NOYITO 5-way joystick | "NOYITO 5-way tactile switch" or B07G4266RP | $7-9 |
| HiLetgo TP4056 USB-C (5-pack) | B07PKND8KG | $7-9 |
| LiPo 1000mAh JST PH | "1000mAh LiPo JST PH" B09F9VK77V | $8-12 |
| Breadboard + wire kit | "830 breadboard jumper wire kit" | $8-12 |

**Amazon.com total: ~$60-85**

---

## Compact Alpha Board — No Breadboard

For carrying around and real-world testing, here are three approaches from simplest to most polished.

### Option A: Feather Stack (Recommended)

The cleanest path to a pocketable prototype:

```
    ┌─────────────────────────┐
    │   2.13" eInk Display    │  ← Adafruit eInk FeatherWing
    │   (250 x 122 pixels)    │
    ├─────────────────────────┤
    │    Stacking Headers     │  ← $1.50, plug-in, no soldering
    ├─────────────────────────┤
    │   FeatherS3 (ESP32-S3)  │  ← USB-C, LiPo charging, 16MB/8MB
    ├─────────────────────────┤
    │   1000mAh LiPo Battery  │  ← JST PH connector, sandwiched behind
    └─────────────────────────┘
    
    + LIS3DH accelerometer wired to STEMMA QT / I2C
    + 5-way joystick wired to GPIO and mounted on side
```

**Size:** ~65 x 28 x 20mm (slightly larger than the 45x80mm PCB but much thinner than a breadboard)

**Cost:** ~70-85 EUR

**Pros:** No soldering for the core stack. Display plugs in. Battery charges via USB-C. Same SSD1680 display driver as the custom PCB — firmware ports directly.

**Cons:** Joystick needs to be wired separately and mounted externally. Accelerometer hangs off I2C wires.

### Option B: Protoboard Solder Build

For maximum compactness matching the final PCB:

1. Get a **50x80mm protoboard** (double-sided, through-hole, ~2 EUR for 10-pack)
2. Solder the ESP32-S3 dev board with pin headers
3. Wire all peripherals with 30 AWG wire-wrap wire on the back side
4. Mount e-paper display on front with double-sided tape or standoffs
5. Mount battery on back with foam tape
6. Solder joystick module directly to board in thumb-accessible position

**Size:** ~50 x 80 x 15mm — very close to the 45x80mm PCB target

**Cost:** ~40-50 EUR (cheapest option overall)

**Pros:** Most compact. Closest to final form factor. Permanent connections (no wires falling out).

**Cons:** Requires soldering. Harder to modify. Takes 2-3 hours to build.

### Option C: 3D-Printed Bracket

Works with any wiring approach. Print a frame that holds everything together:

```
    ┌────────────────────────────────┐
    │  ┌──────────────────────────┐  │
    │  │    e-Paper Display       │  │  ← Window cutout
    │  └──────────────────────────┘  │
    │                                │
    │  [▲]                           │  ← Joystick access hole
    │ [◄●►]                          │
    │  [▼]                           │
    │                                │
    │         [USB-C port]           │  ← Cutout for charging
    └────────────────────────────────┘
    
    Inside: Dev board, battery, accelerometer
    secured with M2 screws or friction fit
```

**Target dimensions:** 55 x 85 x 25mm

**Print cost:** 3-5 EUR via JLC3DP or local printer (PLA, 20% infill)

**Design time:** 2-4 hours in Fusion 360 or TinkerCAD. Start from existing ESP32 case models on Printables/MakerWorld and modify.

---

## Key Notes and Gotchas

1. **LIS3DH vs LIS2DH12:** For breadboarding, use the **Adafruit LIS3DH breakout** — the LIS2DH12 bare IC is a 2x2mm LGA-12 package that cannot be breadboarded, and SparkFun's breakout is discontinued. The LIS3DH is register-compatible and has the same I2C interface. The custom PCB will use the LIS2DH12TR bare IC.

2. **Battery polarity:** JST PH connectors have NO universal polarity standard. Always verify with a multimeter before connecting. Reversed polarity will destroy the charger IC and possibly the ESP32.

3. **Display version:** Make sure you get the Waveshare 2.13" **V4** (SSD1680 driver). Older V2/V3 versions use different drivers and need different firmware.

4. **GPIO46 quirk:** On some ESP32-S3 variants, GPIO46 is a strapping pin (affects boot mode). If you have issues with CS on GPIO46, try GPIO47 or another free pin during prototyping.

5. **Breadboard width:** The standard ESP32-S3 DevKitC is wide enough to cover both sides of a standard breadboard. Use the center channel, but you'll need to use jumper wires to access pins on the covered side. A wide breadboard (630+ points) helps.

6. **Power:** During prototyping, power via USB-C. Only connect the LiPo battery once you've verified all wiring is correct. A short circuit with a LiPo can cause fire.

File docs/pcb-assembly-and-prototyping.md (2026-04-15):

# PCB Assembly & Board Prototyping — Pricing, Providers, and Open-Source Reference Designs

> Comprehensive research on manufacturing the Dilder custom PCB: provider comparison, assembly pricing breakdown, cost estimates, and open-source hardware designs that can serve as reference or starting points.

**Board spec:** ESP32-S3-WROOM-1-N16R8, 4-layer, 45x80mm, ~27 components, SPI e-ink display, 5-way joystick, MPU-6050 IMU, TP4056 LiPo charger, USB-C.

---

## Table of Contents

- [Visual BOM — Component Gallery](#visual-bom--component-gallery)

1. [Provider Comparison](#1-provider-comparison)
2. [JLCPCB — Detailed Pricing Breakdown](#2-jlcpcb--detailed-pricing-breakdown)
3. [PCBWay — Detailed Pricing Breakdown](#3-pcbway--detailed-pricing-breakdown)
4. [OSH Park — Detailed Pricing Breakdown](#4-osh-park--detailed-pricing-breakdown)
5. [Aisler — Detailed Pricing Breakdown](#5-aisler--detailed-pricing-breakdown)
6. [Seeed Studio Fusion — Detailed Pricing Breakdown](#6-seeed-studio-fusion--detailed-pricing-breakdown)
7. [Cost Estimates for the Dilder Board](#7-cost-estimates-for-the-dilder-board)
8. [Open-Source Reference Designs](#8-open-source-reference-designs)
9. [Recommended Manufacturing Path](#9-recommended-manufacturing-path)
10. [Sources](#10-sources)

---

## Visual BOM — Component Gallery

Every component on the Dilder board, with LCSC part numbers and per-unit pricing at qty 5. Images sourced from [LCSC](https://www.lcsc.com/).

### Core MCU

<figure>
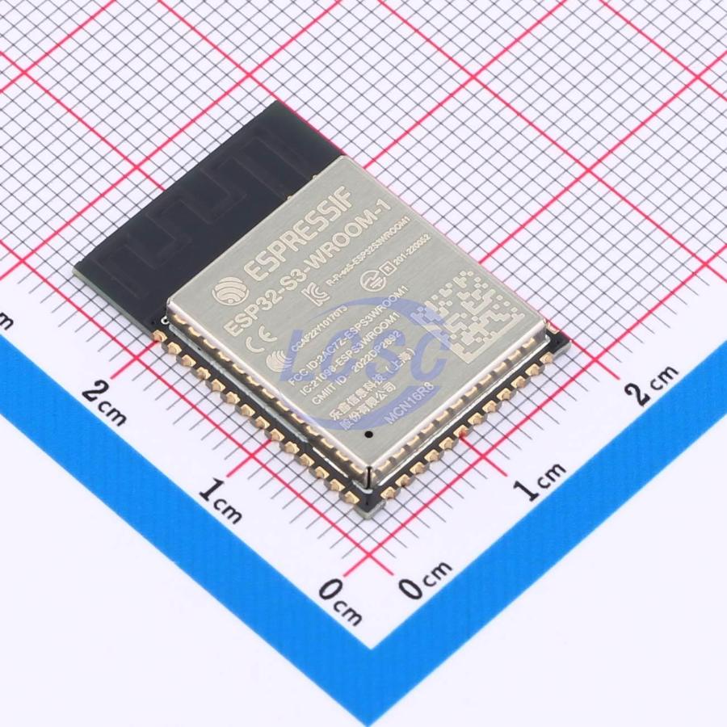
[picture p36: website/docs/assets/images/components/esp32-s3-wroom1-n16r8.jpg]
  
  <figcaption><strong>U1 — ESP32-S3-WROOM-1-N16R8</strong><br/>Dual-core Xtensa LX7 @ 240MHz, 512KB SRAM, 16MB flash, 8MB PSRAM, WiFi + BLE 5.0<br/>18×25.5mm module · <a href="https://www.lcsc.com/product-detail/C2913202.html">LCSC C2913202</a> · <strong>~$2.80</strong></figcaption>
</figure>

### Power Management

<table>
<tr>
<td align="center" width="25%">
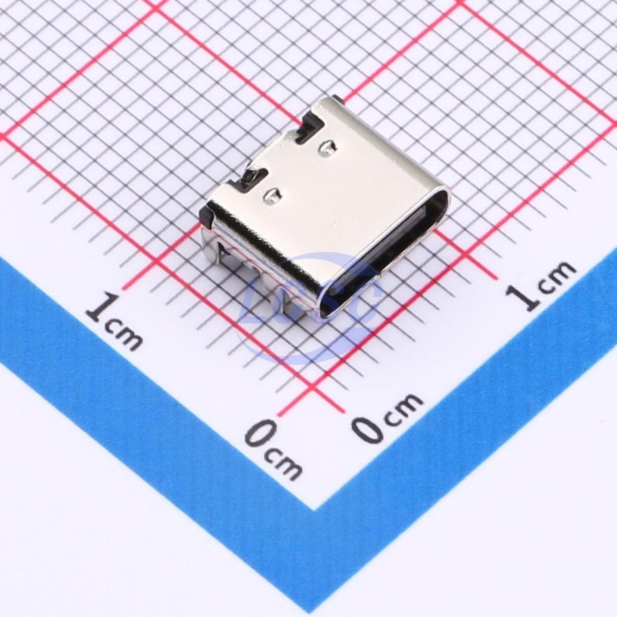
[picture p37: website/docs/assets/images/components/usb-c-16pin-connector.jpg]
<br/>
<strong>J1 — USB-C 16-pin</strong><br/>
Programming + charging input<br/>
<a href="https://www.lcsc.com/product-detail/C2765186.html">C2765186</a> · <strong>$0.10</strong>
</td>
<td align="center" width="25%">
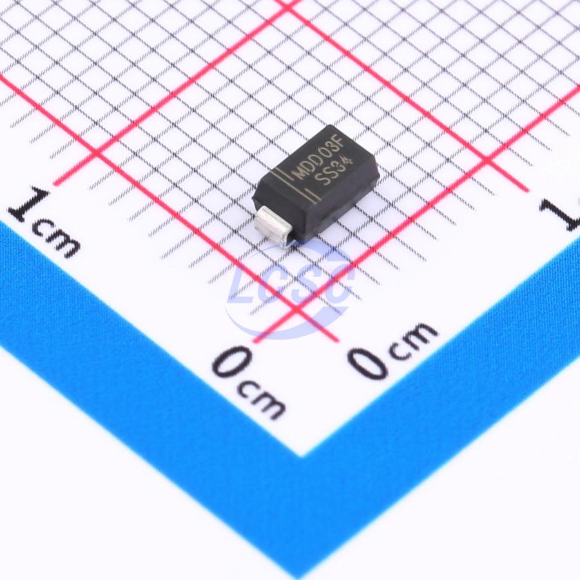
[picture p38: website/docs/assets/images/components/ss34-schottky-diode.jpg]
<br/>
<strong>D1 — SS34 Schottky</strong><br/>
USB/battery path selection (SMA)<br/>
<a href="https://www.lcsc.com/product-detail/C8678.html">C8678</a> · <strong>$0.03</strong>
</td>
<td align="center" width="25%">
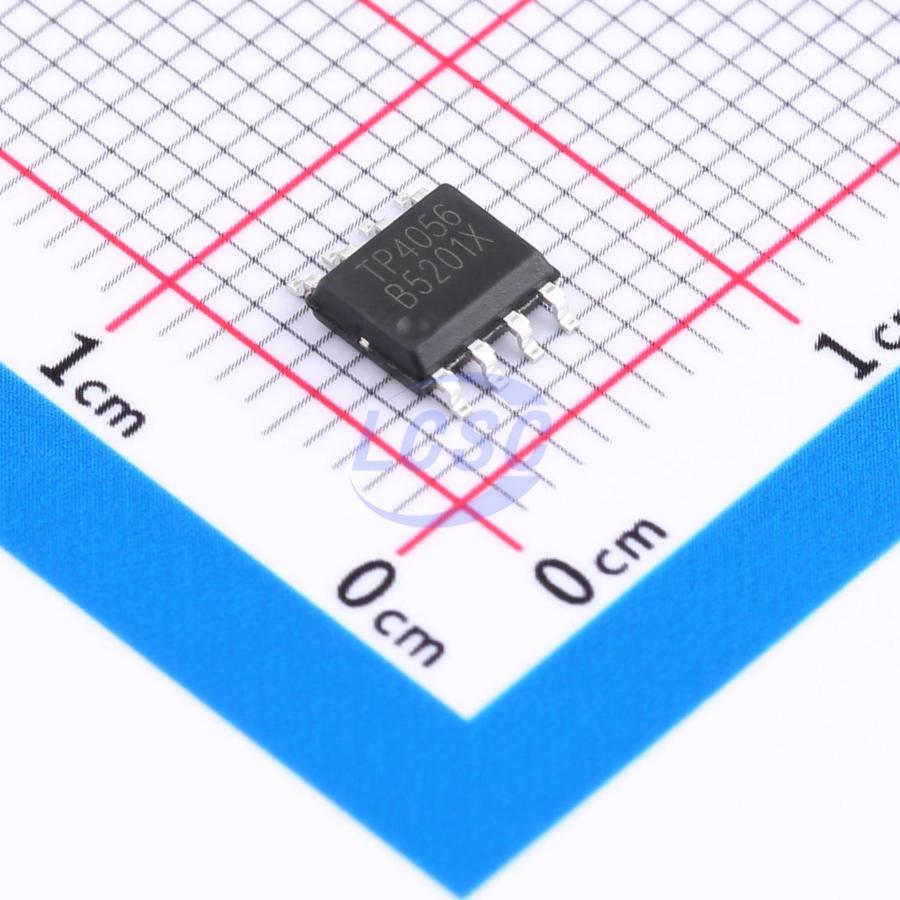
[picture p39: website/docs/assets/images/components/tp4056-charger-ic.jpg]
<br/>
<strong>U2 — TP4056</strong><br/>
1A LiPo charger IC (ESOP-8)<br/>
<a href="https://www.lcsc.com/product-detail/C382139.html">C382139</a> · <strong>$0.07</strong>
</td>
<td align="center" width="25%">
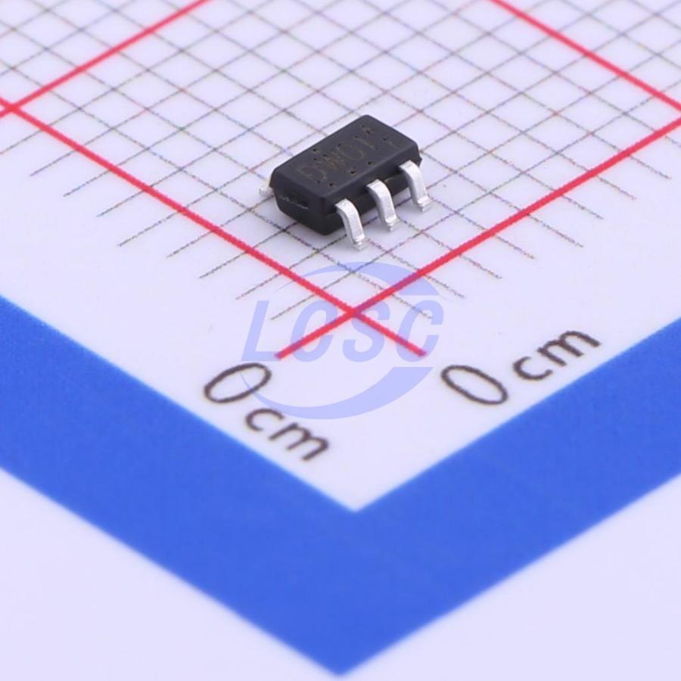
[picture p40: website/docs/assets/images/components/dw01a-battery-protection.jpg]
<br/>
<strong>U3 — DW01A</strong><br/>
Battery over-discharge/charge protection (SOT-23)<br/>
<a href="https://www.lcsc.com/product-detail/C351410.html">C351410</a> · <strong>$0.05</strong>
</td>
</tr>
<tr>
<td align="center">
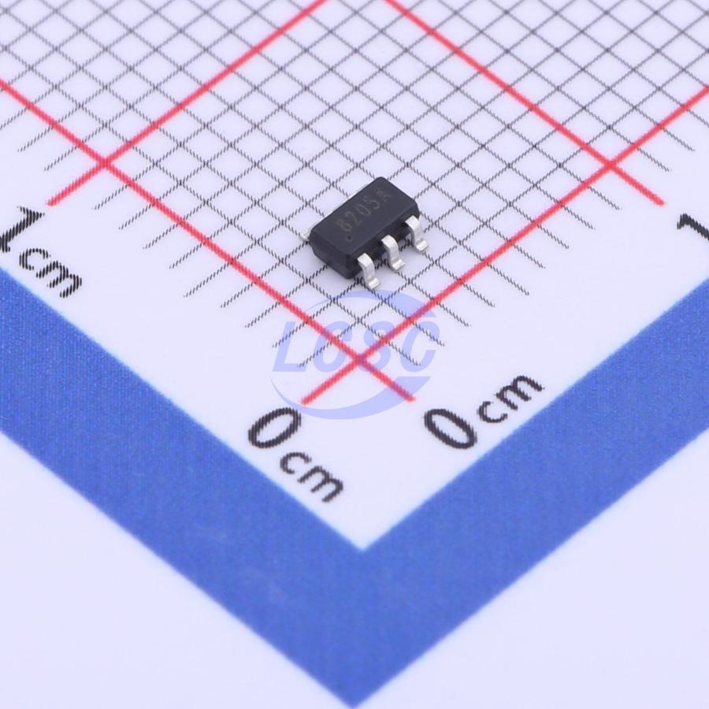
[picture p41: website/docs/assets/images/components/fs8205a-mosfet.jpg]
<br/>
<strong>Q1 — FS8205A</strong><br/>
Dual MOSFET for protection (SOT-23-6)<br/>
<a href="https://www.lcsc.com/product-detail/C908265.html">C908265</a> · <strong>$0.05</strong>
</td>
<td align="center">
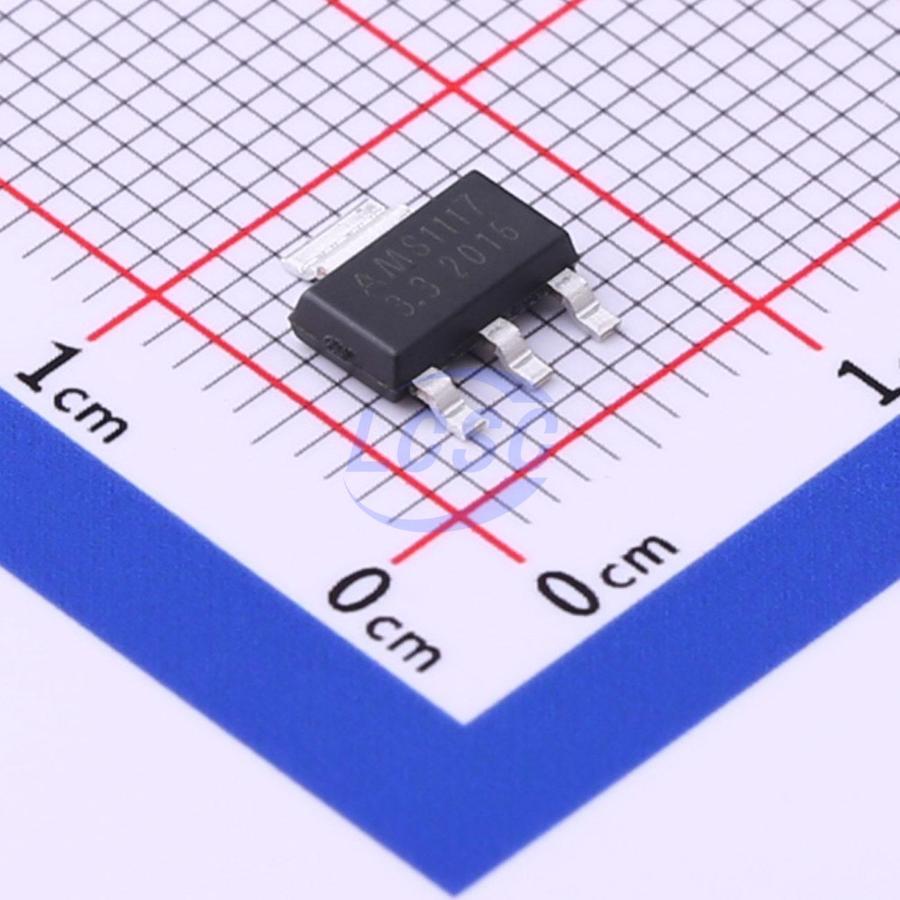
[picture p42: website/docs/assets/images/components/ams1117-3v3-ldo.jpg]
<br/>
<strong>U4 — AMS1117-3.3</strong><br/>
1A LDO regulator, 3.3V (SOT-223)<br/>
<a href="https://www.lcsc.com/product-detail/C6186.html">C6186</a> · <strong>$0.05</strong>
</td>
<td align="center">
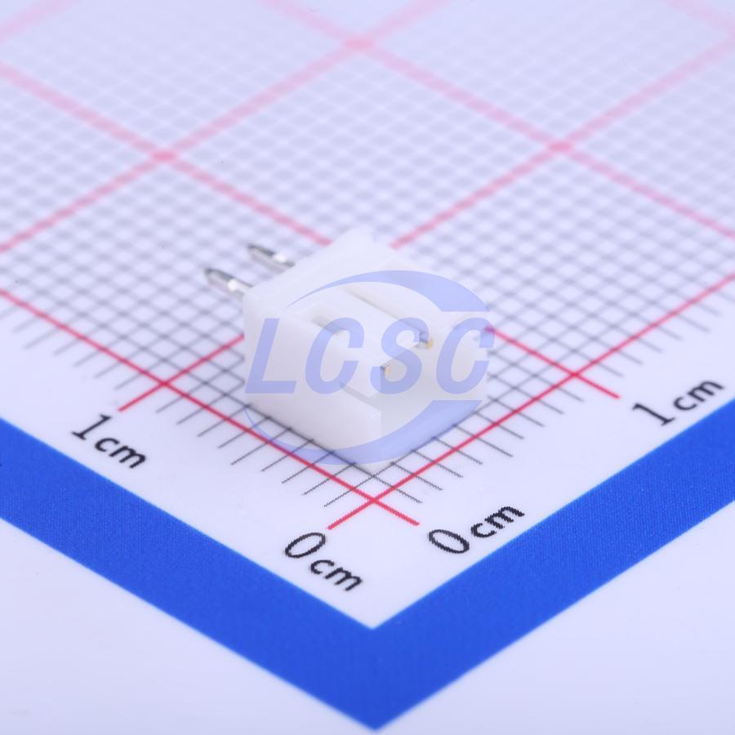
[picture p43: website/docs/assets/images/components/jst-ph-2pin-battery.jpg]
<br/>
<strong>J2 — JST PH 2.0mm 2-pin</strong><br/>
LiPo battery connector (SMD)<br/>
<a href="https://www.lcsc.com/product-detail/C131337.html">C131337</a> · <strong>$0.03</strong>
</td>
<td align="center"></td>
</tr>
</table>

### Input

<figure>
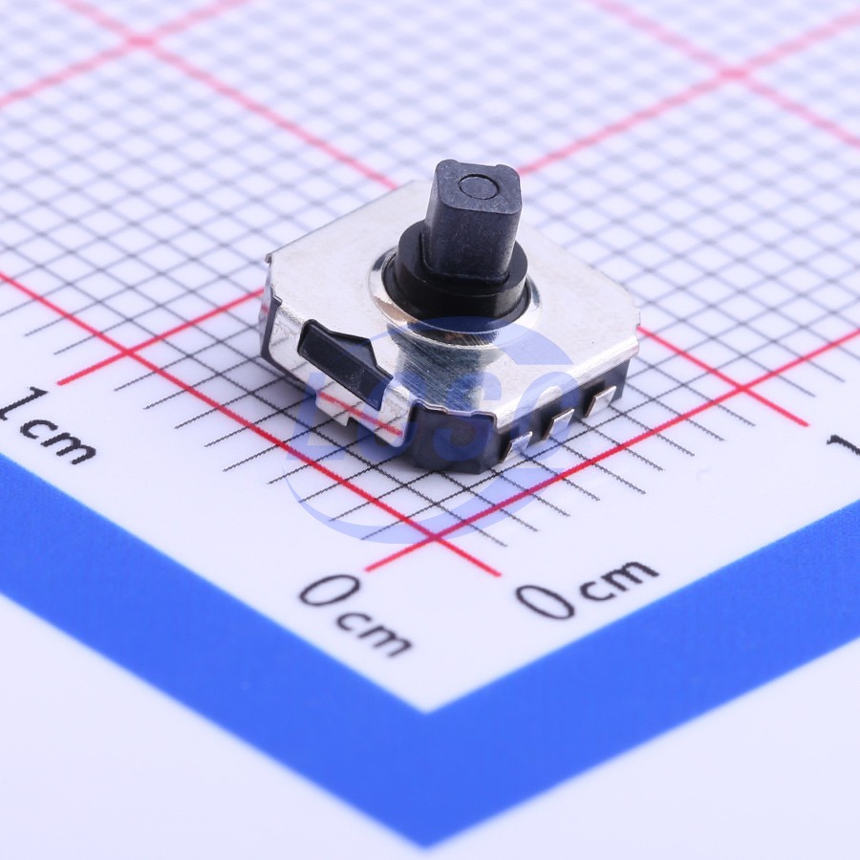
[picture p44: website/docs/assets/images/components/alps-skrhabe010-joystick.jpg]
  
  <figcaption><strong>SW1 — SKRHABE010 (Alps Alpine)</strong><br/>5-way SMD joystick: UP/DOWN/LEFT/RIGHT + center push, 7.4×7.5×1.8mm<br/><a href="https://www.lcsc.com/product-detail/C139794.html">LCSC C139794</a> · <strong>$0.38</strong></figcaption>
</figure>

### Sensors

<figure>
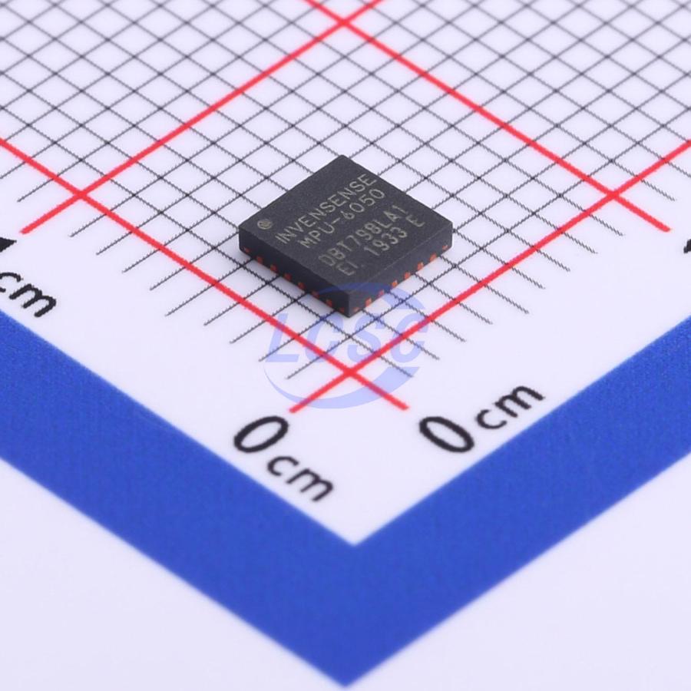
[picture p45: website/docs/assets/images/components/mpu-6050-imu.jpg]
  
  <figcaption><strong>U5 — MPU-6050</strong><br/>6-axis accelerometer + gyroscope, I2C @ 0x68, QFN-24 (4×4mm), 3.3V<br/><a href="https://www.lcsc.com/product-detail/C24112.html">LCSC C24112</a> · <strong>$6.88</strong></figcaption>
</figure>

### Status LEDs

<table>
<tr>
<td align="center" width="50%">
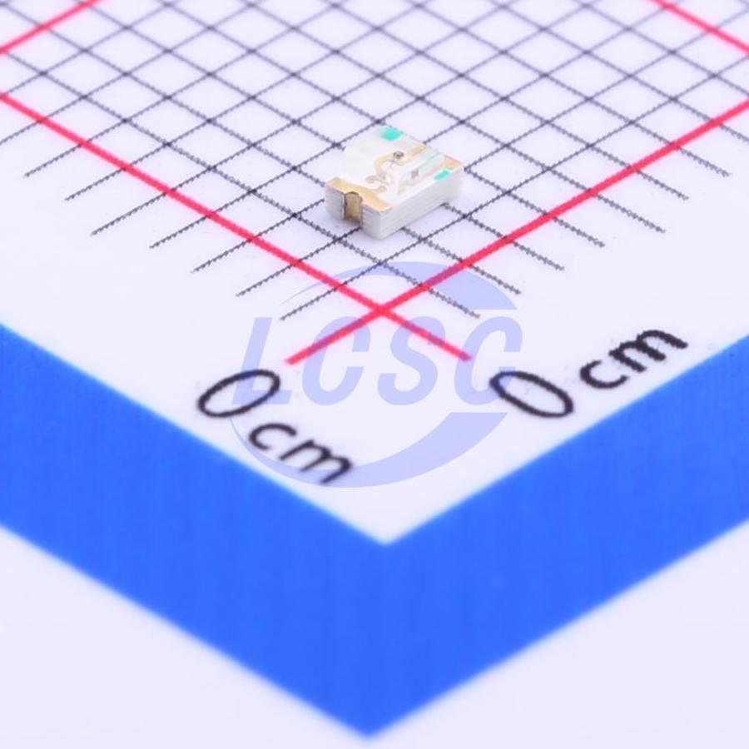
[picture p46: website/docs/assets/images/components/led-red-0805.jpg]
<br/>
<strong>D2 — Red LED (0805)</strong><br/>
Charging indicator (from TP4056 CHRG)<br/>
<a href="https://www.lcsc.com/product-detail/C84256.html">C84256</a> · <strong>$0.01</strong>
</td>
<td align="center" width="50%">
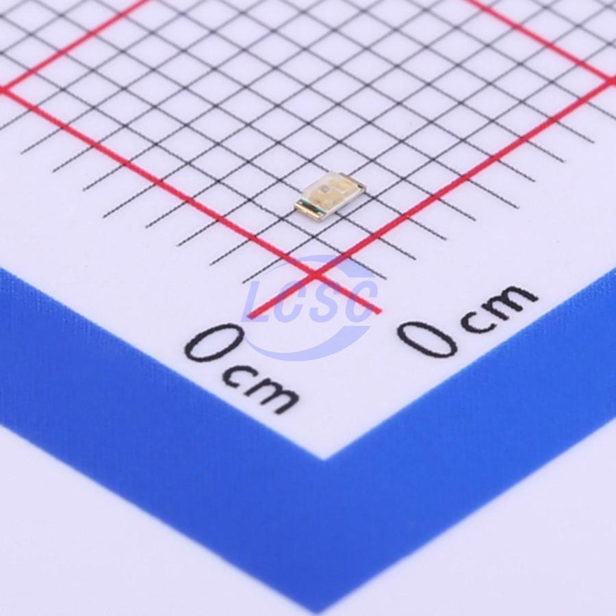
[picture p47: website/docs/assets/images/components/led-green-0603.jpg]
<br/>
<strong>D3 — Green LED (0603)</strong><br/>
Charge complete indicator (from TP4056 STDBY)<br/>
<a href="https://www.lcsc.com/product-detail/C72043.html">C72043</a> · <strong>$0.01</strong>
</td>
</tr>
</table>

### Passives (Not Pictured — Standard 0402 SMD)

| Ref | Value | Purpose | LCSC # | Price |
|-----|---|---|---|---|
| R1 | 1.2kΩ | TP4056 charge current (~1A) | C25752 | $0.001 |
| R2, R3 | 1kΩ | LED current limiting | C25585 | $0.001 |
| R4, R5 | 10kΩ | I2C pull-ups (MPU-6050) | C25744 | $0.001 |
| R6, R7 | 27Ω | USB D+/D- series resistors | — | $0.001 |
| R8, R9 | 5.1kΩ | USB-C CC pins to GND | — | $0.001 |
| R10 | 10kΩ | Pull-up/config | — | $0.001 |
| C1, C2 | 15pF | Crystal load caps (if needed) | — | $0.002 |
| C3–C9 | 100nF / 10µF | Decoupling + bulk filtering | C14663 / C19702 | $0.002–0.01 |

---

## 1. Provider Comparison

| Provider | Location | PCB Lead Time | Assembly? | Min Order | Best For |
|---|---|---|---|---|---|
| **JLCPCB** | Shenzhen, China | 2-5 days | Yes (SMT) | 5 boards | Budget prototypes, integrated parts library |
| **PCBWay** | Shenzhen, China | 3-5 days | Yes (SMT + THT) | 5 boards | Higher quality, advanced features |
| **OSH Park** | Oregon, USA | 9-14 days | No | 3 boards | US-based, premium finish, no assembly |
| **Aisler** | Netherlands, EU | 5-7 days | Yes (SMT) | 3 boards | EU-based, no customs/VAT hassle for EU |
| **Seeed Studio Fusion** | Shenzhen, China | 5-7 days | Yes (SMT) | 5 boards | Budget, integrated with Seeed ecosystem |

---

## 2. JLCPCB — Detailed Pricing Breakdown

**Source:** [JLCPCB Assembly Pricing](https://jlcpcb.com/help/article/pcb-assembly-price) | [Component Pickup Pricing](https://jlcpcb.com/help/article/components-pickup-pricing) | [PCBA Cost Breakdown](https://jlcpcb.com/blog/pcba-cost-breakdown)

### PCB Fabrication

| Spec | Price (5 boards) |
|---|---|
| 2-layer, 100x100mm | ~$2 |
| 4-layer, 100x100mm | ~$8-12 |
| 4-layer, 45x80mm (Dilder size) | ~$8-15 |
| Surface finish | HASL (free), ENIG (+$6-8) |
| Solder mask | Green (free), other colors +$2-5 |

### Assembly Fees

| Line Item | Economic PCBA | Standard PCBA |
|---|---|---|
| **Setup fee** | $8.00 | $25 (single-side) / $50 (double-side) |
| **Stencil** | $1.50 | $7.86 (single-side) |
| **Per solder joint** | $0.0016 | $0.0016 (1-50k joints) |
| **Hand-solder labor** | $3.50/order | $3.50/order |
| **Panel fee** | $7.81/panel | $7.81/panel |

### Component Handling Fees

| Component Type | Fee | Notes |
|---|-----|---|
| **Basic** | **Free** | Common passives (0402/0603 R, C), common ICs — already loaded on pick-and-place machines |
| **Extended** | **$3.00 per unique part type** | Less common parts that require feeder changes. Charged per part *type*, not per unit. |
| **Component cost** | At-cost from LCSC | JLCPCB sources from their own warehouse (LCSC); prices shown in their parts library |

### Key Notes

- JLCPCB has the largest integrated parts library (~400k parts on LCSC)
- "Economic PCBA" supports single-side SMT only, 1-layer stencil
- Basic parts inventory changes — check current stock before finalizing BOM
- $8 setup + $1.50 stencil = **$9.50 minimum** before any components

---

## 3. PCBWay — Detailed Pricing Breakdown

**Source:** [PCBWay SMT Assembly](https://www.pcbway.com/pcb-assembly.html) | [PCBWay Assembly FAQ](https://www.pcbway.com/helpcenter/pcb_assembly_ordering/Assembly_cost_will_be_showed_after_submit_order_is_components_cost_included_.html)

### PCB Fabrication

| Spec | Price (5 boards) |
|---|---|
| 2-layer, 100x100mm | ~$5 |
| 4-layer, 100x100mm | ~$20-30 |
| 4-layer, 45x80mm (Dilder size) | ~$15-25 |
| Min order | 5 boards |

### Assembly Fees

| Line Item | Cost |
|---|---|
| **Per solder joint** | ~$0.002 |
| **Per component** | ~$0.05-$0.50 (varies by component type) |
| **Assembly fee (prototype, 5 boards)** | ~$29-50 (estimated, BOM-dependent) |
| **Stencil** | Included in assembly fee |

### Key Notes

- Assembly pricing is quote-based — upload BOM + Gerbers to get exact price
- Components sourced from DigiKey, Mouser, LCSC, or customer-supplied
- Supports SMT + through-hole in the same order (JLCPCB does not)
- Slightly higher quality reputation for complex boards
- Assembly cost shown *after* order submission, does not include component cost

---

## 4. OSH Park — Detailed Pricing Breakdown

**Source:** [OSH Park Pricing](https://oshpark.com/) | [4-Layer Service](https://docs.oshpark.com/services/four-layer/)

### PCB Fabrication Only (No Assembly)

| Service | Price | Lead Time | Boards Included |
|---|---|---|---|
| **2-layer prototype** | $5/in² | 9-14 days | 3 copies |
| **2-layer Super Swift** | $10/in² | ~5 days | 3 copies |
| **4-layer prototype** | $15/in² | 9-14 days | 3 copies |
| **4-layer Super Swift** | $20/in² | 5-6 days | 3 copies |
| **4-layer Medium Run** | $2/in² | — | 100 in² minimum |

### Cost for Dilder Board (45x80mm = ~5.6 in²)

| Service | 3 boards |
|---|---|
| 4-layer prototype | **~$84** |
| 4-layer Super Swift | **~$112** |

### Key Notes

- **No assembly service** — fabrication only, you solder yourself
- Premium finish: FR408 substrate, purple solder mask, ENIG (gold) finish
- All boards come in sets of 3
- US-based, no customs for US customers
- Significantly more expensive per board than Chinese fabs
- Best for: premium prototypes where quality matters more than cost

---

## 5. Aisler — Detailed Pricing Breakdown

**Source:** [Aisler Pricing](https://community.aisler.net/t/our-simple-pricing/102) | [Aisler Assembly](https://aisler.net/en/products/assembly)

### PCB Fabrication

| Spec | Price (3 boards) |
|---|---|
| 2-layer | ~€5-10 |
| 4-layer | ~€15-25 |
| 6-layer | Quote-based |

### Assembly Fees

| Line Item | Cost |
|---|---|
| **Setup fee** | €75.00 |
| **Per unique part type** | €4.50 |
| **Per component placed** | €0.05 |
| **Board area handling** | Additional (area-based) |

### Cost Estimate for Dilder (10 boards, 27 components, ~5 unique passive types + 5 ICs)

| Line Item | Cost |
|---|---|
| Setup | €75.00 |
| 10 unique part types × €4.50 | €45.00 |
| 27 components × 10 boards × €0.05 | €13.50 |
| **Assembly subtotal** | **~€133.50** |

### Key Notes

- **EU-based** (Netherlands) — no customs, no import VAT for EU buyers
- Significantly more expensive assembly than Chinese providers
- Excellent for EU customers who want to avoid customs delays and surprise import fees
- Supports KiCad and LibrePCB project upload directly
- Smaller parts library than JLCPCB

---

## 6. Seeed Studio Fusion — Detailed Pricing Breakdown

**Source:** [Seeed Fusion PCB](https://www.seeedstudio.com/fusion_pcb.html) | [Seeed Fusion Assembly](https://www.seeedstudio.com/pcb-assembly.html) | [PCBA Pricing Explained](https://www.seeedstudio.com/blog/2018/03/30/seeed-pcba-series-4-pcb-assembly-pricing-explained/)

### PCB Fabrication

| Spec | Price (5-10 boards) |
|---|---|
| 2-layer, 100x100mm, 10 boards | $4.90 |
| 4-layer, 100x100mm, 5 boards | ~$39.90 |
| 4-layer, 45x80mm (Dilder size) | ~$20-35 |

### Assembly Fees

| Line Item | Cost |
|---|---|
| **Setup + stencil** | Included in assembly quote |
| **Per component** | Quote-based (uses DigiKey/Mouser pricing) |
| **Assembly labor** | Component-count dependent |
| **Free assembly promo** | Often offers free assembly for 5 PCBs (check current promos) |

### Key Notes

- Smart quoting system links to DigiKey and Mouser for real-time component pricing
- Frequently runs promotions (free assembly for 5 boards with component purchase)
- Components sourced from major distributors (not a captive warehouse like JLCPCB/LCSC)
- Good middle ground between JLCPCB pricing and PCBWay quality
- Supports Open Parts Library (OPL) with pre-stocked common components

---

## 7. Cost Estimates for the Dilder Board

### Board Spec Summary

- **MCU:** ESP32-S3-WROOM-1-N16R8 (~$2.80 on LCSC)
- **Board:** 4-layer, 45x80mm, 1.6mm thick, HASL finish
- **Components:** ~27 unique parts (resistors, caps, ICs, connectors, LEDs, joystick)
- **Assembly:** Single-side SMT
- **Quantity:** 5 boards

### Estimated BOM Cost Per Board

| Category | Est. Cost |
|---|---|
| ESP32-S3-WROOM-1-N16R8 | $2.80 |
| Power (TP4056, DW01A, FS8205A, AMS1117-3.3, SS34 diode) | $0.28 |
| Input (SKRHABE010 Alps joystick) | $0.38 |
| Sensors (MPU-6050) | $6.88 |
| Connectors (USB-C, JST PH 2-pin, 8-pin header) | $0.30 |
| Passives (10x resistors, 9x caps, 2x LEDs) | $0.50 |
| **Total BOM per board** | **~$11.14** |

### Total Order Estimates (5 Assembled Boards)

| Provider | PCB Fab | Assembly | Components | Shipping (DE) | **Total** | **Per Board** |
|---|---|---|---|---|---|---|
| **JLCPCB** | ~$10 | ~$15 | ~$56 | ~$15-20 (DHL) | **~$96-101** | **~$19-20** |
| **PCBWay** | ~$20 | ~$35 | ~$56 | ~$15-20 | **~$126-131** | **~$25-26** |
| **Aisler** (EU) | ~€20 | ~€134 | ~€50 | ~€5-10 | **~€209-214** | **~€42-43** |
| **Seeed Fusion** | ~$30 | ~$25 | ~$56 | ~$15-20 | **~$126-131** | **~$25-26** |
| **OSH Park** (fab only) | ~$84 | N/A (DIY) | ~$56 (self-source) | ~$10 | **~$150** | **~$50** (+ your soldering time) |

> **Notes:**
>
> - JLCPCB estimate assumes ~5 extended parts ($15 in feeder fees) + $9.50 setup/stencil + ~$0.50 solder joints. The rest is component cost at LCSC prices.
> - Aisler's €75 setup fee dominates the cost for small batches. More competitive at 20+ boards.
> - OSH Park is fab-only — you'd need to hand-solder or use a separate assembly service.
> - All shipping estimates are for Germany (DHL Express from China, ~5-7 days).
> - Import VAT (19% DE) applies to China orders. Aisler (EU) has no import VAT.
> - Component prices based on LCSC qty-5 pricing as of April 2026.

### Break-Even: When Does Aisler Beat China?

Aisler's €75 setup fee makes it expensive for small batches, but there's no import VAT or customs delay. For a German buyer:

| Qty | JLCPCB (incl. 19% VAT + DHL) | Aisler (EU, no VAT) |
|-----|---|---|
| 5 | ~€108 | ~€214 |
| 10 | ~€175 | ~€240 |
| 20 | ~€310 | ~€295 |
| 50 | ~€700 | ~€565 |

Aisler becomes competitive at **~20 boards** when factoring in import VAT and customs risk.

---

## 8. Open-Source Reference Designs

These open-source hardware projects share significant overlap with the Dilder's requirements and can serve as reference designs, component validation, or starting points for schematic/layout work.

### 8.1 Ducky Board (ESP32-S3 + e-Paper + Battery)

**The closest match to the Dilder board.**

| Attribute | Details |
|---|---|
| **MCU** | ESP32-S3 |
| **Display** | GDEM0154Z91 (1.52" e-ink, 3-color, Good Display) |
| **Battery** | Li-Ion single-cell charger with status LEDs |
| **USB** | USB-C for power and programming |
| **Design tool** | KiCad 9 |
| **Files available** | Schematic (.kicad_sch), PCB layout (.kicad_pcb), Gerber files, PDF exports |
| **License** | GPL-3.0 |
| **GitHub** | [MakersFunDuck/Ducky-board-ESP32-S3-with-1.52-inch-e-paper-display](https://github.com/MakersFunDuck/Ducky-board-ESP32-S3-with-1.52-inch-e-paper-display) |

**Relevance to Dilder:** Same MCU family, same display technology, same battery charging architecture. The schematic for the ESP32-S3 power sequencing, USB-C implementation, and LiPo charging circuit can be directly referenced. Component footprints and LCSC part numbers are manufacturing-optimized.

### 8.2 OpenTama (Tamagotchi Reference Design)

**Purpose-built virtual pet PCB with JLCPCB assembly in mind.**

| Attribute | Details |
|---|---|
| **MCU** | STM32L072 (ARM Cortex-M0+) |
| **Display** | SPI SSD1306 OLED or SPI UC1701x LCD |
| **Battery** | 1000mAh Li-Po/Li-Ion (40x30x12mm) |
| **Input** | 3 tactile buttons |
| **Design tool** | KiCad |
| **Files available** | Full KiCad project (schematic + PCB), JLCPCB LCSC part numbers included |
| **License** | CERN-OHL-S v2 (open hardware) |
| **GitHub** | [Sparkr-tech/opentama](https://github.com/Sparkr-tech/opentama) |

**Relevance to Dilder:** Same product category (virtual pet), same target fab (JLCPCB), same battery spec (1000mAh LiPo). All components placed on one side for JLCPCB assembly. LCSC part numbers pre-assigned. Different MCU (STM32 vs ESP32-S3) but the power management, button input, and display interface circuits are directly applicable. The CERN-OHL-S v2 license explicitly permits derivative works.

### 8.3 TamaFi V2 (ESP32-S3 Virtual Pet)

**A WiFi-enabled virtual pet with custom PCB.**

| Attribute | Details |
|---|---|
| **MCU** | ESP32-S3 module |
| **Display** | 1.3-1.54" TFT ST7789 (240x240, full color) |
| **Battery** | TP4056 single-cell LiPo charger, USB-C |
| **Input** | 6 tactile buttons |
| **Audio** | PWM buzzer |
| **Lighting** | 4x WS2812-2020 addressable RGB LEDs |
| **Files available** | PCB layouts and schematics in repo (format unspecified) |
| **License** | MIT |
| **GitHub** | [cifertech/TamaFi](https://github.com/cifertech/TamaFi) |

**Relevance to Dilder:** Same MCU (ESP32-S3), same battery charging (TP4056), same product category (virtual pet). Uses TFT instead of e-ink, but the power management, button debouncing, and WiFi/BLE integration are directly relevant. MIT license allows any use.

### 8.4 PocketMage PDA (ESP32-S3 + e-Ink Handheld)

**A handheld e-ink PDA with the exact same MCU and similar form factor.**

| Attribute | Details |
|---|---|
| **MCU** | ESP32-S3-WROOM-1-N16R8 (16MB flash, 8MB PSRAM) — **identical to Dilder** |
| **Display** | 3.1" e-ink (GDEQ031T10, 320x240px) + 256x32 OLED secondary |
| **Battery** | 1200mAh LiPo with JST connector |
| **Storage** | MicroSD (up to 2TB) |
| **Input** | Keyboard matrix (TCA8418 IC) |
| **Design tool** | KiCad (planned release) |
| **Files available** | Firmware only (hardware files planned for future release) |
| **License** | Apache-2.0 |
| **GitHub** | [ashtf8/PocketMage_PDA](https://github.com/ashtf8/PocketMage_PDA) |

**Relevance to Dilder:** Uses the exact same ESP32-S3-WROOM-1-N16R8 module with e-ink display. Firmware demonstrates SPI e-ink driving from ESP32-S3, which will be directly useful when porting from RP2040. Hardware files not yet released but the firmware architecture is a valuable reference for the ESP32-S3 migration.

### 8.5 AeonLabs ESP32-S3 PCB Template

**A bare ESP32-S3 PCB template for KiCad with manufacturing files.**

| Attribute | Details |
|---|---|
| **MCU** | ESP32-S3 |
| **Purpose** | Minimal reference design / starting template |
| **Design tool** | KiCad |
| **Files available** | Schematic, PCB layout, KiCad project |
| **License** | MIT |
| **GitHub** | [aeonSolutions/AeonLabs-pcb-template-esp32-s3](https://github.com/aeonSolutions/AeonLabs-pcb-template-esp32-s3) |

**Relevance to Dilder:** Minimal ESP32-S3 reference circuit — useful for validating power supply design, crystal selection, and antenna keepout zones without the complexity of a full application board.

### 8.6 PicoTop (RP2040 Custom Desktop)

**Already analyzed in the Dilder PCB research document.**

| Attribute | Details |
|---|---|
| **MCU** | RP2040 (custom board, not a Pico module) |
| **Purpose** | Custom RP2040 desktop computer |
| **Design tool** | KiCad |
| **Files available** | Full KiCad project + Gerbers |
| **GitHub** | [7west/PicoTop](https://github.com/7west/PicoTop) |

**Relevance to Dilder:** Previously analyzed as the inspiration for the custom PCB initiative. Demonstrates full RP2040 custom board design from schematic through manufacturing. The manufacturing pipeline documentation (JLCPCB ordering, BOM preparation) was the basis for Dilder's PCB research document.

---

## 9. Recommended Manufacturing Path

### For Dilder v1 Prototype (5 boards)

**JLCPCB** is the clear winner for the first prototype run:

1. **Lowest cost:** ~$96-101 for 5 fully assembled boards ($19-20/board)
2. **Integrated workflow:** KiCad → JLCPCB Tools plugin → Gerber + BOM/CPL export → upload → order
3. **Parts availability:** All Dilder BOM components are in-stock on LCSC with assigned part numbers
4. **Speed:** 2-5 day fab + 3-5 day assembly + 5-7 day DHL to Germany = **~10-17 days total**
5. **Community:** Largest hobbyist user base, most troubleshooting resources available

### Ordering Checklist

1. [ ] Complete interactive routing in KiCad (traces on F.Cu and B.Cu, via stitching for ground plane)
2. [ ] Run DRC (Design Rule Check) with JLCPCB constraints (5mil trace/space, 0.3mm via drill)
3. [ ] Export Gerbers via JLCPCB Tools plugin
4. [ ] Export BOM + CPL (Component Placement List) via JLCPCB Tools plugin
5. [ ] Upload to JLCPCB, verify 3D preview
6. [ ] Confirm all components show "In Stock" on LCSC
7. [ ] Select "Economic PCBA" for single-side SMT
8. [ ] Review order, pay, wait ~2 weeks

### For Production (20+ boards)

Consider **Aisler** if selling within the EU (no import hassle for customers), or stay with **JLCPCB** for global distribution.

---

## 10. Sources

### Provider Pricing

- [JLCPCB Assembly Pricing](https://jlcpcb.com/help/article/pcb-assembly-price) — setup fees, per-joint costs, stencil charges
- [JLCPCB Component Pickup Pricing](https://jlcpcb.com/help/article/components-pickup-pricing) — 30% markup formula, $30 minimum
- [JLCPCB PCBA Cost Breakdown](https://jlcpcb.com/blog/pcba-cost-breakdown) — full cost analysis with examples
- [JLCPCB Assembly FAQ](https://jlcpcb.com/help/article/pcb-assembly-faqs) — basic vs extended parts, feeder fees
- [PCBWay SMT Assembly](https://www.pcbway.com/pcb-assembly.html) — service overview and capabilities
- [PCBWay Assembly FAQ](https://www.pcbway.com/helpcenter/pcb_assembly_ordering/Assembly_cost_will_be_showed_after_submit_order_is_components_cost_included_.html) — pricing structure
- [OSH Park 4-Layer Service](https://docs.oshpark.com/services/four-layer/) — $15/in² for 3 copies
- [OSH Park Fabrication Services](https://docs.oshpark.com/services/) — all service tiers
- [Aisler Pricing](https://community.aisler.net/t/our-simple-pricing/102) — setup fee, per-part, per-placement
- [Aisler Assembly](https://aisler.net/en/products/assembly) — EU-based assembly service
- [Seeed Fusion PCB](https://www.seeedstudio.com/fusion_pcb.html) — fabrication pricing
- [Seeed Fusion Assembly](https://www.seeedstudio.com/pcb-assembly.html) — assembly service
- [Seeed PCBA Pricing Explained](https://www.seeedstudio.com/blog/2018/03/30/seeed-pcba-series-4-pcb-assembly-pricing-explained/) — cost structure breakdown

### Comparison & Analysis

- [JLCPCB vs PCBWay Comparison](https://www.fr4pcb.tech/blog/detail/jlcpcb-vs-pcbway-which-offers-better-prototype-assembly-services/) — detailed feature comparison
- [Hobby PCB Manufacturer Comparison (Hackaday)](https://hackaday.com/2023/10/13/an-in-depth-comparison-of-hobby-pcb-manufacturers/) — independent testing
- [PCB Assembly Cost Guide 2025 (RayPCB)](https://www.raypcb.com/what-affect-pcb-assembly-cost/) — industry pricing overview

### Open-Source Hardware Designs

- [Ducky Board — ESP32-S3 + e-Paper (GPL-3.0)](https://github.com/MakersFunDuck/Ducky-board-ESP32-S3-with-1.52-inch-e-paper-display)
- [OpenTama — Virtual Pet Reference Design (CERN-OHL-S v2)](https://github.com/Sparkr-tech/opentama)
- [TamaFi V2 — ESP32-S3 Virtual Pet (MIT)](https://github.com/cifertech/TamaFi)
- [PocketMage PDA — ESP32-S3 e-Ink Handheld (Apache-2.0)](https://github.com/ashtf8/PocketMage_PDA)
- [AeonLabs ESP32-S3 PCB Template (MIT)](https://github.com/aeonSolutions/AeonLabs-pcb-template-esp32-s3)
- [PicoTop — RP2040 Custom Board](https://github.com/7west/PicoTop)
- [OpenTama Blog Post (design notes)](http://blog.rona.fr/post/2022/04/21/OpenTama-an-open-source-reference-design-for-MCUGotchi)
- [TamaFi V2 Hackaday.io](https://hackaday.io/project/204612-tamafi-v2-a-virtual-pet-that-evolved-beyond-logic)

---

*Document version: 1.0 — 2026-04-15*

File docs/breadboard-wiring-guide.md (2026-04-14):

# Breadboard Wiring Guide — Full Test Bench

> Complete wiring diagram and setup instructions for all current hardware components on a single breadboard with the Raspberry Pi Pico WH.

---

## Table of Contents

1. [Components](#1-components)
2. [Pin Assignment Table](#2-pin-assignment-table)
3. [Master Wiring Diagram](#3-master-wiring-diagram)
4. [Pico WH Pin Map — All Peripherals](#4-pico-wh-pin-map--all-peripherals)
5. [Component-by-Component Wiring](#5-component-by-component-wiring)
    - [5.1 Waveshare 2.13" e-Paper V3 (SPI1)](#51-waveshare-213-e-paper-v3-spi1)
    - [5.2 DollaTek 5-Way Joystick (GPIO)](#52-dollatek-5-way-joystick-gpio)
    - [5.3 GY-NEO6MV2 GPS Module (UART0)](#53-gy-neo6mv2-gps-module-uart0)
    - [5.4 HC-SR04 Ultrasonic Sensor (GPIO)](#54-hc-sr04-ultrasonic-sensor-gpio)
6. [Recommended 3.3V Speakers](#6-recommended-33v-speakers)
7. [Breadboard Layout Strategy](#7-breadboard-layout-strategy)
8. [Power Budget](#8-power-budget)
9. [Important Notes and Warnings](#9-important-notes-and-warnings)
10. [Quick Test Code](#10-quick-test-code)
    - [10.1 GPS Serial Test](#101-gps-serial-test)
    - [10.2 HC-SR04 Distance Test](#102-hc-sr04-distance-test)
    - [10.3 All-Peripherals Diagnostic](#103-all-peripherals-diagnostic)
11. [Troubleshooting](#11-troubleshooting)

---

## 1. Components

| # | Component | Model | Interface | Voltage | Notes |
|---|---|---|---|---|---|
| 1 | **Microcontroller** | Raspberry Pi Pico WH | — | 3.3V logic / 5V USB | Pre-soldered headers |
| 2 | **e-Paper Display** | Waveshare 2.13" V3 | SPI1 | 3.3V | SSD1680 driver, 250x122px |
| 3 | **5-Way Joystick** | DollaTek 5D Navigation | GPIO (active LOW) | 3.3V | Up/Down/Left/Right/Center |
| 4 | **GPS Module** | GY-NEO6MV2 (NEO-6M) | UART (9600 baud) | 3.3-5V | NMEA output, onboard regulator |
| 5 | **Ultrasonic Sensor** | HC-SR04 | GPIO (TRIG/ECHO) | **5V** | Needs voltage divider on ECHO |

---

## 2. Pin Assignment Table

| Peripheral | Signal | Pico GPIO | Physical Pin | Direction | Interface |
|---|---|---|---|---|---|
| **e-Paper** | VCC | 3V3(OUT) | 36 | Power out | — |
| | GND | GND | 38 | Ground | — |
| | DIN (MOSI) | GP11 | 15 | Out | SPI1 TX |
| | CLK | GP10 | 14 | Out | SPI1 SCK |
| | CS | GP9 | 12 | Out | SPI1 CSn |
| | DC | GP8 | 11 | Out | Digital |
| | RST | GP12 | 16 | Out | Digital |
| | BUSY | GP13 | 17 | In | Digital |
| **Joystick** | UP | GP2 | 4 | In (pull-up) | GPIO |
| | DOWN | GP3 | 5 | In (pull-up) | GPIO |
| | LEFT | GP4 | 6 | In (pull-up) | GPIO |
| | RIGHT | GP5 | 7 | In (pull-up) | GPIO |
| | CENTER | GP6 | 9 | In (pull-up) | GPIO |
| | COM/GND | GND | 8 | Ground | — |
| **GPS** | TX (to Pico RX) | GP1 (UART0 RX) | 2 | In | UART0 |
| | RX (from Pico TX) | GP0 (UART0 TX) | 1 | Out | UART0 |
| | VCC | 3V3(OUT) | 36 | Power out | — |
| | GND | GND | 3 | Ground | — |
| **HC-SR04** | VCC | VBUS (5V) | 40 | Power out | — |
| | TRIG | GP14 | 19 | Out | Digital |
| | ECHO (via divider) | GP16 | 21 | In | Digital |
| | GND | GND | 23 | Ground | — |
| **Reserved** | Buzzer (future) | GP15 | 20 | Out | PWM |
| **Total** | | **15 GPIO** | | | |
| **Free** | | **GP7, GP15, GP17-22, GP26-28** | | | **11 GPIO remaining** |

---
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

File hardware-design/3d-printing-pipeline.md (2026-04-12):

# 3D Printing Prototyping Pipeline — Analysis Document

A comprehensive evaluation of every viable 3D printing technology, service, and CAD workflow for designing and manufacturing the Dilder enclosure. This document exists to make informed, cost-effective decisions about how to go from CAD model to physical prototype (and eventually small-batch production).

**Target part:** Two-piece snap-fit enclosure, ~88 x 34 x 19 mm, ~15–25 g material, housing a Pico W + Waveshare 2.13" e-Paper display + 5 tactile buttons.

---

## Table of Contents

1. [Technology Overview](#1-technology-overview)
2. [FDM / FFF — Fused Deposition Modeling](#2-fdm--fff--fused-deposition-modeling)
3. [SLA / MSLA — Resin Printing](#3-sla--msla--resin-printing)
4. [SLS — Selective Laser Sintering](#4-sls--selective-laser-sintering)
5. [MJF — Multi Jet Fusion](#5-mjf--multi-jet-fusion)
6. [Other Industrial Technologies](#6-other-industrial-technologies)
7. [Technology Comparison Matrix](#7-technology-comparison-matrix)
8. [Third-Party Print Services — Deep Dive](#8-third-party-print-services--deep-dive)
9. [Third-Party Service Comparison Matrix](#9-third-party-service-comparison-matrix)
10. [Material Guide](#10-material-guide)
11. [CAD Software and Design Workflow](#11-cad-software-and-design-workflow)
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

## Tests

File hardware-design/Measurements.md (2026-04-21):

E-ink display board:
    30mm x 65mm x 5mm

ESP32-S3-WROOM-1 module:
    18mm x 25.5mm x 3.2mm
    (antenna area: 18mm x 2mm at top, keep-out zone required)

PCB board:
    45mm x 80mm x 1.6mm (4-layer)

1000 mah battery
    35mm x 52mm

3000 mah battery
    36mm x 66mm x 10mm

5-way joystick (SKRHABE010):
    7mm x 7mm x 5mm

USB-C connector (HRO TYPE-C-31-M-12):
    8.9mm x 7.3mm x 3.3mm

JST PH 2-pin battery connector:
    6mm x 4.5mm x 6mm

LIS2DH12TR Accelerometer (LGA-12):
    2mm x 2mm x 1mm

esp32s wroom dev booard
    22m between the heades
    antennae is 18mm wide 6mm off the board 
    the main board 56mm long and 28mm wide

    5mm width board  leave 20mm gap in the midlle on the top
    need 4 square pillar 2 nestled up top to the right and left at the top of the board in the corner where the board and antenna meet 2squar pillar on the right and left of the bottom of  the board just before the end of  the board 
    we need to be able to sandwich the board between a plane the reset on the bottom of the board the coverrs the underside between the pinns and meet the squar pillars then we nee a separat top portion to sandwach the top that extend up 5mm from the botom plane it should cover the majority of the top board except for 20mm in the center we need screw holes to be able to screw togeth the to portions to sandwiche them in then we need another sandwich piew 6mm below the headers of the board that connect to the same square pillare and screw in  lets make a scad script to plot this out

1000 mah battery
    35mm x 52mm

Display 30mm x 65mm

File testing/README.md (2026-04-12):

# Dilder Testing Infrastructure

Comprehensive test suite for the Dilder project tools: **DevTool** (Tkinter GUI), **Setup CLI** (terminal wizard), and the **MkDocs website**.

---

## Quick Start

```bash
# 1. Install dependencies
cd testing
pip install -r requirements.txt

# 2. Install Playwright browsers
playwright install chromium

# 3. Run all tests
pytest -v

# 4. Run only screenshot tests
pytest -m screenshot -v

# 5. Generate user guides from screenshots
python3 -m testing.utils.guide_generator
```

---

## Architecture

```
testing/
├── devtool/          # Tkinter GUI tests (pytest + Pillow screenshots)
├── setup_cli/        # CLI wizard tests (pytest + subprocess)
├── website/          # MkDocs site tests (Playwright browser automation)
├── utils/            # Shared utilities
│   ├── screenshot_helper.py   # Unified screenshot capture
│   ├── ansi_renderer.py       # ANSI terminal → styled HTML
│   └── guide_generator.py     # Assemble screenshots into guides
├── guides/           # Generated user guides (markdown + screenshots)
├── reports/          # pytest-html test reports
└── .vscode/          # VSCode debug & test configs
```

### Testing Strategy

| Tool | Framework | Screenshot Method | Hardware |
|---|---|---|---|
| DevTool | pytest + Tkinter | `Pillow.ImageGrab` | Mocked (serial, USB) |
| Setup CLI | pytest + subprocess | ANSI→HTML + Playwright | Mocked (system cmds) |
| Website | pytest-playwright | `page.screenshot()` | MkDocs dev server |

**Why not pure Playwright for everything?** Playwright automates web browsers. DevTool is a Tkinter desktop app and Setup CLI is a terminal program — neither runs in a browser. We use Playwright where it fits (website) and the right tool for each domain.

---

## Prerequisites

- **Python 3.9+**
- **Tkinter** (system package: `tk` on Arch, `python3-tk` on Debian)
- **A display** (X11, Wayland, or Xvfb for headless/CI)
- **MkDocs** (for website tests only — `cd website && python3 dev.py install`)

### Install on Arch / CachyOS

```bash
sudo pacman -S tk python-pip
pip install -r testing/requirements.txt
playwright install chromium
```

### Install on Ubuntu / Debian

```bash
sudo apt install python3-tk python3-pip
pip install -r testing/requirements.txt
playwright install chromium --with-deps
```

### Headless (CI / SSH)

For environments without a display:

```bash
pip install pyvirtualdisplay
sudo apt install xvfb  # or: sudo pacman -S xorg-server-xvfb
```

The DevTool test fixtures auto-detect and start Xvfb when no `$DISPLAY` is set.

---

## Running Tests

### By Domain

```bash
# DevTool GUI tests
pytest devtool/ -v

# Setup CLI tests
pytest setup_cli/ -v

# Website tests (requires MkDocs server)
cd ../website && python3 dev.py serve &
cd ../testing && pytest website/ -v
```

### By Marker

```bash
# Only screenshot-capturing tests
pytest -m screenshot -v

# Skip slow tests
pytest -m "not slow" -v

# Skip hardware-dependent tests
pytest -m "not hardware" -v
```

### Single Test File

```bash
pytest devtool/test_display_emulator.py -v
pytest setup_cli/test_cli_navigation.py -v
pytest website/test_navigation.py -v
```

### With HTML Report

```bash
pytest -v --html=reports/report.html --self-contained-html
# Open reports/report.html in a browser to view results
```

---

## VSCode Integration

### Setup

1. Open the project root in VSCode
2. Install the **Python** extension (ms-python.python)
3. Install the **Python Test Explorer** extension (optional, for sidebar test tree)
4. The `.vscode/` configs in `testing/` are auto-detected

### Running Tests from VSCode

- **Test Explorer sidebar**: Click the flask icon in the activity bar to see all discovered tests. Click play to run individual tests or entire suites.
- **Debug configurations**: Open the Run and Debug panel (Ctrl+Shift+D) and select from:
  - `Run All Tests`
  - `Run DevTool Tests`
  - `Run Setup CLI Tests`
  - `Run Website Tests`
  - `Run Screenshot Tests Only`
  - `Run Current Test File`
  - `Generate User Guides`
- **Inline test runner**: Click the green play icon that appears above each `def test_` or `class Test` in the editor.

### Debugging a Failing Test

1. Set a breakpoint in the test file
2. Right-click the test function → "Debug Test"
3. The debugger pauses at your breakpoint with full variable inspection

---

## Screenshot Pipeline

### How It Works

1. Tests marked with `@pytest.mark.screenshot` capture screenshots as a side effect
2. **DevTool**: Pillow's `ImageGrab.grab()` captures the Tkinter window region
3. **Website**: Playwright's `page.screenshot()` captures the browser viewport
4. **Setup CLI**: ANSI output is rendered as styled HTML, then screenshotted by Playwright
5. All screenshots are saved to `{domain}/screenshots/` with descriptive filenames

### Naming Convention

Screenshots follow the pattern: `{domain}_{feature}_{detail}.png`

Examples:
- `devtool_display_pencil_tool.png`
- `devtool_serial_connected.png`
- `website_home_desktop.png`
- `website_docs_devtool.png`

### Generating User Guides

After running screenshot tests:

```bash
python3 -m testing.utils.guide_generator
```

This creates markdown files in `testing/guides/`:
- `devtool_guide.md` — DevTool user guide with all tab screenshots
- `setup_cli_guide.md` — Setup CLI walkthrough with terminal screenshots
- `website_guide.md` — Website documentation with responsive screenshots

### Publishing to the Website

Copy generated guides into the website docs:

```bash
cp testing/guides/devtool_guide.md website/docs/docs/tools/devtool-guide.md
cp testing/guides/setup_cli_guide.md website/docs/docs/tools/setup-cli-guide.md
# Copy screenshot images too
cp testing/devtool/screenshots/*.png website/docs/assets/screenshots/devtool/
cp testing/website/screenshots/*.png website/docs/assets/screenshots/website/
```

Then add the guides to `website/mkdocs.yml` navigation.

---

## Test Report & Documentation Guidelines

### Test Naming

- Test files: `test_{feature}.py`
- Test classes: `Test{Feature}{Aspect}` (e.g., `TestDrawingTools`, `TestSerialConnection`)
- Test methods: `test_{what_it_verifies}` (e.g., `test_pencil_draws_black_pixel`)

### Writing New Tests

1. **Place** the test in the appropriate domain directory
2. **Import** fixtures from conftest (they handle app lifecycle and mocking)
3. **Add screenshots** with `@pytest.mark.screenshot` for any visual state worth documenting
4. **Use descriptive names** — the test name becomes the screenshot description if no override exists

### Screenshot Test Template

```python
@pytest.mark.screenshot
def test_screenshot_my_feature(self, devtool_app, select_tab, devtool_screenshot_dir):
    tab = select_tab("display_tab")
    # Set up the UI state you want to capture
    tab._draw_rect(10, 10, 100, 80, fill=True)
    tab._redraw_from_buffer()
    devtool_app.update()
    # Capture
    path = devtool_screenshot_dir / screenshot_name("devtool", "my_feature")
    capture_tkinter_window(devtool_app, path)
```

### Report Review

After a test run, review:
1. `reports/report.html` — HTML test report with pass/fail status
2. `devtool/screenshots/` — Visual verification of DevTool states
3. `setup_cli/screenshots/` — CLI output captures
4. `website/screenshots/` — Site appearance at multiple viewports

---

## Markers Reference

| Marker | Description |
|---|---|
| `screenshot` | Test captures screenshots for user guides |
| `slow` | Test takes more than 10 seconds |
| `hardware` | Requires physical Pico W hardware (skipped by default) |
| `website` | Requires running MkDocs dev server |

---

## Troubleshooting

### "No display available"

The DevTool tests need a graphical display (X11/Wayland). On headless systems:
```bash
pip install pyvirtualdisplay
sudo pacman -S xorg-server-xvfb  # or: sudo apt install xvfb
```

### "mkdocs not installed"

Website tests need MkDocs Material:
```bash
cd website && python3 dev.py install
```

### "playwright not found"

```bash
pip install pytest-playwright playwright
playwright install chromium
```

### Tests hang on serial

The DevTool tests mock all serial communication. If a test hangs, it's likely a `root.update()` loop issue — check that you're calling `devtool_app.update()` between UI actions.

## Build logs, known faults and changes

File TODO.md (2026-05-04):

# Dilder — Rolling Daily TODO

A living task list updated each week. Newest entries at the top.

---

## Week 3 — 2026-05-04 (Session Progress)

### Completed Today

- [x] Joystick PCB arrived from JLCPCB — unboxed, photographed, tested
- [x] Discovered COM/UP pin swap in EasyEDA-imported KiCad symbol — root cause traced, schematic fixed for Rev 2
- [x] Wired joystick breakout to Pico 2 W — GPIO mapping confirmed: L=GP2, D=GP3, UP=GP4, R=GP5, C=GP6
- [x] GPIO diagnostic added to firmware — prints raw pin states at startup and every 2s during runtime
- [x] Switched display driver from V3 to V4 (internal LUT, no custom waveform tables)
- [x] Rewrote V4 partial refresh driver 4 times (V1.0→V1.4) — final version uses two-pass diff-based partial refresh for ghost-free updates
- [x] Added firmware version system (`version.h`, v0.5.4) — all 20 programs print version + build timestamp at startup
- [x] Added "Clean Build & Deploy" button to DevTool Programs tab
- [x] Changed all display variant defaults from V3 to V4 (CMakeLists, Dockerfile, DevTool dropdown)
- [x] Mk2 translucent case photos converted, named, placed in website assets
- [x] Front page gallery updated with Mk2 translucent + joystick PCB photos
- [x] Blog post and design evolution entries for Mk2 translucent prototype
- [x] Created rolling TODO.md at project root

### Still Open from Handwritten List

> OCR'd from handwritten notes (see `website/docs/assets/images/hardware/handwritten-todo-list-week3-20260504.jpg`)

- [ ] Wire up and test speaker
- [ ] Put a speaker grill cutout for the case
- [ ] Research if wireless firmware deployment is possible to streamline deploy and testing pipeline
- [x] ~~Wednesday: wire up joystick mount~~ (done — wired and tested 2026-05-04)
- [ ] Add a chamfer and joystick retention square so that it fits around snugly the base of the joystick
- [ ] Determine a power on/off (leave power) mechanism
- [ ] With joystick implement menu and settings system
- [ ] Stand: create a landing page and progression synopsis; purge the stale folders and pointers; perhaps migrate to a V2 repo and project structure
- [ ] Compile a schematic for all the planned hardware; scour the web for best components and JLCPCB's basic components (add flash memory, high voltage level components)
- [ ] Estimate a board/print cost
- [ ] Run battery life benchmarks
- [ ] Estimate how thin this device could be with a dedicated board

### New Items from Today

- [ ] Fix KiCad joystick PCB Rev 2 — re-route with corrected COM/UP pin assignment, re-order from JLCPCB
- [ ] Verify all 5 joystick directions work with corrected wiring (swap COM/UP wires on current board as interim fix)
- [ ] Tune V4 two-pass partial refresh — blacks still slightly washed out with fast waveform, may need custom LUT or voltage adjustment
- [ ] Add pin-1 silkscreen dot to future PCB orders to prevent orientation ambiguity
- [ ] Investigate why V4 display's internal LUT produces weaker blacks than V3's custom LUT — may need to source V3 panels or create hybrid driver

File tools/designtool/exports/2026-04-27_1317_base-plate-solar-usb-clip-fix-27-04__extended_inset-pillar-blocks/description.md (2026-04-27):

# Export: base-plate-solar-usb-clip-fix-27-04 / extended_inset-pillar-blocks

- **Date:** 2026-04-27 13:17:21
- **SCAD:** `base-plate-solar-usb-clip-fix-27-04.scad`
- **Preset:** `extended_inset-pillar-blocks`
- **Formats:** stl, 3mf, FCStd

## Parameters

| Parameter | Value | Default | Changed |
|---|---|---|---|
| `$fn` | 48 |  | **yes** |
| `aaa_bay_diameter_mm` | 11.1 | 11.1 |  |
| `aaa_bay_length_along_x_mm` | 39 | 39 |  |
| `aaa_bay_minus_y_center_y_mm` | 7.85 | 7.85 |  |
| `aaa_bay_plus_y_center_y_mm` | 38.15 | 38.15 |  |
| `aaa_bay_x_start_global_mm` | 34 | 34 |  |
| `base_plate_shave_height_mm` | 2 | 2 |  |
| `base_plate_shave_start_z_mm` | 4 | 4 |  |
| `base_plate_total_height_z_mm` | 8 | 8 |  |
| `battery_cradle_extrusion_wall_mm` | 1.5 | 1.5 |  |
| `battery_rail_depth_reduction_per_side_mm` | 2 | 2 |  |
| `battery_rail_height_reduction_mm` | 2.5 | 2.5 |  |
| `battery_rail_z_lift_mm` | 5 | 5 |  |
| `corner_pillar_square_side_length_mm` | 5 | 5 |  |
| `cradle_plug_x_end_mm` | 93 | 93 |  |
| `cradle_plug_x_start_mm` | 3.3 | 3.3 |  |
| `cradle_plug_y_end_mm` | 43.7 | 43.7 |  |
| `cradle_plug_y_start_mm` | 2.3 | 2.3 |  |
| `cradle_pocket_floor_thickness_mm` | 2.5 | 2.5 |  |
| `cradle_pocket_xy_slop_per_edge_mm` | 0.2 | 0.2 |  |
| `enclosure_outer_depth_along_y_axis_mm` | 46 | 46 |  |
| `enclosure_outer_width_along_x_axis_mm` | 94.5 | 94.5 |  |
| `m3_screw_clearance_bore_diameter_mm` | 3.2 | 3.2 |  |
| `max_z_clip_mm` | 14 | 14 |  |
| `minus_x_end_wall_thickness_mm` | 3 | 3 |  |
| `outer_case_bottom_edge_fillet_radius_mm` | 2 | 2 |  |
| `outer_case_top_view_corner_radius_mm` | 4 | 4 |  |
| `peg_diameter_mm` | 3 | 3 |  |
| `peg_height_above_pillar_mm` | 3 | 3 |  |
| `peg_tip_chamfer_mm` | 0.4 | 0.4 |  |
| `perimeter_long_side_wall_thickness_y_mm_base` | 2 | 2 |  |
| `pico_retention_block_height_above_pocket_floor_mm` | 2 | 2 |  |
| `pico_retention_block_inset_from_minus_x_wall_mm` | 18 | 18 |  |
| `pico_retention_block_width_y_mm` | 15 | 15 |  |
| `pico_retention_block_x_size_mm` | 5 | 5 |  |
| `pillar_extension_per_corner_overrides` | [] | [] |  |
| `pillar_extension_x_inward_uniform_mm` | 27 | 5 | **yes** |
| `pillar_extension_y_inward_uniform_mm` | 4 | 4 |  |
| `pillar_extension_z_above_plate_mm` | -1.5 | -1.5 |  |
| `plus_x_end_wall_thickness_mm` | 1.2 | 1.2 |  |
| `solar_hole_1_x_mm` | 2.5 | 2.5 |  |
| `solar_hole_1_y_mm` | 2 | 2.0 | **yes** |
| `solar_hole_2_x_mm` | 60 | 60.0 | **yes** |
| `solar_hole_2_y_mm` | 2.4 | 2.4 |  |
| `solar_hole_diameter_mm` | 3.1 | 3.1 |  |
| `solar_pit_depth_y_mm` | 36.4 | 36.4 |  |
| `solar_pit_depth_z_mm` | 2 | 2.0 | **yes** |
| `solar_pit_width_x_mm` | 62.4 | 62.4 |  |
| `solar_support_enabled` | false | false |  |
| `solar_support_rib_spacing_mm` | 5 | 5.0 | **yes** |
| `solar_support_rib_thickness_mm` | 0.4 | 0.4 |  |
| `solar_support_z_gap_mm` | 0.2 | 0.2 |  |
| `usb_c_connector_height_mm` | 4.25 | 4.25 |  |
| `usb_c_connector_width_mm` | 9 | 9 |  |
| `usb_c_cutout_corner_r_mm` | 1 | 1.0 | **yes** |
| `usb_c_extra_width_per_side_mm` | 0 | 0 |  |
| `usb_c_tolerance_mm` | 0.2 | 0.2 |  |
| `usb_c_z_drop_mm` | 0.5 | 0.5 |  |
| `usb_sidewall_block_depth_x_mm` | 5 | 5 |  |
| `usb_sidewall_block_enabled` | false | false |  |
| `usb_sidewall_block_width_y_mm` | 30 | 30 |  |
| `usb_sidewall_block_z_top_clearance_below_cutout_mm` | 0.2 | 0.2 |  |
| `usb_support_block_height_above_cutout_bottom_mm` | 0 | 0 |  |
| `usb_support_block_inset_from_wall_mm` | 5 | 5 |  |
| `usb_support_block_width_y_mm` | 15 | 15 |  |
| `usb_support_block_x_gap_between_blocks_mm` | 5 | 5 |  |
| `usb_support_block_x_size_mm` | 5 | 5 |  |

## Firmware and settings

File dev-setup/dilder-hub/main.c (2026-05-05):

/**
 * Sassy Octopus — Runtime-rendered e-ink animation
 *
 * Instead of pre-baking every frame, this firmware renders each frame
 * on the fly: composites the octopus body, eyes, mouth expression,
 * chat bubble, and text at display time.  This means ALL quotes fit
 * in flash (~10KB of strings vs ~4MB of bitmaps).
 *
 * Wiring (same as all Dilder firmware):
 *   VCC  -> 3V3(OUT) pin 36    GND  -> GND      pin 38
 *   DIN  -> GP11     pin 15    CLK  -> GP10     pin 14
 *   CS   -> GP9      pin 12    DC   -> GP8      pin 11
 *   RST  -> GP12     pin 16    BUSY -> GP13     pin 17
 */

#include <stdio.h>
#include <stdlib.h>
#include <string.h>
#include <math.h>
#include <time.h>
#include "pico/stdlib.h"
#include "pico/cyw43_arch.h"
#include "hardware/pwm.h"
#include "hardware/adc.h"
#include "lwip/dns.h"
#include "lwip/pbuf.h"
#include "lwip/udp.h"
#include "rtc_compat.h"
#include "DEV_Config.h"
#include "version.h"
#include "wifi_config.h"

/* ─── Joystick pins ─── */
#define JOY_LEFT   2
#define JOY_DOWN   3
#define JOY_UP     4
#define JOY_RIGHT  5
#define JOY_CENTER 6

/* ─── Speaker (push-pull for 2x volume) ─── */
/* GP14 (pin 19) and GP15 (pin 20) share PWM slice 7, channels A and B.
 * By driving them in opposite phase, the piezo sees ~6.6Vpp instead of 3.3V.
 * Wire: piezo + → pin 20 (GP15), piezo - → pin 19 (GP14). No resistor needed. */
#define SPEAKER_A  14  /* GP14 = pin 19 (PWM7A) — inverted phase */
#define SPEAKER_B  15  /* GP15 = pin 20 (PWM7B) — normal phase */
static uint speaker_slice;

static void speaker_init(void) {
    gpio_set_function(SPEAKER_A, GPIO_FUNC_PWM);
    gpio_set_function(SPEAKER_B, GPIO_FUNC_PWM);
    speaker_slice = pwm_gpio_to_slice_num(SPEAKER_A);  /* same slice for both */
    pwm_set_enabled(speaker_slice, false);

    /* Invert channel A so it's opposite phase from channel B */
    pwm_set_output_polarity(speaker_slice, true, false);
}

static void speaker_tone(uint16_t freq_hz, uint16_t duration_ms) {
    if (freq_hz == 0) { pwm_set_enabled(speaker_slice, false); sleep_ms(duration_ms); return; }
    uint32_t wrap = 125000000 / freq_hz;
    if (wrap > 65535) wrap = 65535;
    pwm_set_wrap(speaker_slice, (uint16_t)wrap);
    /* Both channels at 50% duty — but A is inverted, so piezo sees full swing */
    pwm_set_chan_level(speaker_slice, PWM_CHAN_A, (uint16_t)(wrap / 2));
    pwm_set_chan_level(speaker_slice, PWM_CHAN_B, (uint16_t)(wrap / 2));
    pwm_set_enabled(speaker_slice, true);
    sleep_ms(duration_ms);
    pwm_set_enabled(speaker_slice, false);
}

/* ─── Joystick init ─── */
static void joystick_init(void) {
    const uint pins[] = {JOY_UP, JOY_DOWN, JOY_LEFT, JOY_RIGHT, JOY_CENTER};
    for (int i = 0; i < 5; i++) {
        gpio_init(pins[i]);
        gpio_set_dir(pins[i], GPIO_IN);
        gpio_pull_up(pins[i]);
    }
}

/* ─── Joystick read (returns single direction or 0) ─── */
#define INPUT_NONE   0
#define INPUT_UP     1
#define INPUT_DOWN   2
#define INPUT_LEFT   3
#define INPUT_RIGHT  4
#define INPUT_CENTER 5

static uint8_t read_joystick(void) {
    if (!gpio_get(JOY_UP))     return INPUT_UP;
    if (!gpio_get(JOY_DOWN))   return INPUT_DOWN;
    if (!gpio_get(JOY_LEFT))   return INPUT_LEFT;
    if (!gpio_get(JOY_RIGHT))  return INPUT_RIGHT;
    if (!gpio_get(JOY_CENTER)) return INPUT_CENTER;
    return INPUT_NONE;
}

/* ─── App states ─── */
#define STATE_OCTOPUS     0   /* main screen — octopus + quote + clock */
#define STATE_MENU        1   /* menu overlay */
#define STATE_SOUND       2   /* sound test sub-screen */
#define STATE_INFO        3   /* device info sub-screen */
#define STATE_MOOD_SELECT 4   /* mood picker */
#define STATE_NETWORK     5   /* WiFi status + toggle */

/* ─── WiFi state ─── */
static bool wifi_enabled = false;
static bool wifi_connected = false;
static bool ntp_synced = false;
static int32_t wifi_rssi = 0;
static char wifi_ssid_display[33] = "---";
static char wifi_ip_str[20] = "---";

/* ─── NTP ─── */
#define NTP_PORT 123
#define NTP_MSG_LEN 48
#define NTP_DELTA 2208988800ULL

static struct udp_pcb *ntp_pcb = NULL;
static ip_addr_t ntp_server_addr;
static volatile bool ntp_time_received = false;

/* ─── Mood names for the selector ─── */
static const char *mood_names[] = {
    "NORMAL", "WEIRD", "UNHINGED", "ANGRY",
    "SAD", "CHAOTIC", "HUNGRY", "TIRED",
    "SLAP HAPPY", "LAZY", "FAT", "CHILL",
    "CREEPY", "EXCITED", "NOSTALGIC", "HOMESICK",
};
#define MOOD_COUNT 16
static int current_mood = -1;  /* -1 = all moods (random) */

/* Display variant selection */
#if defined(DISPLAY_V2)
  #include "EPD_2in13_V2.h"
  #define DISP_W EPD_2in13_V2_WIDTH
  #define DISP_H EPD_2in13_V2_HEIGHT
  #define EPD_Init()     EPD_2in13_V2_Init()
  #define EPD_Clear()    EPD_2in13_V2_Clear()
  #define EPD_Display(b) EPD_2in13_V2_Display(b)
  #define EPD_Base(b)    EPD_2in13_V2_Display(b)
  #define EPD_Partial(b) EPD_2in13_V2_Display_Partial(b)
  #define EPD_Sleep()    EPD_2in13_V2_Sleep()
  #define DISPLAY_NAME   "V2"
#elif defined(DISPLAY_V3A)
  #include "EPD_2in13_V3a.h"
  #define DISP_W EPD_2in13_V3a_WIDTH
  #define DISP_H EPD_2in13_V3a_HEIGHT
  #define EPD_Init()     EPD_2in13_V3a_Init()
  #define EPD_Clear()    EPD_2in13_V3a_Clear()
  #define EPD_Display(b) EPD_2in13_V3a_Display(b)
  #define EPD_Base(b)    EPD_2in13_V3a_Display_Base(b)
  #define EPD_Partial(b) EPD_2in13_V3a_Display_Partial(b)
  #define EPD_Sleep()    EPD_2in13_V3a_Sleep()
  #define DISPLAY_NAME   "V3a"
#elif defined(DISPLAY_V4)
  #include "EPD_2in13_V4.h"
  #define DISP_W EPD_2in13_V4_WIDTH
  #define DISP_H EPD_2in13_V4_HEIGHT
  #define EPD_Init()     EPD_2in13_V4_Init()
  #define EPD_Clear()    EPD_2in13_V4_Clear()
  #define EPD_Display(b) EPD_2in13_V4_Display(b)
  #define EPD_Base(b)    EPD_2in13_V4_Display_Base(b)
  #define EPD_Partial(b) EPD_2in13_V4_Display_Partial(b)
  #define EPD_Sleep()    EPD_2in13_V4_Sleep()
  #define DISPLAY_NAME   "V4"
#else
  #include "EPD_2in13_V3.h"
  #define DISP_W EPD_2in13_V3_WIDTH
  #define DISP_H EPD_2in13_V3_HEIGHT
  #define EPD_Init()     EPD_2in13_V3_Init()
  #define EPD_Clear()    EPD_2in13_V3_Clear()
  #define EPD_Display(b) EPD_2in13_V3_Display(b)
  #define EPD_Base(b)    EPD_2in13_V3_Display_Base(b)
  #define EPD_Partial(b) EPD_2in13_V3_Display_Partial(b)
  #define EPD_Sleep()    EPD_2in13_V3_Sleep()
  #define DISPLAY_NAME   "V3"
#endif

/* Auto-generated quotes + tagline */
#include "quotes.h"

/* ─── Canvas constants ─── */
#define IMG_W         250
#define IMG_H         122
#define IMG_ROW_BYTES ((IMG_W + 7) / 8)  /* 32 */

/* Mood values (match quotes.h mood_map in devtool.py) */
#define MOOD_NORMAL   0
#define MOOD_WEIRD    1
#define MOOD_UNHINGED 2
#define MOOD_ANGRY    3
#define MOOD_SAD      4
#define MOOD_CHAOTIC  5
#define MOOD_HUNGRY   6
#define MOOD_TIRED    7
#define MOOD_SLAPHAPPY 8
#define MOOD_LAZY      9
#define MOOD_FAT       10
#define MOOD_CHILL     11
#define MOOD_CREEPY     12
#define MOOD_EXCITED   13
#define MOOD_NOSTALGIC 14
#define MOOD_HOMESICK  15

/* Mouth expressions */
#define EXPR_SMIRK    0
#define EXPR_OPEN     1
#define EXPR_SMILE    2
#define EXPR_WEIRD    3
#define EXPR_UNHINGED 4
#define EXPR_ANGRY    5
#define EXPR_SAD      6
#define EXPR_CHAOTIC  7
#define EXPR_HUNGRY   8
#define EXPR_TIRED    9
#define EXPR_SLAPHAPPY 10
#define EXPR_LAZY      11
#define EXPR_FAT       12
#define EXPR_CHILL     13
#define EXPR_CREEPY     14
#define EXPR_EXCITED   15
#define EXPR_NOSTALGIC 16
#define EXPR_HOMESICK  17

/* Landscape frame buffer (1 = black pixel, packed MSB-first) */
static uint8_t frame[IMG_ROW_BYTES * IMG_H];

/* Display buffer (portrait orientation for e-ink driver) */
static uint8_t display_buf[((DISP_W + 7) / 8) * DISP_H];

/* Vertical offset — pushes octopus + bubble down to make room for clock */
#define Y_OFF 12

/* ─── Body animation transform (set per-frame before rendering) ─── */
static int body_dx = 0;     /* global x shift */
static int body_dy = 0;     /* global y shift */
static int body_x_expand = 0; /* expand/shrink body spans (+ = wider) */
/* Per-row wobble amplitude and phase (for wavy effects) */
static float wobble_amp = 0;
static float wobble_freq = 0;
static float wobble_phase = 0;

static int row_wobble(int y) {
    if (wobble_amp == 0) return 0;
    return (int)(wobble_amp * sinf(y * wobble_freq + wobble_phase));
}

/* ─── Pixel helpers ─── */
static inline void px_set(int x, int y) {
    if (x >= 0 && x < IMG_W && y >= 0 && y < IMG_H)
        frame[y * IMG_ROW_BYTES + x / 8] |= (0x80 >> (x & 7));
}
static inline void px_clr(int x, int y) {
    if (x >= 0 && x < IMG_W && y >= 0 && y < IMG_H)
        frame[y * IMG_ROW_BYTES + x / 8] &= ~(0x80 >> (x & 7));
}
/* Offset versions — add Y_OFF + body transform before drawing */
static inline void px_set_off(int x, int y) {
    px_set(x + body_dx + row_wobble(y), y + Y_OFF + body_dy);
}
static inline void px_clr_off(int x, int y) {
    px_clr(x + body_dx + row_wobble(y), y + Y_OFF + body_dy);
}

/* ─── Octopus body (RLE: y, num_spans, x0, x1, ...) terminated by 0xFF ─── */
static const uint8_t body_rle[] = {
    10,1, 22,48,  11,1, 18,52,  12,1, 16,54,  13,1, 14,56,
    14,1, 13,57,  15,1, 12,58,  16,1, 11,59,  17,1, 10,60,
    18,1, 10,60,  19,1,  9,61,  20,1,  9,61,  21,1,  9,61,
    22,1,  9,61,  23,1,  9,61,  24,1,  9,61,  25,1,  9,61,
    26,1,  9,61,  27,1,  9,61,  28,1, 10,60,  29,1, 10,60,
    30,1, 10,60,  31,1, 10,60,  32,1, 10,60,  33,1, 10,60,
    34,1, 10,60,  35,1, 10,60,  36,1, 10,60,  37,1, 10,60,
    38,1, 10,60,  39,1, 10,60,  40,1, 10,60,  41,1, 11,59,
    42,1, 11,59,  43,1, 12,58,  44,1, 13,57,  45,1, 14,56,
    46,1, 12,58,  47,1, 11,59,  48,1, 10,60,  49,1, 10,60,
    50,1, 11,59,  51,1, 12,58,  52,1, 13,57,  53,1, 14,56,
    54,1, 15,55,
    /* Tentacles */
    55,5, 10,17, 21,28, 32,39, 43,50, 54,61,
    56,5,  8,15, 19,26, 30,37, 45,52, 56,63,
    57,5,  7,14, 18,24, 29,35, 47,53, 58,64,
    58,5,  6,12, 19,25, 31,37, 46,52, 57,63,
    59,5,  7,13, 21,27, 33,39, 44,50, 55,61,
    60,5,  8,14, 20,26, 31,37, 43,49, 54,60,
    61,5,  9,14, 18,24, 30,36, 44,50, 56,62,
    62,5,  8,13, 17,22, 31,37, 46,52, 57,63,
    63,5,  7,12, 18,23, 33,38, 45,51, 55,61,
    64,5,  8,13, 20,25, 32,37, 43,48, 54,59,
    65,5,  9,14, 19,24, 30,35, 44,49, 55,60,
    66,5, 10,14, 17,22, 31,36, 46,51, 57,62,
    67,5,  9,13, 18,22, 33,37, 45,50, 56,61,
    68,5,  8,12, 19,23, 32,36, 43,48, 54,59,
    69,5,  9,13, 21,25, 30,34, 44,48, 55,59,
    70,5, 10,14, 20,24, 31,35, 46,50, 57,61,
    71,5, 11,14, 18,22, 33,37, 45,49, 56,60,
    72,5, 10,13, 19,22, 32,35, 43,47, 54,58,
    73,5,  9,12, 20,23, 30,33, 44,47, 55,58,
    74,5, 10,13, 21,24, 31,34, 46,49, 57,60,
    75,5, 11,14, 20,23, 33,36, 45,48, 56,59,
    76,5, 12,14, 19,22, 32,35, 43,46, 54,57,
    77,5, 11,13, 20,22, 30,33, 44,46, 55,57,
    78,5, 10,12, 21,23, 31,33, 45,47, 56,58,
    79,5, 11,13, 22,24, 32,34, 44,46, 55,57,
    80,5, 12,14, 21,23, 33,35, 43,45, 54,56,
    0xFF /* terminator */
};

/* ─── 5×7 bitmap font ─── */
/* Index: A=0..Z=25, 0=26..9=35, ' '=36, .=37, ,=38, !=39, ?=40,
   '=41, -=42, ~=43, /=44, :=45, (=46, )=47, %=48 */
static const uint8_t font5x7[][7] = {
    {0x0e,0x11,0x11,0x1f,0x11,0x11,0x11}, /* A */
    {0x1e,0x11,0x11,0x1e,0x11,0x11,0x1e}, /* B */
    {0x0e,0x11,0x10,0x10,0x10,0x11,0x0e}, /* C */
    {0x1e,0x11,0x11,0x11,0x11,0x11,0x1e}, /* D */
    {0x1f,0x10,0x10,0x1e,0x10,0x10,0x1f}, /* E */
    {0x1f,0x10,0x10,0x1e,0x10,0x10,0x10}, /* F */
    {0x0e,0x11,0x10,0x17,0x11,0x11,0x0e}, /* G */
    {0x11,0x11,0x11,0x1f,0x11,0x11,0x11}, /* H */
    {0x1f,0x04,0x04,0x04,0x04,0x04,0x1f}, /* I */
    {0x07,0x02,0x02,0x02,0x02,0x12,0x0c}, /* J */
    {0x11,0x12,0x14,0x18,0x14,0x12,0x11}, /* K */
    {0x10,0x10,0x10,0x10,0x10,0x10,0x1f}, /* L */
    {0x11,0x1b,0x15,0x15,0x11,0x11,0x11}, /* M */
    {0x11,0x11,0x19,0x15,0x13,0x11,0x11}, /* N */
    {0x0e,0x11,0x11,0x11,0x11,0x11,0x0e}, /* O */
    {0x1e,0x11,0x11,0x1e,0x10,0x10,0x10}, /* P */
    {0x0e,0x11,0x11,0x11,0x15,0x12,0x0d}, /* Q */
    {0x1e,0x11,0x11,0x1e,0x14,0x12,0x11}, /* R */
    {0x0e,0x11,0x10,0x0e,0x01,0x11,0x0e}, /* S */
    {0x1f,0x04,0x04,0x04,0x04,0x04,0x04}, /* T */
    {0x11,0x11,0x11,0x11,0x11,0x11,0x0e}, /* U */
    {0x11,0x11,0x11,0x11,0x0a,0x0a,0x04}, /* V */
    {0x11,0x11,0x11,0x15,0x15,0x15,0x0a}, /* W */
    {0x11,0x11,0x0a,0x04,0x0a,0x11,0x11}, /* X */
    {0x11,0x11,0x0a,0x04,0x04,0x04,0x04}, /* Y */
    {0x1f,0x01,0x02,0x04,0x08,0x10,0x1f}, /* Z */
    {0x0e,0x11,0x13,0x15,0x19,0x11,0x0e}, /* 0 */
    {0x04,0x0c,0x04,0x04,0x04,0x04,0x0e}, /* 1 */
    {0x0e,0x11,0x01,0x06,0x08,0x10,0x1f}, /* 2 */
    {0x0e,0x11,0x01,0x06,0x01,0x11,0x0e}, /* 3 */
    {0x02,0x06,0x0a,0x12,0x1f,0x02,0x02}, /* 4 */
    {0x1f,0x10,0x1e,0x01,0x01,0x11,0x0e}, /* 5 */
    {0x0e,0x11,0x10,0x1e,0x11,0x11,0x0e}, /* 6 */
    {0x1f,0x01,0x02,0x04,0x08,0x08,0x08}, /* 7 */
    {0x0e,0x11,0x11,0x0e,0x11,0x11,0x0e}, /* 8 */
    {0x0e,0x11,0x11,0x0f,0x01,0x11,0x0e}, /* 9 */
    {0x00,0x00,0x00,0x00,0x00,0x00,0x00}, /* ' ' */
    {0x00,0x00,0x00,0x00,0x00,0x0c,0x0c}, /* . */
    {0x00,0x00,0x00,0x00,0x04,0x04,0x08}, /* , */
    {0x04,0x04,0x04,0x04,0x04,0x00,0x04}, /* ! */
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
};

static const char font_chars[] = "ABCDEFGHIJKLMNOPQRSTUVWXYZ0123456789 .,!?'-~/:()\%";

static int font_index(char c) {
    for (int i = 0; font_chars[i]; i++)
        if (font_chars[i] == c) return i;
    return 36; /* space fallback */
}

/* ─── Drawing primitives ─── */

static void fill_circle(int cx, int cy, int r_sq, int set) {
    int r = 5;
    for (int dy = -r; dy <= r; dy++)
        for (int dx = -r; dx <= r; dx++)
            if (dx * dx + dy * dy <= r_sq) {
                if (set) px_set_off(cx + dx, cy + dy);
                else     px_clr_off(cx + dx, cy + dy);
            }
}
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
int main(void) {
    stdio_init_all();
    sleep_ms(1000);
    printf("DILDER HUB v%s (%s) | display: %s | %d quotes | built %s %s\n",
           DILDER_VERSION, DILDER_VERSION_DATE, DISPLAY_NAME, QUOTE_COUNT, __DATE__, __TIME__);

    init_rtc_from_compile_time();

    if (DEV_Module_Init() != 0) {
        printf("ERROR: Hardware init failed.\n");
        return 1;
    }

    joystick_init();
    speaker_init();

    /* Startup chime */
    speaker_tone(1000, 80); sleep_ms(30);
    speaker_tone(1500, 80); sleep_ms(30);
    speaker_tone(2000, 120);

    EPD_Init();
    EPD_Clear();
    rng_seed();
    battery_init();

    /* ─── State machine ─── */
    uint8_t state = STATE_OCTOPUS;
    uint32_t frame_idx = 0;
    int qi = pick_quote();
    int menu_sel = 0;
    int mood_sel = 0;  /* 0 = ALL, 1-16 = specific mood */

    const char *snd_dir = "NONE";
    uint16_t snd_freq = 0;
    int snd_presses = 0;

    uint32_t last_input_ms = 0;
    #define INPUT_DEBOUNCE 200

    /* Helper macro for polling input in sub-screens */
    #define POLL_INPUT(ms) \
        for (int _pi = 0; _pi < ((ms)/20); _pi++) { \
            sleep_ms(20); \
            if (wifi_enabled) cyw43_arch_poll(); \
            if (to_ms_since_boot(get_absolute_time()) - last_input_ms < INPUT_DEBOUNCE) continue; \
            uint8_t inp = read_joystick(); \
            if (inp == INPUT_NONE) continue; \
            last_input_ms = to_ms_since_boot(get_absolute_time());

    #define POLL_END break; }

    while (true) {
        uint32_t now = to_ms_since_boot(get_absolute_time());

        /* Poll WiFi if connected */
        if (wifi_enabled) cyw43_arch_poll();

        switch (state) {

        /* ════════ OCTOPUS MAIN SCREEN ════════ */
        case STATE_OCTOPUS: {
            const Quote *q = &quotes[qi];
            const uint8_t *cycle = mood_cycle(q->mood);
            uint8_t expr = cycle[frame_idx % 4];

            if (expr == EXPR_OPEN && frame_idx > 0)
                qi = pick_quote();

            render_frame(&quotes[qi], expr, frame_idx);
            /* WiFi icon top-left, battery icon top-right */
            draw_wifi_icon(0, 1, wifi_connected);
            draw_battery_icon(234, 1);
            draw_text(175, 113, "DOWN:MENU", IMG_W);
            transpose_to_display();

            EPD_Partial(display_buf);
            frame_idx++;

            /* Poll 3 seconds for joystick */
            for (int i = 0; i < 150 && state == STATE_OCTOPUS; i++) {
                sleep_ms(20);
                if (wifi_enabled) cyw43_arch_poll();
                if (to_ms_since_boot(get_absolute_time()) - last_input_ms < INPUT_DEBOUNCE) continue;
                uint8_t inp = read_joystick();
                if (inp == INPUT_DOWN) {
                    last_input_ms = to_ms_since_boot(get_absolute_time());
                    state = STATE_MENU; menu_sel = 0;
                    speaker_tone(800, 50);
                } else if (inp == INPUT_CENTER) {
                    last_input_ms = to_ms_since_boot(get_absolute_time());
                    speaker_tone(1319, 100);
                }
            }
            break;
        }

        /* ════════ MENU ════════ */
        case STATE_MENU: {
            const Quote *q = &quotes[qi];
            render_frame(q, mood_cycle(q->mood)[frame_idx % 4], frame_idx);
            render_menu(menu_sel);
            transpose_to_display();
            EPD_Partial(display_buf);

            POLL_INPUT(4000)
                if (inp == INPUT_UP) {
                    menu_sel = (menu_sel - 1 + MENU_COUNT) % MENU_COUNT;
                    speaker_tone(600, 30); break;
                } else if (inp == INPUT_DOWN) {
                    menu_sel = (menu_sel + 1) % MENU_COUNT;
                    speaker_tone(600, 30); break;
                } else if (inp == INPUT_CENTER) {
                    speaker_tone(1000, 50);
                    
                    switch (menu_sel) {
                        case 0: state = STATE_MOOD_SELECT; mood_sel = current_mood + 1; break;
                        case 1: state = STATE_NETWORK; break;
                        case 2: state = STATE_SOUND; snd_dir="NONE"; snd_freq=0; snd_presses=0; break;
                        case 3: state = STATE_INFO; break;
                        default: state = STATE_OCTOPUS; break;
                    }
                    break;
                } else if (inp == INPUT_LEFT) {
                    state = STATE_OCTOPUS; 
                    speaker_tone(500, 50); break;
                }
            POLL_END
            break;
        }

        /* ════════ MOOD SELECT ════════ */
        case STATE_MOOD_SELECT: {
            render_mood_select(mood_sel);
            transpose_to_display();
            EPD_Partial(display_buf);

            POLL_INPUT(4000)
                if (inp == INPUT_UP) {
                    mood_sel = (mood_sel - 1 + MOOD_COUNT + 1) % (MOOD_COUNT + 1);
                    speaker_tone(600, 30); break;
                } else if (inp == INPUT_DOWN) {
                    mood_sel = (mood_sel + 1) % (MOOD_COUNT + 1);
                    speaker_tone(600, 30); break;
                } else if (inp == INPUT_CENTER) {
                    current_mood = mood_sel == 0 ? -1 : mood_sel - 1;
                    qi = pick_quote();
                    frame_idx = 0;  /* reset animation */
                    state = STATE_OCTOPUS;  /* return to octopus */
                    speaker_tone(1200, 80);
                    printf("[mood] Selected: %s → back to octopus\n",
                           current_mood < 0 ? "ALL" : mood_names[current_mood]);
                    break;
                } else if (inp == INPUT_LEFT) {
                    state = STATE_MENU; 
                    speaker_tone(500, 50); break;
                }
            POLL_END
            break;
        }

        /* ════════ NETWORK ════════ */
        case STATE_NETWORK: {
            render_network_screen();
            transpose_to_display();
            EPD_Partial(display_buf);

            POLL_INPUT(4000)
                if (inp == INPUT_CENTER) {
                    speaker_tone(1000, 50);
                    if (wifi_enabled) wifi_disconnect();
                    else wifi_connect();
                    
                    break;
                } else if (inp == INPUT_LEFT) {
                    state = STATE_MENU; 
                    speaker_tone(500, 50); break;
                }
            POLL_END
            break;
        }

        /* ════════ SOUND TEST ════════ */
        case STATE_SOUND: {
            render_sound_screen(snd_dir, snd_freq, snd_presses);
            transpose_to_display();
            EPD_Partial(display_buf);

            POLL_INPUT(2000)
                if (inp == INPUT_LEFT) {
                    state = STATE_MENU; 
                    speaker_tone(500, 50); break;
                }
                snd_presses++;
                if (inp == INPUT_UP)     { snd_dir="UP";     snd_freq=TONE_UP;     speaker_tone(TONE_UP, 150); }
                if (inp == INPUT_DOWN)   { snd_dir="DOWN";   snd_freq=TONE_DOWN;   speaker_tone(TONE_DOWN, 150); }
                if (inp == INPUT_RIGHT)  { snd_dir="RIGHT";  snd_freq=TONE_RIGHT;  speaker_tone(TONE_RIGHT, 150); }
                if (inp == INPUT_CENTER) { snd_dir="CENTER"; snd_freq=TONE_CENTER; speaker_tone(TONE_CENTER, 200); }
            POLL_END
            break;
        }

        /* ════════ DEVICE INFO ════════ */
        case STATE_INFO: {
            render_info_screen();
            transpose_to_display();
            EPD_Partial(display_buf);

            POLL_INPUT(4000)
                if (inp == INPUT_LEFT || inp == INPUT_CENTER) {
                    state = STATE_MENU; 
                    speaker_tone(500, 50); break;
                }
            POLL_END
            break;
        }

        } /* end switch */
    }

    return 0;
}

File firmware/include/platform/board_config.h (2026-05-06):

/*
 * board_config.h -- Compile-time board selection and pin definitions
 *
 * Provides a unified set of pin/peripheral macros that abstract over the
 * target hardware.  Each board defines the same macro names so the game
 * engine and display driver can use them without #ifdef everywhere.
 *
 * Currently supported boards:
 *   - BOARD_PICO_W       Raspberry Pi Pico W  (RP2040, SPI1)
 *   - BOARD_PICO2_W      Raspberry Pi Pico 2 W  (RP2350, SPI1)
 *   - BOARD_ESP32S3      Olimex ESP32-S3-DevKit-Lipo  (ESP32-S3, FSPI)
 *
 * Set the target board at build time:
 *   cmake  -DTARGET_BOARD=PICO_W ..
 *   cmake  -DTARGET_BOARD=PICO2_W ..
 *   cmake  -DTARGET_BOARD=ESP32S3 ..
 * Or in platformio.ini:
 *   build_flags = -DBOARD_ESP32S3
 */

/*
 * --------------------------------------------------------------------------
 *  BEGINNER NOTES: What is this file doing?
 * --------------------------------------------------------------------------
 *
 *  Different boards have their components wired to different GPIO pins.
 *  For example, the e-Paper display clock wire is connected to:
 *    - GPIO 10 on the Pico W
 *    - GPIO 12 on the ESP32-S3
 *
 *  Instead of scattering these pin numbers throughout the codebase
 *  (which would make switching boards a nightmare), we define them
 *  all HERE using #define macros with consistent names.
 *
 *  The rest of the code just uses PIN_EPD_CLK everywhere.  This file
 *  ensures PIN_EPD_CLK expands to the right number for whichever board
 *  we're building for.
 *
 *  Think of it like a wiring diagram in code form: "On this board,
 *  the clock wire goes to pin 12, the data wire goes to pin 11, ..."
 * --------------------------------------------------------------------------
 */

/*
 * --------------------------------------------------------------------------
 *  BEGINNER NOTES: #if defined() / #elif / #else preprocessor chains
 * --------------------------------------------------------------------------
 *
 *  The C preprocessor can make decisions at COMPILE TIME using conditional
 *  directives.  This is different from if/else in regular code, which
 *  makes decisions at RUN TIME.
 *
 *  Preprocessor conditionals actually REMOVE code from the source before
 *  the compiler sees it.  Only the branch that matches gets compiled.
 *  The other branches are thrown away entirely.
 *
 *  Here's the pattern used in this file:
 *
 *    #if defined(BOARD_PICO_W)        // Is BOARD_PICO_W defined?
 *      ... Pico W pin definitions ... // YES: use these
 *
 *    #elif defined(BOARD_PICO2_W)    // Otherwise, is BOARD_PICO2_W defined?
 *      ... Pico 2 W pin definitions  // YES: use these (same pins, more flash)
 *
 *    #elif defined(BOARD_ESP32S3)     // Otherwise, is BOARD_ESP32S3 defined?
 *      ... ESP32-S3 pin definitions . // YES: use these
 *
 *    #else                            // Neither was defined
 *      ... Desktop dummy values ..... // Use these as fallback
 *
 *    #endif                           // End of the conditional chain
 *
 *  "defined(X)" returns true if the symbol X has been #defined, either
 *  in code or via a compiler flag like -DBOARD_ESP32S3.
 *
 *  This is like a switch statement, but it happens before compilation.
 *  Only ONE set of pin definitions ends up in the compiled binary.
 *
 *  You can also use #ifdef X as shorthand for #if defined(X), but
 *  #if defined() is more flexible because you can combine conditions:
 *    #if defined(BOARD_PICO_W) || defined(PICO_BOARD)
 *  This means "if either BOARD_PICO_W or PICO_BOARD is defined."
 * --------------------------------------------------------------------------
 */

/*
 * --------------------------------------------------------------------------
 *  BEGINNER NOTES: BOARD_NAME, BOARD_FLASH_KB, and other constants
 * --------------------------------------------------------------------------
 *
 *  Besides pin numbers, each board section defines:
 *
 *  BOARD_NAME — A human-readable string like "Pico W" or "ESP32-S3 (Olimex)".
 *    Used in log messages, status displays, etc.  It doesn't affect
 *    hardware behavior — it's just for humans reading debug output.
 *
 *  BOARD_FLASH_KB — The amount of flash memory (in kilobytes) on the board.
 *    The Pico W has 2 MB (2048 KB), the ESP32-S3 has 8 MB (8192 KB).
 *    This could be used to adjust how much data we store (save files,
 *    game assets, etc.) based on available space.
 *
 *  EPD_SPI_CONTROLLER — Which SPI hardware block to use (see below).
 *
 *  EPD_SPI_FREQ_HZ — The SPI clock speed in Hertz.  4,000,000 = 4 MHz,
 *    meaning 4 million clock pulses per second.  The e-Paper display
 *    datasheet specifies the maximum safe speed.
 * --------------------------------------------------------------------------
 */
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

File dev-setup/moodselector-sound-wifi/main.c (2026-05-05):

/**
 * Joystick + Speaker + WiFi Test
 *
 * Connects to WiFi, syncs time via NTP, shows WiFi status icon on display.
 * Joystick plays tones. Display shows real network time, SSID, signal, and
 * a WiFi emblem (solid = connected, crossed = disconnected).
 *
 * Wiring (same as joystick-sound-test):
 *   Display SPI1: CLK=GP10, DIN=GP11, CS=GP9, DC=GP8, RST=GP12, BUSY=GP13
 *   Joystick:     COM=GND(pin3), L=GP2, D=GP3, UP=GP4, R=GP5, C=GP6
 *   Speaker:      +=GP15(pin20), -=GND(pin23 or any GND)
 */

#include <stdio.h>
#include <stdlib.h>
#include <string.h>
#include <time.h>
#include "pico/stdlib.h"
#include "pico/cyw43_arch.h"
#include "hardware/pwm.h"
#include "hardware/gpio.h"
#include "hardware/adc.h"
// hardware/rtc.h only exists on RP2040 — RP2350 uses pico_aon_timer
#if !defined(PICO_RP2350)
#include "hardware/rtc.h"
#endif
#include "lwip/dns.h"
#include "lwip/pbuf.h"
#include "lwip/udp.h"
#include "DEV_Config.h"
#include "version.h"
#include "wifi_config.h"

/* Display variant selection */
#if defined(DISPLAY_V4)
  #include "EPD_2in13_V4.h"
  #define DISP_W EPD_2in13_V4_WIDTH
  #define DISP_H EPD_2in13_V4_HEIGHT
  #define EPD_Init()     EPD_2in13_V4_Init()
  #define EPD_Clear()    EPD_2in13_V4_Clear()
  #define EPD_Base(b)    EPD_2in13_V4_Display_Base(b)
  #define EPD_Partial(b) EPD_2in13_V4_Display_Partial(b)
  #define EPD_Sleep()    EPD_2in13_V4_Sleep()
  #define DISPLAY_NAME   "V4"
#else
  #include "EPD_2in13_V3.h"
  #define DISP_W EPD_2in13_V3_WIDTH
  #define DISP_H EPD_2in13_V3_HEIGHT
  #define EPD_Init()     EPD_2in13_V3_Init()
  #define EPD_Clear()    EPD_2in13_V3_Clear()
  #define EPD_Base(b)    EPD_2in13_V3_Display_Base(b)
  #define EPD_Partial(b) EPD_2in13_V3_Display_Partial(b)
  #define EPD_Sleep()    EPD_2in13_V3_Sleep()
  #define DISPLAY_NAME   "V3"
#endif

/* ─── Pin definitions ─── */
#define JOY_LEFT   2
#define JOY_DOWN   3
#define JOY_UP     4
#define JOY_RIGHT  5
#define JOY_CENTER 6
#define SPEAKER    15  /* GP15 = pin 20 (PWM) */

#define DEBOUNCE_MS 200

/* Tone frequencies */
#define TONE_UP     1047
#define TONE_DOWN    784
#define TONE_LEFT    880
#define TONE_RIGHT   988
#define TONE_CENTER 1319

static const uint16_t melody_freq[] = { 1047, 1319, 1568, 1319, 1047, 0 };
static const uint16_t melody_dur[]  = {  100,  100,  200,  100,  200, 0 };

/* ─── Canvas ─── */
#define IMG_W         250
#define IMG_H         122
#define IMG_ROW_BYTES ((IMG_W + 7) / 8)

static uint8_t frame[IMG_ROW_BYTES * IMG_H];
static uint8_t display_buf[((DISP_W + 7) / 8) * DISP_H];

/* ─── WiFi state ─── */
static bool wifi_connected = false;
static bool ntp_synced = false;
static int32_t wifi_rssi = 0;
static char wifi_ssid_display[33] = "---";
static char wifi_ip_str[20] = "---";

/* ─── NTP state ─── */
#define NTP_PORT 123
#define NTP_MSG_LEN 48
#define NTP_DELTA 2208988800ULL  /* seconds between 1900 and 1970 */

static struct udp_pcb *ntp_pcb = NULL;
static ip_addr_t ntp_server_addr;
static bool ntp_request_sent = false;
static volatile bool ntp_time_received = false;
static time_t ntp_epoch = 0;

/* ─── Speaker PWM ─── */
static uint speaker_slice;

static void speaker_init(void) {
    gpio_set_function(SPEAKER, GPIO_FUNC_PWM);
    speaker_slice = pwm_gpio_to_slice_num(SPEAKER);
    pwm_set_enabled(speaker_slice, false);
}

static void speaker_tone(uint16_t freq_hz, uint16_t duration_ms) {
    if (freq_hz == 0) { sleep_ms(duration_ms); return; }
    uint32_t wrap = 125000000 / freq_hz;
    if (wrap > 65535) wrap = 65535;
    pwm_set_wrap(speaker_slice, (uint16_t)wrap);
    pwm_set_chan_level(speaker_slice, pwm_gpio_to_channel(SPEAKER), (uint16_t)(wrap / 2));
    pwm_set_enabled(speaker_slice, true);
    sleep_ms(duration_ms);
    pwm_set_enabled(speaker_slice, false);
}

static void speaker_melody(const uint16_t *freqs, const uint16_t *durs) {
    for (int i = 0; freqs[i] != 0 || durs[i] != 0; i++) {
        speaker_tone(freqs[i], durs[i]);
        sleep_ms(30);
    }
}

/* ─── Pixel drawing ─── */
static inline void px_set(int x, int y) {
    if (x >= 0 && x < IMG_W && y >= 0 && y < IMG_H)
        frame[y * IMG_ROW_BYTES + x / 8] |= (0x80 >> (x & 7));
}

static inline void px_clr(int x, int y) {
    if (x >= 0 && x < IMG_W && y >= 0 && y < IMG_H)
        frame[y * IMG_ROW_BYTES + x / 8] &= ~(0x80 >> (x & 7));
}
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

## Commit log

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2026-04-11 Update website with Tools docs, blog post, prompt log, and DevTool Programs tab
    Add three new tool documentation pages (DevTool GUI, Setup CLI, Website Dev CLI),
    a blog post covering Phase 1 dev tooling, and sync the prompt log through Prompt #42.
    Update project structure, homepage, and docs index to reflect current state.
    Include DevTool Programs tab with pixel art animations and brush-size fix.
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2026-04-12 Fix Docker build system: clean builds, shared lib volume, and CMake updates
    dev-setup/Dockerfile:
    - Force clean build directory (rm -rf build && mkdir) to prevent stale
    CMake cache issues on rebuild
    dev-setup/docker-compose.yml:
    - Add shared library volume mount (./hello-world/lib:/project/lib) so
    Waveshare display drivers are available inside Docker containers
    dev-setup/hello-world/ and dev-setup/sassy-octopus/:
    - Update CMakeLists.txt and main.c with build system improvements
    [main.c]
2026-04-12 Add comprehensive test framework with 162 tests and screenshot pipeline
    testing/ (new directory):
    - test.py: Interactive CLI test runner with install, run, watch, guides,
    screenshots, clean, report, and status commands
    - conftest.py: Shared fixtures for project root, screenshot directories
    - pytest.ini: Configuration with markers (screenshot, slow, hardware, website)
    - requirements.txt: pytest, playwright, Pillow, pyserial, ansi2html
    testing/devtool/ (90 tests):
    - test_display_emulator.py: Canvas init, all 6 drawing tools, clear, invert,
    save/load PBM/BIN, tool selection, 6 screenshot captures per tool
    - test_serial_monitor.py: UI state, port detection, connect/disconnect, output
    - test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
    [test_asset_manager.py, test_build_flash.py, test_cli_navigation.py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]
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2026-04-12 Add Hungry, Tired, and Slap Happy octopus programs
    Three new emotional octopus programs with unique expressions and quotes:
    - Hungry Octopus: upward-staring pupils (eyeing food), drooling wide
    open mouth with drip drops, 30 food-obsessed quotes ("I WOULD SELL
    3 OF MY HEARTS FOR A GOOD TACO")
    - Tired Octopus: half-closed eyelids (top half of eye sockets filled
    black), tiny sleepy pupils low in sockets, tall yawn mouth, 30
    exhaustion quotes ("I THINK I FELL ASLEEP MIDSENTENCE ONCE AND
    NOBODY NOTI")
    - Slap Happy Octopus: one eye squinted shut (line slit), one manic
    oversized pupil, wide wobbly sine-wave grin, 30 deliriously giddy
    quotes ("SOMEONE SAID MOIST AND I LOST IT")
    Updat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
    [main.c]
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2026-04-12 Fix blog author avatar — use numeric GitHub user ID
    The avatar URL used the username (rompasaurus) instead of the
    numeric user ID (600873). GitHub avatar URLs require the ID.
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2026-04-14 Fix KiCad schematic — remove invalid comment syntax, fix project UUID
    Removed ;; comment lines that KiCad's S-expression parser cannot handle.
    Fixed malformed UUID in project sheets reference. Schematic now loads
    cleanly in KiCad 8+.
    [dilder-breadboard.kicad_sch]
2026-04-14 Delete broken KiCad schematic, rewrite breadboard guide v2.0
    Removed KiCad project (hand-written S-expression schematics are too
    error-prone). Rewrote breadboard wiring guide: removed speaker section,
    added 3.3V speaker recommendations table (CMT-4023S, CSS-0578, passive
    buzzer modules), fixed ASCII diagrams to use consistent box-drawing
    characters, cleaned up pin map alignment, updated GPIO count to 15
    used / 11 free with GP15 reserved for future buzzer.
    [dilder-breadboard.kicad_sch]
2026-04-14 Add joystick-mood-selector firmware with GPIO input and on-screen indicator
    New interactive program that builds on the mood-selector: LEFT/RIGHT cycle
    moods, UP = random mood, DOWN = new quote, CENTER = reset to SASSY. Last
    input (LEFT, RIGHT, UP, DOWN, CTR, or SER:x) shown on the right side of
    the status bar. 200ms debounce, serial input still works as fallback.
    Registered in DevTool Programs tab under Interactive category.
    [main.c]
2026-04-14 Update Prompts #142 with joystick firmware, build errors, and wiring fix
    Logged joystick-mood-selector development session including Docker compose
    missing service error, accidental build artifact commit, and CENTER button
    wiring mixup (GND pin 8 vs GP6 pin 9). Added commit hashes to #138-142.
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2026-04-15 Add gameplay architecture planning docs, BME280→AHT20 update, blog post, Prompt #160
    12 gameplay planning documents defining the full firmware architecture with
    pseudocode, data structures, and module interfaces for the Dilder game loop.
    Updated all docs to replace BME280 with AHT20 temp/humidity sensor ($0.43
    vs $4, I2C 0x38). New blog post covering the gameplay architecture design.
2026-04-15 Clean up spelling and grammar in PromptProgression.md
    - colour → color, modelling → modeling, moulding → molding
    - Fix grammar in Prompts #64, #140, #149 (missing commas, proper → properly)
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2026-04-22 Trim windowed plate rails by 0.5mm and widen board cradle cutout by 1mm per side
    Rails stay flush with plate edges, trimmed from the display side only for
    easier screen insertion. Board cradle cutout gains 1mm clearance per side
    for better board wiggle room.
    [case-separator-board-cradle.scad, top-plate-windowed-v1.scad]
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2026-04-22 Add Rev 2 joystick base v1 — SCAD, renders, docs page, blog post
    New parametric base for the extended-with-joystick layout:
    82 × 44 × 22mm outer, split battery/ESP32 chambers with 2mm overhang
    shelf, dual USB-C cutouts, asymmetric end walls (1.2mm +X / 3mm -X),
    four M3 corner pillars clipped to the bottom fillet so their outer
    corners no longer poke past the curved front face.
    - hardware-design/scad Parts/Rev 2 extended with joystick/base-v1.scad
    + matching base-v1.stl / .3mf / design-plan.md (measurements read off
    sketches IMG20260422215826.jpg / IMG20260422215927.jpg).
    - Six orthographic + ISO renders (top, side, +X end, iso, USB-C closeup,
    shelf-divet closeup) rendered with the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
    [base-v1.3mf, base-v1.scad, base-v1.stl]
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2026-04-23 Rev 2 top cover (windowed) v1 + docs/blog
    New part: `top-cover-windowed-v1.scad`. Outer footprint 91.5 × 44mm
    matches base-v1 and middle-platform-v1 so the M3 through-bolts line up
    through the whole stack. Combines two Rev 1 patterns — the curved
    bullnose top from `top-cover-v3-rounded-top` and the ±Y snap-rail
    display housing from `top-plate-windowed-v1` — plus a tapered joystick
    through-hole on the +X half of the face plate.
    Key choices:
    - Bullnose radius 4mm (big enough to read as a rolled edge across the
    whole front face, not just a corner fillet).
    - Face plate 0.5mm — minimum-printable thin bezel.
    - Display window + joystick hole are both `hull()` frustums — true size
    at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
    [top-cover-windowed-v1-1.3mf, top-cover-windowed-v1.3mf, top-cover-windowed-v1.scad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]
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2026-04-24 Rev 2 screen-inlay top cover — first-print fixes + docs
    Three changes to the inlay cover variants after the first print showed
    what needed tuning:
    - Face plate 0.5 → 0.7 mm on both inlay variants. 0.5 mm printed as
    one perimeter + one thin top layer and left a hairline seam along
    the top edge of the inlay recess where the skin didn't fully close.
    0.7 mm gives the slicer enough material for a proper multi-layer
    top skin.
    - Removed the 4 joystick-PCB mount bores (they printed as a ring of
    dimples around the joystick cutout on the underside; retention
    strategy still TBD — glue / press-fit / heat-set inserts all on
    the table). Parameter definitions kept in the SCAD so the ge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
    [base-v1.scad, middle-platform-v1.scad, top-cover-windowed-screen-inlay-v1-2mm.3mf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]
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2026-04-24 Rev 2 Pico 2 cover + dual-10440 case redesign — iteration pass
    Top cover window refinements (v1-2mm, pico2-v2):
    - display_viewing_window depth 27 → 24, shift_toward_joystick 3 → 2.8
    - New top-cover-windowed-screen-inlay-pico2-v2-2mm.scad variant with
    +0.05 mm/edge Y slop on the screen inlay for easier Pico 2 module fit
    and -1 mm/edge window shrink once the spacing dialed in
    Battery layout redesign (photos → SCAD):
    - Photo study showed 3000 mAh pouch overhangs the Rev 2 case by ~5 mm
    and stacks above the Pico — switched strategy to two slim cells
    flanking the board
    - Follow-up study used 2x AAA for form-factor fit check; critical
    voltage note: keep the chemistry on 3.7 V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
    [base-v2-thin-dual-10440.scad, base-v3-2piece.scad, base-v4-2piece-open.scad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]
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2026-04-25 Rev 2 cradle insert + base plate + FreeCAD export + historical archive
    - Adds aaa-cradle-insert-v1.scad: drop-in plug shaped to the cover's
    negative space, holds 2× AAA cells along ±Y long edges, Pico nest
    through-cut down the middle, FPC ribbon gap, connecting block at
    the -X end of the Pico nest.
    - Adds base-plate-v1.scad: shallow tray with 4 snap pegs that slide
    into the cover's blind M3 bores; pocket receives the cradle's
    bottom 5.1 mm. Stack collapses to base plate + cradle + cover.
    - Adds freecad-export/ with STEP, FCStd, and CSG copies of the v1
    cover family + BLUEPRINTS.md + FREECAD-GUIDE.md + 5 ortho views.
    - Adds historical-archive/ with 15 dated SCAD snapshots and an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
    [2026-04-24_2110_base-v1__1000mAh-flat-cell-44y.scad, 2026-04-24_2110_middle-platform-v1__44y-with-pedestal.scad, 2026-04-24_2110_top-cover-windowed-screen-inla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]
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2026-04-25 Joystick PCB Rev 2.0 — kleeb footprint, datasheet pinout, headless autoroute
    Rev 1 of the joystick breakout shipped with three real bugs: a hand-drawn
    SKRHABE010 footprint with the wrong pad geometry, a wire pad that
    physically overlapped a mounting hole, and three pin assignments that
    didn't match the Alps datasheet. Rev 2.0 fixes all three by cloning
    proven references and adding machine-checkable verification.
    PCB / schematic
    - Footprint: cloned from crides/kleeb SKRHA-boss (production-tested in
    shipping keyboards), rotated -45° so pads land axis-aligned on the
    body's left/right faces. Includes the two NPTH alignment posts and
    two SMD anchor pads from the source.
    - Pin names conf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
    [base-plate-v1-2mm-thinner.scad, base-plate-v1-2mm-thinner__baseplatethiiiiiiin.3mf, base-plate-v1.3mf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]
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2026-04-26 Top cover curvature param + base plate pillar tuning + solar cutout variant
    Top cover: face_plate_outer_edge_curve_radius_mm — ellipsoid sphere
    scaling for independent face-to-wall rollover control. Base plate
    thinner: pillar extension Z height adjustable (-10 to +10mm), split
    pillar/wing geometry so screw pillars stay fixed. New base-plate-with-
    solar-cutout.scad: 62x36mm AK solar panel pit on bottom face, 2x 3mm
    wire holes, breakaway support ribs for FDM. Old joystick-pcb/ deleted.
    Docs, design evolution, and prompts updated.
    [base-plate-v1-2mm-thinner.scad, base-plate-v1-2mm-thinner__pillar_instert_thinner_4mm.3mf, base-plate-with-solar-cutout.scad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]
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2026-04-27 JLCPCB joystick PCB order notes + blog + docs/prompts update
    Documented the JLCPCB placement verification exchange for the joystick
    PCB (K1-1506SN-01). Factory flagged SW1 rotation on the near-symmetric
    package — confirmed correct. New order notes MD with full PCB design
    journey and current build status. Blog post with status table. Design
    evolution row added. Solar cutout support params moved above modules
    for Customizer visibility. Prompts #259 synced.
    [aaa-cradle-with-batt-clips.scad, base-plate-solar-thin-af-27-04.scad, base-plate-solar-thin-af-27-04__thick_floo_reduce_negative_space.3mf]
2026-04-27 USB-clip-fix base plate fork + batt-clip shortened preset render
    New base-plate-solar-usb-clip-fix-27-04 SCAD forked from
    thin-af with minkowski-rounded USB-C cutout fix and "thick
    floor reduce negative space" preset values baked in. Updated
    thin-af parent SCAD/JSON with latest parameter tweaks.
    Added 3MF render of the shortened-holes batt-clip preset.
    [aaa-cradle-with-batt-clips__battery_clips_forst_print_04-27_Shortened_holesby_5mm_and_opened_batt_clip_window_at_top.3mf, base-plate-solar-usb-clip-fix-27-04.s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]
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2026-04-28 Parametric TopCover rebuild with master sketch + Z-section + prompt #262
    Full PartDesign rebuild of the TopCover body using a master-sketch architecture:
    30-alias TC_Params spreadsheet drives every dimension; Sk_Master_Plan holds
    all plan-view outlines as construction geometry; Sk_Section_Y23 shows the
    full Z layout as a side-profile section. 7 Pocket Reversed flags fixed
    after empirical direction test. BasePlate and AAACradle untouched.
    [Dilder_Rev2_PartDesign-TopCover.3mf, Dilder_Rev2_PartDesign_MasterSketch.FCStd]
2026-04-29 Rev 2 Mk2 enclosure: final SCAD parts, FreeCAD macro fix, renders, README update
    - Add final baked SCAD files (base plate, AAA cradle, top cover) with all presets applied
    - Fix solar wire holes in FreeCAD macro: move SubtractiveCylinder to end of feature tree
    so holes cut through all additive features (pillars, wings, rail supports, blocks)
    - Add OpenSCAD renders of all 3 parts individually + assembled view
    - Update README with enclosure render gallery and Phase 6 progress
    - Add FreeCAD Mk2 design files (FCStd, 3MF exports, build instructions)
    - Ignore *.FCBak files in .gitignore
    [DilderFull Case Print out 29.04.3mf, Dilder_Rev2_Mk2-AAACradle.3mf, Dilder_Rev2_Mk2-BasePlate.3mf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]
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2026-04-29 Pico 2 W in FreeCAD assembly: STEP import, procedural headers, named-face anchoring
    - New add_pico_with_headers() in dilder_rev2_mk2.FCMacro: bbox-driven
    re-orientation, procedural 2x20 pin headers, 180-deg X flip, named-face
    anchoring to AAACradle.Face44 (X) and AAACradle.Face6 (Z, via
    ZMax - PCB_THICKNESS to land the component-side face flush)
    - Imported the official RP Foundation Pico 2 STEP (mechanically identical to
    Pico 2 W) into hardware-design/reference-boards/raspberry-pi-pico-2/
    - 4 new FreeCAD-rendered assembly images (iso translucent cover, no cover,
    cradle hidden, front elevation) under hardware-design/renders/ and copied
    into website/docs/assets/images/enclosure/
    -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
    [Dilder_Rev2_Mk2.FCStd, RaspberryPi-Pico-2.step]
2026-04-29 TopCover window: fix asymmetric grow + align Y with joystick centerline
    - Update Cut_Window placement literals to win_w=50, win_h=25 so the
    centered placement (disp_x0 + (65 - win_w)/2 + 2.8) matches the
    spreadsheet defaults (win_xl=50, win_yd=25). Previously the literals
    were 48x22 while the .Length / .Width expressions read 50/25, so the
    cut grew off one corner instead of equally on both ends.
    - Anchor win_y0 directly to joy_cy (= enc_y/2) instead of going through
    disp_y0, making the window-vs-joystick Y alignment explicit. Future
    changes to the joystick Y now propagate to the window automatically.
    - Re-render all four assembly views with the corrected cover.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
    [Dilder_Rev2_Mk2.FCStd]
2026-04-29 exported some proper models with correct screen placing
    [Dilder_Rev2_Mk2ProperwithPicoandHeaderAssemblies-AAACradle.3mf, Dilder_Rev2_Mk2ProperwithPicoandHeaderAssemblies-BasePlate.3mf, Dilder_Rev2_Mk2ProperwithPicoan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]
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2026-04-29 Joystick thumbpiece + cover joy-well + JoystickPCB STEP integration
    - New `Thumbpiece` PartDesign Body: printable snap cap nested in the cover's
    12 mm joystick cutout (OD = joy_d - 1.0 = 11 mm, height 4.5 mm). Concave
    thumb dish on top, rectangular snap socket on the bottom centered on the
    K1-1506SN-01 actuator peg (offset +0.68 mm in Y from the cover hole on
    the production PCB layout).
    - Dish depth capped at 0.6 mm so it doesn't break into the snap cavity
    (constraint: dish_d < thumb_h - top_clr - sock_d). 0.35 mm of solid
    material covers the peg from above.
    - 9 new spreadsheet aliases: thumb_od, thumb_h, thumb_top_clr, thumb_dish_r/d,
    thumb_sock_x/y/d, thumb_stick_cy.
    - Joysti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
    [Dilder_Rev2_Mk2.FCStd, JoystickBoardDilder.step]
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2026-04-30 Joystick anchor pad, piezo speaker ring, MPU-6500 IMU pocket, alignment fix
    - Replace JoyWell/Cut_JoyBody with 14x14mm anchor pad (12mm inner hole),
    extends from face_bot to PCB top (6.85mm depth)
    - Fix joystick PCB Y placement: remove double-applied SW1 offset
    (stick now 0.01mm from hole center instead of 0.68mm off)
    - Tighten cradle pit from 23mm to 20mm (0.2mm/side clearance for 19.6mm board)
    - Add 20mm piezo speaker retaining ring on base plate (22.2mm OD, 1mm wall)
    - Add MPU-6500 GY-6500 IMU rectangular pocket on base plate (25.4x15.4mm)
    - Add procedural piezo disc and IMU module Part::Feature models
    - Remove Cut_JoyBody, JoyWell, Cut_JoyPCBPocket, PicoRetentionBlock, TP4056_USBC
    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
    [Dilder_Rev2_Mk2-proper-joystick-solar-pcbclamp-30-04-2026-1617-AAACradle.3mf, Dilder_Rev2_Mk2-proper-joystick-solar-pcbclamp-30-04-2026-1617-BasePlate.3mf, Dil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]
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2026-05-01 fix the screen inlay sizing for vs waveshared
    [Dilder_Rev2_Mk2-proper-joystick-solar-pcbclamp-speeker-inlay-accelerameter inlay-widenenedinlayby.2mmforv3board 30-04-2026-1734-AAACradle.3mf, Dilder_Rev2_Mk2-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]
2026-05-01 Build & render CLI tool, comprehensive design doc, fresh renders
    - New interactive build_and_render.sh: 19 render presets, 4 resolutions,
    custom component combos, FreeCAD GUI rendering with pivy camera angles
    - Fix blank renders: top_objects() skips internal PartDesign features,
    flush() pumps Qt event loop 5x with 300ms delays before screenshot
    - Fix unknown view errors: replace ViewRotateRight with Coin3D SbRotation
    - New animate_assembly.FCMacro: 13-step cosine ease-in-out drop animation
    - New freecad-mk2-design.md: component-by-component breakdown with specs,
    renders, assembly order, and pain points documentation
    - New build-render-tool.md: software docs page for the render CLI
    - Ne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
    [Dilder_Rev2_Mk2.FCStd]
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2026-05-01 Design Tracker CLI + CAD workflow docs and blog post
    - New design-tracker.py: snapshot/timeline/print-log/diff/naming-guide
    CLI for tracking FreeCAD design iterations and print history
    - Initial snapshot taken (snap-0001)
    - 4 tracker screenshots captured (menu, status, timeline, naming)
    - New docs/tools/design-tracker.md with workflow diagrams
    - New blog post: design-tracker-and-cad-workflow.md — practical guide
    to file naming, snapshot discipline, and iteration speed
    - mkdocs.yml nav updated
    [Dilder_Rev2_Mk2.FCStd]
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2026-05-01 Widen TP4056 indent, extend enclosure +0.4mm, fix PitWallFill lip
    - TP4056 indent: tp_slop 0.2 -> 0.3 (17.4 -> 17.6mm) for USB clearance
    - Enclosure: enc_x 94.5 -> 94.9 (+0.4mm on +X axis for Pico slide room)
    - PicoNest: pico_nx 78.8 -> 79.2 (face distance 52.8 -> 53.2mm)
    - TP4056 module placement: sits flat on Face69 (indent floor Z=7.0)
    - PitWallFill: fill_x0 from plug_x0-0.1 to plug_x0 (trims 0.1mm lip)
    - All 96.3 translate refs updated to 96.7 for cradle flip consistency
    [Dilder_Rev2_Mk2 .4mm extension fixed lip and curved the thumbstick-AAACradle.3mf, Dilder_Rev2_Mk2 .4mm extension fixed lip and curved the thumbstick-BasePlate.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]
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2026-05-04 Add joystick PCB arrival, V4 display driver, version system, Mk2 photos
    Joystick PCB:
    - JLCPCB boards arrived with K1-1506SN-01 switches pre-mounted
    - Discovered COM/UP pin swap in EasyEDA community library (C145910)
    - Fixed KiCad symbol: pin 1=UP, pin 4=COM (corrected for Rev 2 order)
    - GPIO mapping confirmed: L=GP2, D=GP3, UP=GP4, R=GP5, C=GP6
    V4 Display Driver (V1.4):
    - Rewrote partial refresh 4 times to eliminate ghosting on Waveshare V4
    - Final: two-pass diff-based approach — clear changed pixels then draw
    - Pass 1 fast waveform (0xff), pass 2 full waveform (0xf7) for solid blacks
    - All display defaults changed from V3 to V4 (CMakeLists, Dockerfile, DevTool)
    Firmware:
    - Added versio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
    [Dilder_Rev2_Mk2_NoSolar Thicker Base longer peg shorter pillars(ext_z)-BasePlate.3mf, Dilder_Rev2_Mk2_NoSolar Thicker Base longer peg shorter pillars(ext_z).FC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]
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2026-05-05 Fix RP2350 RTC compat and add missing firmware to OTA list
    - moodselector-sound-wifi/main.c: guard unused hardware/rtc.h include
    behind #if !defined(PICO_RP2350) — RP2350 has no hardware RTC
    (uses pico_aon_timer instead). The include wasn't being used anyway.
    - OTA firmware categories: replaced nonexistent joystick-sound-test with
    actual projects: moodselector-sound and moodselector-sound-wifi. Any
    new firmware dirs are still auto-discovered under "Other".
    [main.c]
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2026-05-05 Push-pull piezo driver for 2x volume — GP14+GP15 opposite phase
    Drive piezo between GP14 (pin 19) and GP15 (pin 20) using the same
    PWM slice with inverted polarity on channel A. This gives ~6.6Vpp
    across the piezo instead of 3.3V from a single pin, doubling volume
    without any external components.
    Wiring: piezo + → pin 20 (GP15), piezo - → pin 19 (GP14)
    Remove any resistor — direct connection.
    [main.c]
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2026-05-05 WiFi icon left, battery icon right, fix V4 partial refresh flicker, add display variant selector to toolbar
    Firmware (dilder-hub):
    - WiFi icon moved to top-left of octopus screen
    - Battery icon added top-right: reads VSYS via ADC3 (GP29, 3:1 divider),
    shows 0-4 fill bars for 3.0-4.2V, plug symbol if USB powered (>4.5V)
    V4 display driver (EPD_2in13_V4.c):
    - ROOT CAUSE of flicker: DoPartialDiff was reloading the waveform
    (0x22/0xB1/0x20 + ReadBusy) on EVERY frame, causing a visible
    display reset. Now loads waveform once via EnterPartialMode(), then
    each partial update just writes data + triggers (0x22/0xC7/0x20).
    - Update command changed from 0xf7 (full LUT) to 0xC7 (partial with
    di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
    [main.c]
2026-05-05 Fix black flash, battery lightning bolt, menu fits on screen
    V4 driver: removed periodic full refresh entirely — partial updates
    only after the initial base frame. No more black screen flash.
    Battery icon: USB-powered state now draws a lightning bolt inside
    the battery outline instead of a plug symbol.
    Menu: reduced spacing from 9px to 8px and moved start position up
    so all 5 items (Mood Select, Network, Sound Test, Device Info, Back)
    fit within the 122px screen height. Items at y=84,92,100,108,116.
    [main.c]
2026-05-05 Fix V4 display flash, mood tagline, battery info, menu fits
    V4 display driver — REAL fix for black flash:
    - EPD_Clear() now writes both RAM buffers (0x24 AND 0x26) so they
    match. Previously only 0x24 was written, causing the controller
    to see a full diff on the first partial update and redraw everything.
    - base_seeded set to 1 after Clear — partials work immediately.
    - Removed all EPD_Base() calls from firmware — only EPD_Partial()
    used after the initial Clear. Zero full refreshes during operation.
    - Tagline shows current emotion name (e.g. "- CONSPIRATORIAL -")
    instead of static "~ DILDER HUB ~"
    - Mood select returns to octopus screen after choosing (no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
    [main.c]
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2026-05-05 Fix Dilder Hub battery meter — init ADC3 and average samples
    GPIO 29 / ADC3 was never adc_gpio_init'd, so digital pulls pinned the
    reading to ~0V. Add battery_init() at boot, average 32 samples to
    suppress CYW43 SPI noise on the shared pin, and use
    CYW43_WL_GPIO_VBUS_PIN for USB detection when WiFi is up.
    [main.c]
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2026-05-06 Add speaker pin definition to board_config.h, update thumbpiece 3MF
    board_config.h: PIN_SPEAKER = GP7 (pin 10) added for both Pico W and
    Pico 2 W board configs. This is the default for the shared firmware —
    dilder-hub overrides to GP15 locally for Waveshare HAT clearance.
    [Dilder_Rev2_Mk2_NoSolar-Thumbpiece.3mf]
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
